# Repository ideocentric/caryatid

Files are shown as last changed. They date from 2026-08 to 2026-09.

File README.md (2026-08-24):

# caryatid

**A carrier board that gives a Daisy Seed a rechargeable battery, honest power
indication, and a fixed set of I/O on connectors, in a shape that drops into an
enclosure.**

Plenty of Seed carriers break out pins well. Fewer solve *running on a battery
you can charge without opening the box, and knowing what state that battery is
in when the instrument is switched off*. This board treats that as the core
requirement rather than an accessory.

**One PCB layout serves every build.** Every variable element (pots, keypad,
sensors, switches, comms) enters through a connector, and each instrument
populates the subset it needs. Order once, stuff per instrument. It carries
absonus, loa, baby borg, and whatever comes next.

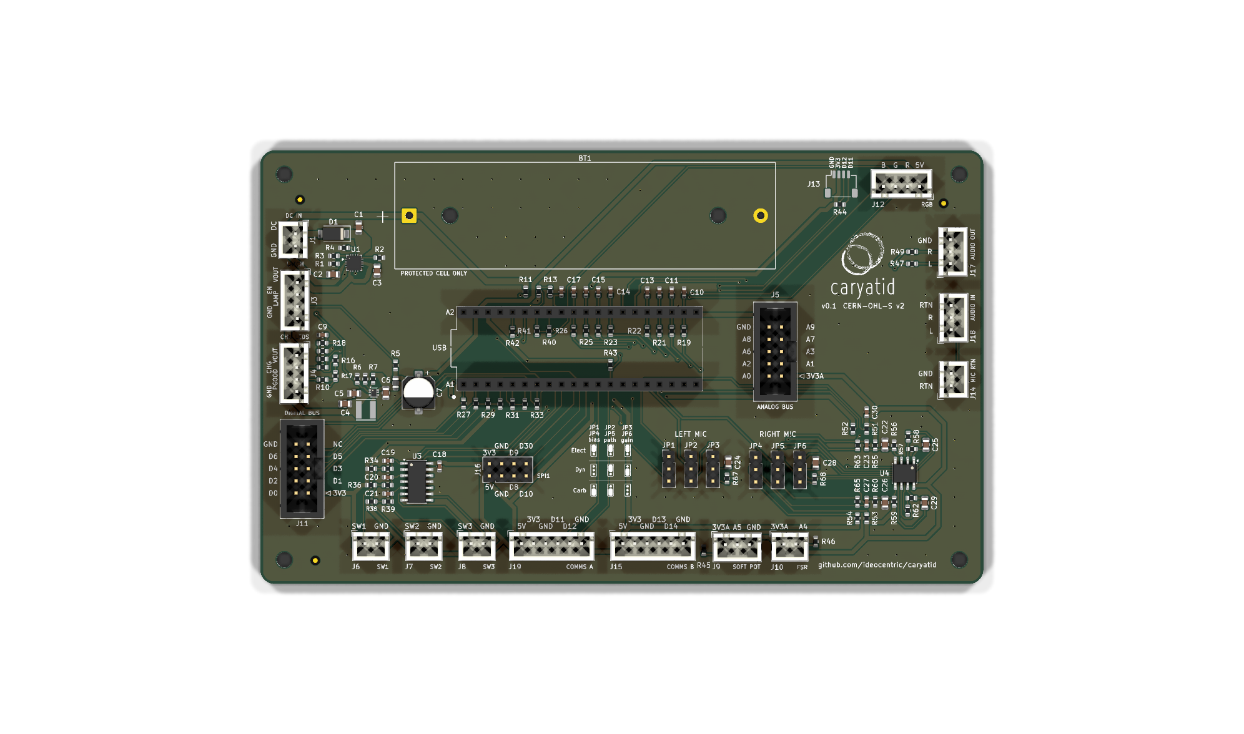
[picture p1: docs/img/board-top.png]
caryatid, top


### Is it right for what you are building?

**[docs/platform.md](docs/platform.md)** is the capability specification: what
it supports, what it deliberately does not, and where the boundary sits. It
states the limits as plainly as the features, because knowing them before you
commit is worth more than discovering them after.

### Status

**Five boards ordered 2026-08-23; none has been powered yet.**

Every electrical check is at zero: no unconnected nets, no shorts, no clearance
or hole violations, no copper under the width rule, no floating ground, and no
DRC violations of any kind. The firmware stub compiles against libDaisy and has
never been run on hardware. [docs/status.md](docs/status.md) is the current
state; treat anything marked unverified there as exactly that.

> **Working on caryatid itself rather than building with it?** Read
> [the checkout warning](#working-on-caryatid-itself) at the foot of this file
> before you commit anything. It is the one way to lose a session's work here.

## Start here

| | |
| --- | --- |
| **Where the board is, and what is next** | [docs/status.md](docs/status.md) |
| **The frozen pin map** | [docs/pinmap.md](docs/pinmap.md) — generated from [docs/pins.yaml](docs/pins.yaml) |
| Connectors and what plugs into them | [docs/connectors.md](docs/connectors.md) |
| Audio in and out, and the handset problem | [docs/audio.md](docs/audio.md) |
| **Setting the mic capsule jumpers** | [docs/mic-configurations.md](docs/mic-configurations.md) |
| The three indicators, and why three | [docs/indicators.md](docs/indicators.md) |
| **Component values, with derivations** | [docs/values.md](docs/values.md) |
| Part numbers, footprints, what is in stock | [docs/sourcing.md](docs/sourcing.md) |
| **Power sheet, every connection** | [docs/power-sheet.md](docs/power-sheet.md) |
| **Seed sheet, every connection** | [docs/seed-sheet.md](docs/seed-sheet.md) |
| **Panel I/O sheet, every connection** | [docs/panel-io-sheet.md](docs/panel-io-sheet.md) |
| **How to build an instrument on this board** | [docs/integration.md](docs/integration.md) |
| Board-support firmware (MIT) | [firmware/](firmware/) |
| What to do before and during capture | [docs/capture-checklist.md](docs/capture-checklist.md) |
| Datasheets, links and document numbers | [docs/datasheets.md](docs/datasheets.md) |
| **What it supports, and what it does not** | [docs/platform.md](docs/platform.md) |
| The board and schematic as PDFs | [docs/reference/](docs/reference/) |
| Why things are the way they are | [docs/decisions/](docs/decisions/) |
| **Rules the tools must follow, and what each cost** | [docs/conventions.md](docs/conventions.md) |

**`docs/pins.yaml` is the source of truth.** The markdown table is generated:

```sh
python3 tools/gen_pinmap.py           # rewrite docs/pinmap.md
python3 tools/gen_pinmap.py --check   # fail if stale
```

Never edit `pinmap.md` by hand. A pin map kept in two places will disagree the
first time a connector moves.

## Terms

**DNP — "do not populate."** The footprint is on the board, the symbol is in the
schematic, the connections exist in the netlist, but **no component is soldered
there**. A deliberately empty position. Also written DNI (do not install), NF
(not fitted), or NP.

**caryatid has none, and that is the point of the term appearing here.**
[ADR 0010](docs/decisions/0010-nothing-is-dnp.md) took the count to zero and
`check_board.py` check 12 keeps it there.

DNP used to be the mechanism this board rested on: lay out every option any of
the instruments might need, populate only the subset each build wants. It stopped
paying its way when JLCPCB began fitting the through-hole parts too — **DNP
became an instruction someone acts on and bills for**, so every DNP line is
either a part you paid for and did not want or one you needed and did not get,
and which it is only becomes clear when the boards arrive.

What replaced it is **selection after assembly**: six jumpers choose the mic
front-end per channel, and the codec's own PGA does the attenuating a resistor
pad used to. See [audio.md](docs/audio.md) and
[sourcing.md](docs/sourcing.md).

## What "frozen" means

An instrument may leave a pin unpopulated, and may choose between the alternates
listed for a pin. It may **not** repurpose one. The entire value of the platform
is that one layout serves every build; a pin reassigned for one instrument is a
board that no longer serves the others.

The map is **fully allocated**. `D30` is the only spare. Adding anything means
taking it from something else, and the decision records say what that would
cost.

## The fixed core

Populated on every build:

- Barrel jack → SS34 → **bq24074** charger with power path, ISET 890 Ω (1 A)
- **On-board 18650 holder (BT1)**, the only path to `VBAT` — a soldered holder
  cannot be wired backwards. Protected cell or protection PCB **required**
- **TPS61023** boost → **5.0 V** → ferrite + 100 µF → Seed VIN
- Illuminated latching power switch (3–9 V lamp, so `R_LED` is a 0 Ω link)
- `/CHG` + `/PGOOD` panel LEDs — the indication that works with the Seed off
- RGB status LED, battery gauge on A10, charge-status code on A11
- Daisy Seed on 2×(1×20) female headers, machine-fitted
- 74HC14 Schmitt debounce, SMT — see [ADR 0007](docs/decisions/0007-rc-and-schmitt-instead-of-the-ls18-p.md)
- Audio out; audio in on every board, **both channels**, capsule selected by
  jumper — JP1–JP3 left, JP4–JP6 right

## Two things worth knowing before you read the map

**Comms ports carry signals, not protocols.** D11/D12 are simultaneously I2C1
and UART4, so the same connector is an I2C sensor, a MIDI input, or an ESP32
bridge depending on what you plug in. Two ports is the ceiling — there is no
third UART on free pins. See [ADR 0003](docs/decisions/0003-comms-ports-are-protocol-agnostic.md).

**D8 is the only free SPI1 clock on the board.** Not a preference — `PA5` is the
only alternative and it is an analogue panel input. An earlier draft spent D8 on
an LED, which would have left SPI1 as two pins with nothing to clock them. See
[ADR 0004](docs/decisions/0004-keep-spi1-drop-the-soft-latch.md).

## Licence

**Settled 2026-08-18.** The hardware and the tools are strongly reciprocal; the
board-support layer deliberately is not:

| What | Licence |
| --- | --- |
| **Hardware** — schematics, PCB, footprints, artwork | **CERN-OHL-S v2** |
| **Tools** — everything in `tools/` | **GPL-3.0-or-later** |
| **Board support** — everything in `firmware/` | **MIT** |

Terms and what counts as *Complete Source* are in [LICENSING.md](LICENSING.md); how
it was reached, and the audit of every design input, are in
[ADR 0006](docs/decisions/0006-licensing-is-open.md).

CERN-OHL-S defines Complete Source as the **editable design files**, so shipping
Gerbers alone does not discharge the obligation. `CERN-OHL-S v2` and
`github.com/ideocentric/caryatid` are both printed on the front silkscreen.

The question this turned on — whether the schematic derived from Adafruit's
reference designs (CC BY-SA, and irreversible) or was drawn independently from
the TI datasheets — was answered **2026-08-08, before capture began**: drawn from
the datasheets. That is what kept the reciprocal option available.

**`firmware/` is MIT on purpose.** A copyleft board-support layer is viral into
anything that links it, which would settle every instrument's firmware licence
from underneath — a decision belonging to each instrument, not to the carrier
board. libDaisy and DaisySP are MIT already.

## Consuming this board

Each instrument takes it as a submodule:

```sh
git submodule add https://github.com/ideocentric/caryatid.git hardware/platform
```

loa consumes it this way at `hardware/platform`. Then add the board support to
your build:

```make
C_INCLUDES  += -Ihardware/platform/firmware/include
CPP_SOURCES += hardware/platform/firmware/src/caryatid.cpp
```

**Read [docs/integration.md](docs/integration.md) first** — it covers what the
board provides, what the instrument must provide, the electrical and mechanical
requirements, and the four things about this board that are not guessable from
a pin number.

## The name

*A caryatid is a column carved as a figure, bearing the weight of what stands on
it. Named for the role rather than for any instrument it carries: calling it
after one of them would have implied it belonged to that one.*

## Working on caryatid itself

### ⚠ Which checkout is this?

**caryatid is developed as a standalone clone. It is also consumed as a git
submodule by the instrument repositories, and those copies are read-only.**

If the path to this file runs through another project's submodule directory —
for loa that is `hardware/platform/` — **you are in a consumer copy. Do not edit
it and do not commit to it.** Find the standalone clone and work there.

The sequence, in order, every time:

1. Change, review and commit in the **standalone clone**.
2. Push.
3. *Then* update the consuming repository's submodule pointer — a
   `Bump caryatid: …` commit on that side.

**Why this matters more than it looks.** A submodule checkout sits on a detached
HEAD, so commits made there belong to no branch and the standalone clone knows
nothing about them. The two diverge silently, and the symptoms all point
somewhere other than the cause: KiCad in one directory keeps showing a schematic
that another directory has already changed.

That is not hypothetical. A whole session's work — ADR 0010, the schematic
edits, two tools, thirteen documents — was written into loa's submodule on
2026-08-21. It pushed to the same remote so nothing was lost, but an hour went
into diagnosing "update from schematic shows nothing new", which was only ever
the wrong directory.

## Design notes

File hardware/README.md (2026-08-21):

# Hardware

Empty. The KiCad project lands in [`pcb/`](pcb/) once the licence question in
[ADR 0006](../docs/decisions/0006-licensing-is-open.md) is answered — that
answer decides whether schematic capture may start from an Adafruit source file,
and it cannot be revisited afterwards.

## What will be committed

The editable design:

- `*.kicad_pro`, `*.kicad_sch`, `*.kicad_pcb`
- project-local symbol and footprint libraries
- STEP exports alongside any native mechanical CAD

## What will not

Anything regenerable: gerbers, drill files, pick-and-place, fabrication
archives. A gerber directory in the tree drifts from the board file within about
two revisions and then quietly misleads whoever trusts it. Released fabrication
output belongs on a tagged release, so a given release maps to exactly one set
of files that were actually ordered.

## Design intent

[`docs/pinmap.md`](../docs/pinmap.md) is the source of truth for pin
assignment and is generated from `docs/pins.yaml`. The schematic follows it, not
the other way round.

Layout rules are inherited from the platform spec and are frozen with the board:

1. **Zones** — charger and barrel jack on one edge, boost in the corner beyond
   it, Seed centre, audio jacks on the opposite edge. Analogue IDC near the
   Seed's analogue row, digital IDC near its digital row.
2. **One unbroken ground plane.** No split AGND/DGND planes. Control noise by
   placement: keep the boost switching loop small so its return currents stay
   local.
3. Wiper RC filters at J5; 100 Ω series at J11.
4. No switcher traces under or parallel to audio nets or the analogue bus.
5. Enclosure bonds to ground at **one point**, at or near the audio jacks.
6. Ferrite and bulk between the boost and everything downstream.
7. Route the RGB lines away from the analogue bus — status changes are edges too.

## Mechanical and fabrication

None of this was specified before and all of it is needed before layout.

**Board outline: 150 × 90 mm.** absonus is 47.8 × 98.6; this is bigger because
caryatid carries roughly four times the part count and an on-board cell.

The BUD's internal is **178 × 110 mm, measured** (2026-08-18) — against a
catalogue internal of 107.9 × 177.8, which was near enough exact. The
**95.2 × 165.1 mm** "usable rectangle", derived by taking 0.5″ off each axis for
the sloped sides, under-read the real box by 12.9 and 14.8 mm and **is
retired**. 150 × 90 sits inside the measured floor with 28 mm of length and
20 mm of width to spare.

That slack is **not** centred. The board mounts 5 mm from the left wall, hard
against the 5 mm screw columns, reserving all 28 mm at the right — the latching
power button is long and needs it, and the device is held in the left hand, so
the board's mass belongs over the supporting hand rather than cantilevered out
to the right. Facts and provenance:
[`discovery/findings/bud-cu477-interior.yaml`](../discovery/findings/bud-cu477-interior.yaml).

**The 100 mm rule is retired.** It claimed JLCPCB's cheapest tier is 100 × 100 and
that crossing it costs money for nothing. The tier is real, but the cost of
crossing it was never checked and turns out to be small — so the rule was
protecting against a number nobody had measured. See
[ADR 0008](../docs/decisions/0008-board-outline-and-layer-count.md).

**Two layers.** Density says four would be easier, but width is cheaper than
layers and the enclosure has the room. At 90 × 100 the component area is about
**53% fill** before the cell, which leaves a ground pour that is genuinely
continuous rather than nominally so, and slack for a 2-layer router.

**Put the SMD and the battery holder on opposite faces.** This is what makes two
layers work at this size. All SMD on one side, the holder and every through-hole
connector on the other, so the copper *under the cell* is still usable instead of
15 cm² of dead board. It also keeps SMT to a single side, which is the cheaper
assembly.

**On-board 18650 holder.** Soldered rather than a pack tacked into the enclosure,
which removes the last hand-crimped power loom — and with it the reverse-polarity
risk that had no protection behind it. A holder cannot be wired backwards.

**There is no remote-pack connector.** J2 carried that option until layout, and
was removed: no instrument on the platform asked for it, and it was the only way
a reversed cell could reach the charger, which has no reverse protection. A cell
now reaches the board only through a soldered holder, which cannot be wired
backwards.

**The holder must take a protected cell.** Those are ~69 mm against the 65 mm
most holders are cut for. Check the part before ordering, or the cell will not
seat.

**Mounting holes: four M3, inset from the corners, pattern fixed once the outline
is.** absonus's 40.64 × 91.44 mm (1.6″ × 3.6″) pattern is **not** being retained —
the current absonus uses standard batteries with a panel cutout, so there is no
interchangeability to preserve and no reason to inherit its geometry.

**Test points.** Bring-up needs `VBAT`, `VOUT`, `+5V`, `+3V3`, `+3V3A` and
several `GND`, as real pads rather than "somewhere to hook a probe". A board
whose connectors are all populated and whose looms are not yet made has nowhere
convenient to measure otherwise.

**Fiducials.** Three, on the top layer, for machine placement — the QFN-16 and
the SOT-563 are both 0.5 mm pitch, which is where placement accuracy starts to
matter. Confirm JLC's current requirement rather than assuming three is right.

**Silkscreen carries the wiring.** See [connectors.md](../docs/connectors.md):
every connector's pin functions and pin 1, the Seed pin names, `USB` at the pin 1
end. This board is assembled once and cabled many
times, so the board itself should be readable without the documents.

## Assembly split

**JLCPCB fits everything, including the through-hole parts.** absonus was built
this way — its BOM carries the JST-XH connectors, the 2×5 IDC header, a DIP and a
radial electrolytic alongside the SMD — so the precedent and the part numbers are
both proven.

- **SMD** — charger, boost, 74HC14, MCP6002, all passives.
- **Through-hole** — every JST, both IDC headers, the Seed sockets, the barrel
  jack, the expansion header.
- **Hand** — nothing, by intent.

Two consequences that follow from this and are easy to miss.

**DNP stopped being advisory, and then stopped existing.** When the connectors
were hand-fitted, "DNP" meant *don't bother*. Once JLC fits the through-hole
parts it is an instruction they act on and bill for, so a wrong DNP line is
either a connector you paid for and did not want or one you needed and did not
get — and which one it is only becomes clear when the boards land.

[ADR 0010](../docs/decisions/0010-nothing-is-dnp.md) took the count to **zero**.
Every symbol is assembled; the options that used to be DNP are now selected by
jumper after assembly, or were `open` positions that no supplier could ship and
have been deleted. BT1 is the only part the assembler does not fit, and it is
**not** DNP — it is self-fit from Digi-Key, which `lcsc.yaml` records and
`fab_package.py` acts on.

**Through-hole assembly needs the Standard service**, not Economic, and is
priced per joint so it scales with connector count in a way SMD placement does
not. absonus was ordered that way deliberately — the cost is accepted in exchange
for an empty hand-solder list.

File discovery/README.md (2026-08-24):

# Findings ledger

> **Before writing anything here, check which checkout you are in.** caryatid is
> developed in its standalone clone; a copy reached through another project's
> submodule directory (`hardware/platform/` in loa) is read-only. See the top of
> the [root README](../README.md).

Measured facts about physical things that the repo cannot check for itself.

One file per finding in `findings/`, keyed by a stable identifier. Each record
carries what was originally *claimed*, what was *measured*, an **append-only**
evidence list with dates, and a `status`. When a fact changes, a new evidence
entry goes on the end and `status` / `last_verified` are updated — history is
never rewritten.

## Why this exists here

caryatid's documents are full of numbers, and most of them are checkable: DRC
reads the board, `check_board.py` reads the board, `verify_parts.py` reads JLC.
A handful are not. The enclosure is a die-cast box on a bench; the only way to
know its interior is to measure it, and the only place that measurement lives is
whatever we write down.

Those numbers had been derived instead — catalogue nominal minus half an inch
per axis, a sparse point cloud out of a STEP file — and then restated across
four documents until they read like measurements. When the box was finally
measured, the derived working rectangle turned out to under-read it by about
14 mm on each axis. Nothing broke, because the error was conservative. It could
as easily have gone the other way.

## The rule

**Facts go in the ledger first. Documents are derived from it, never the
reverse.** If a number in `docs/` needs to change, change the record and
regenerate the prose. A figure in a document that has no record behind it is
unverified, and should say so.

## Records

| record | covers |
| --- | --- |
| [`bud-cu477-interior.yaml`](findings/bud-cu477-interior.yaml) | BUD CU-477 floor, height, plate profile, board mounting datum and the power switch intrusion |
| [`bt1-cell-fit.yaml`](findings/bt1-cell-fit.yaml) | Whether the Orbtronic 3400 mAh protected cell fits the BH-18650-PC holder. `conflict`: it seats, over-deflecting the contacts past their rating |
| [`carbon-capsule-dc-resistance.yaml`](findings/carbon-capsule-dc-resistance.yaml) | What to measure on a carbon capsule, and what each reading means for R52/R54. `unverified`: nothing measured yet |
| [`jlc-order-2026-08-23.yaml`](findings/jlc-order-2026-08-23.yaml) | Every setting on the JLCPCB order form for the first build, checked against the board, plus what was actually paid. `confirmed`: placed 2026-08-23 |
| [`mic-gain-budget.yaml`](findings/mic-gain-budget.yaml) | Where the x3 / x100 / x1000 gain targets come from. `unverified`: they reconcile against typical figures, but no capsule has been measured |
| [`jlc-bom-sourcing.yaml`](findings/jlc-bom-sourcing.yaml) | The LCSC codes (43 as of 2026-08-23): cost, library split, assembly mode, pre-orders, and the build-quantity decision |

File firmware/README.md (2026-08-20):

# firmware — board support for caryatid

Stub board-support code for instruments built on this board. **MIT licensed**,
unlike the rest of the repository, so instrument firmware can link it without
inheriting copyleft — see [../LICENSING.md](../LICENSING.md).

```
firmware/
  include/caryatid_pins.h   GENERATED from docs/pins.yaml — do not edit
  include/caryatid.h        the Caryatid class
  src/caryatid.cpp          implementation
  examples/panel_readout.cpp  bring-up sketch: reads everything, prints it
```

## Status: stub, never run on hardware

**No board has been fabricated yet.** This compiles against libDaisy and is
structured for an instrument to build on, but nothing here has been executed.

The distinction that matters:

- **Every pin, polarity and scale factor is checked against the schematics**
  in `docs/`, and cited at the point of use in the source. Those are as good as
  the documents they come from.
- **Every timing is unverified.** The debounce sample count, the software PWM
  depth, the 1 kHz control rate — all reasoned from the hardware, none measured.

Expect to adjust the second category on first bring-up. Treat a disagreement in
the first category as a bug worth chasing to the schematic.

## What it does that a bare Seed does not

Four things on this board have a polarity, a scale factor or an ordering that
is not guessable from a pin number, and every instrument would otherwise
rediscover them the hard way:

| | |
| --- | --- |
| **RGB status** | Common anode to **5 V**, GPIOs sinking — writing **low** lights it. Green and blue will not light from a 3V3 GPIO at all; their forward voltage is above the output-high level. |
| **Switches** | Pass through a 74HC14 **inverter**, so the GPIO reads **high when pressed**. And SW1 is on `D14` while SW2 is on `D13` — they cross. |
| **Battery gauge** | Behind a 100k/100k divider, so cell volts are **2×** the pin. |
| **J5 analogue bus** | Wipers are `A0`–`A3` then `A6`–`A9`, **not** `A0..A7`. `A4` and `A5` are the dedicated sensor inputs and are not on the bus. |

`Caryatid` handles all four. `caryatid_pins.h` carries the caryatid name, STM32
pin and connector in a comment on every line, because a Seed pin index on its
own tells you nothing at a call site.

## Use

```cpp
#include "daisy_seed.h"
#include "caryatid.h"

DaisySeed          seed;
caryatid::Caryatid hw;

int main() {
    seed.Init();

    caryatid::Config cfg;
    cfg.fsr     = true;
    cfg.comms_a = caryatid::CommsA::I2C;       // J13, Qwiic
    cfg.comms_b = caryatid::CommsB::Switches;  // J6/J7 as SW1/SW2
    hw.Init(seed, cfg);

    while (1) {
        hw.Update();                  // control rate, ~1 kHz
        System::Delay(1);

        float cutoff = hw.Panel(0);   // J5 connector order
        if (hw.RisingEdge(caryatid::Switch::SW3)) { /* hook lifted */ }
        if (hw.BatteryVolts() < 3.3f) hw.Rgb(1, 0, 0);
    }
}
```

**`Config` must match what is actually soldered.** The board lays out both
options for each comms port and a build fits one; selecting the wrong mode
configures a peripheral onto pins that are not connected, and it fails silently.
An unpopulated analogue input is a floating ADC pin — it reads noise, not zero.

## Building

There is no build system here on purpose. This is a **source drop**, consumed
by an instrument repo that already has libDaisy, a linker script and a
bootloader target. Adding a second build system would mean maintaining one that
nothing exercises.

Consume it as a submodule and add to your Makefile:

```make
C_INCLUDES += -Ihardware/platform/firmware/include
CPP_SOURCES += hardware/platform/firmware/src/caryatid.cpp
```

Requires **libDaisy** on the include path; `daisy_seed.h` must resolve. Editor
diagnostics in this repo will show it unresolved, because libDaisy is vendored
in the instrument repos rather than here.

## Regenerating the pin header

`caryatid_pins.h` is generated. Never edit it.

```sh
.venv/bin/python tools/gen_firmware.py           # rewrite
.venv/bin/python tools/gen_firmware.py --check   # fail if stale
```

`docs/pins.yaml` is the source of truth for the pin map and everything else is
a consumer of it. A pin map kept in two places disagrees the first time a
connector moves — and a firmware header is a far worse place to discover that
than a markdown table, because the board is already built and the symptom is a
sensor quietly reading the wrong wire.

## Licensing

**This directory is MIT.** The rest of the repository is not — the hardware is
CERN-OHL-S-2.0 and `tools/` is GPL-3.0-or-later. See
[../LICENSING.md](../LICENSING.md) for all three.

### Your instrument can still be copyleft

MIT is permissive, so it imposes no condition that a copyleft licence cannot
satisfy. **You may absorb this code into a GPL instrument**: the combined binary
is distributed under the GPL, and the MIT notice is preserved for these files.
The FSF classes MIT as GPL-compatible for exactly this.

This is not theoretical — loa already does it. Its firmware is
GPL-3.0-or-later and links MIT libDaisy and DaisySP today, and its licensing
ADR records the same conclusion. (That repository is private as of this
writing, so there is no link to give.)

| instrument | may be licensed | because |
| --- | --- | --- |
| loa | **GPL-3.0-or-later** (and is) | MIT absorbs into GPL cleanly |
| absonus | GPL, MIT, BSD — anything | MIT imposes no reciprocity |
| baby borg | same | same |

### Why it is not GPL

**The reverse does not work, and that is the whole reason.** A copyleft
board-support layer is viral into everything that links it, so GPL here would
force every instrument built on caryatid to be GPL — settling absonus's and baby
borg's licence from a header file in the carrier board underneath them. That
decision belongs to each instrument.

Permissive at the bottom, copyleft optional at the top. It is the only
arrangement that keeps all three choices open.

### What you owe

1. **Ship the MIT notice** with these files when you distribute instrument
   firmware. Consuming caryatid as a submodule satisfies this already —
   `../LICENSES/MIT.txt` travels with it, and every source file carries an
   `SPDX-License-Identifier`.
2. **It cuts both ways.** Anyone may take this directory alone and use it in a
   closed product. That is the price of not constraining the instruments.

The reciprocity that matters is on the **board**, not here: CERN-OHL-S defines
*Complete Source* as the editable design files, so nobody ships derivative
hardware without publishing the KiCad project. A permissive stub layer does not
weaken that.

## Reference

| | |
| --- | --- |
| Pin map | [../docs/pinmap.md](../docs/pinmap.md), generated from `pins.yaml` |
| What plugs into what | [../docs/connectors.md](../docs/connectors.md) |
| Integration guide | [../docs/integration.md](../docs/integration.md) |
| Charge-status encoding | [../docs/indicators.md](../docs/indicators.md) |
| Component values and derivations | [../docs/values.md](../docs/values.md) |

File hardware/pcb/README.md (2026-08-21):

# PCB

KiCad 9 project. **All four sheets are captured.** 125 components, 101 nets,
**ERC clean at 0 violations.**

| Sheet | State | Check |
| --- | --- | --- |
| `power.kicad_sch` | 27 components, 19 nets | netlist diffed node-by-node against [power-sheet.md](../../docs/power-sheet.md); `ITERM` the one deliberate no-connect |
| `seed.kicad_sch` | 12 components | all **31** physical pins in `pins.yaml` land on a net named after the pin |
| `panel-io.kicad_sch` | 46 components | all **29** pins declaring a connector reach it, traversing series R and the debouncer |
| `audio.kicad_sch` | 37 placements, **0 DNP** | 17 nets diffed against [audio.md](../../docs/audio.md), including `C_g` in series with `R_g`; six jumpers re-diffed for [ADR 0010](../../docs/decisions/0010-nothing-is-dnp.md) |

**The dangling-global count reached zero.** It ran 33 → 4 → 0 as seed, panel-io
and audio landed, and each drop was predicted before the sheet was drawn. Five
no-connects remain and all five are deliberate: `ITERM` on the charger, `J11`
pin 9 (the spare), and the three unused 74HC14 outputs.

Treat any *new* ERC message as real. The design now has nothing expected to be
wrong, so there is no noise for a fault to hide in.

Placement is functional rather than tidy — components on a 1.27 mm grid with
labelled stubs, meant to be dragged into shape in the GUI. The bootstrap scripts
in [`tools/oneshot/`](../../tools/oneshot/) are spent; do not re-run them.

```
pcb/
  caryatid.kicad_pro       project: net classes, design rules, sheet index
  caryatid.kicad_sch       root — four hierarchical sheets, nothing else
  power.kicad_sch          charger, boost, latch, hardware charge LEDs
  seed.kicad_sch           Seed headers, battery gauge, charge-status code
  audio.kicad_sch          jacks, coupling, mic bias / preamp / pad options
  panel-io.kicad_sch       analogue bus, digital bus, switches, comms ports
  caryatid.kicad_sym       symbols: BQ24074RGT, TPS61023DRL, Seed sockets A/B
  caryatid.pretty/         footprints: BQ24074 QFN, Seed sockets A/B
  sym-lib-table            so the project libs resolve without global config
  fp-lib-table
```

Open `caryatid.kicad_pro`. `caryatid.kicad_pcb` carries **all 125 footprints,
placed and net-bound**, on a 150 × 90 mm outline with four M3 holes. **Nothing is
routed** — DRC's 263 unconnected items are the full ratsnest, which is correct.

Placement is a machine first pass, not layout. It puts each block where the
zoning says and nothing overhangs the outline, but ~33 courtyards still overlap
and the silkscreen is a mess. Treat it as something to drag from.

## Which face

**Everything is on the front.** The back carries nothing but the ground pour.

The SMD was briefly on the back, which is the textbook arrangement and was right
when the board was 90 × 100 and the copper under the cell was worth reclaiming.
It is wrong here: **the enclosure is shallow, so the standoff must be short**, and
C7 at 5.4 mm cannot hang underneath a 2 mm gap. Moving everything to the front
fixes three things at once — the standoff drops to 2 mm, SMT stays single-sided
and therefore Economic, and B.Cu is freed as a routing layer instead of carrying
104 parts *and* every signal.

The flip is stored the way KiCad stores it, checked against a KiCad-written
board rather than assumed: back-side footprints hold **Y-negated** coordinates,
F/B layer names swapped, and `(justify mirror)` on every text. Arcs survive
because KiCad 7+ stores start/mid/end and all three mirror together.

**Two things to confirm before ordering.**

`J13` is the SMD Qwiic socket, so it classified as SMD and went to the back.
Electrically fine; whether you want a Qwiic cable leaving from the underside is
a mechanical question, not one the classifier can answer.

**Through-hole bodies are on the front, so their pins protrude into the SMD
side.** JLC cannot wave-solder them from the back without hitting SMD. For small
runs their through-hole work is hand soldering, which is probably fine — but you
asked for the JSTs to be machine-fitted as on absonus, and absonus had a
component-free underside. Worth putting to JLC before the order.

## The connector ring

Placed by function, and stacked from measured courtyard extents rather than by
hand — hand arithmetic on offsets produced touching parts three times running.

| Edge | Connectors |
| --- | --- |
| Left | `J1` DC in, `J3` latch switch, `J4` charge LEDs |
| Left, inboard | `J11` digital bus IDC, beside A1 (the digital row) |
| Right | `J12` RGB, `J9` soft pot, `J10` FSR, `J17` audio out |
| Right, inboard | `J5` analogue bus IDC beside A2; `J16` expansion; `J18` audio in and `J14` mic return together |
| Bottom | `J6` `J7` `J8` switches, then `J19` and `J15` module ports |

Power enters on the left where the charger and boost sit underneath; the
analogue bus, both sensors and the audio pair are on the right, furthest from
L1. `J18` and `J14` are adjacent because they are one loom — capsule signal and
its bias return to the hook switch's second pole.

**Everything is at rotation 0.** A vertical JST exits upward, so turning the pin
row to follow the edge buys nothing — and the rotated-courtyard transform is the
one piece of geometry here that could not be checked against a known-good file,
so it is not used. If you rotate parts by hand in the GUI, KiCad does that
arithmetic correctly.

**The four M3 holes are part of the collision check.** They were not, at first,
and that version passed a board where `J6` and `J18` each sat on top of a
mounting hole. They come from the skeleton rather than from the netlist, which
is exactly why a check built around the component list missed them.

## Routing: the pour and the boost loop only

**Everything else is unrouted, deliberately.** kicad-cli has no router, KiCad
ships none, and Freerouting is not installed — and routing follows placement,
which is still a machine first pass. Two pieces were worth doing now because
their geometry is settled and the stakes are high.

**A GND zone on B.Cu**, which is now the empty face — a genuinely solid plane,
and the whole layer still available for routing around it.

**The zone is not filled.** `kicad-cli pcb drc` has no fill option, so DRC
reports the two GND vias as `via_dangling` — they touch a zone that has no copper
in it yet. **Fill zones in the board editor (`B`) and both clear.** That is a
tooling limit, not a fault.

**The boost hot loop.** `+5V_RAW` runs U2 pin 6 to C6 at 0.8 mm. The return is
deliberately **not a track**: C6's ground pad and U2's ground pad each drop a via
into the plane, so the return current runs directly beneath the outgoing current.
That is the smallest loop available and a track would be strictly worse.

Two things learned the hard way and worth keeping:

- **A track wider than the pad pitch shorts to the neighbouring pad.** 0.8 mm
  centred on U2 pin 6 overlapped pin 5. Every exit from a 0.5 mm-pitch pad now
  necks to 0.25 mm and widens once clear of the pad field.
- **Via positions are searched against every back-side pad**, not chosen by eye.
  The first attempt put a GND via straight through C7's `+5V` pad.

**`SW` is routed, and C6 moved to make it possible.** Putting the output cap
beside U2 was the obvious choice and it quietly cost the switching node: pin 5
can only exit right, and C6 was standing in that gap. C6 now sits **below** U2,
which frees the right side for L1 and — because pin 6 is on the near edge either
way — barely lengthens the hot loop.

| | beside | **below** |
| --- | --- | --- |
| Hot loop, pin 6 → C6 | 1.84 mm | 2.01 mm |
| SW node, pin 5 → L1 | 4.17 mm, **unroutable** | **2.31 mm at 1.2 mm wide** |

Trading 0.17 mm of hot loop for a routable 1.5 A switching node is not a close
call. The lesson is that *routability* is a placement constraint, and optimising
loop length without it produced an arrangement that measured well and could not
be built.

Three power pins leaving a 0.5 mm-pitch package share a 1.5 mm band, so every
exit necks to 0.2 mm and widens only once clear of the pad field. With that, the
routing adds **no** DRC violations of its own — the four clearance items are the
pre-existing SOT-563 pad-pitch ones.

## Routing the rest: Specctra DSN

`kicad-cli` has no router and no `dsn` export, so `tools/export_dsn.py` writes one:

```sh
python3 tools/export_dsn.py                 # -> hardware/pcb/caryatid.dsn
freerouting -de hardware/pcb/caryatid.dsn -do hardware/pcb/caryatid.ses
# KiCad: File > Import > Specctra Session
```

KiCad's own GUI export (File > Export > Specctra DSN) is more authoritative; this
exists so the export can be produced headlessly. The `.dsn` and `.ses` are
gitignored — regenerate rather than commit.

Two things it does that the GUI export does not:

- **GND is excluded from the routed nets.** F.Cu is a ground plane, which
  Freerouting cannot see, so it would otherwise scribble 72 ground traces across
  the board. GND wants stitching vias instead. `--with-gnd` overrides.
- **Existing copper is emitted `(type protect)`.** The boost hot loop and the SW
  node were placed and measured by hand; this stops the router discarding them.

**Not verified against Freerouting** — there is none on this machine. The file is
checked structurally (balanced, every padstack and net pin resolves, placements
inside the boundary) but has never been loaded by the tool it targets. Treat the
first import as the real test.

The conventions worth knowing if it ever needs debugging: coordinates are
millimetres × 10000, **DSN is Y-up so `dsn_y = -kicad_y`**, and images are the
canonical library footprint — unrotated and unmirrored — with side and rotation
carried in `(place ...)`. That last one matters because the board stores
back-side footprints already Y-negated, so using the placed copy would mirror
them twice.

## Silkscreen and clearance exceptions

**Back-side reference designators are hidden.** 104 SMD parts at this density
made them illegible and they collided 87 times; JLC places from the CPL file,
not from silkscreen. Front designators stay — that face is sparse and the
connectors are what a human cables up. Mounting holes carry no silk either.

**U1 and U2 have a footprint-level clearance override of 0.15 mm.** A 0.5 mm
pitch package fixes its own pad gaps — 0.25 mm on the QFN, 0.15 mm on the
SOT-563 — and the `HighCurrent` netclass asks 0.3 mm because `VBAT`, `VOUT` and
`VIN_DC` land on those pins. No land pattern at that pitch can meet it. The
exception is scoped to the two packages; every actual trace still answers to its
netclass.

Four violations survive that, and they are worth understanding rather than
silencing: `min_clearance` is a **board-wide floor of 0.2 mm that a local
override cannot go under**, and the SOT-563's own pads are 0.15 mm apart. To
clear them the board floor would have to drop to 0.15 — still comfortably above
JLC's 0.127 mm capability, since the netclasses would continue to govern
routing. That is a board-setup decision, not a footprint fix.

## How dense is it, really

| | mm² |
| --- | --- |
| All 125 courtyards | 4510 |
| of which BT1 | 1774 |
| everything except BT1 | **2736** |
| board | 13500 |
| face left after BT1 | 11726 |

**23% coverage on BT1's face** at 150 × 90 — comfortably inside the band for two
layers. It was 38% at the old 90 × 100. An earlier read of this said the board was "essentially
full"; that was wrong, and it was wrong for an instructive reason — the figure
came from a packer that added 1.6 mm around every part, which inflates an 0603
courtyard nearly six-fold. Measure coverage from courtyards, not from packing
margins.

What *is* tight is the connector ring. The edge connectors are 920 mm² of the
2736 and they all want board edge, which no rectangular zoning expresses. That
is the part worth doing by hand first.

Verified with `kicad-cli` rather than assumed: ERC runs clean and traverses all
four child sheets, and a netlist export resolves the full hierarchy.

```sh
KCLI=/Applications/KiCad/KiCad.app/Contents/MacOS/kicad-cli
"$KCLI" sch erc --output erc.rpt caryatid.kicad_sch
```

## Net classes

Set in the project file, with pattern assignment so nets land in the right class
as they are named rather than by hand afterwards.

| Class | Track | Clearance | Via | Applies to |
| --- | --- | --- | --- | --- |
| Default | 0.25 mm | 0.2 mm | 0.6 / 0.3 | everything else |
| Power | 0.8 mm | 0.25 mm | 0.8 / 0.4 | `+3V3`, `+3V3A`, `+5V` |
| HighCurrent | 1.2 mm | 0.3 mm | 1.0 / 0.5 | `VBAT`, `VOUT`, `VIN_DC`, `SW` |
| Analog | 0.3 mm | 0.25 mm | 0.6 / 0.3 | `A?`, `A??`, `AUDIO_*` |

`HighCurrent` is the one that matters. The cell delivers over an amp at low state
of charge and takes 1.29 A back while charging, and `SW` carries the boost's
switching current — 1.51 A peak at worst case. Those are not signal nets.

**Name the nets to match the patterns.** A net called `BAT+` will land in
Default and be routed at 0.25 mm, which is how a board gets warm.

**Local labels are sheet-qualified, and that defeats a bare pattern.** A power
symbol makes a global net called `VBAT`; a *local* label on the power sheet makes
a net called `/power/SW`. The pattern `SW` does not match `/power/SW`, so the
boost switching node — 1.51 A peak — would have silently fallen into Default.
The pattern is therefore `/power/SW`, spelled out. Any future HighCurrent or
Analog net carried on a local label needs the same treatment; global labels and
power symbols do not.

## Design rules

Set conservatively against JLCPCB's capabilities rather than at them: 0.2 mm
minimum track and clearance, 0.5 mm minimum via with a 0.3 mm hole. JLC will
accept finer, but a first spin is not the place to spend that margin.

**Two layers, 1.6 mm, 150 × 90 mm.** See
[ADR 0008](../../docs/decisions/0008-board-outline-and-layer-count.md). The old
"neither edge past 100 mm" rule is retired — it was a proxy for a price nobody
had checked, and checking it showed the increase is small. The 90 mm axis is
unchanged because it is the one proven against the BUD.

## Before capture

Work down [`../../docs/capture-checklist.md`](../../docs/capture-checklist.md).
The parts of it that gate everything else:

- **[ADR 0006](../../docs/decisions/0006-licensing-is-open.md) says draw from the
  TI datasheets.** No Adafruit schematic is opened during this work — deriving
  cannot be undone afterwards.
- **The pin map is frozen.** [`docs/pinmap.md`](../../docs/pinmap.md) is
  generated from `docs/pins.yaml`, and the schematic is a consumer of it, not a
  second opinion. Label Seed nets with pin names (`A7`, `D11`), not with what
  they happen to do on one instrument.
- **Three measurements still outstanding** — the handset capsule, the switch lamp
  current, and the mechanical parts that set panel standoff height. The first
  gates the audio sheet; the third gates any footprint placement.

Values are in [`docs/values.md`](../../docs/values.md), part numbers and
footprints in [`docs/sourcing.md`](../../docs/sourcing.md). Several absonus
footprints are reusable as-is, which turns a chunk of this into transcription.

## Footprints — checked against the stock libraries

Every footprint named in `sourcing.md` resolves in KiCad 9's stock libraries,
including the four JST XH ones that were assumed by naming convention rather
than verified. Two need a project-local variant, and both are already built.

**`caryatid:BQ24074RGT_QFN-16-1EP_3x3mm_P0.5mm`** — because **none** of the five
stock QFN-16 3×3 footprints put any paste on the exposed pad; every one is
`F.Cu`/`F.Mask` only. Derived from `EP1.7x1.7mm_ThermalVias` with a 2×2 aperture
array at 72% coverage. EP is 1.68 ±0.07 per SLUS810N drawing 4222419/E, so 1.7 is
inside tolerance.

**Thermal vias are 0.3 mm drill on 0.55 mm pads at ±0.5 mm.** TI's drawing calls
for Ø0.2 mm, which is below JLC's 0.3 mm minimum hole; and at TI's ±0.6 position
a 0.55 mm pad leaves only 0.176 mm to the signal pads. Moving them inboard to
±0.5 gives 0.289 mm and satisfies both.

**The exposed pad is 1.68 mm, TI's nominal.** It was briefly 1.70 — inherited
from the stock footprint that had a ThermalVias sibling — which lands *exactly*
on the 0.2 mm clearance boundary and fails on rounding.

Two caveats worth carrying into layout and into the order:

- **The four thermal vias sit under the paste apertures and must be tented.** On
  a 1.68 mm pad the vias and the apertures both want the corners; making them
  disjoint drops coverage to 45%. This is a via setting, not a footprint fix.
- The only package drawing in the datasheet is **RGT0016C**, while Table 7-1
  lists the '74 as **RGT0016B**. TI did not publish the B drawing. If the two
  differ, the EP dimension is what changes.

**`caryatid:DaisySeed_Socket_A_1x20` / `_B_1x20`** — two 1×20 socket rows so the
BOM asks for two sockets from the schematic. They carry the module outline,
pin-1 dot, square pads at the USB end of both rows and the `USB` legend, split on
the centreline so wrong spacing shows as a broken outline. Per-pin labels were
drawn and dropped — see [`docs/seed-sheet.md`](../../docs/seed-sheet.md).

## Silkscreen: JLCPCB's numbers

| | Absolute minimum | Recommended |
| --- | --- | --- |
| Character height | **0.8 mm** | ≥ 1.0 mm |
| Line width | **0.15 mm** | ≥ 0.2 mm |
| Pad-to-silk clearance | — | ≥ 0.25 mm |

Two project rules were looser than that and have been tightened:
`min_text_thickness` 0.08 → **0.15**, and `min_silk_clearance` 0 → **0.25**,
which was disabled entirely. `min_text_height` was already correct at 0.8.

Expect the silk-overlap count to *rise* after that change. It is not a
regression — the rule was previously not checking.

**BT1 is settled and needs no project-local work**: MPD `BH-18650-PC`,
`C5339083`, on stock `Battery:BatteryHolder_MPD_BH-18650-PC`, whose pads match
the drawing exactly (72.90 mm terminals, 55.61 mm mounting holes). It is rated
for protected cells, which was the open question. The Keystone 1042 was rejected
— 87.9 mm of courtyard against the MPD's 79.2 mm.

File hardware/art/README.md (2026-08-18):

# Artwork

## `enso-oro.svg`

The house mark. **Original work by Matt Comeione, drawn in Adobe Illustrator**,
used across the instrument projects — absonus, loa, baby borg — and on this
carrier board. First party, so it places no constraint on how this design is
licensed.

That provenance is recorded because the file itself cannot answer it: the
Illustrator export carries no metadata, no author, no `<title>`, no licence and
no download record, and the question "does anything here block a copyleft
licence?" came down entirely to who drew this. Anyone auditing later should not
have to ask again.

**It is committed rather than left in `local/`** for two reasons. It is the
source the silkscreen is generated *from* — the board holds 153 derived
polygons, which are an output, not a source — and CERN-OHL-S, the licence
[ADR 0006](../../docs/decisions/0006-licensing-is-open.md) is heading toward,
defines Complete Source as the editable design files. A repo whose logo exists
only as flattened polygons would not meet that.

Regenerate the silkscreen with:

```
.venv/bin/python tools/svg_to_silk.py --size 18 --at 174,55.5 --apply
```

Size is not arbitrary — see the tool's header. It is measured off the
fabricated absonus v0.3 board, not chosen.

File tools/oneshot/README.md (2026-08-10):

# One-shot scripts

Scripts that were run **once**, kept for provenance, and must not be run again.

This is the opposite of [`tools/gen_pinmap.py`](../gen_pinmap.py), which is a
real generator: `docs/pinmap.md` is derived from `docs/pins.yaml` every time, and
`--check` fails the build if it drifts. Re-running that is the point.

Nothing in this directory works that way.

| Script | Produced | Status |
| --- | --- | --- |
| `gen_power_sch.py` | `hardware/pcb/power.kicad_sch` | **spent** — the schematic is now edited in KiCad |
| `gen_seed_sch.py` | `hardware/pcb/seed.kicad_sch` | **spent** — same |
| `gen_panelio_sch.py` | `hardware/pcb/panel-io.kicad_sch` | **spent** — same |
| `gen_audio_sch.py` | `hardware/pcb/audio.kicad_sch` | **spent** — same |
| `gen_board_skeleton.py` | `hardware/pcb/caryatid.kicad_pcb` | **spent** — outline, M3 holes, stackup |
| `place_board.py` | same file | **spent** — placed 125 footprints and bound their nets |
| `symlib.py` | — | read-only helper, safe to import |

## Why keep them at all

Each generator records exactly how its sheet was first captured: which symbol came from which library, where every component sat, and
which net each pin joined. That is why the capture could be checked by exporting
the netlist and diffing it node-by-node against
[`docs/power-sheet.md`](../../docs/power-sheet.md) rather than by reading the
schematic and hoping.

It also documents two things that were only discovered by generating the file:
`power_out` on both of the bq24074's `OUT` pins is an ERC error, and local labels
are sheet-qualified (`/power/SW`, not `SW`) which defeats a bare netclass
pattern.

## Why not run them

**The schematic stopped being derived the moment it existed.** Placement,
wiring, and anything added in KiCad live only in `power.kicad_sch`. Re-running
the generator rewrites that file from the component table in the script and
throws all of it away.

The script refuses to run without `CARYATID_ALLOW_REGEN=1`. That guard is there
to stop an absent-minded `python3 gen_power_sch.py`, not to make regeneration a
supported workflow — it is still destructive with the variable set.

**If the circuit changes:** change it in KiCad, and update
`docs/power-sheet.md`. Do not come back here.

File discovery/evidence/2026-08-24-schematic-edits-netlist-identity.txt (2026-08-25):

Netlist identity across the 2026-08-24 schematic drawing edits
==============================================================

  baseline  718d5dd  (before the label moves)
  current   a5bc7cc  (Republish the schematic PDF with seed's fields reseated)

  Commits under test:
    a5bc7cc Republish the schematic PDF with seed's fields reseated
    ea6cd62 Reseat seed.kicad_sch passive fields to the house offset
    f249562 Move five labels off the resistors they clipped, verified by netlist

  Command, run against each tree:
    kicad-cli sch export netlist --format kicadsexpr caryatid.kicad_sch

RESULT
--------------------------------------------------------------
  nets, baseline           113
  nets, current            113
  net names appeared       none
  net names vanished       none
  nets with altered nodes  none
  total nodes, baseline    376
  total nodes, current     376

  VERDICT: connectivity is unchanged.

  The two netlist FILES differ by 144 bytes and the netlist CONTENT does
  not. kicad-cli embeds each symbol's field positions in the netlist as
  properties, so moving a Reference changes the file while leaving every
  net, node and pin identical. That is the whole point of comparing
  parsed nets rather than diffing the file.

OTHER GATES, current tree
--------------------------------------------------------------
  ERC                      0 messages, 0 errors, 0 warnings
  schematic parity         0 DRC violations, 0 unconnected pads, 0 Footprint errors
  check_schematic.py       0 hard findings, 8 advisory (labels clearing a
                           resistor by 0.59 mm; measured clear, flagged because
                           they READ as touching at plot scale)

  .kicad_pcb last changed  28c54f1 2026-08-22 Source the last 3 parts, normalise R45's pad angle, refresh the stale docs
  ^ predates every commit under test. The BOARDS ON ORDER ARE UNAFFECTED;
    these edits are schematic drawing only.

CORRECTION, appended 2026-08-24 22:40 (evidence is append-only)
--------------------------------------------------------------
  The "check_schematic.py  0 hard findings, 8 advisory" line above is WRONG
  in both halves, and the way it was wrong is worth recording.

  The count was produced by a regex matching only `[near ] advisory`. There
  were 28 advisories, not 8: 8 near-misses plus 20 text overlaps that the
  regex never saw. Counting one class and reporting it as the total.

  Worse, the 20 were not advisory at all. Rendered at 600 dpi:

      power.kicad_sch     VIN_DC and PWR_FLAG share an anchor EXACTLY at
                          (69.85, 272.59) and print as illegible mush.
                          Same for GND, VBAT and +5V against PWR_FLAG.
      panel-io.kicad_sch  +3V3 prints straight through D12 on J13's 2.54 mm
                          pin pitch; each power flag's Value text is drawn
                          3.0 mm below its own symbol, landing it on the
                          NEXT PIN ROW DOWN. 15 instances of this shape.
      seed.kicad_sch      the PGOOD_LEG label bridge names both sides of the
                          R16/R17 divider midpoint; the two labels collide.

  They were dismissed because the tool hedged every text overlap as
  "advisory: character widths are estimated". CHAR_W is worth 0.1-0.2 mm on
  a short string. These run 0.81 to 1.27 mm.

  A confidence caveat is not a severity. The tool now grades by
  interpenetration depth: >= 0.60 mm is [collision] and counts as a finding.
  It reports 20.

  NO ELECTRICAL DEFECT IS IMPLIED. All 20 are text placement. The PGOOD_LEG
  bridge was traced to be sure: ~{PGOOD} -> R17 -> PGOOD_LEG -> R16 ->
  A11_DIV, a summing-ladder leg feeding one ADC pin, matching the *_LEG
  convention used for LEG_101_L and LEG_256_R. Netlist unchanged, 113 nets.

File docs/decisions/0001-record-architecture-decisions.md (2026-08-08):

# 0001 — Record architecture decisions

- **Status**: Accepted
- **Date**: 2026-08-08

## Context

This board is meant to outlive the instrument that prompted it, and to be picked
up by someone — including a later version of its author — who was not present
for the reasoning. A frozen pin map without recorded reasons is a list of
arbitrary constraints, and arbitrary constraints get quietly broken.

## Decision

Significant decisions get a numbered record here. Records are **append-only**:
once accepted, a record is never rewritten, only superseded by a later one.

A decision belongs here if reversing it would cost a board spin, or if the
reasoning is not recoverable from the schematic.

## Consequences

The pin map states *what*; these records state *why*. When a future build wants
a pin that is already taken, the record says what it is taken for and what
paying for it would cost.

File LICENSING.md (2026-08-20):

# Licensing

Settled 2026-08-18. See [ADR 0006](docs/decisions/0006-licensing-is-open.md) for
how it was reached and for the audit of every input.

| What | Licence | Text |
| --- | --- | --- |
| **The hardware** — schematics, PCB, footprints, artwork | **CERN-OHL-S v2** | [LICENSES/CERN-OHL-S-2.0.txt](LICENSES/CERN-OHL-S-2.0.txt) |
| **The tools** — everything in `tools/` | **GPL-3.0-or-later** | [LICENSES/GPL-3.0-or-later.txt](LICENSES/GPL-3.0-or-later.txt) |
| **The board support** — everything in `firmware/` | **MIT** | [LICENSES/MIT.txt](LICENSES/MIT.txt) |

The first two are strongly reciprocal, which was the stated direction of travel:
CERN-OHL-S is written for hardware and defines *Complete Source* as the editable
design files, so shipping Gerbers alone does not discharge the obligation.

## Why `firmware/` is permissive and the rest is not

`firmware/` is a board-support layer that instrument firmware **links**. Under
GPL that is viral: every instrument built on caryatid would be forced to
copyleft, which is a decision belonging to each instrument and not to the
carrier board underneath it. loa's firmware happens to be GPL already; absonus
and baby borg should not have that settled for them by a header file.

MIT also matches what it sits on — libDaisy and DaisySP are both MIT.

This is not a weakening of the hardware terms. The board stays CERN-OHL-S, and
a permissive stub layer does not let anyone ship a derivative board without its
design files.

**Generated output may take a different licence from its generator.**
`tools/gen_firmware.py` is GPL and emits `firmware/include/caryatid_pins.h`
under MIT. That is deliberate and ordinary: the header is not a derivative work
of the script that printed it.

## Why the files are laid out like this

**`LICENSE`** in the root is the verbatim, unmodified CERN-OHL-S v2 text and
nothing else. That is not housekeeping: GitHub detects a licence by matching a
root file's *content* against a reference text at high similarity, so any
preamble, table or explanation wrapped around it defeats the match. This
document used to *be* `LICENSE.md` and carried the table above — which is why
GitHub reported the repository as `NOASSERTION`, no licence at all, for the
first day it was public.

**This file** carries everything a human needs and a matcher must not see.

**`LICENSES/`** holds the full text of both licences, so the GPL text ships with
the repository instead of being referenced into the void.

**Per-file `SPDX-License-Identifier` headers** are authoritative for anything
that is not hardware. All 22 tools in `tools/` declare `GPL-3.0-or-later`. A
root `LICENSE` naming one licence does **not** relicense them: where a file
states its own licence, that statement governs.

The root file is the *hardware* licence because the hardware is the point of
this repository — the tools exist to produce it. GitHub will show a single
licence and it should be that one.

## What "Complete Source" means here

The editable design files, not fabrication output:

- `hardware/pcb/*.kicad_sch`, `*.kicad_pcb`, `*.kicad_pro`
- `hardware/pcb/caryatid.pretty/` — the three custom footprints
- **`hardware/art/enso-oro.svg`** — the board's silkscreen mark is generated
  *from* this; the 153 polygons in the board file are an output, not a source
- `docs/pins.yaml` and the generators that consume it

Gerbers, drill files and the `.ses` router output are **not** source.

## Provenance

Every input was audited before this was settled, and nothing blocks reciprocal
licensing. The one item that needed an answer was the ensō, which is
first-party — see [hardware/art/README.md](hardware/art/README.md). Stock KiCad
footprints carry the library exception permitting use in designs; the Newstroke
font behind every silkscreen label is permissive; the custom footprints are ours
from TI land pattern 4222419/E; values and topology are drawn from datasheets
rather than derived from anyone's schematic.

## On the board

Both `CERN-OHL-S v2` and `github.com/ideocentric/caryatid` are printed on the
front silkscreen beside the mark.

The URL was added once the repository was made public (2026-08-18). Until then
the notice deliberately carried no URL, on the grounds that a pointer to
something which does not resolve is worse than none — and adding one is a board
change, so it had to happen before a fabrication run rather than after. It did:
no boards have been fabricated, and the URL is in the current design.

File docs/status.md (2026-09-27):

# Status

Where the board is, and what happens next. Read this first.

## ▶ RESUME HERE: 2026-09-23

**Five boards are in hand, all five have passed Phase B, and nothing has been
powered yet.** Phase B completed 2026-09-27 with **no board faults on any of the
five**. Every part that plugs into them has been measured, and so have the
instruments doing the measuring.

🔴 **The next step is Phase C: first power.** Nothing in this repo has yet seen
a volt.

### Phase B: all five passed, and it caught the runbook rather than the boards

**Zero defects in the fabricated articles.** What B1 to B6 actually found was one
design fault and about a dozen documentation and method faults:

| | |
| --- | --- |
| **design** | J13 faces into the board. Recorded, not fixed, does not gate this build |
| **nets that did not exist** | `+3V3D` was named in three steps and is not a net |
| **probe points that were wrong** | B2.1 named `VIN_DC` at J1, which does not carry it; B2.4 sent you to J12, which has no ground pin; B4.1 did not warn that J11 pin 9 is `NC` and sits beside pin 10 |
| **method that was wrong** | "a capacitor climbs" (it does not, and **magnitude** is the discriminator, not shape); the clip-lead warning covered only one direction of contact error; B5 was package-referenced when it must be board-referenced |
| **the measurement itself** | **every apparent difference between boards on the megohm rows turned out to be the probe**, including a Dupont barrel bridging the adjacent rails that B3.1 exists to check |

**Carried into Phase C:** U2's placement rotation is deliberately unresolved and
**C2 settles it**, since a rotated boost does not start and C1's 100 mA limit
makes that a diagnosis rather than a casualty. Board 5's B2.3 reading of 190 kΩ
against 0.58 MΩ is the only board-level anomaly that survived a retest and is the
first thing to look at if board 5 misbehaves. **Board 1 is the practice board**,
with snapped rails and a hand-fitted BT1, so its results are informative rather
than authoritative.

### Phase A component checks: all six passed

No board was powered for any of these. They are the checks where being wrong
costs a part.

| | | |
| --- | --- | --- |
| A7.1 | switch lamp limits its own current | ✅ 3-6 V marking, internally limited |
| A7.2 | charge LED common anode | ✅ |
| A7.3 | charge LED green lights on a flat cell | ✅ 0.77 mA at 3.00 V |
| A7.4 | RGB common anode | ✅ and diffused |
| A7.5 | test electret characterised | ✅ red positive, 339 µA |
| A7.6 | switch lamp current | ✅ 28.5 mA at 5.00 V |

Panel parts and the handset are settled too: the **J3 latch switch** is
compatible and its cable can be built; loa's **handset** is mapped at the RJ9,
yellow/black transmitter with **yellow positive**, drawing 192 µA.

### 🔴 The instruments have known errors. Read these before measuring anything

| Instrument | Error | Consequence |
| --- | --- | --- |
| Jesverty supply, CC | **+3.53 mA offset**, unity gain | cannot deliver below ~3.5 mA; set a wanted current 3.5 mA low |
| Fluke 101, resistance | **~1.1% low**, across two ranges | currents from shunt drops read ~1.1% low |
| Jesverty, voltage display | 20-50 mV low | the Fluke is the instrument, the display is convenience |

**Prefer CV with a measured series resistor over CC** for any current under about
20 mA. The resistor sets the current and its drop reports what you actually got,
so the supply's current circuitry never enters the measurement. See
[`bench-instruments`](../discovery/findings/bench-instruments.yaml).

**A DSO Nano is now available** (2026-09-23). ~200 kHz bandwidth, single channel,
which is about ten times the top of the audio band and therefore adequate for all
audio work. It is **not** adequate for the boost's ~2 MHz switching ripple.

### Design state, unchanged since fabrication

**The board is routed, filled, silkscreened and fab-ready.** The 2026-08-21
strip-and-re-place is complete: re-placed into the upper board, re-routed,
ground stitched, silkscreen cleared, and `fab_package.py` reports **ready**.

**State now**, every figure re-derived from the board rather than carried
forward:

| | |
| --- | --- |
| schematic parity | **0** |
| unconnected | **0** |
| `check_board.py` | **12/12** |
| DRC, plain | **2** — `lib_footprint_mismatch` on A1 and A2 only, see below |
| tracks / vias / zones | **957** (4186 mm) / **167** / 10, all filled |
| tracks under the 0.20 mm rule | **0** |
| ground | F.Cu 26 islands, main 5003.5 mm²; B.Cu a single 11448.3 mm² plane |
| floating ground copper | **0** — every island carries a via or a through-hole GND pad |
| footprints | **135** |
| DNP | **0**, and check 12 fails if any reappears |

**The two remaining DRC lines are A1 and A2, and they are metadata.** Verified
2026-08-22 by diffing all 20 pads of each against
`caryatid.pretty/DaisySeed_Socket_A_1x20.kicad_mod`: **none differ**. What
differs is what KiCad adds when a footprint is placed — `path`, `sheetfile`,
`sheetname`, two extra property fields and their hide flags — none of it copper,
and none of it removable without breaking the schematic link.
`drc_exclusions.py` accepts them with reasons and reports **0 new, 5 accepted**.
They still appear in plain DRC because the project file carries only three
exclusion keys; adding the other two is a one-time right-click → *Exclude this
violation* in pcbnew's DRC panel. The tool will not synthesise those keys — it
tried once and got the coordinate wrong for exactly these two.

**R45 was a third such line and was FIXED rather than excluded**, 2026-08-22.
Its pads were stored at 270° against a footprint at 90° — 180° relative, where
`Resistor_SMD` has 0° — and it was the only one of 64 0603 resistors on the
board like that. The half turn was harmless, since a 0.800 × 0.950 mm rectangle
is unchanged by it and both pad centres are identical before and after, which is
precisely why excusing it was wrong: a lone outlier that costs nothing to
normalise should be normalised. It picked up the flip when `3fe330e` rotated it
beside J9/J10.

### Ordered, and the boards are here

**Ordered 2026-08-23. The boards arrived 2026-09-01**, with the battery holders
and the jumpers. caryatid is no longer a design, it is five physical boards.
Order detail, cost reconciliation and the ENIG decision are in
[`jlc-order-2026-08-23`](../discovery/findings/jlc-order-2026-08-23.yaml).

*This section read "What is left before ordering: 1. exclude A1 and A2 in DRC,
2. Order" from 2026-08-22 until 2026-09-01, nine days after the order was
placed. It was stale in the one file that is meant to be read first when
picking this project up cold. The A1/A2 DRC exclusion was never done and is now
moot for this batch: they are metadata, not copper, and the boards are made.*

**BT1 fits.** The 65-68 mm vs 69.48 mm conflict that hung over the battery
since 2026-08-23 is closed: the holders are in hand and the cell seats. MPD's
stated range is conservative rather than dimensional, as the STEP analysis
predicted. See
[`bt1-cell-fit`](../discovery/findings/bt1-cell-fit.yaml), and seat all five
pairs before assembly rather than trusting the one that was tried.

### What is left now

1. **Phase C, first power.** Phases A and B are complete on all five boards and
   nothing in this repo has been powered. **This is the next step.** 🔴 Read the
   instrument-error table above before taking a single reading: the supply's CC
   is offset **+3.53 mA** and the meter reads **~1.1% low** on resistance below
   the 6 kΩ range.
2. **Screws for the battery holders**, the only part still unsourced. M3, and
   the length wants the holder measured rather than guessed. **Blocks C3 only**,
   so it does not gate Phase B. See `bt1-cell-fit`.
3. **Optional, newly possible:** close
   [`mic-gain-budget`](../discovery/findings/mic-gain-budget.yaml), which has
   been `unverified` since capture because it needed a scope. Speak into the
   handset at working distance and measure U4's output. That measures the end of
   the chain directly, so the assumed 94 dB SPL that makes the record unverified
   stops mattering rather than needing to be resolved. Target is 1.0 Vrms.
   **Measure at U4's output, not the capsule**: 10 mV at the capsule is about
   one division, while ×101 puts it at a comfortable 0.5-1.8 V.

Nothing else is outstanding on the design. The boost hot loop, R45's placement and the necked
tracks were all checked on 2026-08-22 and none needed work — see below.

## The board *was* routed, at `snapshot/routed-2026-08-21`

Kept here because it is worth knowing the electrical result was reachable on
this outline. At that tag every check was at zero:

| | |
| --- | --- |
| real unconnected connections | **0** |
| zone-to-zone unconnected | **0** |
| shorts, clearance, hole clearance | **0** |
| tracks under the 0.20 mm rule | **0** |
| floating ground copper | **0** |
| `tools/check_board.py` | **pass** |

150 × 90 mm, two layers, 135 footprints, all on the front. Ground pour both
sides, power nets around U1 and U2 poured from hand-drawn outlines rather than
routed — see [ADR 0008](decisions/0008-board-outline-and-layer-count.md).

**None of that copper is on the board now.** The outline, the layer count, the
pour strategy and the footprint set carry forward. The route does not.

## Next, in order

1. ~~**Round the board corners.**~~ **Done** — 3 mm radius, four `gr_line` sides
   and four 90° `gr_arc` corners, pours refilled to follow them. Reasoning and
   what did *not* constrain the radius are in
   [ADR 0008](decisions/0008-board-outline-and-layer-count.md); change it with
   `python3 tools/round_corners.py --radius N --apply`.
2. ~~**Component silkscreen.**~~ **Done** — D1's reference moved from below the
   body to above it, `-2.5` to `+2.5`, the exact mirror; U1's went `0` to
   `0.2875` on X. Both clear the 0.25 mm rule outright.

   The other 106 hidden references were residue of "hide the back references",
   from when every SMD part was on the back face — a rule that no longer
   describes the board. `tools/ref_silk.py` swept them: **71 are now shown**
   (65 at 1.0 mm, 2 at 0.9, 4 at 0.8), taking the board from 25 visible
   designators to 96.

   **25 stay hidden because nothing fits** — C11–C14, C16, C17 and eighteen
   resistors in the audio network, where 0603 parts sit on a 1.5 mm pitch and a
   two-character label is wider than the gap. They are left hidden rather than
   forced: a designator overlapping a pad prints ink on a solderable surface,
   which is worse than no designator. Identify those parts from `cpl.csv` in
   the fab package, or from the F.Fab layer in KiCad — every reference is still
   on F.Fab whether or not it prints.

   H1–H4 and FID1–3 are skipped by design — mounting holes identify no part,
   and fiducials are machine-read. U2, L1 and FB1 stay hidden deliberately,
   because their labels collide with their own outlines and get clipped by
   solder mask.
3. ~~**Human-readable silkscreen at the connectors.**~~ **Done** — all **77
   connector pins** are labelled, by `tools/pin_labels.py`. 61 at the full
   1 × 1 mm absonus size, 5 at 0.9, 4 at 0.85, 7 at 0.8; zero DRC issues.
   Re-run the tool after any placement change — the labels are board-level
   `gr_text` and do **not** follow a connector that moves.

   **All 77 are locked.** A hand-moved label keeps the uuid the tool gave it,
   so without a lock the next `--apply` silently reverts it. `--apply` is now a
   byte-for-byte no-op; `--relock --apply` is the deliberate override.

   Pin pitch decided the design. At 2.50 mm with 0.25 mm clearance, one row of
   1 mm text fits **two characters** — not enough for `3V3`. Staggering
   alternate pins into two rows doubles the effective pitch and buys five.

   **Seven connector references moved** to make room: J6, J7, J8, J9, J10, J19
   and J15 sat directly above their connectors, in the only band the labels
   could use. They are now rotated 90° in the gap beside each connector.
4. ~~**Logo and font from absonus**~~ **Done, including the mark.** The ensō is
   on F.SilkS at **18 mm, centred (174, 55.5)**, converted from
   `local/enso-oro.svg` by `tools/svg_to_silk.py` — 153 filled polygons,
   12 255 points. The wordmark `caryatid` + `v0.1` is separately at the bottom
   right by `tools/branding.py`.

   **The artwork was never in the v0.1 archive.** absonus v0.1 has zero images,
   zero silk polygons and no logo footprint across all three of its boards —
   which is why the earlier answer was "there is nothing to import". The mark
   arrived in **v0.3**, and the source is the SVG.

   **Size is measured, not chosen**: 18.50 × 18.71 mm on the fabricated
   absonus v0.3, read off `local/absonus-v0.3-pcb.pdf` at 600 dpi against its
   stated 3.6000 in width. caryatid's largest clear front-side square is 18 mm
   — within 3%.

   That measurement overturned an analysis of mine. Opening the artwork at
   JLC's 0.15 mm silk floor removes 27% of the ink at 18 mm and fragments the
   rings, which said **unusable**. A board fabricated at 18.5 mm says
   otherwise. The model was worst case; the board is evidence.

   `.venv` is required for this tool (`svgelements`), and is gitignored.

5. **Manufacturing readiness** — **was ready; reopened by ADR 0010.**

   > **Everything in this section describes the board as of `ad6a54d`**, before
   > the right-channel jumpers. It is kept rather than deleted because the
   > *gates* are unchanged and the cost work still stands — only the counts move.
   > Re-derive them by re-running the tools after the PCB is updated from the
   > schematic; do not hand-edit the numbers.

   `python3 tools/fab_package.py --apply` writes `local/fab/` and exits nonzero
   while anything is missing. It exited zero at `ad6a54d`.

   | gate | |
   | --- | --- |
   | DRC, plain | **2** — `lib_footprint_mismatch` A1/A2, metadata only |
   | DRC + `--schematic-parity` | **0 parity**, **0 unconnected** |
   | `check_board.py` | **12/12** over 135 footprints |
   | `drc_exclusions.py` | **0 new**, 5 accepted with reasons |
   | `verify_parts.py` | **0 of 43 flagged** against JLC's live data, 2 pre-order |
   | LCSC coverage | **127 of 127** placed (BT1 self-fit, see below) |

   **Package** — `local/fab/caryatid-fab.zip`, 14 files, 373 kB: 9 Gerber
   layers, drill, drill map, job file, `cpl.csv`. `bom.csv` sits beside it.
   Deliberately *not* courtyard, fab, adhesive or Eco layers, which an
   unrestricted export emits — and *not* `self-fit.csv`, which is the owner's
   shopping list and would only confuse the assembler.

   **Always run DRC with `--schematic-parity`.** Plain `kicad-cli pcb drc` does
   not check it and once hid 7 issues.

   **Board** 150 × 90 mm, 2 layers, 135 footprints, 957 tracks (4186 mm),
   167 vias. **BOM** 42 lines, **127 placed by JLC**, plus BT1 self-fit.

   **NOTHING IS DNP.** An earlier revision of this section read "47 lines, 91
   placed, 32 DNP excluded by design". [ADR 0010](decisions/0010-nothing-is-dnp.md)
   overturned that: DNP was an instruction to a person, and JLC fits the
   through-hole parts too. `--exclude-dnp` stays on both exports as a guard
   rather than a filter.

   **BT1 is `self_fit`, which is not DNP.** A DNP part is one the board is
   complete without; a self-fit part is one it is **not** complete without.
   BT1 goes to `self-fit.csv` because Digi-Key beat JLC's pre-order on both
   price and lead time, not because it is optional.

   **Cost** — re-derived 2026-08-18 from live price ladders by
   `tools/cost_estimate.py`, which selects the correct price band for the actual
   order quantity and respects MOQ:

   | | 5 boards | 10 boards |
   | --- | --- | --- |
   | parts (exact) | **$62.42** | **$119.90** |
   | per board | $12.48 | $11.99 |
   | estimated total | **~$169** | **~$249** |
   | per board | **$33.77** | **$24.88** |

   **$68 is fixed regardless of quantity** — an $8 setup fee plus 20 Extended
   parts at ~$3 each. That is 40% of a 5-board order, which is why the second
   five cost $15.99/board against $33.77 for the first five.

   **Superseded 2026-08-23 by three real orders.** Every estimate in this
   section is history; these are actuals:

   | | five boards | per board |
   | --- | --- | --- |
   | JLC, delivered | **$306.95** | $61.39 |
   | Orbtronic cells | $67.45 | $13.49 |
   | Digi-Key, delivered | $49.56 | $9.91 |
   | **total** | **$423.96** | **$84.79** |

   **The estimate was fine and the budget was not.** `cost_estimate.py`
   predicted $161.68 of merchandise against $176.24, out by 9%. It models
   merchandise only: shipping, customs duties, payment fee and sales tax added
   $130.71 to the JLC order, a 74% uplift, and both imports carried a tariff.
   See [`JLC-order-2026-08-23`](../discovery/findings/jlc-order-2026-08-23.yaml)
   and `~/.claude/contexts/ideocentric/_org.md`.

   > **A superseded figure lived here: "$5.24/board in components."** Do not
   > reinstate it. Beware `leastNumberPrice` in the JLC API — it reads $0.101 for
   > the Seed socket and $0.7533 for BT1, against real ladder prices of $0.338
   > and $4.86. It is not the price you pay.

   The fee is per unique part, **not per BOM line**. The **22** that stay
   Extended cannot move without a real compromise: connectors are absent from
   the Basic library, R3/R4/R7/R8 are E96 values that set charge current and
   boost output voltage, and C1 is 25 V X7R, which is a demanding part in 0805.
   (22 Extended / 20 Basic as of 2026-08-23; it read 20 before ADR 0010 fitted
   the right channel.)

   **Assembly splits in two.** `assemblyModeBatch` separates the SMT line from
   hand soldering: **100 SMT joints and 111 through-hole joints per board**, the
   through-hole being both Seed sockets, BT1 and all 17 JST/IDC connectors —
   8 codes, 19 parts. Full turnkey is the chosen route, so JLC solders both.

   **Two parts are pre-order**, both confirmed acceptable:

   | | | |
   | --- | --- | --- |
   | BT1 | `C5339083` | stock **0** |
   | A1, A2 | `C2897383` | stock 1403 — **pre-order regardless of stock** |

   > **Pre-order status is a recorded fact, not a derived one.** The JLC API
   > cannot tell you: `componentSource`, `warehouseCode` and
   > `assemblyComponentFlag` are uniform across all 36 parts here, and
   > `canPresaleNumber` does not separate them either. A stock-0 test catches
   > BT1 and misses the sockets entirely. `verify_parts.py` therefore reads the
   > flag back out of `lcsc.yaml`, where it is written down from JLC's own parts
   > library.
   >
   > **Confirmed again 2026-08-18, the hard way.** BT1 reports stock 0 *and*
   > `canPresaleNumber` 0 on the public endpoint, and is nonetheless orderable
   > through the logged-in parts library at **$4.8616** — below the $5.0468 the
   > public ladder quotes. The public API cannot see the pre-order route at all.
   > That is twice an automated test has overruled the human record and lost.

## Waiting on: the quote

**Decided — 5 boards, full turnkey.** 10 was costed and rejected for now: it
would mean changing the battery-holder pre-order quantity, and the holder is the
only long-lead item. Everything else can be re-quoted at any quantity right up
to order time, so nothing else has to be decided early.

**Unblocked 2026-08-20 by dropping BT1 from the assembly.** JLC quoted a
**21-day** turnaround on the BT1 pre-order. Rather than wait, it is now
**self-fit**: bought from Digi-Key and hand-soldered.

| | code | qty for 5 | unit | |
| --- | --- | --- | --- | --- |
| A1, A2 sockets | `C2897383` | 10 | $0.338 | pre-order, 1353 in stock |
| BT1 holder | Digi-Key 3029216 | 5 | **$3.47** | **not via JLC** |

**Nothing is lost off the SMT line.** BT1 is `manualWeld` — the assembler would
have hand-soldered it anyway. It is two through-hole joints (`VBAT`, `GND`,
72.9 mm apart) plus two M3 bolt holes at 55.61 mm, which the footprint already
carries. Digi-Key is *cheaper* than the pre-order as well as immediate: $3.47
against $4.8616.

**Substituting a different holder was considered and rejected.** BT1's footprint
is dimensionally specific, so swapping the part is a board change — self-fitting
the known-good part is strictly safer than fitting an available unknown.

> **BT1 is NOT DNP.** It is populated on every board; it is simply bought and
> soldered by the owner. `self_fit` in `lcsc.yaml` records this and
> `fab_package.py` strips it from `bom.csv` and `cpl.csv`, writing
> `self-fit.csv` as the shopping list. Marking it DNP instead would tell the
> assembler no part is fitted, which is false and would propagate.

Stock for the other 34 JLC codes was checked at qty 5 and clears.

**When the quote lands, reconcile rather than eyeball it:**

```sh
.venv/bin/python tools/cost_estimate.py 5 --quote <total>
```

It prints what the real number implies for each line it had to guess, since
parts is the one line that cannot be the source of the error. Correct `RATES`
and `PCB_FAB` in the tool from the answer and every future quantity improves.

**Two lines are worth checking specifically**, because they are where the
estimate is most likely wrong:

1. ~~**PCB fab.**~~ **Measured 2026-08-23.** `PCB_FAB[5]` is $42.56 with ENIG,
   derived by reconciling the tool against a real $176.24 merchandise total.
   Every other quantity in that table is still a placeholder.
2. ~~**Whether the Extended fee is per unique part or per BOM line.**~~
   **It was never open.** Per unique part, stated in
   `~/.claude/contexts/ideocentric/_org.md` and implemented in
   `cost_estimate.py` all along, while this list and the worklog carried it as
   unresolved. Closed 2026-08-23.
3. **What a landed cost actually is.** The tool models merchandise. Shipping,
   duties, fees and tax were 74% on top at JLC and 19% at Digi-Key, and nothing
   models them. This is the live one.

## Known open, beyond that list

🔴 **A design fault, found 2026-09-23 on a fabricated board: J13 faces into the
board.** The right-angle Qwiic connector sits 7.0 mm from the y=30 edge with its
cable opening pointing *away* from it, into 83 mm of PCB. **It needs rotating
180° in a future revision**, and rotating it alone is not enough: the pad order
reverses, so the routing must be reworked or the Qwiic pinout ends up mirrored,
which is worse than the present fault. The pinout itself is correct.

**It does not gate this build.** loa does not use J13, the five boards are
unaffected in service, and E10.1 remains runnable with an awkward cable. See
[`j13-qwiic-orientation`](../discovery/findings/j13-qwiic-orientation.yaml).

*What found it was a pair of eyes on a board during Phase B's visual inspection.
DRC, netlist parity, the fab house and twelve passing board checks all had
nothing to say about it, because none of them has a concept of which way a cable
should leave.*

From [capture-checklist.md](capture-checklist.md) and [sourcing.md](sourcing.md):

- ~~Tent the QFN thermal vias.~~ **Done, and it needed a redesign rather than a
  tent.** All four barrels were OPEN on the top face — the vias declare
  `(layers "*.Cu")` and open no mask themselves, but the EP pad declares
  `F.Mask` across the whole 1.68 mm square and the vias sit inside it. Open on
  top, sealed at the bottom, paste printed over the hole: a blind cavity that
  wicks paste in and traps expanding gas. Now **two** vias, mask-tented on both
  faces, with the EP mask opening moved clear of them. `tools/fix_ep_thermal.py`.
- **Extended-part loading fee** on `C5339083`, the cell holder.
- ✅ **The J4 bicolour LED WORKS**, 2026-09-22, Amazon `B01CFZMO3I`. **Common
  anode, diffused, and the green still lights at a 3.00 V supply** drawing
  0.77 mA, which is the flat-cell condition that decided whether the part was
  usable. ⚠️ **Its green die's chemistry is NOT established.** A claim that it
  was AlGaInP was withdrawn on 2026-09-23 when the bag label turned out to read
  3.0-3.2 V: a low-current forward voltage cannot distinguish the two, because
  series resistance dominates at the rated current and is invisible at 2 mA.
  **That does not change the verdict**, which rests on a directly measured
  operating point rather than on the material. A reading at 20 mA would settle
  it. See [`j4-charge-led`](../discovery/findings/j4-charge-led.yaml) and [sourcing.md](sourcing.md).
- **Parts still to source** — see the table in sourcing.md.
- **Datasheets** are gathered in `local/datasheets/`, gitignored. Index and
  links in [datasheets.md](datasheets.md).

## Working with the board

> ### Opening this board in KiCad damages `caryatid.kicad_pro`
>
> **It has happened twice.** Saving from the GUI silently:
>
> - **deletes netclass patterns** — `/power/DC_IN` (HighCurrent) and `+5V_RAW`
>   (Power) both went. That is how a rail ends up on a 0.25 mm track.
> - **empties `track_widths`** to `[]`
> - **wipes every DRC exclusion comment** to `""`, losing the recorded reason
> - **re-adds stale exclusions** — two `silk_overlap` entries came back
>   referencing violations that were *fixed* in `fd90beb`, not accepted
>
> **After any KiCad session, before committing:**
>
> ```sh
> git diff hardware/pcb/caryatid.kicad_pro     # expect NOTHING unless you changed a setting
> python3 tools/check_board.py                 # check 9 catches the netclass loss
> python3 tools/drc_exclusions.py              # catches stale or uncommented exclusions
> ```
>
> If the diff shows only the damage above, `git checkout hardware/pcb/caryatid.kicad_pro`.
> Nothing is lost — the project file holds settings, not design data.

```
python3 tools/check_board.py        # ten checks KiCad's DRC does not do
python3 tools/cycle.py              # placement -> fully routed, ~10 min
python3 tools/cleanup.py            # duplicate tracks, co-located vias, priorities
python3 tools/pour_from_drawing.py  # convert hand-drawn F.Cu polygons into pours
python3 tools/reset_placement.py    # back up and strip to placement only
python3 tools/round_corners.py      # corner radius on the Edge.Cuts rectangle
python3 tools/pin_labels.py         # silkscreen every connector pin's function
python3 tools/drc_exclusions.py     # gate: is any DRC violation NOT accepted?
python3 tools/fab_package.py        # gerbers, drill, BOM, CPL; refuses if unsourced
.venv/bin/python tools/search_list.py --apply   # JLC worklist for what is left
```

**`drc_exclusions.py` is the gate to run before a fab upload.** It matches every
DRC violation against an explicit table of accepted ones, each with a written
reason, and exits nonzero on anything unrecognised. It cannot bless a new
violation — that is the point. Seven known-good warnings are worse than none,
because the eighth arrives looking exactly like the noise.

> **KiCad's project save can silently drop design data.** Saving after the DRC
> exclusions were made removed two netclass patterns — `HighCurrent →
> /power/DC_IN` and `Power → +5V_RAW`, the exact gaps fixed earlier in this
> project — and emptied `track_widths`. `check_board.py` check 9 caught it;
> nothing in KiCad's own DRC would have. **Run `check_board.py` after any KiCad
> session that saves the project**, not just after tool runs.

**Excluding is done in KiCad, not by the tool.** Right-click a violation in the
DRC panel → **Exclude this violation**, save, then run the tool: it attaches the
documented reason to what KiCad wrote and prunes entries that no longer match a
violation. It never invents a key.

That division exists because the other way was tried and half-failed. KiCad
stores `["<type>|<x_nm>|<y_nm>|<uuid_a>|<uuid_b>", "<comment>"]`, and a version
of this tool synthesised the key from the DRC report. **Three of seven took.**
Type and uuids were right every time; the *coordinate* was not — it is the
footprint anchor for C4/C6/L1, but for A1/A2 it is neither the anchor nor the
bounding-box centre (both carry an identical x of 118.6825 mm matching no
obvious feature), and for `silk_overlap` it is neither item's reported
position. Not reconstructible, so not synthesised. Matching uses
(type, uuid_a, uuid_b), which is stable; the coordinate is carried verbatim.

**Lock anything you place or adjust by hand — copper and silkscreen both.** `cycle.py` strips everything unlocked and
re-routes; `export_dsn.py` hands locked copper to Freerouting as `(type protect)`
so it routes around it. Without the lock, hand work is deleted and not
regenerated — `fanout.py` only escapes radially, and routes like SW's channel
exit out of U2 do not come back.

**Reload in KiCad after any tool run** (File → Revert). The tools write to disk
and KiCad will not notice.

## Restore points

Tags, all pushed:

- `snapshot/pours-u2-routing`
- `snapshot/before-via-removal`
- **`snapshot/routed-2026-08-21`** — the last board with copper on it: 949
  tracks, 203 vias, 10 filled zones, parity 0. Stripped by `907fa83` so the
  route could be redone from a rebalanced placement. Its tag message carries
  the restore command.

Plus timestamped copies in `local/backups/`, which is gitignored.

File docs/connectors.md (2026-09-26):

# Connectors

Every variable element enters through a connector. The PCB layout is identical
for every instrument; each build populates a subset. Order once, stuff per
instrument.

Pin assignments are in [pinmap.md](pinmap.md), generated from
[pins.yaml](pins.yaml). This file covers the connectors themselves.

| Ref | Type | Carries |
| --- | --- | --- |
| J1 | JST-XH 2 | 5–9 V in, **from a panel-mounted barrel jack**. Never 12 V. |
| BT1 | MPD BH-18650-PC, on-board | **The cell.** Rated for *protected* cells (~69 mm) — stated on the drawing. `C5339083`. |
| J3 | JST 4 | Latch switch: OUT→sw, EN return, 5 V→lamp, GND |
| J4 | JST 4 | `/CHG` and `/PGOOD` panel LEDs, 1k each from OUT |
| J5 | IDC 2×5 | **Analogue bus** — A0–A3, A6–A9 + 3V3A + AGND. Rails on the outer pins; **1kΩ/100nF** per wiper, board side — see [values.md](values.md). |
| J6 | JST 2 | SW1 → D14 via 74HC14 — *or* J15 takes the pins |
| J7 | JST 2 | SW2 → D13 via 74HC14 — *or* J15 takes the pins |
| J8 | JST 2 | SW3 → D7 via 74HC14 |
| J9 | JST 3 | Soft pot: 3V3A, A5, AGND |
| J10 | JST 2/3 | FSR: 3V3A, A4 |
| J11 | IDC 2×5 | **Digital bus**: D0-D6 + **`+3V3`** + **`GND`** + spare. 100Ω series each. *(This read "3V3D + DGND" until 2026-09-25. **Neither net exists.** There are two 3.3 V nets, `+3V3` and `+3V3A`, and one ground. The D suffix was shorthand for the digital side and was read as a net name by `bringup.md`, which carried a test step for it into every generated sheet.)* |
| J12 | JST 4 | RGB status. **Common anode**: pin 1 `+5V`, then D26/D27/D29 cathodes sinking through **510Ω red, 300Ω green, 300Ω blue**. Not GND, not 3V3 — see [panel-io-sheet.md](panel-io-sheet.md). |
| J13 | JST-SH 4 | **Comms port A** as I2C, Qwiic / STEMMA-QT pinout. 🔴 **Faces into the board**, a known fault for a future revision. Pinout is correct; only the facing is wrong. See [`j13-qwiic-orientation`](../discovery/findings/j13-qwiic-orientation.yaml) |
| J14 | JST-XH 2 | Mic bias return → the hook switch's second pole |
| J19 | JST-XH 6 | **Comms port A** as a module port — 5V, 3V3, GND, D11, D12, GND |
| J15 | JST-XH 6 | **Comms port B** — 5V, 3V3, GND, D13, D14, GND |
| J16 | header 2×4 | **Expansion / SPI1** — 5V, 3V3, GND, GND, D8 SCLK, D9 MISO, D10 MOSI, D30 CS |
| J17 | JST-XH 3 | Audio out — L, R, GND, to panel jacks |
| J18 | JST-XH 3 | Audio in — L, R, **`MIC_RTN`**. Both channels fitted and jumper-selected on every board |

> **Three entries in that table were wrong until the silkscreen work checked
> them against the schematic.** They are recorded here because the error was in
> this file, not on the board, and the next person to read it should know it has
> been reconciled rather than merely written:
>
> - **J19 and J15 pin 6 were listed as `AUX`. Both are `GND`.** There is no
>   `AUX` net anywhere in the schematic or the board — the name existed only
>   here. Each port carries **two grounds**, which is what a six-way cable to a
>   module wants anyway.
> - **J19 and J15 were listed as JST-PH. Both are JST-XH**, `B6B-XH-A` at
>   2.50 mm, per the schematic's own Footprint property. Ordering PH housings
>   against this table would have produced parts that do not mate.
> - **J18 pin 3 was listed as `GND`. It is `MIC_RTN`** — the mic bias return,
>   which pairs with J14 pin 1 and is precisely *not* a ground; that is the whole
>   point of J14.
>
> Nothing on the board changed. The schematic and the PCB agreed with each other
> throughout; only this file disagreed with both.

## Every pin reaches a connector

There are no stranded pins. `A10` and `A11` are on-board by definition — they
measure the board's own battery and charger — and every other pin lands on
something you can plug into.

That includes the spare. **`D30` is brought out on J16**, so "spare" means
usable rather than merely unallocated. J16 is a 2×4 rather than the 2×3 the
signals strictly need: the extra two positions carry **5 V and a second ground**,
which cost no Seed pins and are what a display or an SD card will want. A spare
pin on a header you can reach is worth something; a spare pin on a pad is worth
nothing.

## Silkscreen every connector's pinout

This board is assembled once and **cabled differently for each instrument**, by
hand, months apart. The loom is where the mistakes will be, not the PCB.

So **print the function of every pin beside every connector** — `+3V3A`, `A5`,
`GND` at J9; `VOUT`, `CHG`, `PGOOD`, `GND` at J4 — and mark pin 1 on all of them.
It costs nothing at fabrication and it is the difference between crimping a loom
from the board and crimping it from a document that may not be open.

Same argument as printing the pin names beside the Seed sockets. The board should
be readable without its documentation.

## Nothing mounts on the board edge

Every panel part is panel-mounted and reaches the board by wire: the DC jack
(DC-099, threaded), the 3.5 mm audio jacks, the LED bezel and the latching
switch. So **the board carries no jack footprints at all** — J1, J17 and J18 are
JSTs, and the jacks live wherever the enclosure wants them.

This is the right way round for a platform. Board-mounted jacks make the PCB
edge *be* the panel, which suits a sandwich enclosure and rules out a telephone
shell. Wire lets one board sit inside three different objects.

The cost is real and worth stating: **audio now travels on flying leads**, past
a 1 MHz boost converter, inside a shell. Keep J17 and J18 physically near the
audio section and far from the switcher, run the pairs twisted with their
grounds, and treat routing them as a layout constraint rather than something to
tidy up at assembly.

It also moves the single-point ground bond. Layout rule 5 said "at or near the
audio jacks" on the assumption they were on the board; with panel jacks, the
bond belongs at the panel end of the audio loom.

## Comms ports

The most useful thing in this design and the least obvious. **D11/D12 are
simultaneously I2C1 and UART4**, so a port is two signal lines whose protocol is
decided by what you plug in and a line of firmware config — not by the board.

| | Port A (D11/D12) | Port B (D13/D14) |
| --- | --- | --- |
| Protocols | I2C1, UART4 | USART1 |
| Typical use | I2C sensor, or MIDI | MIDI, or an ESP32 OSC bridge |
| Competes with | — | SW1 and SW2 |

**Two footprints on port A, populate one.** The 4-pin JST-SH follows
Qwiic/STEMMA-QT so an off-the-shelf sensor is a cable rather than a breakout you
design. The 6-pin JST-PH carries both rails plus an AUX line, which is what a
MIDI input opto or a radio module wants. Footprints are free; connectors are the
cost.

**Port B competes with SW1/SW2.** That is why loa's hook switch belongs on
**SW3 (D7)** — USART1 needs both D13 and D14, and a hook switch sitting on one
of them would quietly cost you the port.

**MIDI's opto-isolator lives on the daughterboard**, not here. The port carries
logic-level signals and power; isolation is the breakout's job. That keeps the
platform free of a circuit most builds do not populate.

## What the outside world sees is not a board decision

The board terminates audio at jacks and MIDI at a comms port. Whether the
instrument's panel presents three sockets or a single RJ45 carrying everything
is a panel-and-loom question, and it can be settled after the PCB.

For the record, if one cord is wanted for a single-direction MIDI input plus
stereo audio, six conductors do it and the split pair earns its keep as a guard:

| RJ45 pin | Pair | Signal |
| --- | --- | --- |
| 1, 2 | 2 | Audio L — signal + its own return |
| **3** | **3** | **GND guard** |
| 4, 5 | 1 | Audio R — signal + its own return |
| **6** | **3** | **GND guard** |
| 7, 8 | 4 | MIDI IN — to the opto LED |

Pair 3 is split across the connector in T568B, which makes it the worst pair for
signal and the best one for a guard: pin 6 sits physically between the audio and
the MIDI pair, exactly where the termination untwist makes coupling worst.

Two hazards if you go this way. **PoE** — an RJ45 on a panel invites a network
cable, and a PoE port will put 48 V into your line outputs. Use a locking shell
or a legend. And **RJ12 is the authentic phone connector but standard line cord
is flat untwisted ribbon**, so all the twisted-pair reasoning above evaporates;
it needs round shielded 6-conductor cable, which rather undercuts the point.

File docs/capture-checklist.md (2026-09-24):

# Schematic capture checklist

Ordered so the frozen pin map gets **enforced** rather than re-derived. Work
down it; do not skip ahead to the fun part.

## Before opening KiCad

- [x] ~~Confirm the licence answer is still "draw from the datasheets."~~
      **Held, and the licence is settled** — CERN-OHL-S v2 for the hardware,
      GPL-3.0-or-later for the tools, 2026-08-18.
      [ADR 0006](decisions/0006-licensing-is-open.md),
      [LICENSING.md](../LICENSING.md). Nothing derives from an Adafruit schematic;
      every input was audited before the licence was chosen. The rule that
      produced this outcome still applies to any future capture work: once a
      schematic derives from someone else's source file it cannot be un-derived.
- [ ] **Measure the handset capsule** — DC resistance across it decides whether
      the input network gets a preamp or a pad. [audio.md](audio.md). **It also
      sets the largest unresolved term in the 5 V budget**: R52/R54 bias at
      220 Ω each, so 23–41 mA for the pair depending where the capsule sits —
      up to 16% of the typical rail load. See the line-item table in
      [values.md](values.md).
- [x] ~~Verify D26 / D27 / D29 are 5 V tolerant.~~ **Done** — all three are
      `FT` per Table 7 of `DS12556`. Common anode to 5 V with the GPIOs sinking
      is the scheme; see [values.md](values.md) for the absolute-maximum
      condition and why the pin never actually sees 5 V here.
- [x] ~~Check the bq24074's JLC PCBA type.~~ **Done** — Economic **and**
      Standard, same as the boost. The Economic assembly split holds. Library
      type is unpublished for both; assume Extended and a ~$3 setup fee each,
      which JLC prices when the BOM goes up.
- [x] ~~Measure the RGB forward voltages and confirm common anode.~~ ✅ **Done
      properly 2026-09-23**: common anode and diffused both confirmed by hand,
      Vf 1.932 / 2.454 / 2.607 V at 5 V through 990 Ω. **The vendor was right**,
      which is the least interesting outcome and exactly why it had to be
      checked rather than assumed. See [`j12-rgb-led`](../discovery/findings/j12-rgb-led.yaml).
      🔴 **This item had previously been ticked "Done" since before 2026-09-22
      without having been done.** The figures recorded against it, common anode and Vf 2.0-2.2 V red
      with 3.0-3.2 V green/blue, are **the vendor's specification**, quoted as
      such in [sourcing.md](sourcing.md) under "Specification from the vendor".
      Reading a listing is not measuring a part, and the checkbox said
      *Measure*. Untick and do it: it is **A7.4** in
      [bringup.md](bringup.md), the diode test plus forward voltages.
      ⚠️ A handheld's diode test supplies only ~2.4 V, so a 3.0-3.2 V green or
      blue die reads **OL even when it is good and correctly oriented**. Use the
      bench supply through a series resistor, not the diode test alone. (The J4
      bicolour was measurable on diode test only because its green turned out to
      be 2.322 V. See [`j4-charge-led`](../discovery/findings/j4-charge-led.yaml).)
      Starting resistors stay 510 Ω red, 300 Ω green and blue, then **tune green
      down by eye**, since equal current is not equal brightness.
- [ ] **Measure the switch bezel diameter.** Ø12 is the *mounting hole*, and the
      bezel flange is larger, typically 14–15 mm on a 12 mm switch. It is the
      only mechanical number still missing: the DC jack, audio jacks and LED
      bezel are specified in [sourcing.md](sourcing.md), and the lamp's
      electrical side is fully closed. ✅ The part is a **3–6 V** variant, not
      the 3–9 V one these documents were written against, and its current was
      measured 2026-09-20 at **28.5 mA at 5.00 V** with internal limiting by a
      plain ~87.5 Ω series resistor.
- [ ] **No jack footprints on the board.** Every panel part is panel-mounted and
      arrives on a JST — J1 for DC in, J17 and J18 for audio. See
      [connectors.md](connectors.md).

- [ ] **Reuse the absonus footprints** listed in [sourcing.md](sourcing.md).
      They are drawn and fabricated already. Check pin-1 orientation and JST
      polarity against *this* schematic; proven to fabricate is not proven
      correct here.
      🔴 **And check WHICH WAY IT FACES, which is a separate question from the
      pinout.** This item once asked only about pin-1 and polarity, both
      electrical, and **J13 got through it**: a right-angle Qwiic connector
      whose pinout is perfectly correct and which points into the board. A
      checklist that would have passed the thing it was meant to catch is a
      quieter problem than one that is never run. Vertical connectors carry no
      facing direction to get wrong, which is why the question was not asked;
      **any right-angle part does.** Broadened 2026-09-23, see [`j13-qwiic-orientation`](../discovery/findings/j13-qwiic-orientation.yaml).
- [ ] 🔴 **Sweep the 3D render for footprints with no visible body**, before
      fab. `local/fab/board-top.png` is a 3D render and **does** show which way
      a right-angle connector faces, for every part whose model resolves.
      **J13's did not.** It is the only connector in that render showing bare
      pads, which is why its facing fault was invisible before shipping and
      obvious the moment a board was in hand. **The gap is silent**: nothing
      errors and nothing warns, the part simply is not there. Cheap to spot,
      because a missing body looks like bare pads in a sea of solid parts.

## Sheet structure

Hierarchical, so the power section stays a reusable block for a future board:

- [x] `power.kicad_sch` — charger, boost, latch, hardware charge LEDs
- [x] `seed.kicad_sch` — Seed sockets, battery gauge, charge-status code
- [x] `audio.kicad_sch` — jacks, coupling, mic bias and preamp/pad options
- [x] `panel-io.kicad_sch` — analogue bus, digital bus, switches, comms ports

## Enforcing the pin map

**This is the part that matters.** `docs/pins.yaml` is the source of truth, and
the schematic is a *consumer* of it, not a second opinion.

- [x] Label every Seed net with the **pin name from `pins.yaml`** — `A7`, `D11`
      — not with what the net does on one instrument. `D11` is not `SCL`; it is
      `D11`, and I2C is one thing it can be.
- [x] **Cross-check the finished schematic against `pinmap.md` pin by pin.** By
      script if you can face writing one, by eye if not, but do it as a
      distinct pass rather than while drawing.
- [x] **`D8` is the only free SPI1 clock.** If anything ends up on it that is
      not the expansion header, stop.
- [x] **Hook switch on `D7`, never `D13`/`D14`.** Those two are comms port B and
      USART1 needs both.

## Power sheet

**Captured.** `power.kicad_sch` holds all 27 components and 19 nets, ERC is
clean, and the exported netlist was diffed node-by-node against
[power-sheet.md](power-sheet.md) — every net matches. The boxes ticked below are
the ones that diff proves. The unticked ones are layout or silkscreen work, or
belong to another sheet.

- [x] **`EN2` to `VOUT`, never to `VIN_DC`.** EN1/EN2/CE are 7 V absolute max
      and VIH is valid only to 6 V; the barrel input goes to 9 V. This is the
      one that destroys a part.
- [x] **`ILIM` must be populated** — leaving it open disables all charging.
- [x] **`ITERM` no-connect flag**, deliberately floating for 10% termination.
- [x] **Charge LED anodes on `VOUT`, not `+5V`** — they must work with the
      boost off, which is the whole point of them.
- [x] C1 rated **25 V**: it sits on the raw barrel input.

- [ ] Barrel jack → SS34 → bq24074 `IN`. **5–9 V, never 12 V** — silkscreen it.
- [x] `RISET` **887 Ω, 1%** — the 1% is a datasheet requirement, not a
      preference; the part short-tests this resistor.
- [x] `RILIM` **1.2 kΩ** → 1.29 A input limit. Valid range is 1.1 k–8 k; below
      1.1 k does not mean more current, it means undefined.
- [x] `TS` → 10 kΩ NTC in the pack, **or a fixed 10 kΩ to VSS if the pack has
      none.** Not optional, not floatable.
- [x] `/CHG`, `/PGOOD` → J4 LEDs, 1 k each **from the OUT rail** so they work
      with the Seed off. This is what satisfies P-2.
- [x] `/CHG`, `/PGOOD` → also into the A11 encoder: **four 10 k 0.1% (C374544,
      in stock)** — pull-up **to 3V3**, 10 k on `/CHG`, 2×10 k series on
      `/PGOOD`, then 1 k / 10 nF to the pin. Pull-up on 3V3 and not OUT, so it
      draws nothing while off.
- [x] Boost `FB` divider **348 k / 47.5 k for 5.0 V**. Not 5.2 V — see
      [values.md](values.md), it leaves 109 mV to the OVP minimum.
- [ ] Inductor **C354578** — 1 µH, 4.2 A Isat against a 1.51 A worst-case peak
      at 30% derating. Working in [sourcing.md](sourcing.md).
- [x] `EN` 100 k pulldown; latch switch asserts EN from the OUT rail.
- [x] Ferrite + 100 µF between boost output and everything downstream.
- [x] Switch lamp from the 5 V rail through a **0 Ω 0603** link.

## Seed sheet

**Captured.** `seed.kicad_sch` holds both sockets and the two measurement
networks. ERC has no errors; the 33 warnings are all `global_label_dangling`,
one per Seed pin that leaves for panel-io or audio — sheets not yet captured.
That count is a checksum: 15 `D0`–`D14`, 10 `A0`–`A9`, 4 RGB/expansion, 4 audio.
It should fall to zero as those sheets land, and any *other* dangling label is a
mistake.

The cross-check against the frozen map was run as its own pass, by script:
**all 31 physical pins in `pins.yaml` land on a net named after the pin.**

- [x] **Name every Seed net after its pin** — `D0`, `A7`. That is what turns
      the cross-check against `pinmap.md` into a diff.
- [x] **`AGND` (pin 20) ties to `GND`.** One plane; no split.
- [x] `3v3A` (21) and `3v3D` (38) stay separate — supplies, not returns.
- [x] Battery gauge on A10: 100 k / 100 k, then 1 k / 10 nF at the pin.
- [x] A11 encoder: four 10 k 0.1%, 20 k leg made from two in series.
- [x] **No no-connects on this sheet.** All forty pins are used; if ERC finds
      one, something is missing.
- [x] **Two socket designators, `A1` and `A2`**, one per 1×20 strip. absonus
      used a single designator and the BOM asked for one socket where the board
      needs two. Using both symbols is what makes the schematic carry the
      quantity — placing one twice would put the same designator on both.
- [x] ~~Draw the Seed orientation back in as silkscreen~~ — outline, pin-1 dot,
      square pads at the USB end of both rows, and the `USB` legend are **inside
      the two footprints**, so they travel with the sockets. Per-pin labels were
      drawn and then dropped: see [seed-sheet.md](seed-sheet.md).
- [ ] **Place `A1` and `A2` exactly 15.24 mm apart** at layout. The outline and
      USB tab are split across the two footprints and only close up at that
      spacing — a broken outline on the board render means the spacing is wrong.

## Panel I/O sheet

**Captured.** `panel-io.kicad_sch` holds 59 placements across 46 components. No
custom symbols — the 74HC14 and every connector are stock KiCad.

ERC has no errors, and the dangling-global count has fallen **33 → 4**: the only
labels still unresolved are `AUDIO_IN_L/R` and `AUDIO_OUT_L/R`, waiting on the
audio sheet. That was the predicted number, and it landing exactly is the check.

The pin-map enforcement pass was run by script against `pins.yaml`, traversing
series resistors and the debouncer rather than demanding a direct connection:
**all 29 pins that declare a connector reach it**, and A10/A11 correctly reach
none because they are on-board measurements.

- [x] **A4 gets 10 kΩ, A5 gets 3 kΩ.** The spec had these transposed; the
      fabricated absonus board is the authority. FSR 10 k, soft pot 3 k.
- [x] **Hook switch on SW3 / J8 / `D7`.** Never SW1 or SW2 — those are comms
      port B and USART1 needs both pins.
- [ ] 74HC14 per channel: 10 kΩ pull-up, 10 kΩ series, C to ground. **C is a
      population choice** — 220 nF panel, **1 µF for a hook lever**. 100 nF is
      below typical bounce.
- [ ] **Tie unused 74HC14 inputs (9, 11, 13) to `GND`.** Floating CMOS inputs
      oscillate.
- [ ] 100 nF decoupling on the 74HC14.
- [ ] **The output is inverted — leave it that way.** An unplugged cable then
      reads as switch-open, which for loa is on-hook and silent. See
      [ADR 0007](decisions/0007-rc-and-schmitt-instead-of-the-ls18-p.md).
- [ ] J5 wipers **1 kΩ / 100 nF**, not 220 Ω / 10 nF.
- [ ] J11 **100 Ω series** on each of D0–D6.
- [ ] RGB **510 Ω red, 300 Ω green and blue**, anode on `+5V`.
- [ ] I2C pull-ups 4.7 kΩ **fitted** — a UART line idles high, so they are
      harmless on the serial use of the same pins. ADR 0010.
- [ ] **Nothing carries `dnp`.** `check_board.py` check 12 enforces it.
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

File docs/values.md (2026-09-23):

# Component values

Derived from the TI datasheets — bq24074 `SLUS810N`, TPS61023 `SLVSF14B` — not
from application notes or reference designs. Constants are quoted from the
electrical characteristics tables so the arithmetic can be checked.

Document numbers, revisions and links for every part are in
[datasheets.md](datasheets.md); the PDFs live in `local/datasheets/`, which is
gitignored because they are the manufacturers' copyright.

Three of these changed a number in the platform spec. They are marked **changed**.

## Charger — bq24074

`ICHG = KISET / RISET`, with **KISET = 890 AΩ typical (797 min, 975 max)**.

| Charge current | RISET | E96 1% |
| --- | --- | --- |
| 0.5 A | 1780 Ω | 1780 |
| **1.0 A** | **890 Ω** | **887** |
| 1.5 A | 593 Ω | 590 |

The spec's 890 Ω for 1 A is correct. **But the tolerance is not in the
resistor** — KISET alone spans 797–975, so 887 Ω delivers **0.90 A to 1.10 A**
across the part distribution. Budget for ±10% and do not size a supply or a
charge-time claim on the nominal.

The datasheet is explicit that **RISET must be 1%**, and not for accuracy: the
part runs a short test on RISET at the maximum charge setting, and a loose
resistor can trip it.

**Charge time**, 3400 mAh cell at 1 A, allowing for the constant-voltage tail:
about **4.0 hours**. Requirement P-9 asks for "fast enough between soundcheck
and downbeat", which this is not. 1.5 A would give ~2.7 h. The trade is heat and
cell life; 1 A on this cell is 0.29C and gentle, 1.5 A is 0.44C and still within
spec. **Left at 1 A**: the barrel jack means charging can start early, and cell
longevity is worth more than an hour.
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

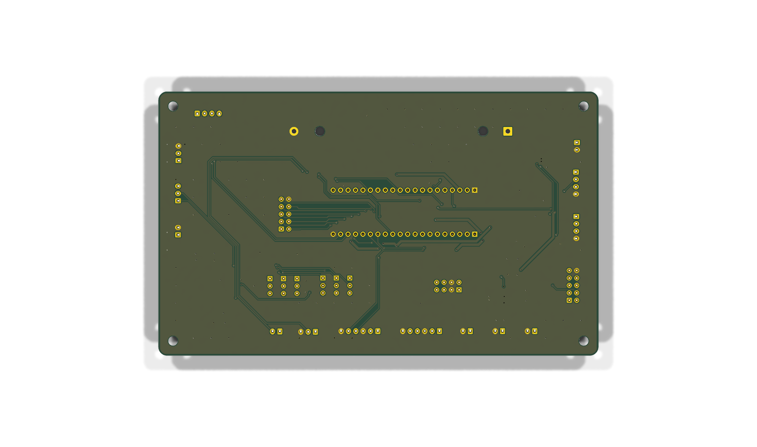
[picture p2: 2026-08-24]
docs/img/board-bottom.png

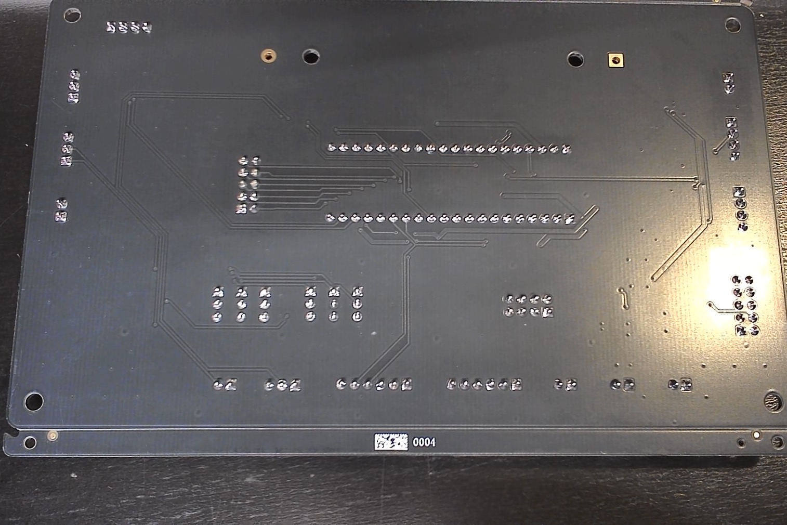
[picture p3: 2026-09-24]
discovery/evidence/2026-09-23-board-4-bottom.jpg

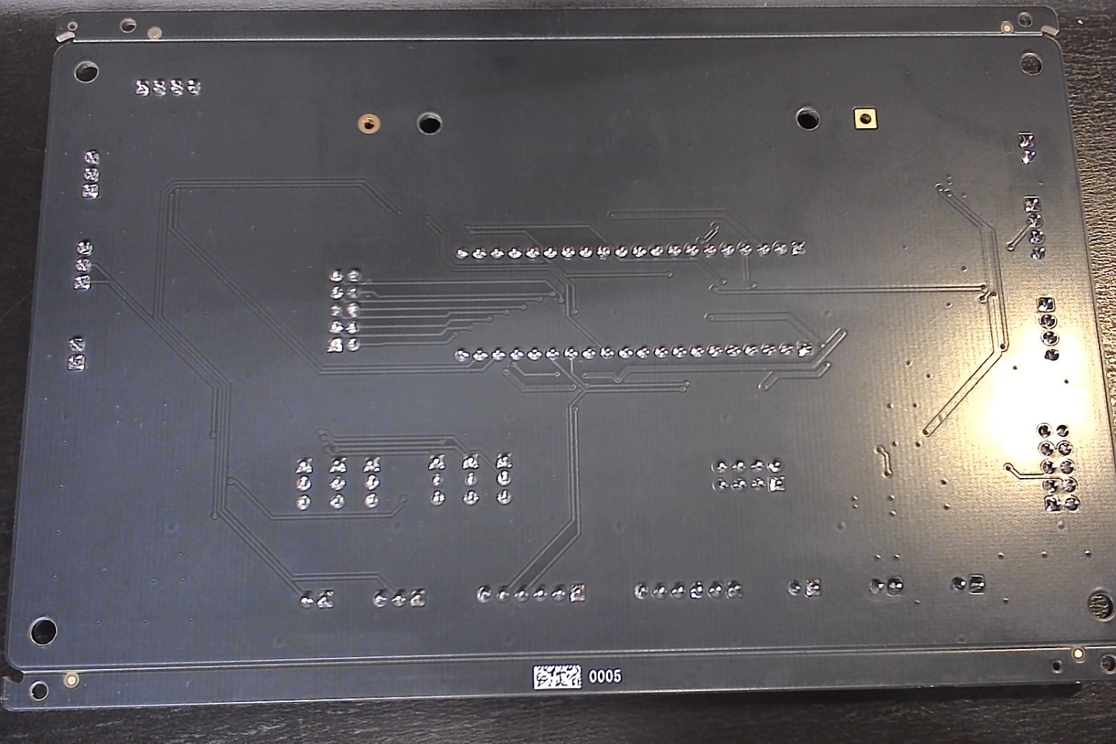
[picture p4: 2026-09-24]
discovery/evidence/2026-09-23-board-5-bottom.jpg

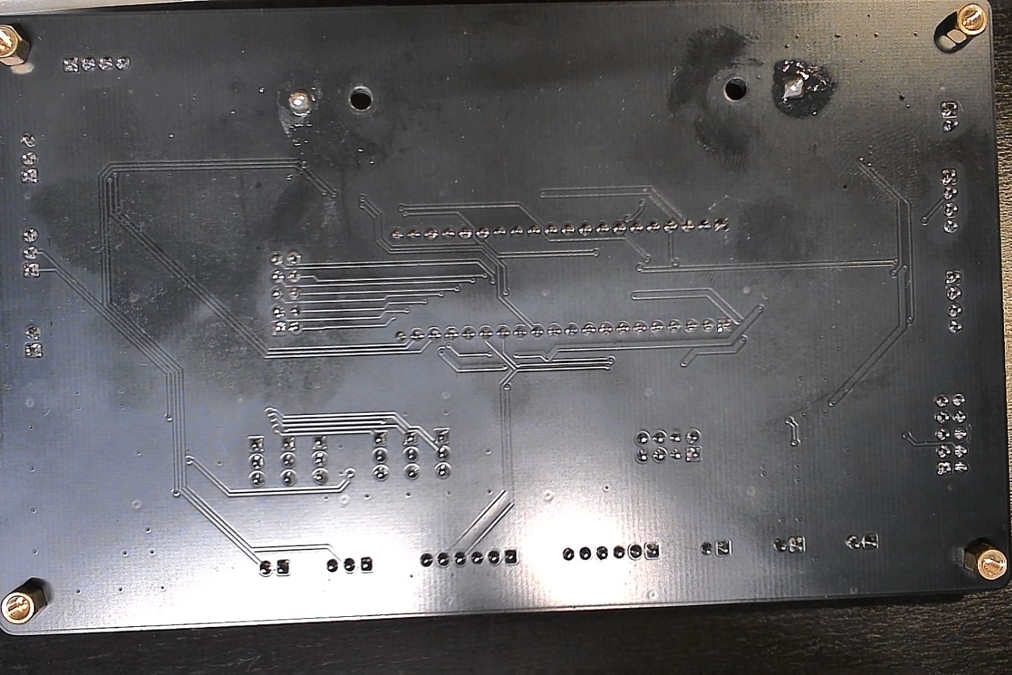
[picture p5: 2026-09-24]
discovery/evidence/2026-09-23-board-1-bottom.jpg

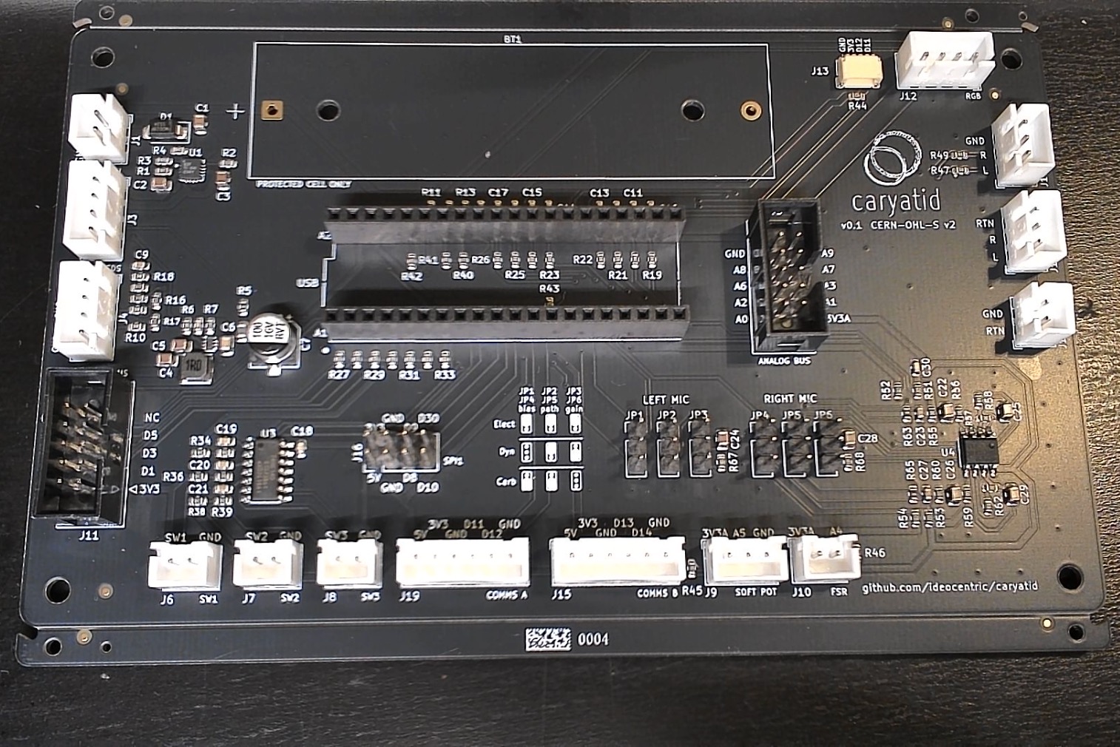
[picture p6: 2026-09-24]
discovery/evidence/2026-09-23-board-4-top.jpg

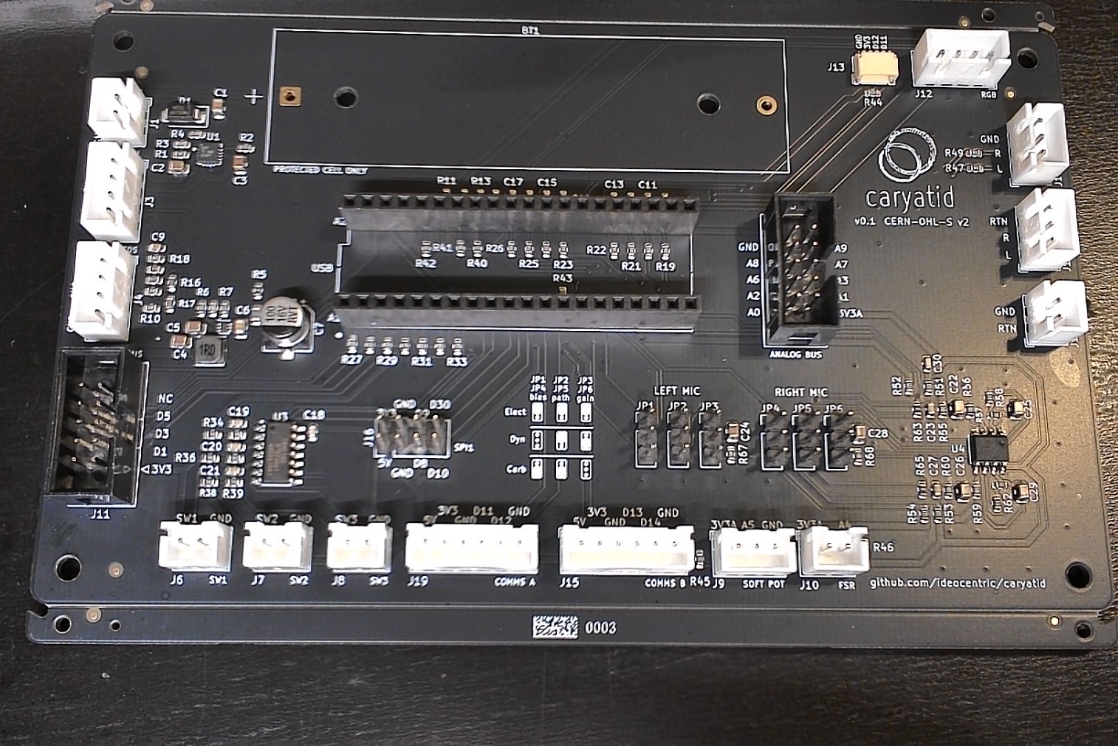
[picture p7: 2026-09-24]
discovery/evidence/2026-09-23-board-3-top.jpg

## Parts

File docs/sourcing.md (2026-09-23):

# Sourcing

What is already in the JLCPCB library and on the absonus board, and what caryatid
still needs. Component *values* are in [values.md](values.md); this is about part
numbers, footprints and what is physically in stock.

Drawn from the JLC parts inventory and the absonus working BOM. **The footprint
names are the most useful thing here** — they are already drawn, already
fabricated once, and reusing them turns capture into transcription.

## Already in the library

| LCSC | Part | Footprint | Stock | For |
| --- | --- | --- | --- | --- |
| **C4749194** | DS254P-2X5-L0 | `IDC-Header_2x05_P2.54mm_Vertical` | **176** | J5, J11 |
| **C374544** | AR03BTDX1002A010, 10 kΩ **±0.1%** | 0603 | **176** | A11 divider — see below |
| **C41361038** | DS1023-1x20S21, 1×20 socket | `插件,P=2.54mm` | **36** | Seed sockets — Global Sourcing |
| C2897383 | 1×20 female socket | — | on absonus | **Seed sockets, the part actually used** |
| C158012 | JST **B2B-XH-A(LF)(SN)**, 2-pin | `JST_XH_B2B-XH-A_1x02_P2.50mm_Vertical` | on absonus | J6, J7, J8, J10 |
| C144394 | JST **B3B-XH-A(LF)(SN)**, 3-pin | `JST_XH_B3B-XH-A_1x03_P2.50mm_Vertical` | on absonus | J9 |
| C160404 | JST-SH 4-pin horizontal | `JST_SH_SM04B-SRSS-TB_1x04-1MP_P1.00mm_Horizontal` | on absonus | **J13, Qwiic** |
| ~~C5289485~~ | ~~LS18-P~~ | — | on absonus | **superseded** by the 74HC14, [ADR 0007](decisions/0007-rc-and-schmitt-instead-of-the-ls18-p.md) |
| — | *Daisy Seed footprint* | `Electrosmith_Daisy_Seed` | — | outline only; the module is not a BOM line |
| C3337 | 220 µF electrolytic | `CP_Elec_5x5.4` | on absonus | bulk |
| C15401 | 10 kΩ 1% | 0603 | on absonus | general |
| C4211 | 3 kΩ | 0603 | on absonus | was the absonus soft-pot pulldown |
| C188666 | **6N138SDM** optoisolator | SOP-8-2.54mm | 0 | **MIDI breakout, not this board** |

Two notes on that list. The 2×5 IDC at 176 covers J5 and J11 for about eighty
boards, and the Seed sockets at 36 cover eighteen. And the **6N138 is already
identified** — it is the MIDI input opto, and it belongs on the daughterboard,
not here, exactly as [ADR 0003](decisions/0003-comms-ports-are-protocol-agnostic.md)
says.

*(The two inventory exports supplied are byte-identical — a duplicate download,
not two different lists.)*

## Standardise the JSTs on XH

absonus uses **JST-XH, 2.5 mm** throughout, and Qwiic SH only where the Qwiic
standard requires it. caryatid's spec said JST-PH for the battery and left the
rest generic. **Follow absonus: XH everywhere except J13.**

One crimp tool, one housing family, one set of pre-crimped leads, and two of the
sizes are already stocked. It also happens to be the better electrical choice for
the battery: **XH is rated 3 A against PH's 2 A**, and this board pulls over 1 A
from the cell at low state of charge and can push 1.29 A into it while charging.
PH would have been working close to its rating for no reason.

| Connector | Size | Have it? |
| --- | --- | --- |
| J6/J7/J8 switches, J10 FSR | XH 2 | ✅ C158012 |
| J9 soft pot | XH 3 | ✅ C144394 |
| J3 latch, J4 charge LEDs, J12 RGB | XH 4 | ✅ **C144395** |
| J19, J15 module ports | XH 6 | ✅ **C144397** |
| J13 Qwiic | SH 4 horizontal | ✅ C160404 |

**Sourced.** Both are the same JST XH family as the two already in use, so the
housings, crimps and crimp tool carry straight over:

| LCSC | Part | Pins | Rating | Price | Footprint |
| --- | --- | --- | --- | --- | --- |
| **C144395** | JST `B4B-XH-A(LF)(SN)` | 4 | 250 V / 3 A | ~$0.032 | `JST_XH_B4B-XH-A_1x04_P2.50mm_Vertical` |
| **C144397** | JST `B6B-XH-A(LF)(SN)` | 6 | 250 V / 3 A | ~$0.048 | `JST_XH_B6B-XH-A_1x06_P2.50mm_Vertical` |

Note the LCSC numbering runs with the family — C144394 is the 3-pin already in
use, C144395 the 4, C144397 the 6 — which is a small confirmation they are the
same listing series rather than lookalikes from another maker. Footprint names
follow KiCad's `Connector_JST` convention exactly as the 2- and 3-pin ones do;
confirm they are present in the library rather than assuming.

## The A11 divider can be one resistor value

**changed.** [values.md](values.md) specified 10 k / 11 k / 18 k, chosen before
this inventory existed. With 176 precision 10 k in stock, a version built
entirely from that one value is better on every axis that matters:

| | Three values | **One value** |
| --- | --- | --- |
| Network | 10 k / 11 k / 18 k | 10 k pull-up, 10 k on `/CHG`, **2×10 k series** on `/PGOOD` |
| Levels | 3.300 / 2.121 / 1.729 / 1.339 V | 3.300 / 2.200 / 1.650 / 1.320 V |
| Minimum gap | 390 mV | 330 mV |
| Worst case | 377 mV at 1% | **329 mV at 0.1%** |
| Unique parts | 3 | **1** |
| Resistor count | 3 | 4 |

### Why the smaller separation is the better choice

330 mV looks like a downgrade from 390 mV, and read on its own it is. But
separation is not a score to maximise — it is a threshold to clear, and past
that point more of it buys nothing.

**What the number has to achieve** is that the four voltage bands never overlap
once resistor tolerance, reference drift and ADC noise are accounted for, so the
firmware can never mistake one charge state for another. That is a pass/fail
question, not a scale.

**Both designs pass it by an enormous margin.** 330 mV is **409 ADC counts** of
gap between the closest two states. Noise on a filtered pin like this is a
handful of counts. The separation could shrink by a factor of ten and the
reading would still be unambiguous — which is exactly what the earlier
Monte-Carlo showed when the three-value network still held at 5% parts.

So the extra 60 mV is headroom that will never be touched. It is a bridge rated
for fifty tonnes instead of forty when the heaviest thing crossing weighs two.

**What it costs is real, though.** Three distinct values mean three BOM lines,
three reels to buy, and three feeder positions on the assembly line — where one
value means one of each. On a small run the per-unique-part handling is a
meaningful fraction of the assembly cost, and it recurs on every build.

**And the single value is the more accurate part.** The stocked 10 k is **0.1%**,
ten times tighter than the 1% the analysis assumed. So in practice the one-value
network degrades from 330 mV nominal to 329 mV worst case — essentially not at
all — while the three-value network at ordinary 1% parts drops from 390 mV to
377 mV.

The one-value network is therefore *less* accurate on paper and *more* accurate
in the drawer, and it is cheaper to build. That is the whole argument.

Use the stocked 0.1% part for all four.

## The RGB LED

**CHANZON 5 mm, common anode, 4-pin** — Amazon `B01C19ENFK`, 100 pcs.

**Common anode is the one that works.** Anode to the 5 V rail, the three cathodes
to D26/D27/D29 with the GPIOs sinking, three resistors and nothing else. The
common-*cathode* version of the same product (`B01C19ENDM`) would have needed a
high-side switch per channel — a PNP, a base resistor and a pull-up each, twelve
parts instead of three — because a 3V3 GPIO cannot drive a high side off 5 V.
Worth knowing the two listings differ by four characters.

**Get the diffused version.** The same part is available diffused from
AliExpress at the same specification, and that is the one to buy — the
water-clear listings are a trap for this application.

The status scheme in [indicators.md](indicators.md) is built on *mixed* colours:
amber is red plus green, magenta is red plus blue. An RGB LED is three separate
dice under one lens. Diffused blends them into a single colour; **water-clear
shows three coloured dots**, so amber reads as a red dot beside a green dot,
which nobody recognises as a state across a stage. Diffusion is doing real work
here, not cosmetics.

**Confirmed common anode.** Specification from the vendor:

| | Value |
| --- | --- |
| Forward voltage @ 20 mA | **R 2.0–2.2 V, G 3.0–3.2 V, B 3.0–3.2 V** |
| Viewing angle | 30° clear lens, **20° matte** |
| Package | 5 mm, 4 pin |

Those numbers confirm why 3V3 drive was never going to work: green and blue want
3.0–3.2 V against a GPIO that manages about 3.15 V.

### Series resistors

Common anode on the 5.0 V rail, cathodes through resistors to the GPIOs, which
sink. Allowing ~0.35 V of output-low drop:

| Channel | Vf **at 20 mA** | Vf **at its own operating point** | R | Current |
| --- | --- | --- | --- | --- |
| Red | 2.0–2.2 V | ~1.99 V | **510 Ω** | **5.2 mA** |
| Green | 3.0–3.2 V | ~2.62 V | **300 Ω** | **6.8 mA** |
| Blue | 3.0–3.2 V | ~2.71 V | **300 Ω** | **6.4 mA** |

🔴 **The two Vf columns are the whole point, and the table used to have only the
first.** A forward voltage quoted at 20 mA is not the forward voltage at 5 or
7 mA, and these channels run at the latter. The middle column is measured,
2026-09-23, at the current each channel actually converges to. Because Vf and I
determine each other, getting this right means **iterating**, not substituting.

*(This table read 4.80-5.20 and 4.83-5.50 mA until 2026-09-23, computed from the
20 mA figures. It was low on green and blue by about 25%. `values.md` carried a
different set, 5.9/6.7/6.3, which was right on green and blue and high on red,
and right only because omitting the GPIO's 0.35 V sink drop cancelled the same
Vf error. Neither document was right about all three.)* See [`j12-rgb-led`](../discovery/findings/j12-rgb-led.yaml).

Note the red resistor is nearly double the other two for the *same* current —
that is the whole reason a common value fails.

**These are a starting point, not the answer.** Equal current does not give equal
perceived brightness: a green die is typically three to five times more luminous
per milliamp than red or blue, so at 5 mA each the mix will come out
green-dominant and amber will read as yellow-green. **Expect green's resistor to
rise substantially** — perhaps to 900 Ω–1 kΩ — before the mixes look right.

Tune by eye against the state table in [indicators.md](indicators.md), check
that amber and magenta are nameable rather than merely different, and **record
the values here** once they are settled.

At 5 mA per channel the worst case is 15 mA with all three lit, which is inside
both the per-pin and total sink limits and already inside the power budget.

**The 20° viewing angle is narrow** for a panel indicator. It wants to point at
the player rather than out of the front of the instrument, or to sit behind a
diffuser or light pipe that spreads it. Worth settling with the panel rather
than discovering on stage.

**Measure the forward voltages before choosing the series resistors.** ~390 Ω is
a placeholder based on typical figures; the real values come from this part at
the current you actually want. Red will differ from green and blue by around a
volt, so the three resistors will differ too — a common value is what broke the
original 3V3 scheme.

## The charge LED — J4

J4 takes a **red/green common-anode bicolour** with no board change: three
terminals onto pins 1–3, pin 4 unused. The state table and the reasoning are in
[indicators.md](indicators.md).

**Candidate:** Amazon `B01CFZMO3I`, listed as diffused —
<https://www.amazon.com/Diffused-Lighting-Electronics-Components-Emitting/dp/B01CFZMO3I>

> ✅ **MEASURED 2026-09-22, and it passes.** Green **2.322 V** at 2.7 mA, red
> **1.862 V**, **common anode**, **diffused**, and the green still lights at a
> 3.00 V supply drawing 0.77 mA. All four requirements below are met. The
> listing was never readable, so nothing here was ever quoted from the vendor;
> the only vendor figure that exists is the **bag label, 1.8 V red and
> 3.0–3.2 V green**, read 2026-09-23. See [`j4-charge-led`](../discovery/findings/j4-charge-led.yaml).

**The green die is the whole question**, because J4 hangs on `VOUT` — the cell,
about **4.2 V falling to 3.0 V**, not a regulated rail.

| Green chemistry | Vf | Verdict |
| --- | --- | --- |
| AlGaInP, yellowish-green | ~2.1 V | works across the whole range |
| InGaN, true green | 3.0–3.2 V | **dims, then dies as the cell drains** |

That is the identical failure that stopped the RGB being driven from 3V3, one
rail further down. **If this bicolour behaved like a high-Vf green it would be
the wrong part for J4**, however good it looked on the bench at full charge.

✅ **It does not, and that was settled by measuring the thing that matters.** At
a **3.00 V supply** through 990 Ω the green draws **0.77 mA** and lights, rather
than going dark. That is J4's circuit at the cell's end of life, measured
directly.

⚠️ **The die's chemistry is a separate question and it is NOT settled.** The bag
label reads 3.0–3.2 V green. A claim that the measured 2.322 V proved AlGaInP was
withdrawn on 2026-09-23: **a low-current forward voltage cannot tell the two
apart**, because an InGaN die's 10–30 Ω of series resistance dominates at 20 mA
and is invisible at 2 mA. It does not matter here. The table above is a guide to
what to *expect*, not a test you can run at 2 mA.

Before committing:

1. **Measure Vf on the green die**, or find it stated. Under ~2.4 V is safe;
   3.0 V and above is disqualifying.
2. **Confirm common anode**, not common cathode. The two RGB listings differ by
   four characters for exactly this, and the wrong one needs a high-side switch.
3. **Confirm diffused.** Amber here is red and green mixed in one lens; a
   water-clear part shows two coloured dots, which nobody reads as a state —
   the same argument that governs the RGB.
4. **Test it at 3.0 V, not 4.2 V.** A green that looks fine on a full cell is
   precisely the failure mode: it goes dark when the battery is low, which is
   when you most want to see the charger working.

Then trim R9 and R10 by eye. Red does swamp green: **measured, red draws 24%
more current than green through equal resistors**, on top of being the brighter
die per milliamp. R9 wants raising, around 1.2k to equalise current, further by
eye after that.

🔴 **The trim is not a single fixed adjustment.** The balance **moves with state
of charge**: green's higher Vf eats proportionally more of a shrinking headroom,
so the red-to-green current ratio goes from 1.25 on a full cell to 1.55 on a
flat one. **Trim at mid-cell, not on a freshly charged pack**, and note that
resistors can centre the balance but cannot stop it moving. See [`j4-charge-led`](../discovery/findings/j4-charge-led.yaml).

## Still to source

**Actives**

| Part | LCSC | Note |
| --- | --- | --- |
| BQ24074RGTR | **C54313** | QFN-16-EP 3×3, Economic assembly ✅ |
| TPS61023DRLR | **C919459** | SOT-563, Economic assembly ✅ |
| 1 µH inductor | **C354578** | CENKER CKCS4018-1uH/N — 4×4 mm shielded, 25 mΩ, 2 A RMS, **4.2 A Isat** |
| SS34 Schottky | **C8678** | MDD, SMA (DO-214AC), 40 V / 3 A, 550 mV @ 3 A. **JLC Basic** — no setup fee. |
| 74HC14 | **C5605** | Nexperia 74HC14D, SOIC-14. Hex Schmitt inverter — switch debounce. Stock KiCad symbol and footprint. |
| MCP6002 | **C116706** | Microchip MCP6002-I/SN, SOIC-8. Dual rail-to-rail, 1 MHz, 1.8 V min. **Audio-in gain stage, both halves fitted** (ADR 0009, ADR 0010). ~$0.16 |

The inductor is the only one with real selection content, so here is the working.
Worst case is a 350 mA load at a 3.0 V cell: 0.65 A of DC current and 1.2 A p-p
of ripple at 1 µH. Derating inductance 30% as the datasheet instructs pushes
ripple to 1.71 A p-p and the **peak to 1.51 A**. 4.2 A of saturation is nearly
three times that, and 2 A RMS against 0.65 A DC is equally comfortable.

**Passives — jellybean, and all in JLC's Basic library**

| Value | Qty | Where | Note |
| --- | --- | --- | --- |
| 10 kΩ 0.1% 0603 | 4 | A11 encoder | **C374544, already in stock** |
| 887 Ω **1%** 0603 | 1 | `RISET` | 1% is a datasheet requirement, not a preference |
| 1.2 kΩ 0603 | 1 | `RILIM` | |
| 348 kΩ **1%** 0603 | 1 | boost FB upper | it sets the output voltage |
| 47.5 kΩ **1%** 0603 | 1 | boost FB lower | |
| 100 kΩ 0603 | 1 | boost `EN` pulldown | |
| 10 kΩ 0603 | ~3 | TS fallback, general | C15401, already used on absonus |
| 1 kΩ 0603 | ~4 | A10/A11 filters, charge LEDs | |
| 100 Ω 0603 | 7 | J11 series | |
| 510 Ω 0603 | 1 | RGB red | see above |
| 300 Ω 0603 | 2 | RGB green, blue | **expect green to rise on tuning** |
| 100 nF 0603 | 8 | **J5 wiper filters** | not 10 nF — see [values.md](values.md) |
| 10 nF 0603 | 2 | A10, A11 filters | |
| 100 nF 0603 | ~6 | decoupling | |
| 10 µF 0805 | ~3 | boost input, charger | X5R/X7R, ≥10 V |
| 100 µF | 1 | boost output bulk | ≥10 V; C3337 is the absonus electrolytic |
| Ferrite bead | 1 | boost output → Seed VIN | rated **≥1 A** |

Two of those are deliberate picks rather than defaults. **The ferrite bead
carries the whole instrument's current** — a signal-grade bead saturates and its
impedance collapses exactly when it is needed. And the **100 µF output bulk sits
at the boost output**, so its ESR shows up in the ripple; a ceramic in parallel
with the electrolytic is the usual answer if measured ripple comes out high.

## The cell

**Protected 18650, 3400 mAh.** Every figure below is derived from the cell
actually bought rather than from the old 3000 mAh design basis; see
[values.md](values.md), re-derived 2026-08-23. ~18 × 65 mm bare, **~18 × 69 mm
protected** — the protection PCB adds length at the negative end, which is the
dimension that catches people fitting a holder.

| | |
| --- | --- |
| Charge current | 1 A = **0.29C**, gentle for any 18650 |
| Charge time | **~4.0 h** |
| Runtime | 12.3 h quiet, **7.3 h typical**, 5.2 h loud |
| Connector | none — the cell seats in BT1, which cannot be wired backwards |

**Protection is a requirement, not a preference** (P-7: over-charge,
over-discharge, over-current). A protected cell carries a small PCM under the
wrap at the negative end — a MOSFET pair that disconnects the cell on
over-discharge (~2.5–2.8 V), over-charge (~4.25–4.3 V) and over-current. A bare
cell needs a separate protection board.

**On this board the PCM is the only over-discharge protection there is.** The
bq24074 protects the cell while *charging* — it terminates properly and limits
current — but nothing here protects it while *discharging*. There is no
low-voltage cutoff; the boost keeps pulling until it browns out. Taking a
lithium-ion cell below ~2.5 V dissolves copper from the anode collector, which
can plate back as an internal short on the next charge. So P-7 is satisfied by
the cell, not by the board, and a bare cell in this holder is a genuine hazard
rather than a specification quibble.

That is also why the A10 gauge exists: when the PCM trips the instrument stops
dead with no warning, so "battery critical" must fire well above ~2.8 V.

**The PCM is not a thermistor.** The cell has **no** thermistor either way, so
the charger's `TS` pin gets a fixed 10 kΩ — it cannot float. Two different
protections, easily conflated.

### Which cell to buy

**Protected, button-top, ~69 mm.** Protected cells are essentially always
button-top; a flat-top bare cell may not seat or make contact.

**The cell is
[Orbtronic 3400 mAh protected](https://www.orbtronic.com/protected-3400mah-18650-li-ion-battery-panasonic-ncr18650B-orbtronic)**
— Panasonic NCR18650B inside, button top, **68.9 mm catalogue and 69.48 mm
measured with the shrinkwrap**.

> 🔴 **This sentence used to read "inside what the BH-18650-PC is cut for", and
> that was wrong.** MPD rates the holder for cells "65-68MM in length only", so
> neither figure is inside it. The claim was never checked against the holder's
> own rating, and it is what the cell purchase was made on. Corrected
> 2026-08-23; the full working is
> [`discovery/findings/bt1-cell-fit.yaml`](../discovery/findings/bt1-cell-fit.yaml).
>
> **The cell does fit.** MPD's STEP model settles it: the contacts sit 61.504 mm
> apart at rest with 5.888 mm of travel each, and the housing wall stops a cell
> at 70.900 mm. A 69.48 mm cell clears the wall by 0.710 mm a side and deflects
> each contact 3.988 mm, against 3.248 mm at the 68 mm rating. So the rating is
> about **contact stress, not interference**: it seats, while over-deflecting the
> contacts by about 23%. The residual risk is a contact taking a permanent set
> and then gripping a shorter cell poorly. For a cell fitted once, mild.

| | Spec | |
| --- | --- | --- |
| Capacity | 3400 mAh, 12.2 Wh | design basis is 3000, so runtimes above are a **floor** |
| Length | **68.9 mm ±0.03** catalogue, **69.48 mm measured** | the catalogue figure excludes the shrinkwrap; both exceed the holder's 65-68 mm rating, see above |
| Diameter | 18.6 mm ±0.03 | wider than a bare cell's ~18.4; the holder is cut for protected |
| Weight | 46 g | |
| Nominal | 3.6–3.7 V, charge to 4.2 V | matches what the bq24074 delivers |
| Max continuous | **2C = 6.8 A** | board's worst case is ~1.5 A — 4.5× margin |
| Pulse, 2–4 s | 10 A | |
| Core cell | Panasonic NCR18650B, UL MH12210 | |
| Protection ICs | Seiko-Ablic, Japan, welded external PCB | |

**Every protection threshold clears the board by a wide margin**, which is the
result you want — the PCM is a backstop that should never fire in normal use:

| PCM trips at | Board does | Margin |
| --- | --- | --- |
| Over-charge **4.33 V** | bq24074 terminates at **4.2 V** | 130 mV |
| Over-discharge **2.5 V** | runtime figures stop at **3.0 V** | 500 mV |
| Over-current **10–12 A** | ~1.5 A peak at low charge | ~7× |

Also over-temperature and dual (internal + external) short-circuit protection.

**The over-temp protection is inside the cell's PCM and is not a thermistor
output.** `TS` still gets a fixed 10 kΩ — the charger has no way to see it. Easy
to misread as changing that.

**Charge rate** is 1 A = 0.29C on 3400 mAh, gentler than the 0.33C the values
were originally derived at and now restated to. The vendor warns never to charge above 4.25 V; the bq24074 is a
4.2 V CC/CV part, so it is exactly the charger they ask for.

**Buy two.** Cells are priced and sold individually. The socketed holder was
chosen over a soldered pack precisely so a spare lives in the bag instead of the
instrument dying — and buying a pair includes a plastic carry case, which is not
a nicety. **A loose 18650 in a gig bag is a short-circuit hazard**: the positive
button and the can are both exposed, and a key or a jack plug across them will
dump 6.8 A into a dead short. Carry the spare in the case.

Equivalents if Orbtronic is out of stock — all protected, button-top, ~69 mm:

- [Liion Wholesale, same NCR18650B cell](https://liionwholesale.com/products/protected-panasonic-sanyo-ncr18650b-3400mah-5a-li-ion-18650-button-top-battery-wholesale-discount) — 5 A rated
- [Nitecore NL1834](https://18650battery.com/products/nitecore-nl1834-18650-3400mah-battery-protected-button-top) — 6 A

**Ignore anything claiming more than ~3600 mAh.** A genuine 18650 tops out around
3500; higher numbers are fake wraps around smaller cells.

**The holder is on the board**, soldered, rather than a pack tacked into the
enclosure. That removes the last hand-crimped power loom and with it the
reverse-polarity risk that had no protection behind it — a soldered holder cannot
be wired backwards. The cell stays replaceable, which for a gigging instrument
means a spare in the bag instead of a dead instrument.

**There is no remote-pack option.** J2 was removed at layout: nothing on the
platform wanted it, and it was the last route by which a reversed cell could
reach an unprotected charger input.

### The holder — settled

**BT1 = MPD `BH-18650-PC`, `C5339083`**, footprint
`Battery:BatteryHolder_MPD_BH-18650-PC` (stock KiCad, pads verified against the
drawing: 72.90 mm terminals, 55.61 mm mounting holes).

**It is rated for protected cells**, stated on the drawing rather than inferred:
*"This battery holder is designed for use with protected 18650 batteries
(PCB)."* That was the open question — protected cells run ~69 mm where most
holders are cut for 65 mm unprotected, because the protection board adds length
at the negative end.

| | |
| --- | --- |
| Body | 77.7 × 20.9 mm, **21.31 mm tall** |
| Material | self-extinguishing thermoplastic polyester, UL94V-0, −40…+180 °C |
| Assembly | **Economic and Standard** — same tier as the charger and boost |
| Mounting | Ø3.2 mm holes; the drawing says 2-56 screws, eyelets or adhesive |

**Bolt it down as well as soldering it.** The two solder tabs are not a
mechanical mount for a 46 g cell in something that gets carried to gigs.

**Second source, pin-identical:** MPD `BK-18650-PC2` — same 72.90/55.61 layout,
also rated for protected cells, and it carries vibration and 150 G shock test
results the BH does not ("no dislodgement of the cell"). Polypropylene rather
than polyester, so a narrower temperature range. Either drops into the same
footprint.

**Rejected:** Keystone 1042. Its courtyard is 87.9 mm against the MPD's 79.2 mm
— on a 90 mm edge that leaves about a millimetre a side — and its protected-cell
fit is unverified.

**Firmware should warn before the PCM acts.** A protected cell cuts off around
2.5–2.8 V, at which point the instrument simply stops. The A10 gauge exists so
"battery critical" fires well above that — the amber and red states in
[indicators.md](indicators.md) are what turns a dead stop into a warning.

**Alternative if an enclosure is ever thin:** a flat LiPo pouch — a 605080 is
6 × 50 × 80 mm for about 3000 mAh against the 18650's 18 mm diameter. Not
replaceable, and it needs mechanical protection from puncture, so it is the
choice only when thickness actually binds. It does not here: a telephone is
chunky, and absonus already lives with 18 mm.
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

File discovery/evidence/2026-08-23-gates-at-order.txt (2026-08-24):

$ kicad-cli pcb drc --schematic-parity
Found 0 violations
Found 0 unconnected items
Found 0 schematic parity issues
** Drc report for caryatid.kicad_pcb **
** Created on 2026-08-23T18:35:30-0700 **

** Found 0 DRC violations **

** Found 0 unconnected pads **

** Found 0 Footprint errors **

** End of Report **
Saved DRC Report to /dev/stdout

$ python3 tools/check_board.py
board 150.0 x 90.0 mm   135 front / 0 back   standoff 2.0 mm

  all twelve checks pass

$ python3 tools/fab_package.py
  BOM 42 lines / 127 parts to place (DNP excluded)
  CPL 127 placements
  LCSC: 127 of 127 parts covered, 0 without a part number

  1 part(s) pulled from the assembly order -- YOU buy and solder these:
    BT1    18650 protected         Digi-Key 3029216
  -> self-fit.csv. They are NOT DNP: the board is not complete until they are fitted.

  2 accessory line(s) on NO bill of materials -- YOU buy these too:
    cell-18650     1/board   Orbtronic, direct
    jumper-shunt   6/board   Digi-Key S9001-ND
  -> accessories.csv. A BOM cannot see these: they are not soldered to the board, so nothing places them and nothing misses them either.

  ready

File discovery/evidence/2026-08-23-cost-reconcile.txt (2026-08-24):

  42 codes, fetching live prices ...
Traceback (most recent call last):
  File "/Users/matt/Documents/GitHub/personal/caryatid/tools/cost_estimate.py", line 198, in <module>
    sys.exit(main())
             ^^^^^^
  File "/Users/matt/Documents/GitHub/personal/caryatid/tools/cost_estimate.py", line 132, in main
    info[c] = fetch(c); time.sleep(0.22)
              ^^^^^^^^
  File "/Users/matt/Documents/GitHub/personal/caryatid/tools/cost_estimate.py", line 88, in fetch
    return json.loads(r.stdout).get("data") or {}
           ^^^^^^^^^^^^^^^^^^^^
  File "/Users/matt/miniconda3/lib/python3.12/json/__init__.py", line 346, in loads
    return _default_decoder.decode(s)
           ^^^^^^^^^^^^^^^^^^^^^^^^^^
  File "/Users/matt/miniconda3/lib/python3.12/json/decoder.py", line 337, in decode
    obj, end = self.raw_decode(s, idx=_w(s, 0).end())
               ^^^^^^^^^^^^^^^^^^^^^^^^^^^^^^^^^^^^^^
  File "/Users/matt/miniconda3/lib/python3.12/json/decoder.py", line 355, in raw_decode
    raise JSONDecodeError("Expecting value", s, err.value) from None
json.decoder.JSONDecodeError: Expecting value: line 1 column 1 (char 0)

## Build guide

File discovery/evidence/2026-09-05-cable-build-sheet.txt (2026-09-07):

###########################################################################
# SUPERSEDED 2026-09-06. This was a hand-written sheet, and hand-written
# sheets drifted from the runbook every time it changed. Sheets are now
# GENERATED: docs/bringup.md is the single reference and
# tools/gen_bringup_sheet.py emits a dated blank from it.
#
# Kept, not deleted: it was never filled in, so nothing is lost, and the
# reasoning it carries was folded into the runbook rather than discarded.
###########################################################################

caryatid cable build sheet
==========================

  Written 2026-09-05. Pin assignments transcribed from docs/power-sheet.md,
  docs/panel-io-sheet.md and docs/connectors.md.

  🔴 THE BOARD SILKSCREENS ALL 77 CONNECTOR PINS. This sheet is for planning
  and ordering. AT THE BENCH, READ THE BOARD, not this sheet.

===========================================================================
THREE CHECKS BEFORE ANY CRIMPING. All three cost a part if wrong.
===========================================================================

CHECK 1: THE SWITCH LAMP MUST LIMIT ITS OWN CURRENT
---------------------------------------------------
  ### PASSED 2026-09-06. Switch is 12 mm, LATCHING, 4 pins: two labelled +/-
  ### for the ring LED, two unlabelled contacts reading 0.9 ohm latched in and
  ### open when out, which is the normally-open sense J3 needs. Lamp marked
  ### 3-6V and run at 5 V without damage. See discovery/findings/
  ### panel-latch-switch.yaml. The original reasoning is kept below.

  J3.3 feeds the lamp from +5V through R5, and R5 IS A 0 OHM LINK. There is no
  current limiting on the board, by design: indicators.md specifies a 3-9 V
  rated lamp whose limiting is internal.

  🔴 IF YOUR SWITCH HAS A BARE LED IN IT, connecting it to J3.3/J3.4 puts 5 V
     across a diode with no resistor. The LED dies.

  HOW TO CHECK, before wiring:
    - the switch's own spec: a lamp rated as a VOLTAGE RANGE (3-9 V, 6-12 V,
      12 V) is internally limited. One rated as a bare LED, or given a forward
      voltage and current, is not.
    - meter on diode test across the lamp terminals: an internally limited lamp
      usually reads open or a high resistance, not a plain diode drop.
    - if in doubt, series a resistor into J3.3 externally for the first test and
      measure the current. indicators.md wants that reading anyway: it is the
      only entry still marked UNKNOWN in the 5 V budget in values.md.

  IF IT IS A BARE LED, that is not a disaster. R5's 0603 footprint exists
  exactly so a different value can be dropped in. But find out BEFORE the
  first power-up, not after.

CHECK 2: THE CHARGE LED MUST BE COMMON ANODE, AND THE GREEN DIE MATTERS
------------------------------------------------------------------------
  J4.1 is VOUT and is the COMMON ANODE for both LEDs. Cathodes sink through
  R9/R10 into the charger's open-drain outputs.

  🔴 COMMON CATHODE WILL NOT WORK. Nothing on the board can be changed to make
     it work.

  🔴 AND THE GREEN DIE DECIDES WHETHER IT KEEPS WORKING. J4 runs from VOUT,
     which is the CELL, roughly 4.2 V falling to ~3.0 V in use. Not a
     regulated rail.

       AlGaInP yellowish-green, Vf ~2.1 V   fine across the whole range
       InGaN TRUE green,        Vf 3.0-3.2  DIMS AND GOES DARK as the cell
                                            drains, and NO RESISTOR VALUE
                                            FIXES IT

     This is the same physics that stops the RGB being driven from 3V3. A
     "nicer" bright green LED is the wrong part here, and it will look fine on
     a full cell and fail late in a set.

  BEST PART: a red/green COMMON-ANODE BICOLOUR, three terminals, landing on
  J4 pins 1-3 with pin 4 unused. It gives amber while charging and green when
  done, out of one lens, read without a legend.

     /CHG    /PGOOD   colour   meaning
     ------  -------  -------  --------------------------------
     high-Z  high-Z   off      on battery, no charger
     low     low      amber    charging
     high-Z  low      green    external power, charge complete
     low     high-Z   red      anomalous, should not occur

CHECK 3: THE RGB MUST BE COMMON ANODE
-------------------------------------
  J12.1 is +5V and is the common anode. D26/D27/D29 SINK through 510R red,
  300R green, 300R blue. Writing the GPIO LOW lights the channel.

  🔴 COMMON CATHODE WILL NOT WORK.
  🔴 AND IT CANNOT BE RUN FROM 3V3. Green and blue have forward voltages around
     3.0-3.1 V against an output-high of about 3.15 V. They will not light and
     no resistor value fixes it. That is why the anode is on 5 V.

  HOW TO CHECK: diode test from the common pin to each of the other three. A
  common ANODE conducts with the RED probe on the common pin. A common CATHODE
  conducts with the BLACK probe on it.

===========================================================================
WIRE COLOUR CONVENTION. Set it once, before the first cable.
===========================================================================

  PROPOSED 2026-09-05, not yet agreed. Matt has pre-crimped pigtails AND a
  crimp tool, so colours are a CHOICE here rather than something inherited.

  WHY IT IS WORTH FIVE MINUTES: the loa keypad harness taught that colours on a
  BOUGHT cable mean nothing and are ephemeral, so the durable map had to be by
  header position. On a cable you make yourself the opposite is available:
  colour can carry meaning, and then the cable documents itself at the panel
  where no document will be.

    J1    1 +VE            RED      2 GND            BLACK
    J3    1 VOUT           RED      2 EN_SW          YELLOW
          3 lamp anode     ORANGE   4 lamp cathode   BLACK
    J4    1 VOUT anode     WHITE    2 /CHG cathode   RED
          3 /PGOOD cathode GREEN    4 GND            BLACK
    J12   1 +5V anode      WHITE    2 red cathode    RED
          3 green cathode  GREEN    4 blue cathode   BLUE
    J17   1 L              WHITE    2 R              RED     3 GND   BLACK
    J18   1 L              WHITE    2 R              RED     3 MIC_RTN  GREEN

  TWO DELIBERATE DEPARTURES FROM "RED IS POSITIVE":

  1. ON THE LED CABLES THE COMMON ANODE IS WHITE, NOT RED, so that the CATHODE
     COLOURS CAN MATCH THE DIES. At a panel, a red wire going to the red die is
     worth more than a red wire meaning "supply", because the supply pin is the
     one you can always identify anyway: it is the odd one out.

  2. 🔴 J18 PIN 3 IS GREEN AND MUST NEVER BE BLACK. MIC_RTN IS NOT A GROUND.
     connectors.md already had to correct this exact error in its own table,
     where J18 pin 3 was listed as GND. A black wire there re-creates the
     mistake in copper, and invites the next person to tie it to the nearest
     ground point by reflex. It is the whole reason J14 exists.

  NOT YET PROMOTED TO A DOC. If this convention is wanted platform-wide it
  belongs in docs/ or an ADR rather than in a dated bench file. Say so and it
  moves.

===========================================================================
CRIMPING AND VERIFYING
===========================================================================

  RE-PIN RATHER THAN RE-MAKE. JST-XH contacts have a small retention lance. A
  fine pick or a jeweller's screwdriver against it releases the contact from
  the housing, so a pigtail that arrived in the wrong order is re-ordered in a
  minute instead of cut off and redone.

  🔴 BEEP OUT EVERY CABLE BEFORE IT IS PLUGGED IN. Continuity from each far-end
  conductor to the housing position it is supposed to occupy. Every cable,
  every time, including bought pigtails.

  This is not caution for its own sake. A mis-pinned J1 lead puts the supply
  somewhere it does not belong, on a board that has never been powered, at the
  exact moment you are trying to establish whether the board is sound. The
  whole value of Stage 1 is destroyed by an unverified power cable.

  LABEL EACH CABLE at the connector end with its J number. Five 4-way JST-XH
  cables are indistinguishable in a drawer, and J3, J4 and J12 are all 4-way
  with completely different jobs.

===========================================================================
THE CABLES, IN THE ORDER THE RUNBOOK NEEDS THEM
===========================================================================

  Housings are JST-XH at 2.50 mm unless noted.

#1  J1 POWER IN            2-way        NEEDED AT STAGE 2
    ------------------------------------------------------
    J1.1  positive, D1 anode, the barrel jack's CENTRE pin
    J1.2  GND, the sleeve
    Other end: the 5.5 x 2.1 panel jack. Sacrifice one of the eight.
    Measure the supply's polarity UNLOADED before this lead is ever plugged in.

#2  J3 BOOST ENABLE LINK   2 wires      NEEDED AT STAGE 3
    ------------------------------------------------------
    🔴 MAKE A BARE LINK FIRST, NOT THE FULL SWITCH CABLE.
    Just J3.1 to J3.2, nothing else connected.

    WHY: Stage 2 needs the 5 V rail DEAD to pass, and Stage 3 needs it live.
    A bare link makes that a deliberate act. And it keeps the lamp, which is
    Check 1's open question, out of the boost test entirely. Do not introduce
    two unknowns at once.

#3  J3 LATCH SWITCH        4-way        CHECK 1 PASSED, build it
    ------------------------------------------------------
    J3.1  VOUT          RED      -> either UNLABELLED pin
    J3.2  EN_SW         YELLOW   -> the other UNLABELLED pin
    J3.3  +5V via R5    ORANGE   -> the pin labelled +
    J3.4  GND           BLACK    -> the pin labelled -

    The two switch pins are interchangeable: a plain SPST has no polarity. The
    lamp pins are not.

    THE SWITCH CARRIES MICROAMPS, NOT AMPS. It asserts the boost's enable
    against R6's 100 kohm pulldown, about 42 uA at a 4.2 V cell. The boost does
    the power switching on the board. So its 3 A rating is overkill and the
    0.9 ohm contact resistance cannot matter. Do not run fat wire to it.

#4  J4 CHARGE LED          4-way        NEEDED AT STAGE 4
    ------------------------------------------------------
    J4.1  VOUT   common anode, both dies
    J4.2  R9  1k -> /CHG     red cathode
    J4.3  R10 1k -> /PGOOD   green cathode
    J4.4  GND    unused with a bicolour
    No resistor in the cable. R9 and R10 are on the board.

#5  J12 RGB STATUS         4-way        Stage 8g
    ------------------------------------------------------
    J12.1  +5V           common anode
    J12.2  red cathode   through 510R to D26
    J12.3  green cathode through 300R to D27
    J12.4  blue cathode  through 300R to D29
    No resistors in the cable.

#6  J14 MIC RETURN LINK    2-way        Stage 8h, BEFORE any mic test
    ------------------------------------------------------
    A SHORTING LINK. MIC_RTN is not grounded on the board and J14 ships open.
    Without this the capsule has no return path and reads nothing, which looks
    exactly like a dead U4.
    For loa this is permanent: the electret draws 3 mA for the pair, which is
    not worth gating with the hook switch's second pole.

#7  J18 AUDIO IN / MIC     3-way        Stage 8h
    ------------------------------------------------------
    J18.1  LEFT input
    J18.2  RIGHT input
    J18.3  MIC_RTN         NOT ground
    Electret: RED to pin 1 or 2, BLACK to pin 3.
    Jumpers for electret left: JP1, JP2, JP3 all on 1-2. Right: JP4, JP5, JP6.

#8  J17 AUDIO OUT          3-way        Stage 8h
    ------------------------------------------------------
    L, R, GND, out to panel jacks.

#9  J8 HOOK SWITCH         2-way        loa build
    ------------------------------------------------------
    To the hook switch's COMMON and NC, so on-hook is OPEN and a broken lead
    reads as on-hook and silent. See loa-hook-switch: the switch has six
    terminals and the contacts are not yet identified.

#10 J11 KEYPAD             IDC 2x5      loa build
    ------------------------------------------------------
    To a JST ZH 7-way at the keypad end. Rows straight through to D0-D3.
    🔴 CROSS HEADER POSITIONS 5 AND 7, LEAVE 6, or reverse the column index in
    firmware. Reversing three things is swapping the outer two. Doing neither
    shows up as key 1 reading as key 3. See loa-keypad-matrix.

    STILL FOR FULL PLATFORM COVERAGE: J5 (IDC 2x5, analogue bus), J6, J7
    (2-way switches), J9 (3-way soft pot), J10 (2-way FSR), J13 (JST-SH 4,
    buy a Qwiic lead rather than crimping 1.0 mm by hand), J15 and J19 (6-way),
    J16 (2x4 header).

===========================================================================
NOTES
===========================================================================

  Nothing here is verified against parts in hand. The three checks above are
  the verification, and none has been done.

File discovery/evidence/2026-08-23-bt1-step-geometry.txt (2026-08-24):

BT1 fit, derived from MPD's STEP model
source: /Users/matt/Documents/GitHub/personal/loa/local/reference/BH-18650-PC.STEP
SolidWorks 2016, AP214, dated 2019-11-12; three named solids

solid                   X min    X max   X span  Z span
Positive Contact       30.752   36.640    5.888   6.050
Negative Contact      -36.640  -30.752    5.888   6.050
Housing               -38.850   38.850   77.700  20.900

contact face at rest   30.752 mm from centre -> 61.504 mm apart
contact root           36.640 mm -> 5.888 mm of travel each
housing inner wall     35.450 mm -> 70.900 mm hard stop on cell length

MPD rates the holder for cells 65-68 mm. Matt measured a cell at 69.48 mm.

  cell mm   deflection each   contact left
    65.00             1.748          4.140
    68.00             3.248          2.640
    69.48             3.988          1.900
    70.90             4.698          1.190

CONCLUSION: the cell seats, clearing the housing wall by 0.710 mm a side,
while deflecting each contact 0.740 mm past the 68 mm rating. The rating is
about contact stress, not interference.

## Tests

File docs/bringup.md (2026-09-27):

# Bring-up runbook

**How to prove a fabricated caryatid board works, from the antistatic bag to a
Daisy Seed running `panel_readout`.**

First batch: five boards, JLCPCB order of 2026-08-23, ENIG, Economic assembly
top side, arrived 2026-09-01. Nothing in this repository has ever been powered.
**Every number below is predicted from the schematic and the design documents,
and none of it has been seen on hardware.** That is what running this is for.

> **A platform artifact, not a loa document.** Four more boards and every future
> batch use it. Keep instrument-specific steps out.

## How to use this

**This file is the reference and is never filled in.** Readings go on a dated
sheet generated from it:

```sh
python3 tools/gen_bringup_sheet.py            # writes today's blank sheet
python3 tools/gen_bringup_sheet.py --phase B  # just one phase
```

The sheet lands in `discovery/evidence/` with a dated filename. **Revise this
file, regenerate the sheet.** That is the whole reason the sheet is generated
rather than hand-written: the two used to drift apart every time the runbook
changed, and they did.

Each phase declares a **scope** line, which the generator reads to decide
whether a step gets one column or five.

---

# Phase A: Preparation

> **Scope:** bench

Nothing here touches a board.

## A1. The five rules

1. **Never power a rail you have not proved is not shorted.** Phase B exists
   entirely for this, and it is the phase with no glamour and the highest value.
2. **Every pass criterion is a number.** "Looks right" is not a result. A step
   that does not say what to expect is not finished being written; say so rather
   than inventing a threshold at the bench.
3. **Record as you go, per board.** A runbook with no record is a runbook you
   run twice.
4. **Stop at the first red gate.** Do not press on to see whether the next thing
   also fails. The failure modes here are cumulative: a shorted rail that
   survives one phase destroys a part in the next.
5. **One board all the way before the other four.** You are proving the runbook
   as much as the hardware, and debugging five boards at once is debugging none.

## A2. Instruments, and what they cannot reach

Recorded in [`bench-instruments`](../discovery/findings/bench-instruments.yaml),
which is what every reading in this project should be traceable to.

| instrument | |
| --- | --- |
| **Fluke 101** | DC volts, resistance, diode, continuity. 🔴 **No current ranges at all.** Excellent at millivolts: 0.1 mV on the 600 mV range |
| **Jesverty 0-30 V 0-5 A** | Selectable CC/OCP, encoder with coarse and fine. Arrived 2026-09-06 |
| **10 Ω and 0.1 Ω shunts** | 1 W or better. How current gets measured |

**What no amount of care reaches, with this kit:**

| out of reach | consequence |
| --- | --- |
| Boost switching node and ripple | U2 could run badly and still read 5.0 V DC |
| Inrush and start-up transient | A marginal soft-start shows only as an occasional failure to come up |
| RC debounce timing on the 74HC14 | ADR 0007's 24 ms stays unverified; firmware may need tuning |
| Audio noise floor and THD | You will know audio *works*, not how well |
| I2C and SPI signal integrity | Works or does not; no margin measurement |

**Record these as untested, never as passed.** A record that omits them reads as
though they were checked.

## A3. Measuring current with no ammeter

Current is either read off the supply or derived from a **shunt voltage**: a
known resistor in series, millivolts across it, Ohm's law.

**The supply reads amps well and milliamps badly**, and the work divides on that:

| current | how | why |
| --- | --- | --- |
| **around 1 A**, charge and input | **the supply's display** | well inside its accuracy on a 5 A range, and nothing goes in series |
| **tens of mA**, lamp and quiescent | **10 Ω shunt, Fluke on DC mV** | a 5 A supply's error at 15 mA is comparable to the quantity itself. The Fluke reads 150 mV at 0.1 mV resolution, which is not close |

| shunt | at the expected current | conversion |
| --- | --- | --- |
| **10 Ω** | 15 mA gives 150 mV | `mA = mV ÷ 10` |
| **0.1 Ω** | 1.0 A gives 100 mV | `mA = mV × 10` |

Current flows **through** the shunt. The meter sits **across** it and carries
almost none. That reads oddly the first time, because the instinct with an
ammeter is to break the circuit and insert it; here you insert a resistor and
watch it from the side.

```mermaid
flowchart LR
    PSU["Bench supply<br/>5.00 V, CC<br/>limit 100 mA"]
    A(("A"))
    RS["R shunt<br/>10 ohm, 1 W"]
    B(("B"))
    LOAD["Load under test<br/>e.g. switch lamp<br/>J3.3 + to J3.4 -"]
    DMM["Fluke 101<br/>DC millivolts<br/>reads V across A-B"]
    CALC["mA = mV / 10<br/>with the 10 ohm"]

    PSU -->|"+"| A
    A --> RS
    RS --> B
    B --> LOAD
    LOAD -->|"back to -"| PSU

    A -.->|"probe"| DMM
    B -.->|"probe"| DMM
    DMM -.-> CALC

    classDef meter fill:#fff4e5,stroke:#e8710a,stroke-width:2px
    classDef sense fill:#e8f0fe,stroke:#1a73e8,stroke-width:2px
    class DMM,CALC meter
    class RS sense
```

🔴 **Do not put the Fluke where the shunt is.** With no current ranges it is an
open circuit on volts, not a reading. The resistor does the work; the meter
only watches it.

🔴 **Add the shunt drop back into the setpoint.** The load does not see the
voltage you dialled in, it sees that minus the drop across the shunt, and at
tens of milliamps through 10 Ω that is hundreds of millivolts. The switch lamp
measurement found this the hard way on 2026-09-20: a 5.00 V setpoint put 4.74 V
on the lamp and read **11% low**. Either set the supply to `V_wanted + drop` and
re-read (one iteration converges), or record the voltage the load actually saw.
**Never quote the setpoint as the load voltage.**

**Why 0.1 Ω for the big one and not something easier to read.** It sits in the
input path and its drop comes out of the charger's headroom, which is only 150
to 250 mV. At 1.05 A a 0.1 Ω drops 105 mV and leaves J1 near 4.90 V, above the
4.75 V floor. A 1 Ω would drop a volt, stop the charger, and give you a careful
measurement of a charger that is not charging.

## A4. The supply, and why 5 V

**Set 5.00 V and leave it there for the whole runbook.**

The stated 5 to 9 V input range is what the part tolerates, not a set of equally
good choices. **The bq24074 is a linear charger**: it burns the difference
between input and cell in its own package.

| supply | at the IC | cell 3.0 V | cell 3.7 V | cell 4.2 V |
| --- | --- | --- | --- | --- |
| **5.0 V** | 4.60 V | 1.60 W | **0.90 W** | 0.40 W |
| 9.0 V | 8.60 V | 5.60 W | **4.90 W** | 4.40 W |

A QFN-16-EP on 2-layer FR4 has roughly 1.2 W of budget. 5 V sits inside it and
charges at the full 1 A; 9 V is four times over, and the part protects itself by
folding the charge current back. Nothing is damaged, but you get a hot charger
and most of a day to fill a cell. Derivation and the caveat on the estimated θJA
are in
[`charger-input-voltage-thermal`](../discovery/findings/charger-input-voltage-thermal.yaml).

With no cell fitted there is no charge current and therefore no heat, so Phases
B and C are indifferent to it. Leaving the supply at 5.00 V throughout is simply
one less thing to remember at C3.

**The service supply is a different thing and stays.** A 5 V 3 A wall adapter and
a 5.5 × 2.1 mm panel jack are what the *instrument* runs from through J1. The
bench supply replaces them only for bring-up.

## A5. Rigs to build

**One thing is worth building, and it serves two connectors.**

| # | Build | Pass |
| --- | --- | --- |
| A5.1 | **Bus breakout.** IDC 2×5 ribbon, 2×5 socket one end, 10-pin 0.1 inch header the other, pressed into a breadboard | seats in the breadboard, all 10 conductors beep through |
| A5.2 | **Analogue injector.** 10 kΩ pot on the breadboard, ends to `3V3A` and `AGND` from the breakout, wiper on a flying lead | pot sweeps 0 V to 3V3 measured at the wiper |
| A5.3 | **Ground stick.** A jumper from breadboard GND, for pulling digital lines down one at a time | beeps to GND |
| A5.4 | **Loopback wires.** One short jumper each for UART and SPI | beep through |

**J5 and J11 are both IDC 2×5, so one breakout serves both.** The pinouts differ
completely; the adapter does not care and you read the pins differently. This is
the single highest-value rig and it is reusable for absonus and baby borg.

**A pot rather than fixed dividers**, because sweeping it catches a stuck or
noisy ADC that three static points would pass.

**Two connectors test themselves and need no hardware.** A loopback costs one
wire and exercises the whole path:

- **UART** on J19 (`D11`/`D12`) and J15 (`D13`/`D14`): TX to RX, firmware sends
  and expects to receive.
- **SPI** on J16: MOSI (`D10`) to MISO (`D9`), firmware writes and reads back.

**Bought, not built:** a common-anode RGB LED for J12, headphones or a powered
speaker for J17, the electret for J18, and optionally a Qwiic device for J13,
which is the only honest test of it as real I2C.

## A6. Cables to build

Pin assignments from [power-sheet.md](power-sheet.md),
[panel-io-sheet.md](panel-io-sheet.md) and [connectors.md](connectors.md).
🔴 **The board silkscreens all 77 connector pins. At the bench, read the board.**

### Wire colour convention

Colours on a *bought* harness mean nothing, which is why the loa keypad map had
to be by header position. On a cable you make, the opposite is available: colour
carries meaning and the cable documents itself at the panel.

| | 1 | 2 | 3 | 4 |
| --- | --- | --- | --- | --- |
| **J1** | +ve **red** | GND **black** | | |
| **J3** | VOUT **red** | EN_SW **yellow** | lamp anode **orange** | lamp cathode **black** |
| **J4** | anode **white** | /CHG **red** | /PGOOD **green** | GND **black** |
| **J12** | +5V **white** | red **red** | green **green** | blue **blue** |
| **J17** | L **white** | R **red** | GND **black** | |
| **J18** | L **white** | R **red** | MIC_RTN **green** | |

Two deliberate departures from red-is-positive:

**The LED cables put the common anode on white**, so the cathode colours can
match the dies. At a panel, a red wire going to the red die is worth more than a
red wire meaning "supply", because the supply pin is the one you can always
identify anyway: it is the odd one out.

🔴 **J18 pin 3 is green and must never be black.** `MIC_RTN` is not a ground.
`connectors.md` already had to correct this exact error in its own table. A
black wire there re-creates the mistake in copper and invites the next person to
tie it to the nearest ground by reflex. It is the whole reason J14 exists.

### The cables

| # | Cable | Wiring | Needed by |
| --- | --- | --- | --- |
| A6.1 | **J1 power in**, 2-way | 1 positive to supply +, 2 GND | **C1** |
| A6.2 | **J3 bare link**, 2 wires | J3.1 to J3.2 only, nothing else | **C2** |
| A6.3 | **J3 latch switch**, 4-way | 1,2 to the unlabelled pins; 3 to `+`, 4 to `-` | panel |
| A6.4 | **J4 charge LED**, 4-way | 1 anode, 2 /CHG cathode, 3 /PGOOD cathode | **C4** |
| A6.5 | **J12 RGB**, 4-way | 1 anode +5V, 2 red, 3 green, 4 blue cathodes | E7 |
| A6.6 | **J14 shorting link**, 2-way | pins bridged | **E8, before any mic test** |
| A6.7 | **J18 mic**, 3-way | **bench electret**: red to pin 1 or 2, black to pin 3. 🔴 **loa's handset is NOT wired by these colours**, see below | E8 |
| A6.8 | **J17 audio out**, 3-way | L, R, GND to jacks or headphones | E8 |
| A6.9 | **J8 hook switch**, 2-way | to the hook switch COM and NC | loa build |
| A6.10 | **J11 keypad**, IDC 2×5 | to JST ZH 7-way. 🔴 **cross positions 5 and 7** | loa build |

**Make A6.2 before A6.3.** Phase C1 passes on the 5 V rail being *dead* and C2
needs it live, so a bare link makes that a deliberate act and keeps the lamp out
of the boost test. Two unknowns at once is how a bench evening disappears.

**No resistors go in any cable.** R5, R9, R10 and the RGB's 510/300/300 are all
on the board.

### Crimping and verifying

**Re-pin rather than re-make.** JST-XH contacts have a small retention lance; a
fine pick releases the contact, so a pigtail in the wrong order is fixed in a
minute rather than cut off.

🔴 **The handset and the bench electret use different colours, and the handset's
red lead is the EARPIECE.** Wiring loa's handset by A6.7's "red to pin 1 or 2"
puts the receiver into the mic input and leaves the microphone unconnected.

| | mic + (J18 pin 1 or 2) | mic return (J18 pin 3) | not the mic |
| --- | --- | --- | --- |
| **bench electret** | red | black | n/a |
| **loa's handset, at the RJ9** | **yellow** | **black** | red and green are the receiver |

Measured 2026-09-22: the outer pair is the transmitter and **yellow is
positive**, established by biasing it, not by convention. Backwards gives a
silent microphone. See
[`loa-handset-capsule`](../discovery/findings/loa-handset-capsule.yaml).

🔴 **Beep out every cable before it is plugged in.** Every cable, every time,
bought pigtails included. A mis-pinned J1 lead puts the supply somewhere it does
not belong, on a board that has never been powered, at the exact moment you are
establishing whether the board is sound. An unverified power cable destroys the
whole value of Phase B.

**Label each cable with its J number.** J3, J4 and J12 are all 4-way JST-XH with
completely different jobs and are indistinguishable in a drawer.

## A7. Component checks, before they reach a panel

Each of these costs a part if it is wrong, and none is recoverable after.

| # | Check | Pass |
| --- | --- | --- |
| A7.1 | **Switch lamp limits its own current.** J3.3 feeds +5V through R5, and R5 is a **0 Ω link** | a lamp rated as a *voltage range* is internally limited. ✅ **PASSED**: 12 mm latching, marked 3-6 V, 4 pins, contacts 0.9 Ω latched and open out, ran at 5 V undamaged. See [`panel-latch-switch`](../discovery/findings/panel-latch-switch.yaml) |
| A7.2 | **Charge LED is common anode** | ✅ **PASSED 2026-09-22.** Diode test, red probe on the common pin, conducts to both others. ⚠️ *A note here once argued that lighting the green die on diode test proved a low-Vf part. It does not: diode-test current is well under a milliamp, where even a high-Vf die sits low. Withdrawn 2026-09-23.* See [`j4-charge-led`](../discovery/findings/j4-charge-led.yaml) |
| A7.3 | **Charge LED green still lights on a flat cell** | ✅ **PASSED 2026-09-22**, measured at the operating point: **0.77 mA at a 3.00 V supply** through 990 Ω, Vf 2.234 V. 🔴 The risk was real: J4 runs from `VOUT`, the cell falling to 3.0 V, and a high-Vf green goes dark exactly when the charge indicator matters. ⚠️ **The check was originally written as "is the die AlGaInP, not InGaN", and that phrasing is a trap**: the chemistry is only a proxy, it cannot be read off a low-current Vf, and the claim that it had been was withdrawn 2026-09-23. **Test the operating point, not the material.** See [`j4-charge-led`](../discovery/findings/j4-charge-led.yaml) |
| A7.4 | **RGB is common anode** | ✅ **PASSED 2026-09-23.** Diode test, red probe on the common pin, conducts to the other three. **Diffused** confirmed by eye. Vf at 5 V: red 1.932, green 2.454, blue 2.607. ⚠️ Those are **2.4-3.1 mA readings and do not contradict the 3.0-3.2 V label**, which is quoted at 20 mA where series resistance dominates. See [`j12-rgb-led`](../discovery/findings/j12-rgb-led.yaml) |
| A7.5 | **Test electret characterised** | ✅ **PASSED 2026-09-23.** Resistance both ways 1.397 k / 1.154 k, asymmetric, so an electret with integral FET. Biased in R51's own circuit, 3.30 V through a measured 2174 Ω: **drain 2.558 V at 339 µA, and RED IS POSITIVE** by measurement rather than convention. 🔴 **Two capsules exist**, and a second uxcell one is unattributed and unbiased. ⚠️ This does **not** establish that it produces signal, which needs E8. See [`bench-test-electret`](../discovery/findings/bench-test-electret.yaml) |
| A7.6 | **Switch lamp current** | ✅ **PASSED 2026-09-20: 28.5 mA at 5.00 V**, 5.6 mA at 3.00 V, on a 10.2 Ω shunt. Closed one of three unattributed lines in the 5 V budget in [values.md](values.md). 🔴 **Set the supply to 5.29 V, not 5.00 V**: the shunt drops 290 mV at this current, so a 5.00 V setpoint measures the lamp at 4.74 V and reads 11% low. See [`panel-latch-switch`](../discovery/findings/panel-latch-switch.yaml) |

✅ **All six A7 checks passed, 2026-09-20 to 2026-09-23.** Every part that could
have cost itself if wrong has been measured on the bench, and no board was
powered to do any of it.

**A7.5 was done first, for the reason it says.** Its job is to tell you whether
the board works, and an unmeasured reference cannot. If E8 reads nothing there
are three suspects: board, capsule, wiring. Measuring it removes one.
**Prove the test article, then use it to prove the board**, exactly as D1 proves
the Seed before it goes near the socket.

🔴 **But "proved" here means proved as far as a bench can, and that is four
things, not five.** A7.5 established that the capsule is genuinely an electret,
which lead is positive *by measurement rather than convention*, its operating
point in R51's own circuit, and a baseline so a later oddity can be told from a
changed capsule. **It did not establish that it produces usable signal**, which
needs this board or a scope. Do not arrive at E8 believing that question is
already answered.

**There are two bench capsules**, and only the small pigtailed one is
characterised. The uxcell has a baseline but its pads are unattributed and it
has never been biased. Having two is useful at E8 precisely because swapping
them separates a board fault from a capsule fault, which one capsule cannot do.

## A8. Consumables

- [ ] Bench supply, **5.00 V, limit 100 mA, CC not OCP**
- [ ] Fluke 101, **clip leads**, and **Dupont connectors on connector pins** to
      clip onto. Hand-held probes on a pad is how the hook switch produced 27 kΩ
      from a piece of metal.
      🔴 **The direction of a contact error FLIPS with the range, so neither
      direction is reassuring:**
      **low resistance** → poor contact adds series R → **reads HIGH**
      (the hook switch, 27 kΩ from a short circuit).
      **high resistance** → your body and surface leakage sit in **parallel** →
      **reads LOW**. Measured 2026-09-25: B2.3 on board 1 read **195 kΩ**
      hand-held and **0.59 MΩ** on clips, a 3× error, and it looked like a real
      difference between boards until it was retested.
- [ ] 10 Ω and 0.1 Ω shunts, 1 W or better
- [ ] 6 shunts per board for JP1-JP6 (Sullins SPC02SYAN, in hand)
- [ ] **BT1 holders and M3 screws.** Holders in hand; **screws still unsourced**,
      see [`bt1-cell-fit`](../discovery/findings/bt1-cell-fit.yaml). Blocks **C3
      only**
- [ ] A protected 18650, in hand. Fit confirmed 2026-09-01
- [ ] A Daisy Seed, in hand
- [ ] 🔴 **Mating cables**: JST-XH 2, 3, 4 and 6 way, JST-SH 4 way, IDC 2×5.
      Phases A to D run without them; **Phase E is where you stall**

## A9. Board identity

**The boards arrive numbered, and that is enough for this runbook.** The 1-5
mark and a QR code are silkscreened on the breakaway rails: two 5 mm rails on
the long edges, so the delivered part is 150 × 100 mm around the usual
150 × 90 mm board.

**The rails have no reason to come off during bring-up.** They are coplanar with
the board and obstruct no connector, so every phase here runs with them
attached. Depanelling belongs to enclosure fitting, which is after the test
campaign. **The mark therefore survives exactly as long as it is needed**, and
`mark_on_pcb: "Remove Mark"` plus
`depanel_and_edge_rail_before_delivery: false` turn out to have produced a
sensible arrangement rather than a trap.

| # | Do | Pass |
| --- | --- | --- |
| A9.1 | **Optional while the rails are on, and NOT optional once they are off**: copy the number onto the board proper in marker, bottom silkscreen, clear of any pad | the number survives depanelling |

🔴 **Board 1 has already lost its mark.** Its rails were snapped off on
2026-09-23 during soldering practice, so it carries no `0001` and no barcode. It
remains identifiable only because it is the odd one out: the single board with
**no rails and a fitted BT1**. That works while it stays unique and stops working
the moment a second board is depanelled. **Mark them before that happens**, and
mark all five at enclosure fitting, which is when every rail comes off at once.
See [`board-identity-and-condition`](../discovery/findings/board-identity-and-condition.yaml).

**The mark is four digits**, `0002` and not `2`, alongside a 2D barcode on the
lower rail.

**A9.1 buys one thing, and it is the drawer rather than the bench.** Five boards
and one or two instruments means three or four sit unused for months. A record
saying *board 3 had a marginal boost reading* is worth nothing if you cannot
tell which board is 3 when you pick one up next year. If you do not care about
that, skip it: nothing in this runbook depends on it.

### Depanelling, when you get there

🔴 **Cut, do not snap.** Flush cutters or a depanel tool, working along the tabs.
Snapping by hand flexes the board, and this one carries 64 0603 resistors and a
QFN-16 whose joints do not enjoy being flexed. That damage surfaces later as an
intermittent on a board you have already declared good, which is the most
expensive kind of fault to chase.

This is worth care independently of any marking question.

---

# Phase B: Dead board

> **Scope:** all five boards

No power. The phase that protects every later one, and the one that reveals a
batch fault while it still costs an evening rather than a Daisy Seed.

## B1. Inventory and visual

| # | Do | Pass |
| --- | --- | --- |
| B1.1 | Count the boards | 5 |
| B1.2 | Photograph both faces, in focus, whole board, **rail and its 1-5 mark legible** | filed in `discovery/evidence/`. This photo is what ties board N to its rail once the rail is gone |
| B1.3 | Part census by sweep band, below | 127 present |
| B1.4 | **BT1 absent** | absent, it is `self_fit` |
| B1.5 | **JP1-JP6 bare**, no shunts fitted | bare |
| B1.6 | Solder bridges, tombstones, skewed parts | none |
| B1.7 | **U1 QFN-16, U2 SOT-563, U3, U4 orientation** vs `local/fab/board-top.png` | pin 1 as drawn. 🔴 **U2 cannot be checked this way**: the SOT-563 has **no pin-1 dot at all**, confirmed under a microscope 2026-09-23, and its marking `1GI` is the only indicator. Record U2 **UNRESOLVED**, not passed, and let **C2** settle it: a rotated boost will not start, and C1's 100 mA limit makes that a diagnosis rather than a casualty. U1, U3 and U4 have conventional dots or notches. See [`u2-placement-orientation`](../discovery/findings/u2-placement-orientation.yaml) |
| B1.8 | **C7 polarity**, the 100 µF electrolytic | band to the marked pin |
| B1.9 | **IDC pin-1 and JST polarity on J5 and J11** | as drawn. *(These are **stock** IDC headers, 176 in inventory. This step used to claim `sourcing.md` flagged them as absonus footprints. **It does not.** Corrected 2026-09-23.)* |
| B1.10 | 🔴 **The connectors that ARE absonus reuses: J6, J7, J8, J9, J10, J13.** Pin order, polarity, **and which way each faces** | as drawn. `sourcing.md` lists exactly these under *on absonus*: proven to *fabricate* is not proven correct **here**. 🔴 **J13 was found facing into the board on 2026-09-23**, by eye, after two separate checks had been aimed at the wrong targets. See [`j13-qwiic-orientation`](../discovery/findings/j13-qwiic-orientation.yaml) |

**Photograph before handling.** A photo of an undamaged board is available once.
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

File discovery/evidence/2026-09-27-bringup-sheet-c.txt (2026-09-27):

caryatid bring-up tally sheet
====================================================================================================

  GENERATED 2026-09-27 from docs/bringup.md by tools/gen_bringup_sheet.py.
  BLANK. Nothing below is a result yet.

  DO NOT EDIT THE RUNBOOK TO RECORD A READING, and do not hand-edit this
  sheet's structure. Fix the runbook, regenerate, and the two stay in step.

  Board: ............   Operator: ............   Started: ............

  Instruments (per discovery/findings/bench-instruments.yaml):
    meter  Fluke 101, NO current ranges. Current is a shunt voltage.
    supply Jesverty 0-30 V 0-5 A, CC/OCP selectable.
    shunts 10 ohm for mA, 0.1 ohm for ~1 A.

====================================================================================================
PHASE C: POWER
scope: one board, and **choose it deliberately**
====================================================================================================

  C1. First power
  ---------------

    C1.1    The CV / CC indicator, not the current number
            expect: CV lit. !! Do not trust the supply's mA display here: bench-instruments
                    records that it reads amps well and milliamps badly, and at 15 mA on a 5 A
                    range the error is comparable to the quantity. CV versus CC is a binary and
                    is all this step needs. If a number is wanted, put the 10 Ω shunt in the
                    supply lead.
            reading: ......................

    C1.2    VOUT at J3 or J4
            expect: present, stable, below the input, around 4.4 to 4.5 V
            reading: ......................

    C1.3    /PGOOD, J4 pin 3 to J4 pin 4
            expect: near 0 V = asserted. !! /PGOOD reaches J4 pin 3 through R10, and with no LED
                    fitted nothing pulls that node up. So not-asserted floats rather than
                    sitting at VOUT, and a floating node reads anything. Only the low reading is
                    meaningful.
            reading: ......................

    C1.4    +5V at J16 pin 1, GND at J16 pin 3
            expect: !! dead, and that is correct (said J12 pin 1 until 2026-09-27; J12 has no
                    ground pin, pins 2-4 being the RGB cathodes)
            reading: ......................

    C1.5    Board temperature by hand
            expect: nothing warm. A warm QFN with no load is a fault
            reading: ......................

  C2. The boost
  -------------

    C2.1    Fit the J3 bare link (A6.2), pins 1 to 2
            reading: ......................

    C2.2    +5V at J16 pin 1, GND at J16 pin 3
            expect: 4.954 V nominal, accept 4.744 to 5.168 V (said J12 pin 1 until 2026-09-27,
                    same reason as C1.4)
            reading: ......................

    C2.3    +5V at J15, J16, J19
            expect: same, within meter resolution
            reading: ......................

    C2.4    Across FB1
            expect: tens of mV at most
            reading: ......................

    C2.5    Supply current
            expect: risen, modest with no load
            reading: ......................

    C2.6    U2 and L1 by hand
            expect: warm acceptable, hot is not
            reading: ......................

  C3. BT1 and the cell
  --------------------

    C3.1    Solder BT1, then repeat B2.2 for VBAT
            expect: no short. You just added two joints to a rail a cell will drive
            reading: ......................

    C3.2    Cell open-circuit voltage before fitting
            expect: 3.0 to 4.2 V, note it
            reading: ......................

    C3.3    Seat the cell, watching orientation
            expect: seats without forcing. Fit confirmed 2026-09-01
            reading: ......................

    C3.4    VBAT at the holder
            expect: matches C3.2
            reading: ......................

    C3.5    Supply out, check VOUT
            expect: alive, running from the cell
            reading: ......................

    C3.6    J3 link on, check +5V
            expect: inside the band, now boosted from the cell
            reading: ......................

  C4. Charging
  ------------

    C4.1    !! Raise the supply limit to 1.5 A, still 5.00 V
            expect: the charger needs far more than 100 mA
            reading: ......................

    C4.2    Supply in, cell fitted, partially discharged
            expect: /CHG asserts at J4
            reading: ......................

    C4.3    Charge current, off the supply display
            expect: 0.90 to 1.10 A. Cross-check with the 0.1 Ω if marginal
            reading: ......................

    C4.4    VBAT over some minutes
            expect: rising
            reading: ......................

    C4.5    Total input current
            expect: under the 1.29 A input limit
            reading: ......................

    C4.6    U1 case after ten minutes steady
            expect: warm, not hot. Closes charger-input-voltage-thermal
            reading: ......................

  NOTES / what this phase got wrong:
  ..............................................................................
  ..............................................................................

====================================================================================================
WHAT WAS NOT TESTED. Fill this in, do not leave it blank.
====================================================================================================

  Ripple, switching, inrush, debounce timing and audio quality are out of
  reach with this kit. Anything else you skipped goes here, so the record
  does not read as though it passed.

  ..............................................................................
  ..............................................................................

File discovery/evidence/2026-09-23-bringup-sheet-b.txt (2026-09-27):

caryatid bring-up tally sheet
====================================================================================================

  GENERATED 2026-09-23 from docs/bringup.md by tools/gen_bringup_sheet.py.
  BLANK. Nothing below is a result yet.

  DO NOT EDIT THE RUNBOOK TO RECORD A READING, and do not hand-edit this
  sheet's structure. Fix the runbook, regenerate, and the two stay in step.

  Board: ............   Operator: ............   Started: ............

  Instruments (per discovery/findings/bench-instruments.yaml):
    meter  Fluke 101, NO current ranges. Current is a shunt voltage.
    supply Jesverty 0-30 V 0-5 A, CC/OCP selectable.
    shunts 10 ohm for mA, 0.1 ohm for ~1 A.

====================================================================================================
PHASE B: DEAD BOARD
scope: all five boards
====================================================================================================

  B1. Inventory and visual
  ------------------------

    B1.1    Count the boards
            expect: 5
            b1 PASS      b2 PASS      b3 PASS      b4 PASS      b5 PASS    

    B1.2    Photograph both faces, in focus, whole board, rail and its 1-5 mark legible
            expect: filed in discovery/evidence/. This photo is what ties board N to its rail
                    once the rail is gone
            b1 PASS      b2 PASS      b3 PASS      b4 PASS      b5 PASS    
            b1: rails SNAPPED OFF, no 0001 mark. Identified instead as the only board

    B1.3    Part census by sweep band, below
            expect: 127 present
            b1 PASS      b2 PASS      b3 PASS      b4 PASS      b5 PASS    
            127 present, all five. Census by Matt.

    B1.4    BT1 absent
            expect: absent, it is self_fit
            b1 DEVIA.    b2 PASS      b3 PASS      b4 PASS      b5 PASS    
            b1: BT1 FITTED, hand-soldered as a soldering test. Deliberate, not a fault.

    B1.5    JP1-JP6 bare, no shunts fitted
            expect: bare
            b1 PASS      b2 PASS      b3 PASS      b4 PASS      b5 PASS    

    B1.6    Solder bridges, tombstones, skewed parts
            expect: none
            b1 PASS      b2 PASS      b3 PASS      b4 PASS      b5 PASS    
            No bridges, tombstones or skewed parts on any board.

    B1.7    U1 QFN-16, U2 SOT-563, U3, U4 orientation vs local/fab/board-top.png
            expect: pin 1 as drawn
            b1 PART      b2 PART      b3 PART      b4 PART      b5 PART    
            U1, U3, U4 PASS on all five. U2 UNRESOLVED: no pin-1 dot exists on SOT-563.

    B1.8    C7 polarity, the 100 µF electrolytic
            expect: band to the marked pin
            b1 PASS      b2 PASS      b3 PASS      b4 PASS      b5 PASS    
            Band to the marked pin on all five.

    B1.9    IDC pin-1 and JST polarity on J5 and J11
            expect: as drawn. sourcing.md flags these: the footprints came from absonus, which
                    proves they fabricate, not that they are right
            b1 PASS      b2 PASS      b3 PASS      b4 PASS      b5 PASS    
            J5 and J11 correct on all five.
            !! THIS STEP'S JUSTIFICATION IS WRONG. sourcing.md does NOT flag J5
               and J11 as absonus reuses: they are STOCK IDC headers, 176 in
               inventory. The actual reuses are J6 J7 J8 J9 J10 and J13, none
               of which this step names. J13 is the one that turned out wrong.
               Runbook corrected 2026-09-23; sheet NOT regenerated because it
               already carries results. See j13-qwiic-orientation.

    B1.10   The connectors that ARE absonus reuses: J6 J7 J8 J9 J10 J13
            expect: pin order, polarity, AND which way each faces
            b1 PASS      b2 PASS      b3 PASS      b4 PASS      b5 PASS    
            All JST correct on all five, J13 INCLUDED: it was placed exactly as
            the design specifies, at the CPL rotation. The assembly house is
            exonerated; J13's fault is upstream in the layout and is a DESIGN
            flaw, not a placement one. See j13-qwiic-orientation.
            !! This step was added to the runbook AFTER this sheet was
               generated, so it is appended by hand rather than in position.

  B2. Rail to ground
  ------------------

    B2.1    VIN_DC
            expect: J1
            b1 2.2M      b2 2.4M      b3 4.4M      b4 2.1M      b5 2.1M    
            PASS all five. Red J1.1, black J1.2.
            Curve identical on all five: starts ~40M, falls to just under 1M
            over minutes, climbs back to 2.x M. NOT a fault: a fault does not
            reproduce five times identically. Spread is noise at this scale.

    B2.2    VBAT
            expect: BT1 pads
            b1 PASS      b2 PASS      b3 PASS      b4 PASS      b5 PASS    
            Red BT1.1, black BT1.2. Same behaviour on all five: starts ~30M,
            dips to ~11k, climbs back, whole excursion ~8 seconds. Far shorter
            RC than B2.1's minutes. 11k is the lowest excursion so far and is
            the BOTTOM OF A TRANSIENT, not a settled value: 1100x the gate.
            NOTE b1 was probed at its FITTED holder's terminals, b2-b5 at bare
            pads, and they behave identically => the hand-soldered BT1
            introduces nothing detectable on this rail.

    B2.3    VOUT
            expect: J3, J4
            b1 0.59M     b2 0.58M     b3 0.58M     b4 0.58M     b5 190k    
            PASS all five. Red J3.1, black J3.4. Gate is 10 ohm; the lowest of
            these passes by 19,000x.

            TWO CORRECTIONS, IN ORDER, BECAUSE BOTH ARE INSTRUCTIVE.

            1. As first taken it looked like a 3-2 split, b1/b5 at ~195k against
               b2/b3/b4 at 0.58M, and was noted as probably curve position.
               b1 RETESTED ON CLIPS, with Dupont connectors on the pins: 0.59M.
               THE 195k WAS HAND-HELD PROBE CONTACT. At megohms the body sits in
               PARALLEL and pulls the reading DOWN, the opposite direction from
               the hook switch's 27k, so NEITHER DIRECTION OF ERROR IS
               REASSURING. Use clips. See A8.

            2. b5 was predicted to be the same artifact. IT IS NOT.
               b5 RETESTED ON CLIPS: STILL 190k. So the split is 4-1 and real:
               b5 is genuinely ~3x lower than the other four.

            WHAT b5 MIGHT BE: a ~280k parallel path would do it, which is
            leakage scale. A cap on VOUT, or part variation in the bq24074 OUT
            or U2 VIN pin. OR it may STILL be curve position, since reproducible
            on b5 is not the same as compared like-for-like against the others.

            🔴 NOT RESOLVED, AND DELIBERATELY NOT CHASED. Five orders of
            magnitude from any threshold and nothing downstream depends on it.
            IT IS THE FIRST THING TO LOOK AT IF BOARD 5 MISBEHAVES IN PHASE C.
            Free discriminator: watch whether b5 runs low on B2.4-B2.7 too.
                low on several rails  -> a board-level property
                low only on VOUT      -> specific to that net
                not low elsewhere     -> it was curve position after all

    B2.4    +5V
            expect: J16 pin 1, GND at J16 pin 3 or 4  (NOT J12: it has no ground pin)
            b1 392k      b2 392.9k    b3 392k      b4 394k      b5 393k    
            PASS all five. Red J16.1, black J16.3. All read at a CONSISTENT
            2-MINUTE MARK. Curve: ~40M down to ~200k, back up to ~392k.

            🔴 ALL FIVE WITHIN 0.5%. That is the result, and it bears on B2.3.
               B2.3 VOUT, sampled FAST and inconsistently: 3x spread.
               B2.4 +5V,  sampled CONSISTENTLY at 2 min: 0.5% spread.
               THE SPREAD TRACKS THE SAMPLING METHOD, NOT THE BOARDS.
            => b5 is NOT low here, so its B2.3 outlier is either specific to
               VOUT or was curve position. Curve position is now much the more
               likely, since consistently sampled boards agree to half a percent.
            => CLOSES THE 'is b5 a board-level property' DISCRIMINATOR: it is not.

    B2.5    +3V3
            expect: J16 pin 2
            b1 OL        b2 OL        b3 OL        b4 OL        b5 OL      
            PASS all five. Red J16.2, black J16.3. OL on every board.
            🔴 ON THIS RAIL OL IS THE EXPECTED ANSWER AND A FINITE READING WOULD
            BE THE ANOMALY. +3V3 is generated by the Seed, which is not fitted,
            so A2.38 is open and NOTHING connects this rail to ground. The only
            paths are C18's leakage and U3's unpowered VCC; the six resistors on
            the net (R14 R34 R36 R38 R43 R44) all terminate at signal pins that
            go nowhere with the board dead.
            RIG CONFIRMED BEFORE ACCEPTING THE OL: J16.3 to J16.4, both GND,
            read 0.3 ohm. So the probes were sound and the open is real.
            'Open' and 'not connected' look identical on a meter.
            (That 0.3 ohm is also an early preview of B4's ground continuity.)

    B2.6    +3V3A
            expect: J9 pin 1, J10 pin 1
            b1 99.5-99.9k  b2 99.5-99.9k  b3 99.5-99.9k  b4 99.5-99.9k  b5 99.5-99.9k
            PASS all five, and PREDICTED FROM THE NETLIST BEFORE MEASURING.
            Red J9.1, black J9.3. All five in 99.5-99.9k, a 0.4% spread.

            🔴 THIS ROW VERIFIES COMPONENTS, NOT JUST THE ABSENCE OF A SHORT.
            +3V3A carries two op-amp bias dividers to ground:
                +3V3A -[R55 100k]- VBIAS_L -[R56 100k]- GND
                +3V3A -[R59 100k]- VBIAS_R -[R60 100k]- GND
            200k each, in parallel = 100k. So the reading confirms all FOUR
            resistors present and correct on all five boards, and both dividers
            intact. Diagnostic value if it had differed:
                ~100k  both dividers intact
                ~200k  one divider open
                lower  something else conducting
                OL     both open

            ⚠️ METER NOTE, QUALIFIED. ~99k was predicted by applying the 1.1%
            low bias seen on the 600 ohm and 6k ranges. Measured is only
            0.1-0.5% below nominal. Either the network runs slightly high or the
            meter is more accurate on this range. CANNOT BE SEPARATED from one
            reading of a four-resistor network whose own combined tolerance is
            ~0.7%. Recorded as a data point, NOT as a correction.
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

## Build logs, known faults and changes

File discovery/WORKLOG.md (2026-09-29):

# Worklog

Newest last. Session state lives here and in the ledger, not in conversation.

## 2026-08-19 09:45 — Silkscreen references, enclosure measured, sourcing recorded, licensing settled across both repos

**Completed:**
- **Component references shown.** 71 of 96 hidden designators placed by
  `tools/ref_silk.py` (65 at 1.0 mm, 2 at 0.9, 4 at 0.8), taking the board from
  25 visible to 96. 25 left hidden deliberately — 0603 parts on 1.5 mm pitch in
  the audio network, where forcing a label prints ink on a solderable surface.
  All still carry `${REFERENCE}` on F.Fab. DRC unchanged: 5 excluded
  `lib_footprint_mismatch`, 0 silk_overlap. `check_board.py` 10/10.
- **`BUD-CU-477-interior` opened and confirmed.** Enclosure measured in hand,
  superseding two derived figures. Floor 178 × 110, height 34.0, plate 2.16
  ±0.1, perimeter lip 6.0/4.0. Board mounts 5 mm from the left wall — not
  centred — for power-button clearance *and* left-hand balance. The 12 mm
  latching switch descends 23 mm and sits in the reserved 28 mm strip
  (confirmed, was inference). Corrected the drill instruction, which said
  "±40/±70 from the floor centre" and would have put the board 9 mm into the
  button's space.
- **`JLC-BOM-sourcing` opened.** 36 codes, 16 Basic / 20 Extended, 100 SMT and
  111 through-hole joints per board. Parts $62.42 at qty 5 / $119.90 at qty 10,
  exact from live ladders. Retired the unsourced "$5.24/board" figure, which is
  roughly what the API's misleading `leastNumberPrice` field yields.
- **`tools/cost_estimate.py`** added — live ladders, measured joint counts,
  guesses isolated in one block, `--quote` reconciles against a real number.
- **Licensing made machine-readable.** caryatid read as `NOASSERTION` while
  public because `LICENSE.md` wrapped the licence text in a table. Root
  `LICENSE` is now the verbatim CERN-OHL-S v2; the explainer moved to
  `LICENSING.md`. GitHub now reports `CERN-OHL-S-2.0`.
- **Four stale caryatid docs** and **three stale loa docs** corrected — all
  still said the licence was unsettled or the repo private.
- **loa ADR 0007 written and accepted**: loa's `hardware/` returns to
  CERN-OHL-S-2.0, matching caryatid. Five `.scad` SPDX headers, licence text
  reinstated, READMEs restated. Also corrected two statements that had become
  hazardous — `hardware/README.md` claimed the power supply derives from
  Adafruit's PowerBoost (it does not, since caryatid), and
  `03-hardware-design.md` said deriving from their schematic "is fine", which
  under CERN-OHL-S is false.

**In flight:** nothing. Both working trees clean, both pushed.

**Open questions:**
- Whether the Extended loading fee is charged per unique part ($60) or per BOM
  line (~half that). Got backwards here once already; moves the total ~$30.
- The PCB fab estimate. 150 × 90 mm is area-priced past JLC's 100 × 100 tier and
  `cost_estimate.py` does not model the formula — `PCB_FAB` is a placeholder.
- Bench measurements still open, and deliberately not blocking: handset capsule
  DC resistance, J4 green die at 3.0 V, switch lamp current. `docs/audio.md`
  defers the capsule question past fabrication by design (U4 is DNP with a
  bypass), so these change resistor values, not the board.

**Next step:** when the pre-ordered battery holders appear in the JLC parts
library, raise the quote for **5 boards, full turnkey**, then run
`.venv/bin/python tools/cost_estimate.py 5 --quote <total>` in the caryatid repo
and correct `RATES` / `PCB_FAB` from what it reports. Pre-orders are
`C5339083` ×5 @ $4.8616 and `C2897383` ×10 @ $0.338.

## 2026-08-20/21 — ADR 0009, the left mic channel behind jumpers

**Not logged at the time.** Twenty-three commits, `5bc99d2..ad6a54d`, spanning
the JLC BOM/CPL format work, BT1's move to self-fit, and all of ADR 0009. The
commit messages carry the detail; this entry exists so the gap in the worklog is
visible rather than silent. The durable outcomes are in
[ADR 0009](../docs/decisions/0009-mic-input-is-jumper-selected.md),
[audio.md](../docs/audio.md) and
[mic-configurations.md](../docs/mic-configurations.md).

## 2026-08-21 — ADR 0010: the right mic channel is jumpered, and nothing is DNP

**Completed:**

- **[ADR 0010](../docs/decisions/0010-nothing-is-dnp.md) written and accepted.**
  Zero `dnp` on any sheet. BT1 is not an exception — it is `self_fit`, which is
  an assembly routing decision, not a population one.
- **The right mic channel is a full mirror of the left.** JP4 bias / JP5 path /
  JP6 gain, plus **R68 392R**, the one part that is not a translation: the left
  has two gain legs (R58 1k, R67 392R) and the right had only R62, so without
  R68 there was nothing for JP6 to select.

  **This was not simply "clear the DNP".** The right channel is laid out as an
  exact mirror of the *pre-jumper* left, +149.86 mm in Y, so it inherited both
  mutually exclusive pairs — 2k2-to-3V3A against 220R-to-5V on `MIC_R`, op-amp
  output against raw bypass on `AUDIO_IN_R`. Populating it without jumpers would
  have shipped the exact defect ADR 0009 exists to prevent.
- **R48, R50, R64, R66 deleted.** Their value is `open`; no supplier ships one,
  so they could not be populated to satisfy the rule. What they provided is
  covered: R47/R49 1k *is* the earpiece attenuator, and the WM8731 line PGA
  reaches −34.5 dB, which is more pad than a resistor was going to give and is
  adjustable at run time. **R66 was on the wrong node** — it tapped `AUDIO_IN_R`,
  downstream of where JP5 lands, so it would have padded the op-amp output too.
  A latent defect removed alongside a DNP.
- **R43–R46 assembled.** Both exclusions failed on the numbers: a UART line
  idles high so a 4k7 pull-up holds it where it belongs, and A4/A5 reach only
  J9/J10 (J5 carries A0–A3, A6–A9), checked against the netlist.
- **`check_board.py` check 12** — no `dnp` on any sheet. The one schematic check
  in that tool, because nothing else has an opinion: ERC ignores `dnp`, DRC
  never sees it, and the only symptom of one reappearing is a BOM line that
  quietly stops being fitted. Verified by injecting one.
- **`tools/stale_tracks.py`** — finds tracks left sitting on a pad whose net
  moved. **Calibrated against the known-answer case**, the board immediately
  before `0491e70` where DRC found exactly four: 0.001 mm margin finds 2,
  0.10–0.15 finds 4, 0.20 finds 6 including legitimate routing. 0.15 is
  `min_clearance` from the project file, not a tuned number.
- **Thirteen documents corrected**, including two statements that had gone
  false: `audio.md`'s "the right stays DNP", and `sourcing.md`'s R52/R54
  dissipation note, which said "they are not populated now" when both now are.

**Verified:** ERC 0 violations at `--severity-all` after each of the three
schematic edits; netlist diff shows 99 of 107 nets byte-identical with 6 new and
8 changed, all intended (`discovery/evidence/2026-08-21-audio-netlist-diff.txt`);
0 `dnp` across all five sheets; `check_board.py` 12/12.

**In flight:** **the schematic is ahead of the board, deliberately.** DRC reports
**28 schematic parity issues** and that is exactly this. `kicad-cli` has no
update-from-schematic, so the next steps need the GUI and are listed in the
RESUME HERE block at the top of [status.md](../docs/status.md).

**Open questions:**

- **R52/R54 dissipation, now live rather than hypothetical.** 92 mW on a 100 mW
  0603 if a carbon capsule sits at 0.5 V, and both are populated. The carbon
  jumper position and the `MIC_RTN` hook-switch gate keep it from being urgent.
  Measure a capsule, then decide whether those two want an 0805.
- **`MIC_RTN` is shared by both channels** — one gated return, two capsules. A
  stereo carbon pair puts both bias currents through one switch contact. Correct
  arrangement (the gate belongs to the handset), worth knowing before sizing it.
- The manufacturing counts in `status.md` are stale by design until the board is
  updated. Re-run `fab_package.py`; do not hand-edit them.
- Everything still open from 2026-08-19: the Extended fee basis, the PCB fab
  area price, and the three bench measurements.

**Next step:** open KiCad, **Update PCB from Schematic**, place JP4–JP6 and R68,
delete the four removed footprints, then **run `tools/stale_tracks.py` before
routing anything** — five pads change net and KiCad leaves the old tracks
behind. Re-route, refill, DRC with `--schematic-parity`, `check_board.py`,
`jumper_legend.py --apply`, `fab_package.py`.

## 2026-08-22 18:30 — Silkscreen finished, necks widened, last 3 parts sourced; fab package READY

**Completed:**

- **Silkscreen closed out.** J12 pin labels shortened to R/G/B on their pads;
  J13 vertical at 1.3 mm pitch (the 3-row stagger ran off the board); reference
  left / role right on one bottom row for J6-J10, J12, J15, J19; J14/J17/J18 on
  a vertical J19-style baseline at x 197.8 with their pin labels right-justified
  per jack; role labels centred on the BODY outline, not a bounding box that
  swallowed the pin-1 marker. `15915bf`, `28c54f1`.
- **All 5 necked tracks widened to 0.20 mm** — they were never load-bearing.
  `widen_necks.py` was verifying against a pour it had not recomputed, so one
  false positive reverted four sound repairs. It now runs ZONE_FILLER between
  the widen and the check. `221b236`.
- **One GND via at (67.52, 55.8)** stitching the 5.56 mm2 F.Cu pocket at U1's
  south-west corner to the plane, placed clear of the EP. `6efdcfb`.
- **JLC-BOM-sourcing: 127 of 127 parts covered.** R45 -> C4211 (already stated
  in sourcing.md), R43/R44 -> C23162 (a NEW selection, mine, catalogue-verified).
  `fab_package.py` reports **ready**; `local/fab/caryatid-fab.zip` written,
  373 kB, 14 files. Evidence: `2026-08-22-lcsc-r43-r44-r45.json`,
  `2026-08-22-fab-readiness.txt`.
- **R45's pad angle normalised** 270 -> 90 (180 relative -> 0). It was the only
  one of 64 0603 resistors like that. I put it in drc_exclusions' allow-list
  first; that was wrong and Matt's question caught it. Plain DRC 3 -> 2.
- **BUD-CU-477-interior:** the "R45 sits 1.22 mm from the board edge" concern is
  RETIRED as never-true. Measured 5.500 mm, with J15 and J9 both reaching
  further toward that edge. It was never in any record, which is why it survived
  four sessions.
- **Checked, no work needed:** boost hot loop against SLVSF14B Fig 10-1 —
  U2.6->C6.1 1.785 mm, C6.2->U2.4 1.834 mm, perimeter 6.519 mm, returning
  through a shared 23.1 mm2 F.Cu island rather than a track; SW node 3.717 mm
  and 0.612 mm2 of copper; C5 2.465 mm off the VOUT input pin.
- **status.md and sourcing.md re-derived from the board.** status.md still said
  "the board is unrouted, on purpose" and reported 0 tracks.

**Verified:** DRC 0 unconnected, 0 parity, 0 clearance, 0 track_width, 0 silk;
2 lib_footprint_mismatch (A1/A2 only). `check_board.py` 12/12 over 135
footprints. `drc_exclusions.py` 0 new, 5 accepted. `verify_parts.py` 0 of 43
flagged, 2 pre-order. 957 tracks (4186 mm), 167 vias, 10 zones filled; F.Cu 26
islands main 5003.5 mm2, B.Cu one 11448.3 mm2 plane; 0 DNP.

**In flight:** nothing. Working tree clean, both repos pushed.

**Open questions:**

- **A1/A2 need a one-time right-click exclude in pcbnew's DRC panel.** Their
  mismatch is metadata only — all 20 pads of each were diffed against
  `caryatid.pretty/DaisySeed_Socket_A_1x20.kicad_mod` and NONE differ; what
  differs is `path`, `sheetfile`, `sheetname` and two property fields KiCad adds
  on placement. `drc_exclusions.py` will not synthesise the keys: it tried once
  and got the coordinate wrong for exactly these two.
- **C23162 (4k7, R43/R44) is a tooling choice, not Matt's.** Commodity 0603 1%
  Basic, same Uniroyal series as C4211, catalogue-verified — but it is the one
  code in the BOM nobody stated. Worth a glance before ordering.
- **R52/R54 dissipation** — 92 mW on a 100 mW 0603 if a carbon capsule sits at
  0.5 V, both populated. Measure a capsule, then decide on 0805. (Carried.)
- **`MIC_RTN` is shared by both channels** — one gated return, two capsules.
  (Carried.)
- Everything still open from 2026-08-19: the Extended fee basis, the PCB fab
  area price, and the three bench measurements.

**Next step:** open `hardware/pcb/caryatid.kicad_pcb` in pcbnew, run DRC from
the panel, right-click each of the two `lib_footprint_mismatch` violations on A1
and A2 and choose **Exclude this violation**, save, then run
`python3 tools/drc_exclusions.py --apply` to attach the documented reasons.
Plain DRC then reads zero and `local/fab/caryatid-fab.zip` is orderable as it
stands.

## 2026-08-23 — A1/A2 excluded; plain DRC reads zero; tool conventions written down

**Completed:**

- **Matt excluded the A1 and A2 `lib_footprint_mismatch` violations** in
  pcbnew's DRC panel. The keys landed at x 115.853, y 66.248 and 76.265 — the
  coordinates `drc_exclusions.py` could not reconstruct and rightly refused to
  synthesise. `drc_exclusions.py --apply` attached their documented reasons:
  5 exclusions kept, 2 given a reason, **plain DRC now reports 0 violations**.
- **`docs/conventions.md` written.** Eight rules that apply across tools, each
  with the failure that produced it and the measurement that proves it. They
  had been buried in individual docstrings where the next tool to repeat the
  mistake could not see them. Linked from the README's "Start here" table.
  Rule 1 is the one that prompted this: **recompute the zone fill before
  verifying a copper change**, which cost four sound repairs when
  `widen_necks.py` judged widened tracks against a pour that had not moved.

**Verified:** plain DRC **0 violations**, 0 unconnected, 0 parity;
`drc_exclusions.py` 0 new, 5 accepted; `check_board.py` 12/12;
`fab_package.py` **ready**, 127 of 127.

**In flight:** nothing.

**Open questions:** unchanged — C23162 (4k7, R43/R44) is a tooling choice rather
than Matt's and is worth a glance before ordering; R52/R54 dissipation; shared
`MIC_RTN`; and the three items carried from 2026-08-19.

**Next step:** order. `local/fab/caryatid-fab.zip` (373 kB, 14 files) plus
`bom.csv` and `cpl.csv` beside it are current and every gate is green. BT1 is
bought separately — `self-fit.csv`, Digi-Key 3029216.

## 2026-08-23 — /bootstrap Phases 1–2; the Extended fee was never still open

**Completed:**

- **`/bootstrap` Phase 1 (inventory) and Phase 2 (scaffold).** `engagement.yaml`
  written here and in loa, both git-excluded via `.git/info/exclude` per the
  rekor and gcc precedents — this repo is published, so working configuration
  stays out of it. `CLAUDE.local.md` created here for the first time: caryatid
  is the canonical clone where all work happens and it had no local context at
  all, only loa's.
- **Voice recorded.** caryatid is `voice: professional`; loa, absonus and
  baby-borg are `creative`, carrying the Nervous Gender Reloaded personality.
  Confirmed by Matt 2026-08-23. `ideocentric/_org.md` currently lists all four
  together under one "Hardware projects" heading without distinguishing them —
  a refinement is proposed there but NOT yet applied.
- **Phase 3 deliberately narrowed, and the narrowing is not new.** A mass
  salvage of ~700 numeric claims across 15 documents into `unverified` records
  was refused. `discovery/README.md` already scopes this ledger to facts the
  repo cannot check for itself, and `ideocentric/_org.md` carries the same
  exception for hardware projects. DRC, `check_board.py`, `verify_parts.py` and
  `fab_package.py` verify the board's numbers continuously; records would be a
  staler second copy.

**Corrected:**

- **The Extended loading fee has NOT been an open question since before this
  worklog said it was.** Carried here as unresolved three times — "whether the
  fee is charged per unique part ($60) or per BOM line" — while
  `~/.claude/contexts/ideocentric/_org.md` states it is **per unique part, not
  per BOM line**, and `tools/cost_estimate.py` has implemented exactly that
  (`"extended_fee": 3.00, # per UNIQUE Extended part`). Settled in two places,
  carried as open in a third. **It is closed.**
- `discovery/README.md` said the sourcing record covers "The 36 LCSC codes". It
  is 43. Now dated rather than restated.

**In flight:** Phase 2 is otherwise done. Two `~/.claude` edits are PROPOSED and
not applied — refining `ideocentric/_org.md`'s voice section to distinguish
caryatid from the instruments, and filling the 8-line `ngr/_org.md` stub, which
needs NGR's actual tone and vocabulary from Matt rather than my invention.

**Open questions** — five, down from the six carried yesterday:

- PCB fab area price: 150 × 90 mm is past JLC's 100 × 100 tier and
  `cost_estimate.py`'s `PCB_FAB` is a placeholder. Needs a quote.
- Handset capsule DC resistance (bench).
- J4 green die at 3.0 V (bench).
- Switch lamp current (bench).
- Part behaviour no catalogue field states, per `verify_parts.py`: C6 needs
  ≥4 µF **effective** at 5 V bias; C7 must be aluminium electrolytic for its
  ESR; FB1 DCR ≤50 mΩ at ≥1 A.

None of these has a ledger record. They are the genuine Phase 3 scope.

**Next step:** order the boards. Every gate is green — plain DRC 0 violations,
`check_board.py` 12/12, `fab_package.py` ready at 127 of 127, and
`local/fab/caryatid-fab.zip` is current. BT1 is bought separately
(`self-fit.csv`, Digi-Key 3029216).

## 2026-08-23 18:35 — All three orders placed; boards are in fabrication

**Completed:**

- **BOARDS ORDERED.** JLC, five, full turnkey, Economic assembly, top side, ENIG.
  Merchandise $176.24, grand total **$306.95** after $46.97 shipping, $63.21
  customs duties, $1.43 payment fee and $19.10 sales tax. Recorded as
  `JLC-order-2026-08-23`, status `confirmed`, with every form setting captured
  and eight of eight checkable ones verified against the board.
- **Digi-Key ordered**: ten BH-18650-PC-ND at $2.88 and one hundred S9001-ND at
  $0.0247, total **$49.56**. Ten holders rather than five, so five spares.
- **Surface finish changed to ENIG** for about $20, closing
  `hasl-under-fine-pitch`. U1 is a QFN-16 on 0.5 mm pitch with an exposed pad,
  and a no-lead package cannot flex to take up an uneven surface. **The paste
  was deliberately left lead-free**, which is correct for ENIG and would NOT
  have been correct for the leaded HASL revert that was considered and rejected.
- **BT1 fit resolved from MPD's STEP model.** Contacts sit 61.504 mm apart at
  rest with 5.888 mm of travel each, housing wall stops a cell at 70.900 mm.
  Matt's 69.48 mm cell clears the wall by 0.710 mm a side while over-deflecting
  each contact 23% past rating. Seats, under protest.
- **`accessories:` added to lcsc.yaml** as a third sourcing category. Six shunts
  per board were on no bill of materials and no shopping list while
  fab_package.py reported "ready".
- `/bootstrap` Phases 1 and 2, `engagement.yaml` in both repos, caryatid's first
  `CLAUDE.local.md`, `docs/conventions.md`, NGR voice filled, em dash ban made a
  house rule.

**Verified:** plain DRC 0 violations, 0 unconnected, 0 parity; `check_board.py`
12/12; `fab_package.py` ready at 127 of 127. Evidence saved this session:
`2026-08-23-bt1-step-geometry.txt`, `-cost-reconcile.txt`, `-gates-at-order.txt`.

**In flight:** nothing. Three orders placed, all trees clean and pushed.

**Open questions:**

- **`BT1-cell-fit` is `conflict` and stays that way until something is
  assembled.** Geometry says the cell seats; only a holder in hand says it seats
  with sane force and that the contact springs back. **First thing to do when
  the parcels land.**
- **Jumper placement preview** comes through rotated and offset across builds.
  Filed `for-next-time` with three places to look. Not cosmetic: on a 3-pin
  header a 180 degree rotation changes which pair a shunt bridges.
- Confirm Parts Placement, Confirm Production File and Photo Confirmation were
  all off on a first article of 127 placements.
- Tooling holes "Added by JLCPCB" on a fully routed and poured board.
- **Costs were understated by 2.5x for most of this project's life** and the
  cause is now recorded: `cost_estimate.py` models merchandise only. Shipping,
  duties, fees and tax added 74% at JLC and 19% at Digi-Key. Two imports out of
  two carried a tariff and nothing models them.
- Carried: R52/R54 dissipation on a 100 mW 0603, and `MIC_RTN` shared by both
  channels. Both want a capsule measured.
- `docs/values.md` still reasons from a 3000 mAh cell; the ordered cell is
  3400 mAh, so runtime is conservative and charge time is about 13% optimistic.

**Next step:** wait for delivery. On arrival, before building anything, **seat
one Orbtronic cell in one BH-18650-PC** and judge the insertion force and
whether the contact returns. That closes `BT1-cell-fit`. If it does not seat
acceptably, the fallback is a different cell rather than a different holder,
because BT1's footprint is dimensionally specific and swapping it is a board
change.

## 2026-08-23 19:10 — Battery figures regenerated from the cell actually bought

**Completed:**

- **`docs/values.md` regenerated at 3400 mAh.** It had reasoned from a 3000 mAh
  design basis throughout while the ordered cell is the Orbtronic 3400.
  Runtime 12.3 / 7.3 / 5.2 h from 2833 mAh usable, charge 4.0 h at 1 A and 2.7 h
  at 1.5 A, rate 0.29C and 0.44C.
- **The derivation was recovered from the document's own numbers, not assumed.**
  Usable is 83.3% of nameplate and runtime is usable over cell current, which
  reproduces the printed 10.8 / 6.5 / 4.6 h; charge is CC to ~80% then the CV
  tail, which reproduces the printed 3.5 h. Both models validated at 3000 before
  being re-run at 3400. Working in
  `2026-08-23-battery-figures-rederived.txt`.
- **Two further figures were resting on the old capacity**: the A10 gauge
  leakage comparison, 92 mAh over six months, quoted against 3000 mAh in BOTH
  values.md and seed-sheet.md. Both rebased. The 3000 mAh in sourcing.md's
  LiPo-pouch comparison is a different cell and was left alone.
- **`ideocentric/_org.md` gained a costing section** (in ~/.claude, committed
  separately as 42209e1): merchandise is not landed cost, every import so far
  carried a tariff, and read the price ladder at the quantity actually bought.

**Corrected:** I had called the whole 3400 mAh set "conservative" because the
cell is bigger than the design basis. Runtime improved and CHARGE TIME
LENGTHENED. A bigger cell is only conservative in one direction.

**In flight:** nothing. All three orders placed, boards in fabrication.

**Open questions:** unchanged from the previous entry. `BT1-cell-fit` stays
`conflict` until a holder and a cell meet. The jumper placement preview, the
three confirmation steps left off, and JLC's tooling holes are all still open.
R52/R54 dissipation and the shared `MIC_RTN` both still want a capsule measured.

**Next step:** unchanged and physical. On delivery, **seat one Orbtronic cell in
one BH-18650-PC** before building anything, and judge the insertion force and
whether the contact springs back. That closes `BT1-cell-fit`. The fallback is a
different cell rather than a different holder, because BT1's footprint is
dimensionally specific and swapping it is a board change.

## 2026-08-23 19:40 — R52/R54 specified rather than carried

**Completed:**

- **`carbon-capsule-DC-resistance` opened**, `unverified` with an empty evidence
  list because nothing has been measured. It replaces the line carried since
  2026-08-19, "measure a capsule, then decide whether those two want an 0805",
  which never said what reading would mean what. **A carried question with no
  threshold attached cannot be closed by anyone**, which is the same shape as
  the R45 edge-clearance concern that survived four sessions.
- **One number decides it**, the capsule's DC resistance, since it sits in
  series with the 220 ohm resistor across 5 V. `P = (5/(220+Rc))^2 * 220`.
  Below **14.5 ohm** R52/R54 exceed the 100 mW 0603 rating outright and must go
  0805; below **112 ohm** they are inside rating but past a 50% derate, a
  judgement call; above that, nothing to do.
- **The procedure carries its two traps**, both of which would produce a
  confident wrong answer: take several readings while tapping and USE THE
  LOWEST, since granules resettle and lowest is worst case for R52; and measure
  every capsule intended for use, not one representative.
- **The same measurement closes the carried `MIC_RTN` question**: both channels
  on carbon put 31 to 41 mA through the one gated hook switch depending on Rc.
- Noted in the record: the 0.5 V in the existing sourcing.md note is an
  assumption, not a measurement. It implies about 24 ohm, landing in the middle
  band where the answer is a judgement rather than at either end where it would
  be obvious.
- `discovery/README.md`'s entry for the order record was stale, still saying
  "not yet placed".

**In flight:** nothing. Boards in fabrication, all three orders placed.

**Open questions:** five records, two of them open by design.
`BT1-cell-fit` is `conflict` until a holder and a cell meet.
`carbon-capsule-DC-resistance` is `unverified` until a capsule is measured.
Both now say exactly what would close them. Also carried on the order record:
the jumper placement preview, the three confirmation steps left off, and JLC's
tooling holes.

**Next step:** unchanged, and physical, and now there are two of them, both
needing parts in hand. On delivery, **seat one Orbtronic cell in one
BH-18650-PC** and judge insertion force and whether the contact springs back.
Separately, whenever a carbon capsule is to hand, **measure its DC resistance**
against the thresholds above. Neither needs the boards, so the capsule
measurement can happen any time.

## 2026-08-23 20:10 — Cross-repo review: three gaps closed, one of them nine days old

**Completed:**

- **`status.md`'s cost section was stale four ways.** It claimed "$141.36 for 5
  ($28.27/board)... real total ~$159" against actuals of $306.95 to JLC and
  $423.96 all in; said 19 and 20 Extended where the board now has **22**; listed
  `PCB_FAB` as an open placeholder after it was measured at $42.56; and still
  carried the Extended-fee question after it was closed. Both open questions
  struck through with what closed them, and a third added that genuinely is
  live: **nothing models landed cost**.
- **loa's `docs/design/12-phone-build.md` contradicted caryatid AND itself.**
  Last revised 2026-08-11, nine days before ADR 0009. One paragraph said the
  capsule measurement "no longer gates the board, since **the gain stage is DNP
  either way**"; the next said it "gates the board". The first is false: ADR
  0009 populates the front-end at assembly, ADR 0010 cleared every DNP, U4 is
  fitted with both halves live. Corrected, with a dated banner at the top of the
  page because anything else there reasoning from a DNP front-end is stale for
  the same reason.
- **`mic-gain-budget` opened**, `unverified`. audio.md and ADR 0009 both state
  gain targets of ~x3 / ~x100 / ~x1000 and **neither repository contained a
  single capsule output level to derive them from**. ADR 0009 says the capsule
  requirement "was never written down" and calls it a documentation failure
  before a design failure; the same was true one level down, of the levels its
  own targets rest on. This is what Matt could not find at ordering time.

**Verified:** target is the WM8731's own `VINLINE`, **1.0 Vrms at 0 dB**,
extracted with pdftotext from the datasheet rather than a summary and saved as
`2026-08-23-wm8731-line-input-level.txt` because the fetched PDF was in a temp
path. Against class-typical sensitivities, **all three documented targets land
inside their range**: electret needs 56-200x and gets 101x; dynamic needs
250-1000x and gets 1020x with the codec's +12 dB; carbon needs 2-10x and is
passed at 1x with the PGA trimming either way. **The targets were right all
along; what was missing was any way to check them.**

**In flight:** nothing. Six ledger records, both trees clean and pushed.

**Open questions:** three records open, all by design and all stating what would
close them. `BT1-cell-fit` (`conflict`) wants a holder and a cell in the same
hand. `carbon-capsule-DC-resistance` and `mic-gain-budget` (both `unverified`)
want a capsule, and **both close in the same bench session**. Also carried on
the order record: the jumper placement preview, the three confirmation steps
left off, and JLC's tooling holes.

**Next step:** unchanged, and all three open items are physical. On delivery,
**seat one Orbtronic cell in one BH-18650-PC** before building anything.
Whenever a capsule is to hand, **measure its DC resistance** against the 14.5
and 112 ohm thresholds, and **read the op-amp output on a scope** with each gain
leg selected. Neither capsule measurement needs the boards.

## 2026-08-24 — Documentation reframed around who reads it; KiCad stripped two exclusion reasons

**Completed:**

- **`docs/platform.md` written**, the capability specification this repository
  never had. Fifteen documents answered "what is on this board and why we chose
  it"; none answered "should I use it". Leads with the gap the board fills,
  states the support envelope, and carries a limits section written plainly with
  each limit's escape route. Every hard number verified against the board,
  `pins.yaml` or a ledger record before committing: 10 of 10 checks.
- **README reframed.** The first section a stranger met was a warning about
  which git checkout they were in. Reordered around the reader's questions, with
  a one-line pointer keeping the checkout hazard visible to anyone about to
  commit. Status now reads "five ordered, none powered" rather than "fully
  routed", which answers a question someone outside this repo is actually asking.
- **`integration.md` narrowed** to "now that you have decided", losing the
  evaluation material `platform.md` now owns and a stale line about part counts
  being absent until the board was updated.
- **Corrected in `platform.md`:** I wrote the DC input as "5 V nominal". It is
  **5 to 9 V**, never 12, with OVP tripping at 10.2 to 10.8 V. `integration.md`
  had it right and my new document understated the board. Read back from
  `power-sheet.md` rather than reconciled between the two.
- **Standoff guidance reversed.** I had argued for a taller standoff on lip
  clearance; the enclosure record already establishes the board never overlaps
  the lip in plan. Matt's constraint runs the other way: panel pots intrude from
  the lid, so every millimetre of standoff is spent twice. Now says keep it
  short, with the sourcing trap that 4 mm is harder to find than 5 mm, and that
  cable terminations rather than the board usually decide the height.

**Corrected this session, and it is a recurrence worth naming:**

- **KiCad stripped the reasons from two DRC exclusions** when the board was
  opened at 23:49. A1 and A2 kept their exclusions and lost both justifications.
  **The gate does not catch this**: it matches on violation type and item, not on
  the comment, so it reported "0 new, 5 accepted, clean" with two of five excused
  by nobody. Restored with `--apply` in a second; the tool's docstring now says
  to re-run it after any KiCad session.

**Verified:** the board file is untouched at 2026-08-23 10:41, so the design that
was ordered is intact. Only the project file's annotations moved.

**In flight:** nothing. Six ledger records, both trees clean apart from one
untracked file, see below.

**Open questions:** three records open, all stating what closes them, and **two
of the three no longer wait on the boards.** Matt has the telephone in hand, so
the handset capsule can be measured now: DC resistance against the 14.5 and 112
ohm thresholds, and output level against the gain budget. The keypad wants
beeping out before anyone assumes it is discrete rather than a matrix.

**Undecided, and left for Matt:** `hardware/pcb/caryatid-v0.1.pdf`, exported
from KiCad at 23:59 and untracked. **No PDF is tracked anywhere in this
repository** and nothing in `.gitignore` covers it, so it is neither established
convention nor deliberately excluded. It wants a decision rather than a default.

**Next step:** measure the handset capsule. It needs nothing that has not
arrived, it closes two of the three open records, and the thresholds are already
written down.

## 2026-08-24 (later) — PDFs and renders published; a schematic checker, and JP6 fixed

**Completed:**

- **Reference artefacts automated.** `--apply` now writes a composite board PDF
  stacked as the PCB viewer shows it (back copper, front copper, silkscreen on
  top), a six-page schematic PDF, and top and bottom photographic renders at
  `--quality high`. `--archive` copies the PDFs to `discovery/evidence/` under
  dated, SHA-stamped names when an order is placed.
- **Two places, two purposes.** `docs/reference/` and `docs/img/` carry stable
  names and are always current, for reading. `discovery/evidence/` carries
  stamped copies of what was ordered, for provenance. Each artefact is stamped
  by ITS OWN last change: the board and schematic move independently.
- **`check_schematic.py` added**, which reports and never edits. Found JP6 sitting
  in audio.kicad_sch's title block, printing across "File: audio.kicad_sch",
  plus five labels genuinely crossing the resistor they name.
- **JP6 lifted 22.86 mm**, all seven attached elements moved together.

**Corrected, and the checker is the reason:**

- **I claimed twice that labels ran through the resistors**, from a 100 dpi plot
  and then a 300 dpi one. For the short ones they do not: R51's body ends at
  y 132.08 and BIAS_E_L begins at 132.67, clearing by **0.59 mm**. At plot scale
  a sub-millimetre gap reads as contact. The tool now separates OVERLAP, a
  defect, from NEAR, cosmetic, because an eye cannot measure. The longer labels
  do genuinely overlap, so the instinct was half right and only geometry could
  say which half.
- **I nearly shipped a check that fires on healthy work**, reporting "220 of 272
  texts more than 10 mm from their symbol". A reference 10 mm above a resistor
  is correct placement. Dropped rather than reported.
- **A schematic embeds its symbol library beside its placed instances** and the
  two look identical. Matching both reported 49 symbols outside the page
  borders. A placed instance carries `lib_id`; a definition does not. The real
  answer was one.
- **I committed Matt's hand-exported PDF by accident** with `git add -A`, one
  message after saying it was his and I had not touched it. Untracked in
  e6ca99b, history left alone at his instruction, file deleted.

**Verified:** the JP6 move is netlist-identical across 113 nets, ERC 0,
schematic parity 0, board file untouched. Connectivity in a schematic is
positional, so moving the symbol without its three wires and three labels would
have disconnected it silently while still looking right.

**In flight:** nothing. Six ledger records, both trees clean and pushed.

**Open questions:** three records open, two closable with the phone in hand.
Five cosmetic label crossings remain on the schematic; they want a person in
Eeschema, which is the work the checker exists to scope rather than to do.

**Next step:** unchanged. Measure the handset capsule: DC resistance against the
14.5 and 112 ohm thresholds, and output level against the gain budget. Beep out
the keypad at the same time.

## 2026-08-24 20:13 — Schematic legibility closed out: five label crossings and seed's field offset

**Completed:** the two drawing defects `check_schematic.py` was built to scope,
both netlist-verified rather than eyeballed.

- `f249562` — the five labels clipping their resistors (`LEG_101_L/R`,
  `LEG_256_L/R` on audio, `PGOOD_LEG` on seed) moved 2.54 mm out, each with its
  wire's FAR endpoint. The near endpoint is what touches the pin and did not
  move; moving it is precisely how this edit silently changes a netlist.
  Rotating the labels instead was considered and rejected: it clears the body
  but points the text away from the wire it names, trading 0.13 mm of overlap
  for a drawing that reads wrong.
- `ea6cd62` — R11–R18, C8 and C9 on `seed.kicad_sch` reseated from (+6, −30) to
  the (+6, −12) / (+6, −9) the other sheets already use. Sheet median field
  distance 30.59 → 13.42 mm.
- `a5bc7cc` — schematic PDF republished. Only that one artifact was committed:
  the board PDF came back the same byte count differing solely in
  `/CreationDate`, and the two renders differ by raytracer noise, the
  `.kicad_pcb` being untouched. No reason to put 600 kB of that in history.

**A1 and A2 were deliberately left at −30, and that is the finding.** Matt named
seven parts; ten shared the bad offset; two more looked identical to the defect
and were not. The Daisy Seed sockets have a 27.94 mm half-extent, so −30 puts
their fields 2 mm above the body, which is correct. A blanket "move everything
to −12" would have buried both labels inside the socket outline. Symbol extents
come from the embedded `lib_symbols`, per conventions rule 9 — a placed instance
does not record its own size.

**Verified:** netlist identical across `718d5dd..HEAD`, 113 nets and 376 nodes
with the same pins on every one; ERC 0/0/0; parity 0 violations, 0 unconnected
pads, 0 footprint errors; `.kicad_pcb` last changed at `28c54f1` (2026-08-22),
predating every commit under test. Saved as
`2026-08-24-schematic-edits-netlist-identity.txt`. A field carries no
connectivity so none of this *could* have moved a net, but "could not" and "did
not" are different claims and the check costs a second.

**The netlist FILE differs by 144 bytes while the netlist CONTENT does not** —
kicad-cli embeds field positions as symbol properties, so a diff of the file
would have shown a false change. Compare parsed nets, never the raw export.

**My error, and Matt caught it by eye:** I had measured field-to-symbol distance
across all five sheets, got a median of 10.82 mm, called it healthy and dropped
the check. It *was* healthy — for four of them. Aggregating across sheets
drowned a defect that was uniform inside one, where the median was 30.59 mm and
every field exceeded 20 mm. A median over a mixed population hides a uniform
defect in one member of it. The check should have been per-sheet from the start.

**In flight:** nothing. Six ledger records unchanged this session, no fact
touched — this was drawing, not discovery. Both trees clean and pushed.

**Open questions:** three records still open (`bt1-cell-fit` in conflict,
`carbon-capsule-dc-resistance` and `mic-gain-budget` unverified), two of them
closable with the phone in hand and no boards needed. Eight advisory findings
remain in `check_schematic.py`: labels clearing a resistor by 0.59 mm, measured
clear, flagged because they read as touching at plot scale. Cosmetic, and a
judgement call rather than a defect.

**Next step:** unchanged, and now unblocked by nothing at all. Measure the
handset capsule: DC resistance against the 14.5 Ω and 112 Ω thresholds in
`carbon-capsule-dc-resistance`, and output level against the gain budget in
`mic-gain-budget`. Beep out the keypad in the same sitting. That closes two of
the three open records.

## 2026-08-25 12:04 — C21 off the page, and the measurement error underneath it

**Completed:** what Matt reported was one capacitor hanging off a sheet. What it
turned out to be was a text metric that had never been measured, invalidating
every clearance number this project had produced.

- `c831990` — **panel-io's debounce column refitted.** Three identical blocks
  (connector, pull-up, series R, 74HC14 gate, filter cap to ground) repeat every
  59.69 mm at rows 270.51 / 330.20 / 389.89, and A2 is one repeat short. C21's
  lower pin reached 1.48 mm past the frame and the GND flag beneath it sat
  **0.90 mm from the paper edge**. Nothing was wrong with block 3; the pitch was.
  Dropped to 53.34 mm (42 × 1.27), block 1 anchoring, so blocks 2 and 3 rise
  6.35 and 12.70. Bottom-most ink now clears by 3.60 mm. The sheet is on a 1.27
  grid, not 2.54 — the original pitch is 23.5 × 2.54 — and assuming otherwise
  would have thrown the column half a grid out.
- `f0db482` — **20 "advisories" were real collisions.** The checker hedged every
  text overlap as "widths are estimated", and I repeated that hedge back to Matt
  all session as if it meant noise. `VIN_DC` and `PWR_FLAG` share an anchor
  EXACTLY and print as mush. Now graded by interpenetration depth.
- `b86c20b` — PWR_FLAG values hidden, 20 power-symbol texts moved off the
  neighbouring pin rows, **and CHAR_W corrected from 0.72 to 1.17**.
- `365ba12` — 39 label crossings down to 1, in 68 moves across four sheets.
- `8cea8d7` — schematic PDF republished.

**THE CENTRAL FINDING, and it invalidates things I wrote down as fact.** `CHAR_W`
was 0.72 mm per character and carried a comment saying it was measured off a
plot. It was not. Measured at 600 dpi: `'+5V_RAW'` 8.297/7 = 1.185, `'VOUT'`
4.612/4 = 1.153, `'LEG_101_L'` 9.700/9 = 1.078. **A 1.6× underestimate on every
text box in the file.** Consequences:

- `BIAS_E_L` does not clear R51 by 0.59 mm. It runs **3.01 mm into it**.
- The five crossings "fixed" on 2026-08-24 by moving them 2.54 mm were sized
  from this same model, which called a 3 mm overshoot 0.13 mm. **The fix was
  scaled by the error it was correcting**, so it could not have worked.
- Thirty labels crossed, where the tool had reported zero.

A second model error surfaced during the repair: **a label's text direction comes
from `(justify ...)`, not its angle.** `rot 0` and `rot 180` draw identically and
justify decides. The checker derived direction from the angle, so every
horizontal label was modelled on the wrong side of its anchor. The first repair
pass rotated four labels on that model; the plot showed `GAINLEG_L` printed
through C24's `10u`. **That pass was reverted whole and redone from measured
geometry.** The same tool was also using centred boxes for labels in its
text-overlap check and anchored boxes in its crossing check — one label, two
boxes, depending which loop asked.

**The habit that cost this:** the rendered plot showed the crossings correctly at
100 dpi and again at 300, and I overruled it both times with the model, then
wrote the model's answer into `conventions.md` as established fact. A number
feels like evidence and a picture feels like an impression. The plot IS the
artefact being checked; the model is only a claim about it. Rule 3 in
`conventions.md` is now marked REFUTED with the date rather than quietly edited.

**My own errors this session, beyond the above:** I deleted an evidence file as
redundant and restored it (`4bd5375`) — evidence is append-only and pruning it
was mine to propose, not to do. I filtered power symbols by a `power:` lib prefix
and silently skipped three `caryatid:+3V3A` instances, which is exactly the trap
`conventions.md` warns about. And a slice-based self-patch with an empty needle
grew a tool to 17 MB, recoverable only because the file was untracked and cheap
to rewrite.

**Verified:** netlist identical at 113 nets and 376 nodes throughout, ERC 0/0/0,
parity clean, `.kicad_pcb` untouched since `28c54f1` (2026-08-22) — **the boards
on order are unaffected by every commit here.** One proposed move would have
merged `LEG_101_L` into `GAINLEG_L`; the netlist gate caught it and a wire
adjacency check now refuses it a step earlier. Four fixes confirmed on the plot
at 600 dpi rather than in the model.

**In flight:** nothing. Six ledger records unchanged — this was drawing and
tooling, not discovery.

**Open questions:** three records still open (`bt1-cell-fit` in conflict,
`carbon-capsule-dc-resistance` and `mic-gain-budget` unverified), two closable at
the bench. One crossing remains: `AUDIO_OUT_R` against A1 on seed, boxed in on
both sides, and the plot shows the label flags there also overlapping A1's pin
numbers and names — which live in the library definition where no check in this
repo can see them. **That is a known blind spot, not a clean sheet.**

**Next step:** unchanged and still unblocked. Measure the handset capsule: DC
resistance against the 14.5 Ω and 112 Ω thresholds in
`carbon-capsule-dc-resistance`, and output level against the gain budget in
`mic-gain-budget`. Beep out the keypad in the same sitting.

## 2026-08-25 12:29 — Rule 10 written, and the last crossing closed

Short increment on top of the 12:04 entry; three commits.

**Completed:**

- `745bb6e` — **conventions rule 10**, the candidate raised at the previous
  checkpoint: *an empirical constant carries its measurement, or it is a guess
  wearing a lab coat.* Any constant standing in for something physical or
  rendered records the raw observation (what was measured, the sample, the
  number before rounding), because a constant that merely *claims* provenance
  cannot be audited. `CHAR_W = 0.72 # measured off a plot` was not measured, and
  the comment is precisely what let it survive: the line reads as settled. Scope
  is bounded so it does not become a demand to measure grid pitches, which come
  from the file and are exact. It also carries the tie-break: **when a model and
  a rendering disagree, measure the rendering.** Rule 3's REFUTED note now points
  here instead of restating it.
- `be52a15` — **AUDIO_OUT_R cleared, the last of the 39.** Three coordinated
  edits: the `power:GND` at (68.58, 123.19) turned rot 180 → 0, its Value text
  moved 1.27 mm with it, and the label plus its wire moved x 71.12 → 67.31.
  The label is 11 characters like its sibling `AUDIO_OUT_L`, which is anchored
  at 67.31; matching it clears A1 by 1.10 mm and makes the drawing agree with
  itself rather than with a preference.
- `50622bd` — schematic PDF republished.

**A diagnosis I got wrong, and the correction is the useful part.** I called the
GND obstruction a modelling artefact: `lib_extents()` builds a box symmetric
about the origin, and `power:GND` has all its ink on one side of the pin, so it
invents 2.54 mm of empty space. That defect was real and is now fixed
(`lib_box()` / `placed_body()`, asymmetric and rotation-aware, verified against
the plot at angle 0 **and** angle 180). **But fixing it did not dissolve the
obstruction.** That flag is placed at rot 180, so with rotation handled correctly
its ink genuinely occupies 120.65..123.19 — the corridor the label needed. The
symmetric box had been right there for the wrong reason, and the plot agrees:
the triangle measures 120.44..122.13. Being right for the wrong reason is not the
same as being right, and it only showed up because the transform was checked
against a rendering at two angles instead of one.

**A third filter leak.** The crossing check was skipping every `#` reference, the
same filter already pulled out of the border test. A label landing on a ground
flag was invisible to the check whose job it was, which is why the D12/GND-arrow
overlap on panel-io had to be found by a different tool. Removed. With power
symbols now included **and** accurate boxes, the report is identical to the
conservative model: **0 findings either way, across all five sheets.**

**Recorded, not fixed:** a `global_label`'s drawn flag is wider than its text
box, measured 1.18 mm on `AUDIO_OUT_R`. Every box in the checker measures text,
so a label can graze something the check calls clear. Not encoded, because the
overhang is a constant of KiCad's rendering rather than of the file, and guessing
it would be exactly the mistake `CHAR_W` was. Rule 10 applied to itself.

**Verified:** netlist identical at 113 nets, ERC 0/0/0, parity clean,
`.kicad_pcb` untouched since `28c54f1`. On the plot the label's flag now ends at
81.36 against A1's edge at 81.28 and A1's pin number sits clear at 82.63; before
the fix the flags covered the pin numbers outright.

**In flight:** nothing. Six ledger records unchanged; no fact touched.

**Open questions:** three records open (`bt1-cell-fit` conflict,
`carbon-capsule-dc-resistance` and `mic-gain-budget` unverified), two closable at
the bench. Three advisory near-misses remain at 0.50 mm (`SW1_F`/`SW2_F`/`SW3_F`
against R35/R37/R39), which are cosmetic and measured, not defects.

**Next step:** unchanged. Measure the handset capsule: DC resistance against the
14.5 Ω and 112 Ω thresholds, output level against the gain budget, and beep out
the keypad in the same sitting. That closes two of the three open records and
needs no boards.

## 2026-08-25 23:20 — First bench session: the capsule is an electret

The first entry this session that is discovery rather than drawing. Three
commits, and the ledger gained two records.

**Completed:**

- `fb23f51` — **loa's handset transmitter measured and identified: ELECTRET.**
  1.75–1.77 kΩ one probe polarity, 1.05–1.06 kΩ reversed, steady, no jump when
  tapped, measured at the capsule terminals out of circuit. New record
  `loa-handset-capsule`, status `confirmed`.
- `d531d13` — **`mic-configurations.md` gains a fourth branch.** The tree said
  "open circuit → ELECTRET", true only of a bare element, which is a capacitor.
- `5fbc09e` — **`loa-keypad-matrix` created**, saying what to measure before
  anything is measured. Evidence deliberately empty.

**THE IDENTIFICATION RESTS ON POLARITY, NOT MAGNITUDE.** A resistor reads the
same both ways and so does a coil, so an asymmetric reading is a semiconductor
junction and the element is neither carbon nor dynamic whatever band the numbers
fall in. This mattered: the reading matched **none** of the tree's three
branches, so a reader following the documented procedure would have concluded
"not any of these" rather than "electret". The test that actually worked was the
one that does not depend on the number landing where you expected.

**What it closes and what it does not.** Jumpers go to the electret legs, JP1
and JP4 on `1-2`, biased through R51/R53. `carbon-capsule-DC-resistance` stops
being a question about this phone, since R52/R54 only carry capsule current with
a jumper on carbon and an electret never sits across them — but its status is
**unchanged at `unverified`**, because no carbon capsule has been measured and
the record still governs any fitted later. `mic-gain-budget` likewise stays
`unverified`: knowing the type fixes which range applies (56–200×), not whether
the board's ×101 lands inside it, which rests on an unmeasured output level.

**A figure I had to walk back inside a day of writing rule 10.** I computed the
electret bias current as 835 µA from the 1.75 kΩ reading. That is wrong the same
way `values.md`'s 1.5 mA is wrong: `values.md` used 3.3/2k2, treating the capsule
as a short, and I used an ohmmeter reading as an operating resistance. **A JFET
is not a fixed resistor**, and its DC point at 3.3 V is not what a meter probes
at ~0.3 V. The honest statement is a bound: under 1.5 mA per channel, so the
3V3A budget overstates this load by an unknown amount. Closing it needs V across
R51 with the board powered, which is not a bench item. Recorded in the record as
`bias_current_is_bounded_not_measured` so the bound cannot be read as a value.

**Two instrument traps, and they are the same trap.** The capsule terminals were
under hot-melt glue and the first attempts probed through it; glue is an
insulator, so a partial contact reads **high**, and high is the comfortable end
of every threshold in the carbon record. Had this been carbon, probing through
glue could have passed a part that was not safe. The keypad record carries the
matching one before it can bite: the continuity **beeper** is the wrong
instrument, because telephone keypads are conductive rubber on carbon pads that
close at hundreds of ohms to a few kilohm, and a beeper triggering below ~50 Ω
stays silent on a healthy key. **In both cases the instrument's default setting
hides the reading rather than reporting it, and in both cases the failure is
silent and reassuring.**

**In flight:** nothing. Both trees clean and pushed.

**Open questions:** five records open. `bt1-cell-fit` in conflict;
`carbon-capsule-DC-resistance` unverified and now dormant for this phone;
`mic-gain-budget` unverified pending an output level; `loa-keypad-matrix`
unverified pending the bench; a bias-current measurement that needs the boards.

**Next step:** two bench items, neither needing boards. **Capsule output level**
in mV rms at close-talk distance, which is the number `mic-gain-budget` rests
on. And **beep out the keypad** to the template in `loa-keypad-matrix`: twelve
key/pair/resistance rows, the conductor count, and whether any reading changes
with probe polarity. Log the WORST closed resistance, not a typical one.

## 2026-08-31 — loa keypad beeped out: matrix, connector and anchor all closed

**Completed:** `loa-keypad-matrix` goes `unverified` → **`confirmed`**, and
closes three separate questions in one bench session.

- **The matrix is a plain 4×3.** Seven conductors, twelve distinct pairs, four
  rows at three keys each and three columns at four. Closed resistance 10.6 to
  17.5 Ω, worst key `5`, against a 5 kΩ threshold. Clears by two and a half
  orders of magnitude: no pull-down, no stronger drive, no glue logic. loa's
  pin map stands as written.
- **The carbon-pad premise did not hold.** The record warns at length that a
  continuity beeper would stay silent on a healthy key. Every key here is a
  metallic closure near 15 Ω and the beeper would have worked. Warning kept
  verbatim and annotated: it describes a hazard, not this part.
- **The connector is JST ZH 1.5 mm**, refuting the 1.27 mm Molex Picoflex
  derivation of 2026-08-26. The proof is not that a bought ZH stub fitted, it
  is that the whole beep-out ran through it on all seven conductors, which a
  wrong-pitch part cannot do.
- **Pin 1 anchored** to the `PX` silkscreen, with the centring caveat closed by
  observation and a consistency check that passes.
- Evidence: `discovery/evidence/2026-08-31-keypad-matrix-beepout.txt`.
- loa `docs/design/12-phone-build.md` regenerated from the record.

**In flight:** nothing. The sheet is complete and no measurement is outstanding.

**Open questions:**

- **A decision, not a measurement: cross the columns in the harness or in
  firmware.** Rows run straight through to D0–D3. Columns are inverted, and
  reversing three things is swapping the outer two: cross header positions 5
  and 7, leave 6. Or wire straight and reverse the column index in the scan.
  Either is correct. Doing neither shows up as key `1` reading as key `3`.
- Three checks were **not performed** and are logged as not performed rather
  than assumed: the baseline sweep among the four non-black conductors, lead
  and clip resistance, and a polarity reversal for diodes. None changes the
  verdict at a 17.5 Ω worst case against a 5 kΩ threshold.
- The **original ribbon is unexplained** and does not gate anything. Seven
  conductors at 1.5 mm should measure ~10.5 mm overall, not the 9.0 mm
  recorded. Either 9.0 was a centre span or "mass terminated" was mis-observed.

**Why the wrong connector answer survived, worth keeping:** the 9.0 mm reading
fits 1.27 mm as an overall ribbon width (8.89) and 1.5 mm as a pin-centre span
(9.00) equally well, and the datum was never recorded. The 11.5 mm housing
width does discriminate, points at ZH, and was set aside as the inferior
method. The first answer was right and was argued away.

**Next step:** decide the column crossing, then wire a ZH-to-J11 harness and
record the choice under `for_loa_the_build` in `loa-keypad-matrix`.

## 2026-09-20: switch lamp current measured, and the shunt drop that nearly ate it

**Completed:**

- **Bringup A7.6 passed: the switch lamp draws 28.5 mA at 5.00 V**, 5.6 mA at
  3.00 V. 10.2 Ω shunt, Fluke 101 on DC mV, Jesverty supply in CC at a 100 mA
  limit, no board involved. This **closes one of the three unattributed lines
  in the 5 V budget**, leaving the mic bias pair and the three connector 5 V
  pins. Evidence in `2026-09-20-switch-lamp-current.txt`, record updated in
  `panel-latch-switch`.
- **The internal limiting is a plain ~87.5 Ω series resistor, Vf ~2.51 V**, not
  a constant-current driver. Three points fit that model within 1%, the
  residual being the LED's own Vf rising with current. ⇒ **A voltage-range
  marking means the part tolerates the range, not that the current is held
  across it.** Here it tracks the rail almost 8:1 from 3 V to 6 V, so the budget
  line is only meaningful quoted against a rail voltage. That qualifies what
  "internally limited" was taken to promise on 2026-09-05; it does not weaken
  the compatibility pass, which turned on the part tolerating 5 V, and it does.
- **It does not move the runtime table.** 28.5 mA makes the lamp the largest
  indicator load on the rail, ahead of the RGB with all three dies lit, and it
  is lit whenever the instrument is on. But the 150/250/350 mA scenario rows are
  top-down estimates, not a tally: with the lamp in it the tally reaches ~141 mA
  in electret mode and ~163–183 mA in carbon against a 250 mA typical row, so
  the lamp lands **inside** the existing headroom. Runtime figures unchanged.
- **`indicators.md` predicted this correctly and the prediction is now closed.**
  It said, conditionally, that a plain series resistor would give "roughly 75%
  of the current" at 5 V against the 6 V 4×AA reference. It is a plain series
  resistor and the real ratio is 71%. No action, no board change.
- **Five documents corrected off the ledger**, all of which described a 3–9 V
  lamp: `values.md`, `indicators.md`, `sourcing.md`, `power-sheet.md`,
  `capture-checklist.md`. The part in hand is 3–6 V. That discrepancy was
  recorded on 2026-09-06 as "no action"; it became worth fixing once the
  measurement was being written into the same paragraphs.

**🔴 The lesson, and it is a runbook change:** **the shunt drop is not
negligible, and the load never sees the setpoint.** The first reading was taken
at a 5.00 V setpoint, where 258 mV across the shunt left only **4.74 V** on the
lamp, reading **11% low**. It was caught by the numbers not fitting, then fixed
by setting the supply to 5.29 V so the drop left exactly 5.00 V. `bringup.md`
A3 now carries this as a standing warning beside the "do not put the Fluke where
the shunt is" one: add the drop back into the setpoint and re-read, or record
the voltage the load actually saw, but never quote the setpoint.

**In flight:** nothing. No board was powered; this was a component check.

**Open questions:**

- ✅ **Lead resistance: closed the same day, and it was worth the ten seconds.**
  Raised as an open question because clip leads usually run 0.1–0.3 Ω, which
  against the 10.2 Ω shunt would have put every current **2% low**. Probes
  shorted, the Fluke reads **0.0 Ω**, which is a bound rather than a zero: the
  101 resolves 0.1 Ω, so the leads are under ~0.05 Ω, at most 0.5%. **The shunt
  is 10.2 Ω and not a lead-inflated 10.0, so no figure changes and 28.5 mA
  stands.** The least certain term is now the shunt value itself, read at the
  bottom of a 600 Ω range where the meter's "+ N digits" term dominates. A few
  percent, which bounds nothing a budget line cares about.
- The 6.00 V figure of 39.9 mA is **extrapolated**, not measured. It is the top
  of the part's marking and only feeds the brightness comparison.
- **`docs/status.md` still has a RESUME block dated 2026-09-01** that predates
  every component check in Phase A. It is not wrong, but it is drifting, and
  this file has been burned by exactly that before.

**Next step:** the remaining A7 component checks, which are the two LED
questions: **A7.2/A7.4** common anode on J4 and J12 by diode test, and **A7.3**
whether the charge LED's green die is AlGaInP or InGaN, which matters because J4
runs from `VOUT` down to 3.0 V. Then **A7.5**, characterising the test electret
before it is trusted to prove anything else.

## 2026-09-22: handset colour map, transmitter polarity, and a placeholder 7.8x out

**Completed:**

- **loa's handset is fully mapped at the RJ9.** Outer pair **yellow and black**
  is the transmitter, **yellow positive**; inner pair **red and green** is the
  receiver. The 2026-08-25 record established that the *outer pair* was the mic
  but never wrote down which conductors that meant, and 4P4C cord colours denote
  position, not polarity, so there was no convention to fall back on.
- **Polarity settled functionally, not by convention.** Biasing through a
  measured 2174 Ω from 3.3 V: yellow on the resistor gives a **2.882 V** drain at
  **192 µA**; black gives **0.683 V at 1.2 mA**, which is a silicon junction
  forward drop and not an operating point at all. It independently agrees with
  the resistance asymmetry, where the red probe on yellow gave the higher
  reading. Two methods, same answer.
- **The inner pair is symmetric**, 0.821 kΩ both ways. Only one direction was
  taken in 2026-08-25, so nothing had ruled out a second semiconductor there.
- **Corroborates the month-old jack readings to 0.4% and 0.2%** (inner 0.824 →
  0.821, outer 1.054 → 1.056), which also settled that both sets are kilohms.
- 🔴 **The electret bias figure in `values.md` was 7.8× too high.** It carried
  1.5 mA per channel, which is `3.3 V / 2k2`: the current with **the capsule
  treated as a short**. The capsule presents ~15 kΩ at its operating point, so
  the 2k2 drops 0.42 V of 3.3 V. **Measured: 192 µA**, 384 µA for the pair
  rather than 3.0 mA.
- **A trap removed from the runbook.** A6.7 said "electret red to pin 1 or 2,
  black to pin 3", written for the bench capsule. **The handset's red lead is the
  earpiece**, so following it would have wired the receiver into the mic input
  and left the microphone unconnected. A6.7 now names both parts and carries a
  colour table.
- **`values.md` had a second stale bullet**, unrelated to today's reading: the
  mic bias pair was still described as blocked on *measure the handset capsule*,
  a month after the capsule was identified as an electret. The 41 mA carbon
  figure is not live for this build, since JP1/JP4 sit on `1-2` and R52/R54
  never carry capsule current. Corrected and labelled.
- **`mic-gain-budget` gains a quantified lever.** With the operating current
  known, R51 can be sized deliberately: about **13 dB is available at 10k**
  against the 2k2 fitted, before the drain gets tight. Recorded as a lever, not
  a recommendation, since that record is still `unverified`. Also noted that its
  `capsule_output_at_1pa` range carries **no load condition**, which is the
  condition the board's 2k2 would have to be compared against.
- **`bench-instruments` gains the first real check of the ohms function**: a 1%
  2k2 read 2174 Ω, bounding the meter to 0.2-2.2% low on the 6 kΩ range. One
  part at one point is not a calibration and cannot separate meter error from
  part error, and it is recorded as such.

**🔴 The pattern worth keeping:** the record said this measurement **needed the
board**. `what_would_close_it` read "Voltage across R51 with the board powered
... Needs the boards, so it is not a bench item." That is false, and 3.3 V
through a 2k2 into the real capsule *is* R51's circuit. The claim was never
examined; it was assumed because the quantity had been **named after a board
reference designator**. Naming a measurement after the part it will eventually
sit beside is what made it look like it required that part.

**In flight:** nothing. No board was powered.

**Open questions:**

- **A7.5 is still untouched.** This was loa's handset, not the bench reference
  electret, and they are different jobs: the bench capsule's purpose is to prove
  the board, so it still wants characterising before it is trusted.
- **821 Ω at the jack against 145.3 Ω at the element**, on the receiver path,
  now confirmed twice. Roughly 680 Ω sits inside the handset between the two.
  `loa-handset-capsule` says 145.3 Ω is "the figure to use if the receiver is
  ever driven as an output", and **loa will drive it from the RJ9**, where it
  looks like 821 Ω. Not chased: it touches nothing in the mic path.
- The 13 dB R51 ladder **assumes the JFET stays in saturation** as the drain
  comes down. Supported at 2.88 V, unverified below it.

**Next step:** A7.2, A7.3 and A7.4, the three LED checks, all diode-test work on
the bench. Then A7.5.

## 2026-09-22: J4 bicolour verified, and a ticked box that had not been done

**Completed:**

- **A7.2 and A7.3 both pass. The J4 bicolour is verified**, closing an
  `UNVERIFIED` carried in three documents since sourcing. Common anode confirmed
  by diode test; green **Vf 2.322 V** at 5 V and **2.234 V** at 3 V, red 1.862
  and 1.810. New ledger record `j4-charge-led`, since neither LED had one.
- **The green die is AlGaInP**, 0.7 V clear of the InGaN true green at 3.0-3.2 V
  that would have disqualified it. This was the whole question, because J4 hangs
  on `VOUT` and not a regulated rail. **It still lights at a 3.00 V supply**, at
  0.77 mA, which is the flat-cell acceptance test `sourcing.md` asked for.
- **A second, independent confirmation came free.** The diode test *lit the green
  die*. A handheld supplies only ~2.4 V on that range and cannot light a 3.0 V
  InGaN part, so A7.2 corroborated A7.3 before any voltage was read.
- 🔴 **This measurement is the only information that exists about the part.** The
  Amazon listing was never readable, so nothing was ever quoted from the vendor:
  not the forward voltages, not the package, not the pinout. `datasheets.md` now
  says the question was closed by measurement because that was the only way it
  could be closed.

**🔴 New finding, which nothing in the documents anticipated: the amber drifts
toward red as the cell drains.** Green's higher forward voltage eats
proportionally more of a shrinking headroom, so green fades 2.4× across the
cell's life while red fades 2.0×, and the red-to-green current ratio goes from
**1.25 on a full cell to 1.55 on a flat one**. Two consequences: the R9/R10 trim
is **not a fixed adjustment**, so trim at mid-cell rather than on a freshly
charged pack; and **resistors cannot fully fix it**, because it is driven by the
Vf difference against a falling rail, not by the resistor ratio. Harmless, and
arguably it reads correctly. Recorded so it is not rediscovered as a fault. It
was only visible because the part was measured at **both ends** of the rail,
which is exactly what `sourcing.md` asked for: "Test it at 3.0 V, not 4.2 V."

**🔴 A ticked checkbox that had not been done.** `capture-checklist.md` carried
*"[x] ~~Measure the RGB forward voltages and confirm common anode.~~ **Done**"*
with Vf figures against it. Those figures are **the vendor's specification**,
quoted as such in `sourcing.md` under "Specification from the vendor". Reading a
listing is not measuring a part, and the checkbox said *Measure*. **Unticked**,
with the reason written in, and A7.4 stands as genuinely outstanding. This is
the same failure the project keeps catching: a vendor claim hardening into a
measured fact through repetition, here through a tick.

**A trap in A7.4 itself, recorded before anyone hits it:** a handheld's diode
test supplies only ~2.4 V, so the RGB's **3.0-3.2 V green and blue dies will read
OL even when good and correctly oriented**. A7.2 and A7.4 both say "diode test",
and followed literally that produces "green is dead". Use the bench supply
through a series resistor. The J4 part was measurable on diode test only because
its green turned out to be 2.322 V.

**Corrections off the ledger:** `indicators.md` said "2.1 mA per die" from an
assumed 2.1 V green; measured it is **1.88 mA**, ~10% optimistic, and the 4.2 mA
amber total survived by accident since red's surplus covers green's shortfall.
`sourcing.md`, `status.md` and `datasheets.md` all carried the part as
unverified.

**In flight:** nothing. No board was powered.

**Open questions:**

- **Diffused is untested on the J4 part**, and it is a *visual* check, not an
  electrical one. Both dies lit together must give one amber lens, not a red dot
  beside a green dot.
- **Legibility at 3.0 V is also unjudged.** The meter proves 0.77 mA flows; it
  does not prove the LED can be *read* on a flat cell, which is the actual
  requirement.
- **A7.4, the RGB, is not started**, and its checkbox is now correctly unticked.
- **A7.5, the bench reference electret, is still untouched.**

**Next step:** A7.4 on the four-pin RGB, using the supply rather than the diode
test, then the two visual checks on the J4 part. Then A7.5.

## 2026-09-23: A7.4 done, and two corrections in the same direction

**Completed:**

- **A7.4 passes.** RGB is **common anode** (diode test, red probe on the common
  pin) and **diffused**. Vf at 5 V: red 1.932, green 2.454, blue 2.607, through a
  measured 990 Ω. New ledger record `j12-rgb-led`. **The J4 bicolour is diffused
  too**, closing the fourth and last of `sourcing.md`'s requirements for it, and
  the only one a meter could not settle.
- **The part-identity question dissolved.** `sourcing.md` records CHANZON
  `B01C19ENFK` and then says to buy the diffused AliExpress version "at the same
  specification", so which listing supplied the part was unknown. **The bag label
  reads R 2.0-2.2 V and G/B 3.0-3.2 V, which is the spec the repo already
  carried.** Whichever listing it came from, the recorded figures describe what
  is in hand.
- **A7.2/A7.3/A7.4 are all now complete**, plus both visual checks.

**🔴 Two claims withdrawn, both mine, both the same error.**

The bag labels read 3.0-3.2 V for *both* greens, which contradicted two things
written into the ledger and six documents on 2026-09-22:

1. *"The J4 green die is AlGaInP, 0.7 V clear of InGaN."*
2. *"The RGB's vendor spec is wrong by 0.4 V on green and blue."*

**Both rested on extrapolating a logarithmic diode fit from two low-current
points out to the 20 mA rating.** A log-only fit omits series resistance, which
for an InGaN die is 10-30 Ω: it contributes a linear IR term that dominates at
20 mA and is invisible at 2 mA. Restore it and the measurements agree with the
labels. **The labels are probably right.**

The stated validation was wrong too. The argument was that red landing inside
the vendor band proved the method sound. **It proves it for red alone**, red
being the low-series-resistance case that was never in doubt. A check that only
passes on the case not in question is not a check.

**A7.3 still passes, and the reason matters.** It never depended on the
chemistry. The real question was measured directly: **green lights at a 3.00 V
supply through 990 Ω, drawing 0.77 mA.** That is J4's circuit at the cell's end
of life, at the operating point, with no model. *A directly measured operating
point survived; an inferred material property did not.* The runbook's A7.3 has
been rewritten from "is the die AlGaInP" to "does the green still light on a
flat cell", because the original phrasing invited exactly this. The amber-drift
finding is unaffected, for the same reason.

**🔴 And the same error was already in `values.md`, pointing the other way.**
Its "the RGB cannot be driven from a 3V3 GPIO" table **uses forward voltages
quoted at 20 mA to reason about a circuit that would run at one or two
milliamps**. At the real operating point green gets ~2.2 mA and blue ~1.7 mA,
dim but not the "0.45 mA and 0.15 mA, invisible, no resistor value fixes it"
that is written there. **The decision stands** (an STM32 sinks harder than it
sources, the 5 V rail is stiffer, currents are defined); the argument does not.

**An LED's Vf is not a constant, and a datasheet figure carries its test current
with it.** That is the durable lesson, and it caught two documents and me.

**In flight:** nothing. No board powered.

**Open questions:**

- **The green dies' chemistry is unresolved and deliberately left so.** Settle
  it, if ever worth it, at **20 mA in CC**, the label's own condition, with no
  resistor and no extrapolation. It does not gate anything: J12 runs from 5 V
  with headroom either way, and J4 was settled functionally.
- **`values.md` and `sourcing.md` disagree on the RGB currents** and did before
  any of this: 5.9/6.7/6.3 against 4.80-5.20/4.83-5.50. They differ on whether
  to allow the GPIO's 0.35 V output-low drop. Both defensible, one should be
  picked. Not resolved.
- **Legibility of the J4 green at 3.0 V** is still a judgement by eye, not made.
- **A7.5, the bench reference electret, remains untouched.**

**Next step:** A7.5, which is the last A7 item and the one the runbook says to do
first, since it is the reference everything in Stage 8 leans on.

## 2026-09-23 (evening): the supply was lying, the label was right, and one mistake explains everything

**Completed:**

- 🔴 **The bench supply's CC is offset by +3.53 mA with unity gain.** Set 2 / 5 /
  10 mA delivers **5.98 / 8.53 / 13.53 mA**, and the 5-to-10 pair gives a slope
  of **exactly 1.000**. Two permanent consequences: **it cannot deliver below
  ~3.5 mA in CC whatever you set**, and **a wanted current must be set 3.5 mA
  low**. The floor is soft, not sharp: the 2 mA point ran +0.45 mA high and
  wandered 5.2-6.8 mA. This closes the `minimum settable current limit` item
  that `bench-instruments` has carried since the supply arrived.
- **That explains the anomaly that started it.** The green read 2.54-2.59 V at a
  *set* 2 mA against 2.454 V at 2.57 mA under CV: voltage up as current down,
  which a diode cannot do. **It was never at 2 mA, it was at about 6.** One LED,
  no unit variation, nothing wrong with either reading.
- **The green chemistry is settled at rated current: Vf 2.844 V at 18.15 mA**,
  extrapolating to ~2.87 V at 20 mA. An AlGaInP green would read 2.50-2.65 V
  here. **It is InGaN and the bag label is right** to within about 0.13 V.
- **The meter's ohms gain error is now a figure, not a bound: ~1.1% low across
  two ranges**, from three parts landing within **0.18% of each other**. It is
  the tightness that is the evidence. Implies the 10.2 Ω shunt is nearer 10.31
  and every current derived from it is ~1.1% low: the switch lamp becomes
  28.2 mA rather than 28.5. Inside the few percent already recorded, so nothing
  moves, but the caveat is closed.

**The scorecard on my own claim, at 20 mA:**

| | |
| --- | --- |
| 2026-09-22 claim | 2.66 V, **wrong, 0.21 V low** |
| measured | **~2.87 V** |
| bag label | 3.0-3.2 V, ~0.13 V high |

The withdrawal was correct. The claim was wrong in method *and* in number, and
the kernel it contained, that the label is slightly optimistic, is a **third**
the size claimed and changes nothing.

⚠️ **Even the corrected fit was optimistic.** Six points predicted 2.894 V at
this current against a measured 2.844, a **50 mV** miss where every earlier
point landed within 8 mV. The curve flattens at the top more than the model
expects. **Extrapolation remains the weak step even after the missing physics is
put back**, which is the second time in two days it has been the thing that
failed.

**🔴 One mistake explains all of it.** `values.md`'s 3V3 table, both documents'
RGB current tables, and my withdrawn claim are the *same error*: **a forward
voltage used at a current other than the one it was quoted at.** Vf is not a
constant, and a datasheet figure carries its test current with it.

That also **resolves the `values.md` / `sourcing.md` disagreement** flagged
yesterday. Recomputed from measured Vf at the current each channel actually
converges to:

| die | measured | `values.md` | `sourcing.md` |
| --- | --- | --- | --- |
| red | ~5.2 mA | 5.9 ✗ | 4.80-5.20 ✅ |
| green | ~6.8 mA | 6.7 ✅ | 4.83-5.50 ✗ |
| blue | ~6.4 mA | 6.3 ✅ | 4.83-5.50 ✗ |

**Neither document is right about all three.** `values.md` is right on green and
blue *by cancellation*, having omitted the 0.35 V sink drop as well, and high on
red. `sourcing.md` is right on red and low on the other two. Being right for the
wrong reason is not being right. Both tables corrected, and `sourcing.md` now
carries two Vf columns so the distinction cannot be lost again.

**J4 returns to `confirmed`.** The conflict was between my claim and the label;
my claim is dead on independent evidence. ⚠️ **That part's own green was not
re-measured**, so its chemistry stays *unmeasured* rather than inferred by
analogy from a different part. It gates nothing: A7.3 passed functionally.

**In flight:** nothing. No board powered.

**Open questions:**

- **The J4 green's chemistry is unmeasured** and deliberately not inferred.
- The supply's **set resolution and published accuracy** are still unread; only
  the listing title was ever retrieved.
- **Legibility of the J4 green at 3.0 V** remains a judgement by eye, not made.
- **A7.5, the bench reference electret, is still untouched** and is now the only
  outstanding A7 item.

**Next step:** A7.5. Note the new constraint when planning it: **use CV with a
measured series resistor, not CC**, for any current below about 20 mA.

## 2026-09-23 01:18: checkpoint. Four A7 component checks closed, two instrument errors quantified, three of my own claims withdrawn

**Completed:**

- **`panel-latch-switch`** A7.6. Switch lamp **28.5 mA at 5.00 V**, 5.6 mA at
  3.00 V. Internal limiting is a plain ~87.5 Ω resistor, Vf ~2.51 V, not a
  current source, so the current tracks the rail ~8:1 across the 3-6 V marking.
  Closed one of three unattributed lines in the 5 V budget. Lead resistance
  measured 0.0 Ω the same day, closing its own caveat.
- **`loa-handset-capsule`**. RJ9 colour map settled: outer **yellow/black** is
  the transmitter with **yellow positive**, inner **red/green** the receiver,
  symmetric. Polarity established functionally, not by convention. Electret
  operating current **192 µA**, replacing a derived 1.5 mA that was **7.8×**
  high. The record's claim that this needed the board was false and is annotated.
- **`j4-charge-led`** (new) A7.2, A7.3. Common anode, diffused, and the green
  lights on a flat cell at **0.77 mA from a 3.00 V supply**. Closed an
  `UNVERIFIED` carried in three documents since sourcing. New finding: **the
  amber drifts toward red as the cell drains**, ratio 1.25 → 1.55, so the
  R9/R10 trim is not a fixed adjustment and resistors cannot fully fix it.
- **`j12-rgb-led`** (new) A7.4. Common anode, diffused, Vf **2.844 V at
  18.15 mA** → InGaN, bag label right to ~0.13 V. Resolved the standing
  `values.md`/`sourcing.md` current disagreement: red ~5.2, green ~6.8, blue
  ~6.4 mA, and **neither document was right about all three**.
- **`bench-instruments`**. Supply CC is **offset +3.53 mA at unity gain**, so it
  cannot deliver below ~3.5 mA and a wanted current must be set 3.5 mA low.
  Meter ohms **gain error ~1.1% low across two ranges**, from three parts within
  0.18% of each other.
- **`mic-gain-budget`**. R51 quantified as a lever: ~**13 dB** available at 10k.
  Stays `unverified`; the SPL assumption and capsule output are still unmeasured.
- **Three claims of mine withdrawn**, all one error: *a forward voltage used at
  a current other than the one it was quoted at*. The same error was already in
  `values.md`'s 3V3 table and both RGB current tables.
- **Documents corrected off the ledger**: `values.md`, `indicators.md`,
  `sourcing.md`, `power-sheet.md`, `capture-checklist.md`, `datasheets.md`,
  `status.md`, `bringup.md`. A7.3 rewritten from "is the die AlGaInP" to "does
  the green still light on a flat cell", because the original phrasing invited
  the error. `capture-checklist.md`'s RGB item was unticked (it recorded a
  vendor spec as a measurement) and re-ticked once actually done.

**In flight:** nothing. No board was powered at any point this session; every
measurement was a component on the bench.

**Open questions:**

- **A7.5, the bench reference electret, is untouched** and is the only
  outstanding A7 item. New constraint from tonight: use **CV with a measured
  series resistor, not CC**, for any current below ~20 mA.
- **The J4 green's chemistry is unmeasured**, deliberately not inferred by
  analogy from the RGB. It gates nothing.
- **Legibility of the J4 green at 3.0 V** is a judgement by eye, not made.
- **Receiver reads 821 Ω at the RJ9 against 145.3 Ω at the element**, confirmed
  twice. ~680 Ω sits inside the handset. Matters only if the receiver is ever
  driven as an output, which loa would do from the RJ9.
- The supply's **set resolution and published accuracy** are still unread.
- `docs/status.md` still carries a **RESUME block dated 2026-09-01** predating
  every Phase A component check.
- Pre-existing and untouched this session: **`loa-hook-switch`** and
  **`charger-input-voltage-thermal`** are both `in-progress`.

**Next step:** Run **A7.5**. Characterise the bench test electret before it is
trusted: DC resistance across its two pigtails **both ways**, expecting a finite
kΩ that differs by direction (the integral JFET), per
`discovery/findings/bench-test-electret.yaml`. Then confirm polarity by biasing
it through a measured ~2k2 from 3.3 V in **CV** and reading the drain voltage,
the same rig that gave the handset capsule 192 µA. No board required.

## 2026-09-23: A7.5 closed, and all six A7 checks are done

**Completed:**

- **`bench-test-electret` goes `unverified` → `confirmed`**, closing A7.5 and
  with it **every A7 component check**. Nothing in Phase A's component list is
  outstanding, and no board was powered to get there.
- 🔴 **There are two bench capsules, not one.** The record described a single
  article. In hand: the **small pigtailed B0FRLZLH2G** it describes, and the
  **uxcell B01F5592EO**, which this record had said *"DO NOT BUY IT"*. It was
  bought anyway. **The verdict's reasoning is untouched**: both are bare
  two-terminal electrets, identical on the axis that decides correctness, and
  pigtails beat pads on a bench. One thing it did not anticipate, in mild
  qualification: **a second independent article separates a board fault from a
  capsule fault at E8**, which one capsule cannot do.
- **Test A, both capsules pass.** Small 1.397 k / 1.154 k, large 1.286 k /
  0.828 k. Finite kilohms, clearly asymmetric, so both are electrets with an
  integral FET. ⚠️ The large one's readings are **unattributed**: no colour, no
  longer lead, so the magnitudes are recorded without knowing which pad the red
  probe sat on.
- **Test B on the small capsule, in R51's own circuit.** 3.30 V through a
  measured 2174 Ω: **drain 2.558 V, 339 µA**, CV confirmed at 3.301.
  **Red is positive**, by measurement rather than convention.
- **One reading settled the polarity and the reverse was not needed.** A
  forward-biased junction at 339 µA would sit near 0.6 V, not 2.558. The
  handset needed its reverse taken because the failure mode there was a 0.683 V
  junction drop that had to be seen; here the working orientation was hit first
  and is unambiguous alone.
- **The resistance test predicted the polarity, two for two.** Meter red on the
  positive terminal gave the higher reading on both the handset (yellow,
  1.798 k) and this capsule (red, 1.397 k), each confirmed functionally
  afterwards. Recorded **with its sample size**: two is a prior that has paid
  off twice, not a law.
- **The large capsule's negative pad is identified but not measured.** Matt
  spotted metal legs running from one pad to the capsule body, which is the can
  bond and makes that pad negative. Logged as an observation, not a reading.

**🔴 What "proved" means here, stated in the runbook so nobody arrives at E8
believing otherwise.** A7.5 established four things: that it is genuinely an
electret, which lead is positive, its operating point, and a baseline. **It did
not establish that the capsule produces usable signal.** That needs the board or
a scope, the bench cannot answer it, and no claim is made.

**Also:** 339 µA does **not** go into `values.md`. That budget line stays at
192 µA because the **handset capsule is what ships**; the bench electret never
leaves the bench. Putting it in the budget would be the same class of error as a
datasheet figure quoted at the wrong condition.

**In flight:** nothing. No board powered.

**Open questions:**

- **The large capsule's can bond is unconfirmed.** Ten seconds with the meter:
  probe each pad to the can rim, the legged one should read near 0 Ω. It would
  also **attribute** its Test A readings, and it predicts meter-red on the
  non-legged pad gives the higher 1.286 k, making the polarity rule three for
  three.
- The large capsule has **never been biased** and needs leads soldered first.
- **J4 green's chemistry** unmeasured; **J4 green legibility at 3.0 V** unjudged.
- Receiver reads **821 Ω at the RJ9 against 145.3 Ω at the element**.
- `docs/status.md` **RESUME block still dated 2026-09-01**, now a full phase of
  component checks out of date.
- Pre-existing, untouched: `loa-hook-switch` and `charger-input-voltage-thermal`
  are both `in-progress`.

**Next step:** Phase A's component work is finished, so the next move is a
decision rather than a measurement: **update `docs/status.md`'s RESUME block**,
which is the first thing read when picking this project up cold and now predates
every A7 result. Then Phase B, the first board checks, which is where a board
gets powered for the first time.

## 2026-09-23: status.md brought current, and the project has a scope

**Completed:**

- **`docs/status.md`'s RESUME block rewritten** and redated from 2026-09-01. It
  was a full phase of component checks out of date, in the one file that is
  meant to be read first when picking this project up cold. This file has been
  burned by exactly that before, and the previous lapse is noted in it.
  The block now leads with the true headline, **five boards in hand and nothing
  powered**, then carries the six A7 results, the panel and handset state, and a
  table of **the instruments' known errors**, which is new and belongs there
  because it changes how any future reading should be taken.
- **A Seeed Studio DSO Nano is in hand**, the project's first oscilloscope,
  recorded in `bench-instruments`.

**What the scope changes:**

- ✅ **`mic-gain-budget` is no longer blocked on equipment.** Its own
  `what_would_close_it` has asked for a scope since capture. It is now blocked
  only on a powered board. **Record correctly stays `unverified`**: nothing has
  been measured yet, and an unblocked record is not a closed one.
- 🔴 **Measuring U4's output makes that record's central assumption irrelevant
  rather than resolving it.** The 94 dB SPL figure sits at the *start* of the
  chain and is the stated reason the record is unverified. Measuring the op-amp
  output measures the *end* of the chain, so the SPL never has to be known.
  Operating point, not property, which is the rule added to the global context
  file earlier today.
- **Measure at U4's output, not at the capsule.** 10 mV at the capsule is about
  one division at full sensitivity; ×101 puts it at 0.5-1.8 V, which is
  comfortable and is where the 1.0 Vrms target lives anyway.

**What it does not change, stated so it is not quietly assumed:**

- 🔴 **The boost's ~2 MHz switching ripple is still unobservable.** ~200 kHz is
  an order of magnitude short. `bench-instruments`'s existing note that there is
  no scope for that noise **was deliberately not deleted**. A scope that cannot
  resolve the waveform is not a scope for that job.
- **No absolute sensitivity in dBV/Pa**, which needs a calibrated acoustic
  source. That is a different missing instrument and it is still missing.
- **Single channel**, so no simultaneous L against R or input against output.

⚠️ **The DSO Nano's version and specs are NOT verified.** The manual has not been
checked and the ~200 kHz single-channel figures are the general class, not read
off this unit. Recorded as unverified in `bench-instruments`, and the audio
conclusion is robust to the exact number either way.

**In flight:** nothing. No board powered.

**Open questions:** unchanged from the previous entry, less the status.md item,
which is now done. The large bench capsule's can bond is still an observation
rather than a reading; the J4 green's chemistry and flat-cell legibility remain
open by choice; `loa-hook-switch` and `charger-input-voltage-thermal` are still
`in-progress` and untouched.

**Next step:** **Phase B.** Component work is finished and the screws block C3
only, so nothing stands between here and powering a board for the first time.
Read the instrument-error table in `status.md` before taking a single reading:
the supply's CC is offset +3.53 mA and the meter reads ~1.1% low on resistance.

## 2026-09-23: Phase B begins, and B1 immediately earns its place

**Completed:**

- **Phase B tally sheet generated** from the runbook, 26 steps, five board
  columns: `2026-09-23-bringup-sheet-b.txt`.
- **Census number reconciled while checking it.** 135 footprints is 127 placed
  parts plus BT1 self-fit, 3 fiducials and 4 mounting holes. So **127 is right**
  and BT1 is the only genuinely empty *part* location. JP1-JP6's headers are
  among the 127 and should be soldered; B1.5's "bare" means the removable
  shunts are not fitted, which is worth knowing before sweeping.
- **Sweep bands confirmed to be clean non-overlapping strips**, about 20 mm wide
  and full height, advancing ~23 mm from the J1 end to the J15 end, together
  accounting for all 127 with none left over.

**🔴 A design fault found: `j13-qwiic-orientation` opened, `confirmed`.**

J13, the right-angle Qwiic connector, **faces into the board.** It sits at
(170.50, 37.00) rotation 0, **7.0 mm from the y=30 edge, with its cable opening
pointing away from that edge** into 83 mm of PCB. Found by Matt with a
fabricated board in hand during B1's visual inspection, then confirmed from
`caryatid.kicad_pcb`: the footprint's signal pads are at local y −2.00 and its
mounting posts at +1.88, and on a right-angle SH the tails exit opposite the
opening.

- **The pinout is correct Qwiic and is not the fault.** GND / +3V3 / D12 SDA /
  D11 SCL, in that order.
- 🔴 **A fix is not just a rotation.** The pad order reverses, so the routing
  must be reworked or the Qwiic pinout ends up mirrored, **which is worse than
  the present fault**: a reversed Qwiic cable puts +3V3 onto GND. Silkscreen
  pin-1 moves, and edge clearance wants re-checking afterwards.
- **It does not gate this build.** loa does not use J13, the five boards are
  unaffected in service, and E10.1 stays runnable with an awkward cable.
- **Nothing was changed.** Discovery observes; remediation is a separate
  deliberate task. PCB, schematic and netlist untouched.

**🔴 The checklist gap is worth more than the fault.** `sourcing.md` records this
footprint as reused from absonus, and `capture-checklist.md` carries a still
unticked item about reused absonus footprints. But it asks only about **pin-1
orientation and JST polarity**, both electrical, and **this fault is physical
facing direction with a correct pinout**. So **the item as written would not
have caught it even if it had been ticked.** A checklist never run is one
problem; a checklist that would have passed the thing it was meant to catch is a
quieter one. Broadened to ask which way a reused footprint *faces*, and noting
that J13 is the only right-angle connector on the board, which is precisely why
nobody thought to ask.

**What found it was a pair of eyes at the cheapest possible moment.** DRC,
netlist parity, the fab house and twelve passing board checks all had nothing to
say, because none of them has a concept of which way a cable should leave. B1 is
not a formality.

**In flight:** **Phase B is started and unrun.** The sheet is generated and
blank; no board has been inventoried, probed or photographed. Stopped to record
the J13 finding before proceeding, per the ledger rule.

**Open questions:** unchanged, plus J13's fix deferred to a future revision.

**Next step:** Run **B1.2 first, before handling anything**: photograph both
faces of all five boards, rail and 1-5 mark legible, into
`discovery/evidence/` with dated filenames. A photo of an undamaged board is
available once. Then B1.3's six band sweeps per board. **Record faults and fix
nothing until all five are done**, because the same defect on several boards is
a batch fault and a quick fix erases the evidence.

## 2026-09-23: B1.2 done, and board 1 turns out not to be equivalent to the others

**Completed:**

- **Ten board photographs taken, renamed and filed** under
  `discovery/evidence/2026-09-23-board-{1..5}-{top,bottom}.jpg`. 1514 × 1010,
  about 8 MB for the set.
- **B1.2 passes on boards 2-5**: rails attached, four-digit mark and 2D barcode
  legible on the lower rail. **The mark is `0002`, not `2`**, which was not
  previously recorded anywhere.
- **B1.3 passes on all five**, Matt's census: all parts present.
- **B1.4 confirmed on board 2** from the photograph: BT1 absent, outline and
  pads visible. **B1.5** likewise, JP1-JP6 bare.

**🔴 New record `board-identity-and-condition`, and it changes how Phase B
results must be read.**

Board 1 is **the practice board** and is not equivalent to the other four:

- its **breakaway rails were snapped off**, so it carries no mark and no barcode
- **BT1 was hand-soldered onto it** as a soldering test
- Matt: *"I tested soldering so I did not follow the instructions on that one"*

🔴 **The rails were snapped, and A9's depanelling note says not to**: *"Cut, do
not snap... snapping by hand flexes the board, and this one carries 64 0603
resistors and a QFN-16 whose joints do not enjoy being flexed. That damage
surfaces later as an intermittent on a board you have already declared good."*

**No damage is claimed and none has been measured.** What is recorded is that
board 1 has been stressed in exactly the way the runbook warns about, so **flex
damage is a live suspect for any anomaly it shows**, and an anomaly seen only on
board 1 must not be read as a batch fault. **Boards 2-5 are the pristine
articles and a batch fault is judged on them.**

**This is a good outcome, not a mistake.** A practice board is exactly what
should absorb a first solder joint and a first depanel. The finding is that the
batch now holds four pristine articles and one disturbed one, and no document so
far distinguishes them: "five boards" has been a single undifferentiated phrase
throughout.

**Identity is intact.** Board 1 is uniquely identifiable as the only board with
**no rails and a fitted BT1**, two independent features visible at a glance. So
A9's warning about indistinguishable boards does not bite. But it works only
while board 1 stays the odd one out: **A9.1 stops being optional the moment a
second board is depanelled**, and applies to all five at enclosure fitting when
every rail comes off at once. A9 updated to say so.

⚠️ **A prediction of mine was wrong and is corrected in the record.** I argued
1514 × 1010 would be too coarse to read designator silkscreen, from 0.8-1.0 mm
text landing at 8-10 px. It is not: `R11`, `R41`, `C17`, `U3`, `R45`, `JP1`-`JP6`
and most of the board read directly off the photographs. **No re-shoot needed.**

**In flight:** **Phase B, B1 partly done.** B1.1 through B1.5 are established.
**B1.6 through B1.9 are NOT**, and they are the expensive ones.

**Open questions:**

- **B1.6 to B1.9 unanswered**: bridges/tombstones/skewed parts; U1/U2/U3/U4
  orientation; C7 polarity; IDC pin-1 and JST polarity on J5 and J11. A parts
  census answers none of them, since all four are orientation and polarity
  questions rather than presence ones. `sourcing.md` flags J5 and J11
  specifically as absonus-reused footprints, which is the same reuse that
  produced the J13 finding.
- Whether board 1's BT1 holder is **screwed down** as well as soldered; M3
  screws are still unsourced per `bt1-cell-fit`.

**Next step:** **B1.6 to B1.9 on all five boards**, with
`local/fab/board-top.png` open on screen to compare against. These are the rows
where being wrong costs a part, and none of them is answerable from the parts
census already done.

## 2026-09-23: B1.6 passes, B1.7 stalls on U2, and a figure of mine corrected

**Completed:**

- **B1.6 passes on all five boards.** No bridges, tombstones or skewed parts.
- **U2's design pinout verified against the datasheet**, `tps61023_SLVSF14B.pdf`,
  pin by pin: FB / EN / VIN / GND / SW / VOUT against the board's
  `FB` / `EN_SW` / `VOUT` / `GND` / `SW` / `+5V_RAW`. **Exact match, so the
  design is correct** and only the physical placement rotation is in question.
- **The device marking is `1GI`**, from the datasheet's PACKAGE OPTION ADDENDUM.
  That is the only visual pin-1 indicator a SOT-563 has; there is no dot or
  chamfer. Recorded because it was not written down anywhere.
- **CPL checked:** U2 rotation 0, matching the footprint. Design and fab
  instructions agree, so the only residual risk is the assembly house's own
  orientation convention for SOT-563, which no file can settle.

**⚠️ A figure of mine was wrong and had reached the ledger.** I wrote that the
TPS61023 switches "around 2 MHz" when assessing the DSO Nano, from recollection
rather than the datasheet. **It is 1 MHz** above 1.5 V VIN, 0.5 MHz below 1 V.
Corrected in `bench-instruments`. **The conclusion is unaffected**: ~200 kHz
cannot resolve 1 MHz either, five times short rather than ten.

Also noted there, because it matters to anyone devising a test: the part
features **"true disconnection between input and output during shutdown"**, so
there is **no always-present SW-to-VOUT body diode** to probe for. The obvious
electrical orientation test does not exist on this part.

**In flight:** **B1.7, stalled on U2 only.** Matt can see no orientation
indicator on board 1's U2 and photographed it
(`loa/local/baord1-u2.png`, not filed as evidence: it is a working shot, and the
question is unresolved). The marking is present in the photo but not resolvable
at that magnification. U1, U3 and U4 all have conventional pin-1 dots or
notches, so **U2 is the only hard one**: the smallest part on the board and the
only one with no geometric indicator.

**Open questions:**

- 🔴 **U2's placement rotation is unverified.** It is a **batch** question, not a
  board-1 one: all five came off one P&P run with one CPL, so a wrong rotation
  is wrong on all five identically. Next move is a same-magnification photo of
  U2 on board 2 to establish consistency, then one determination for the batch.
  **If it cannot be resolved visually, B1.7 should be recorded UNRESOLVED rather
  than passed.** It blocks nothing in Phase B, where nothing is powered, and
  surfaces at C2 where a rotated boost will not start and C1's current limit
  makes that a diagnosis rather than a casualty.
- **B1.8 and B1.9 still unanswered**: C7 polarity, and IDC pin-1 plus JST
  polarity on J5 and J11.

**Next step:** Photograph U2 on **board 2** at the same magnification as the
board-1 shot and compare, looking for the marking `1GI`. Then B1.8 and B1.9 on
all five with `local/fab/board-top.png` open on screen.
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

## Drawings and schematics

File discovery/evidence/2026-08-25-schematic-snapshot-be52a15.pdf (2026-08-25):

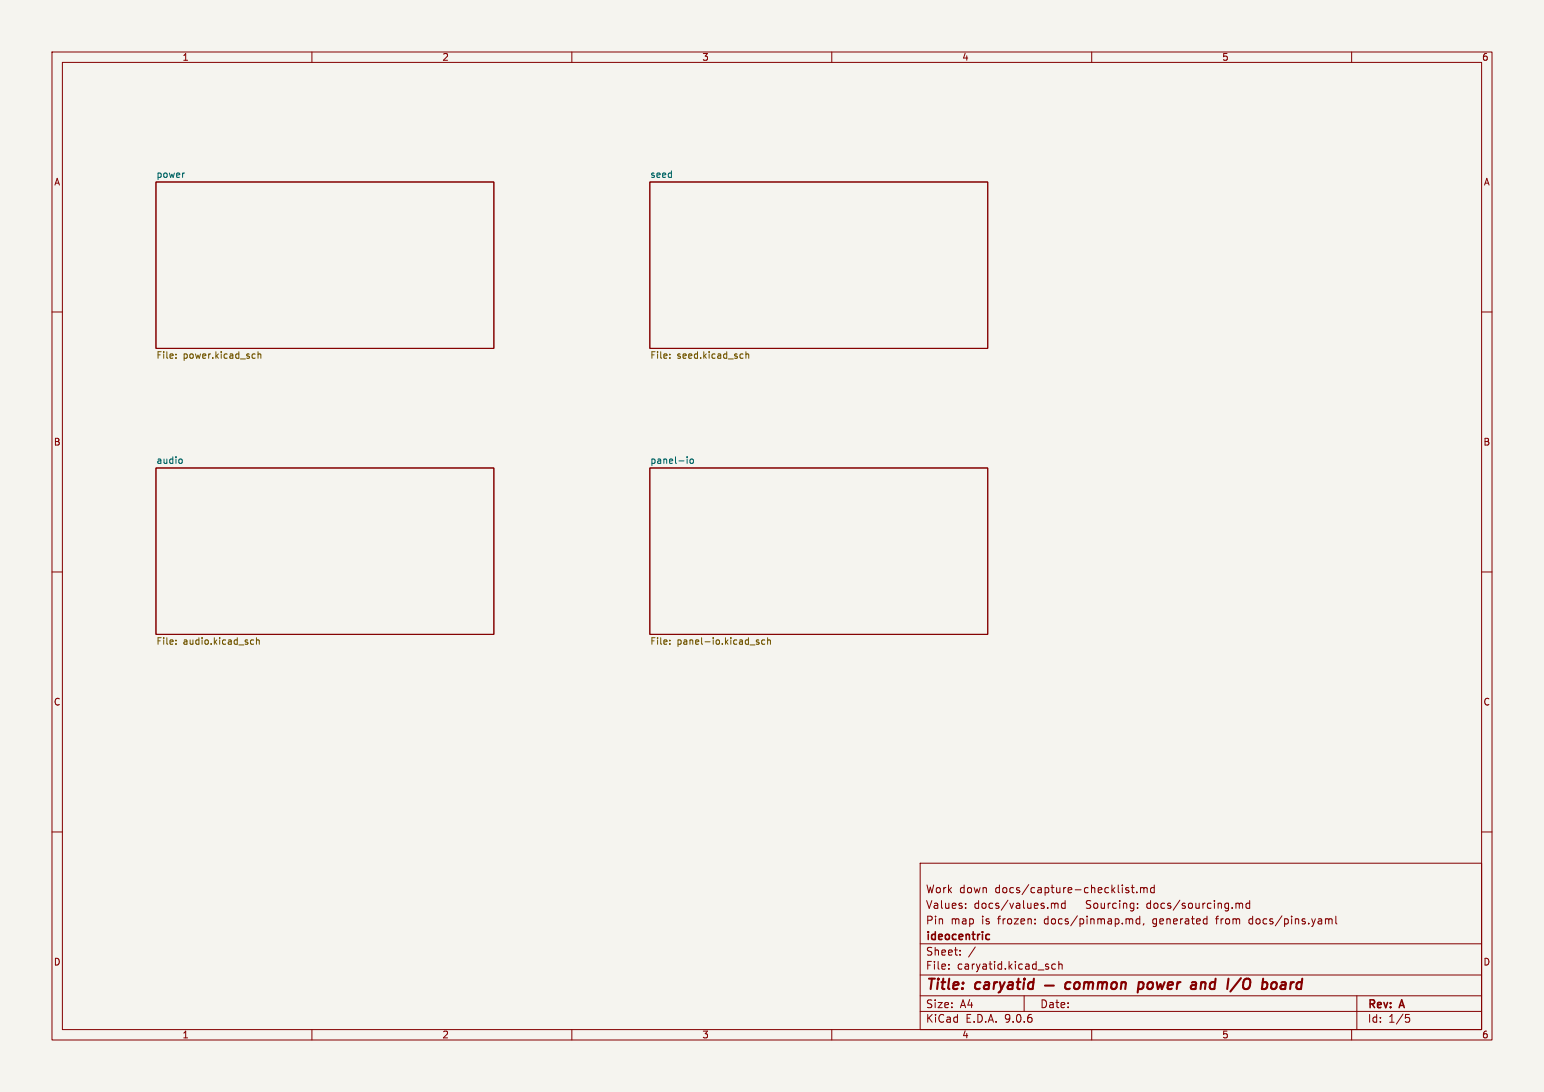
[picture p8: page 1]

panel-io File: panel-io.kicad_sch

File: caryatid.kicad_sch Sheet: /
Id: 1/5 Title: caryatid þÿ common power and I/O board

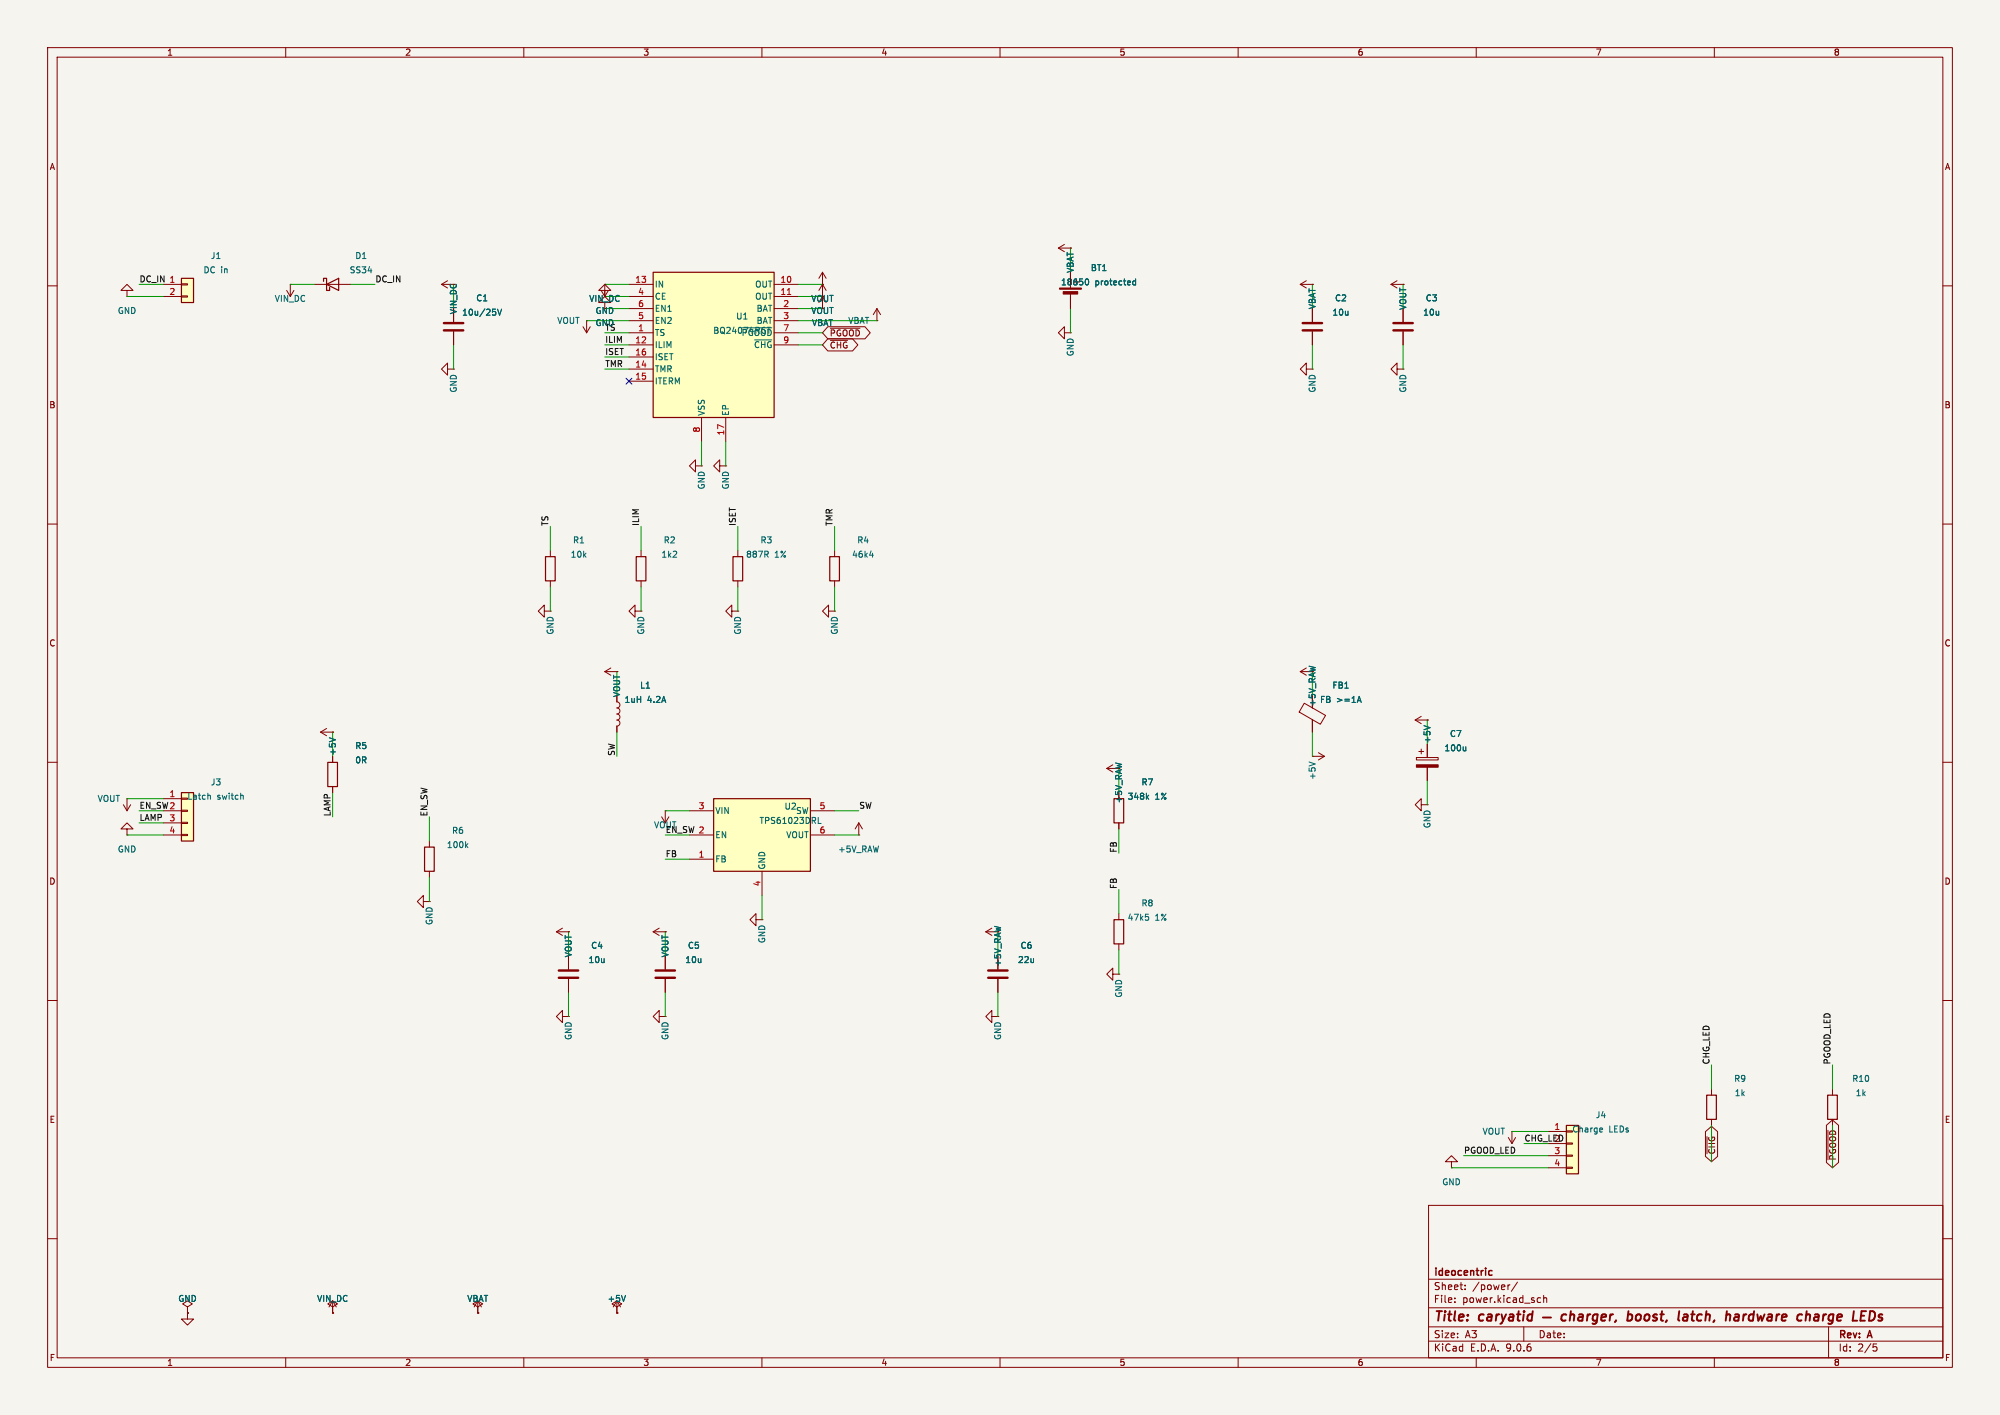
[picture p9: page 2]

18650 protected VBAT VOUT VBAT VOUT
10k GND

8 EP 17 OUT 10 OUT 11 BAT 2 BAT 3 ~{PGOOD}7 ~{CHG}9 U1 BQ24074RGT

Id: 2/5 Title: caryatid þÿ charger, boost, latch, hardware charge LEDs

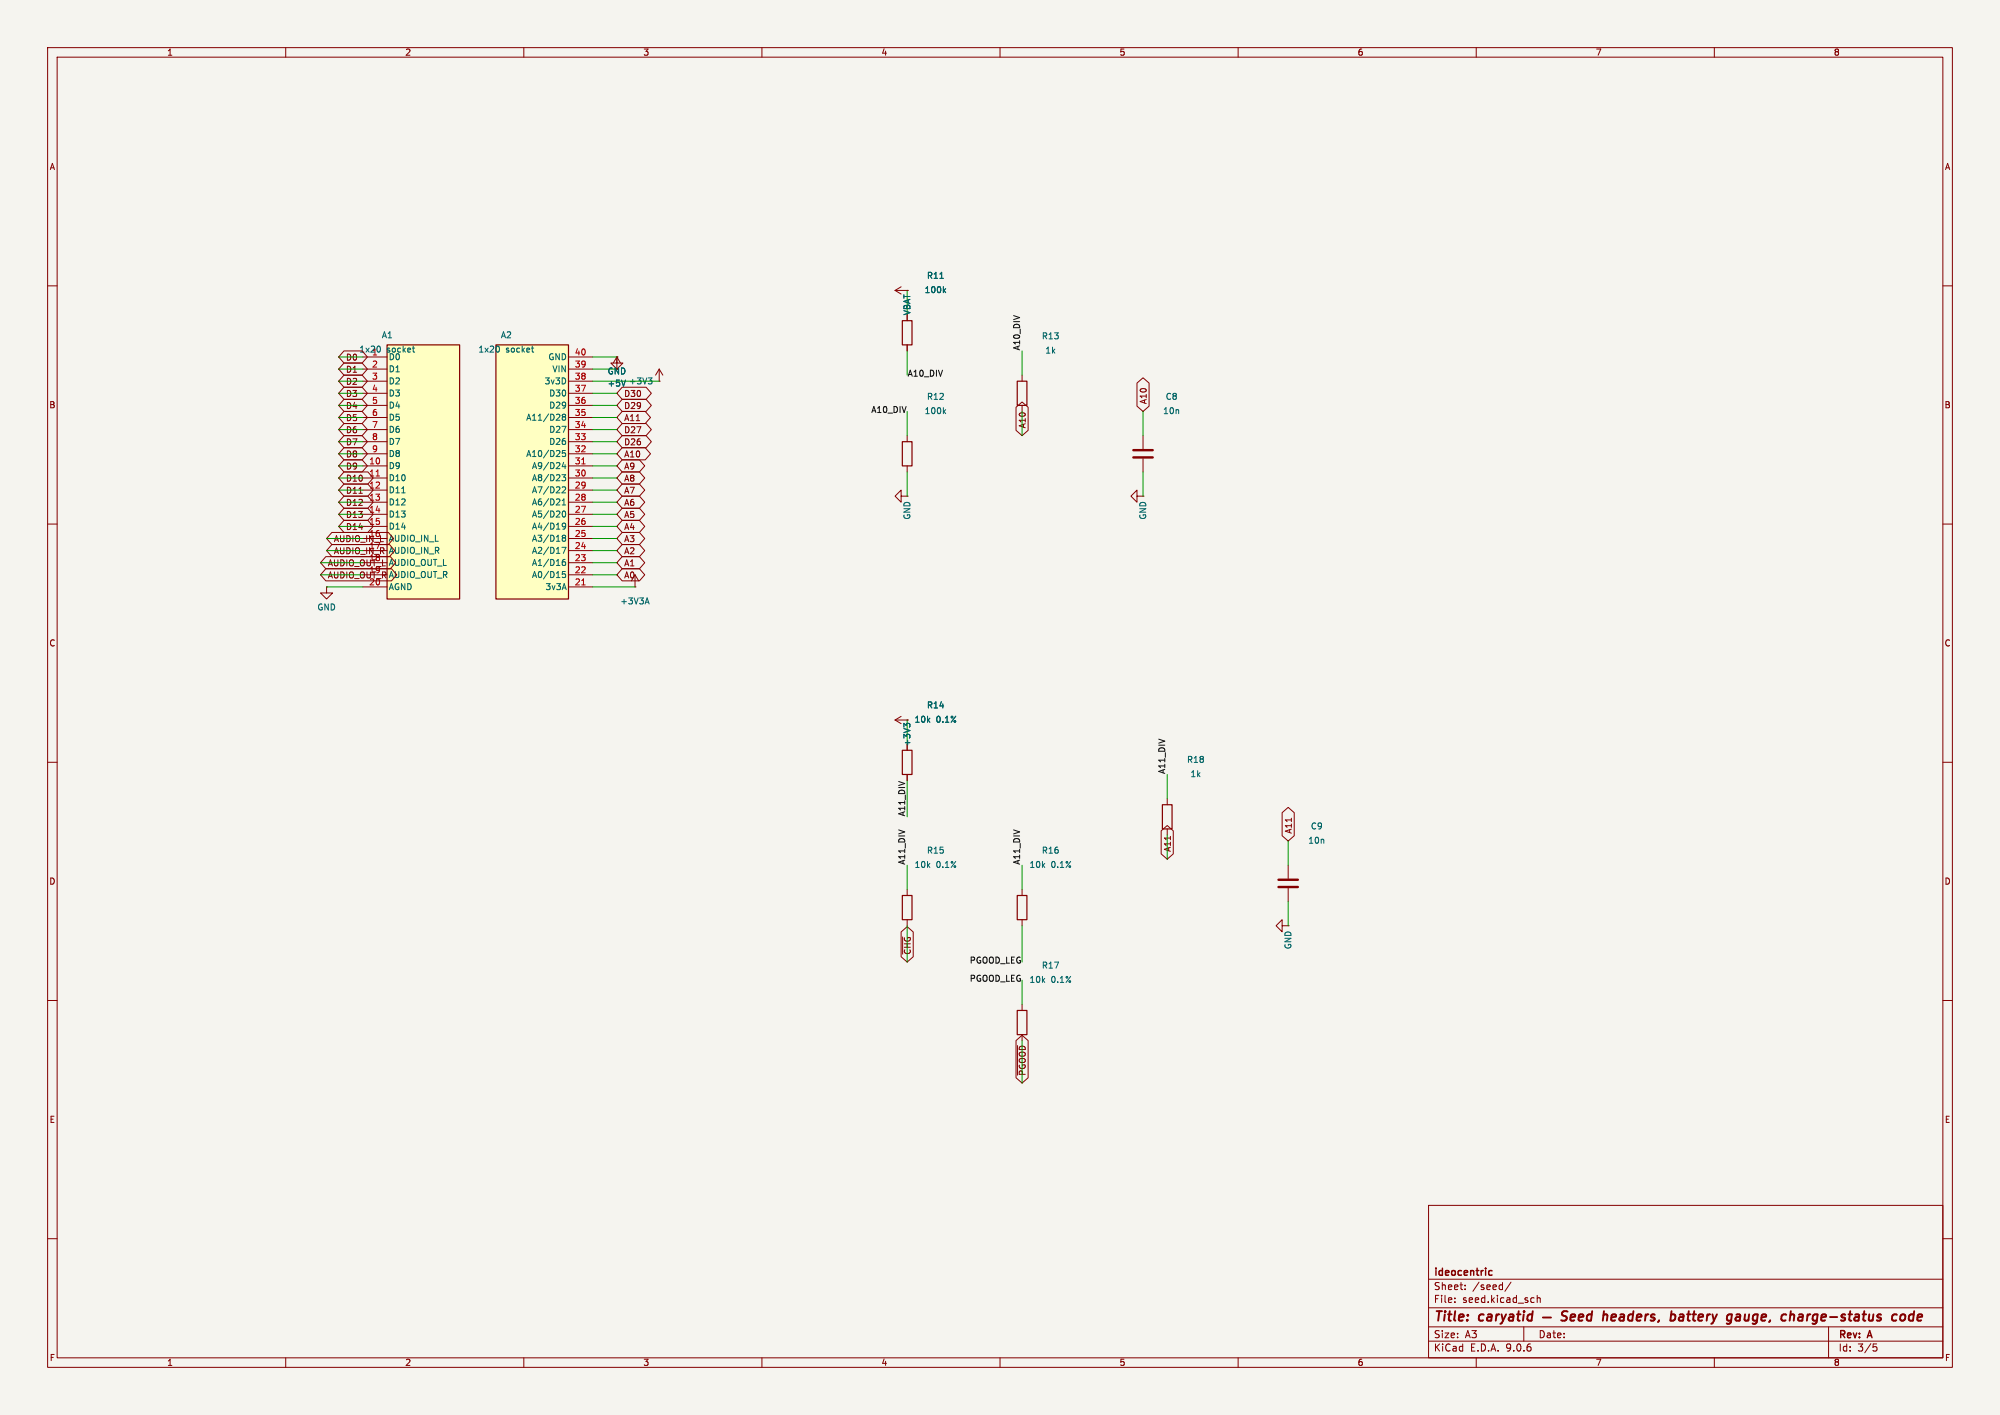
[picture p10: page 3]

ideocentric
File: seed.kicad_sch Sheet: /seed/

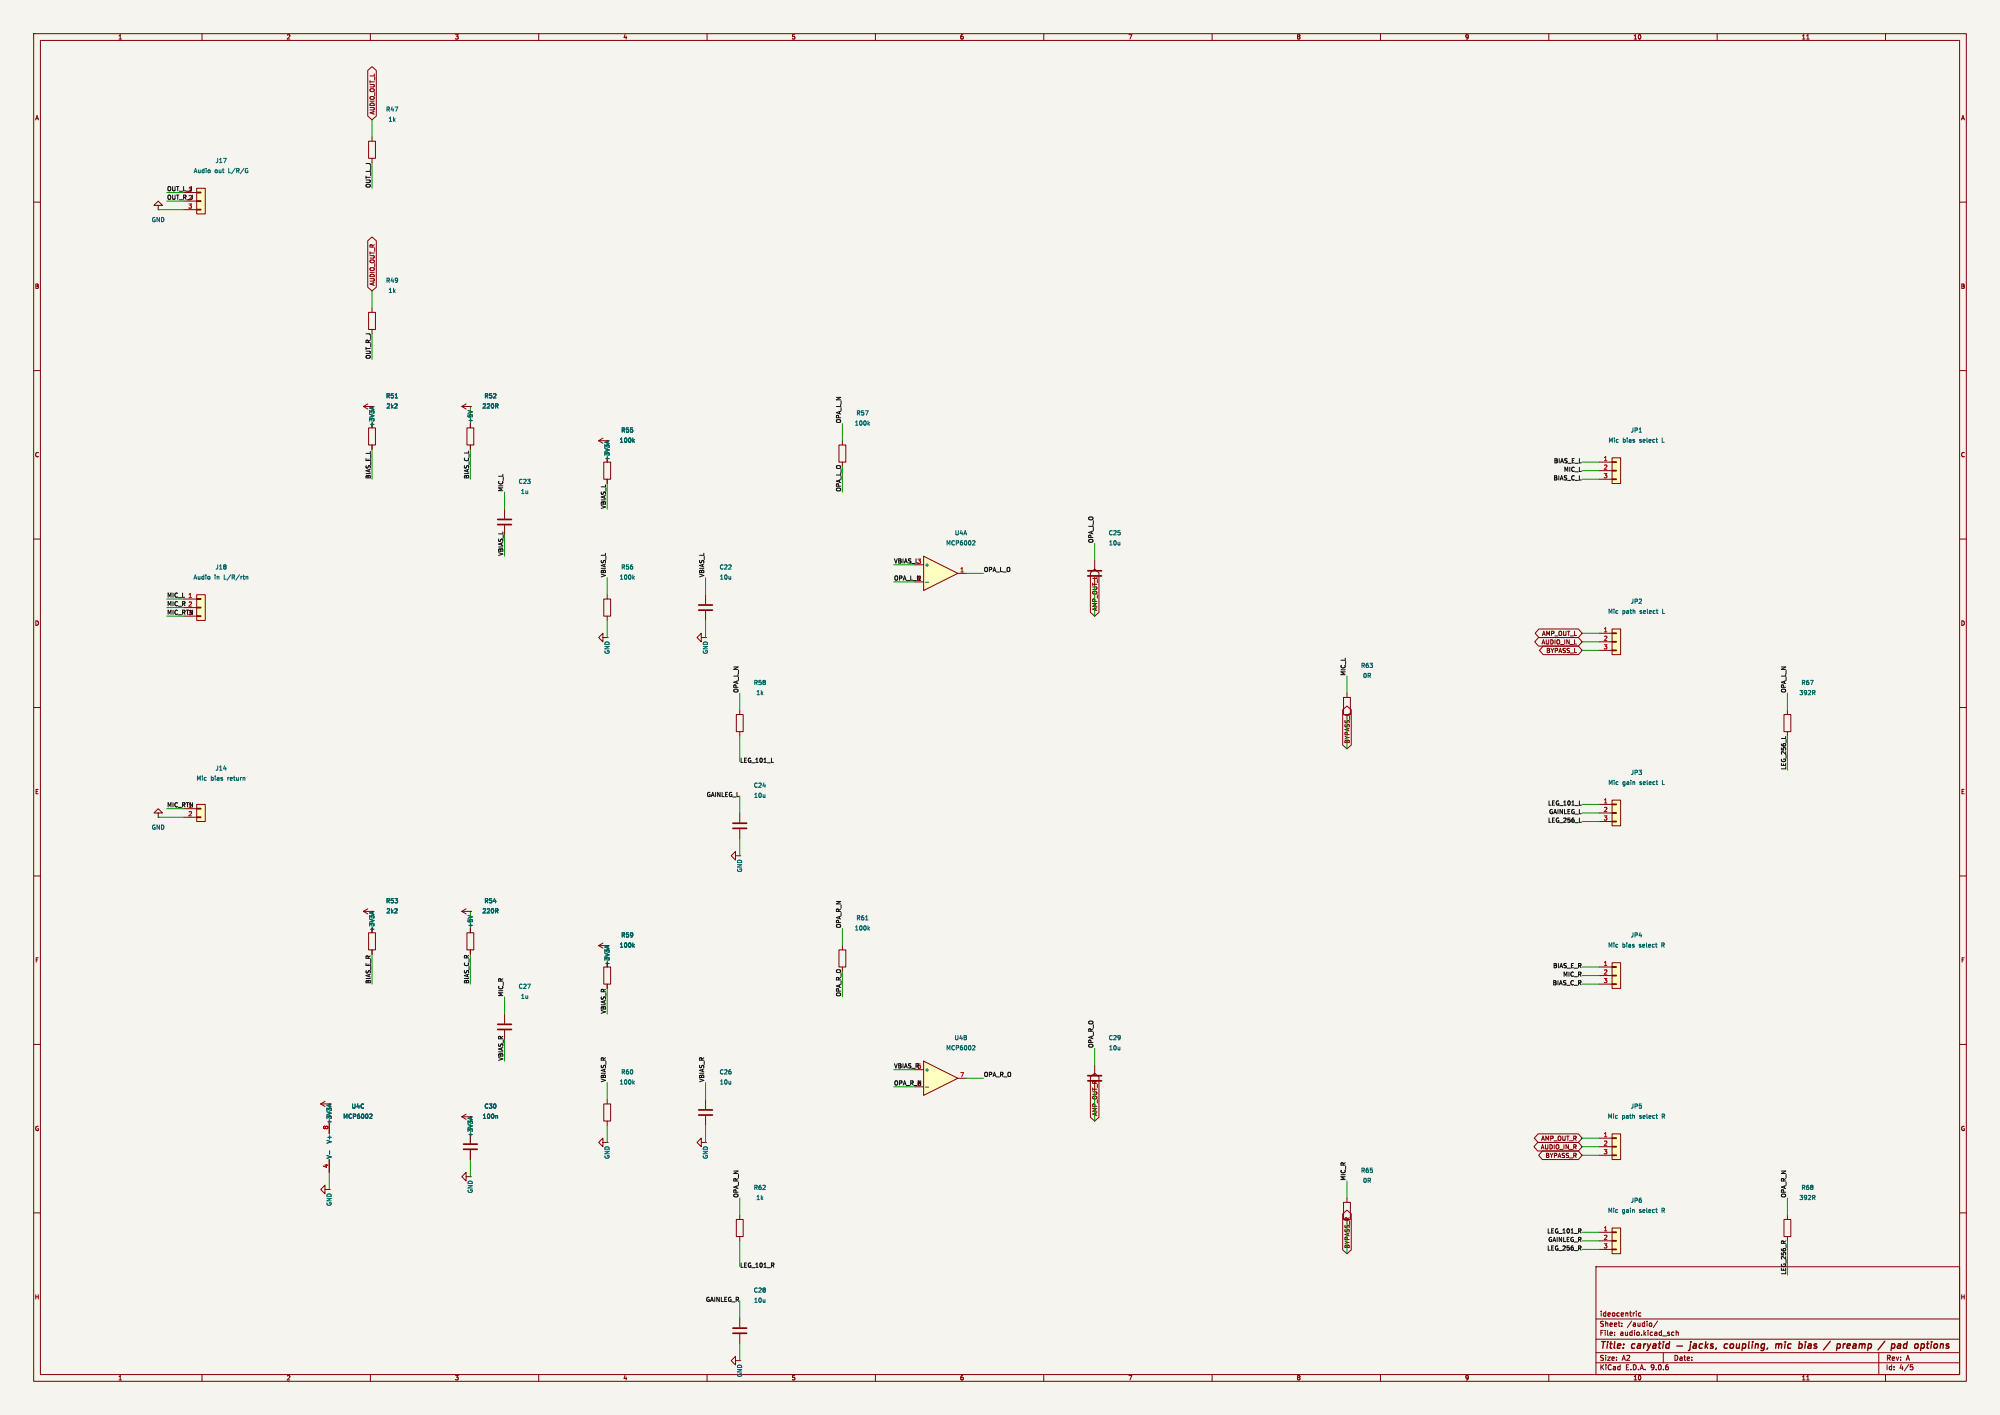
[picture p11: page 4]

File: audio.kicad_sch Sheet: /audio/

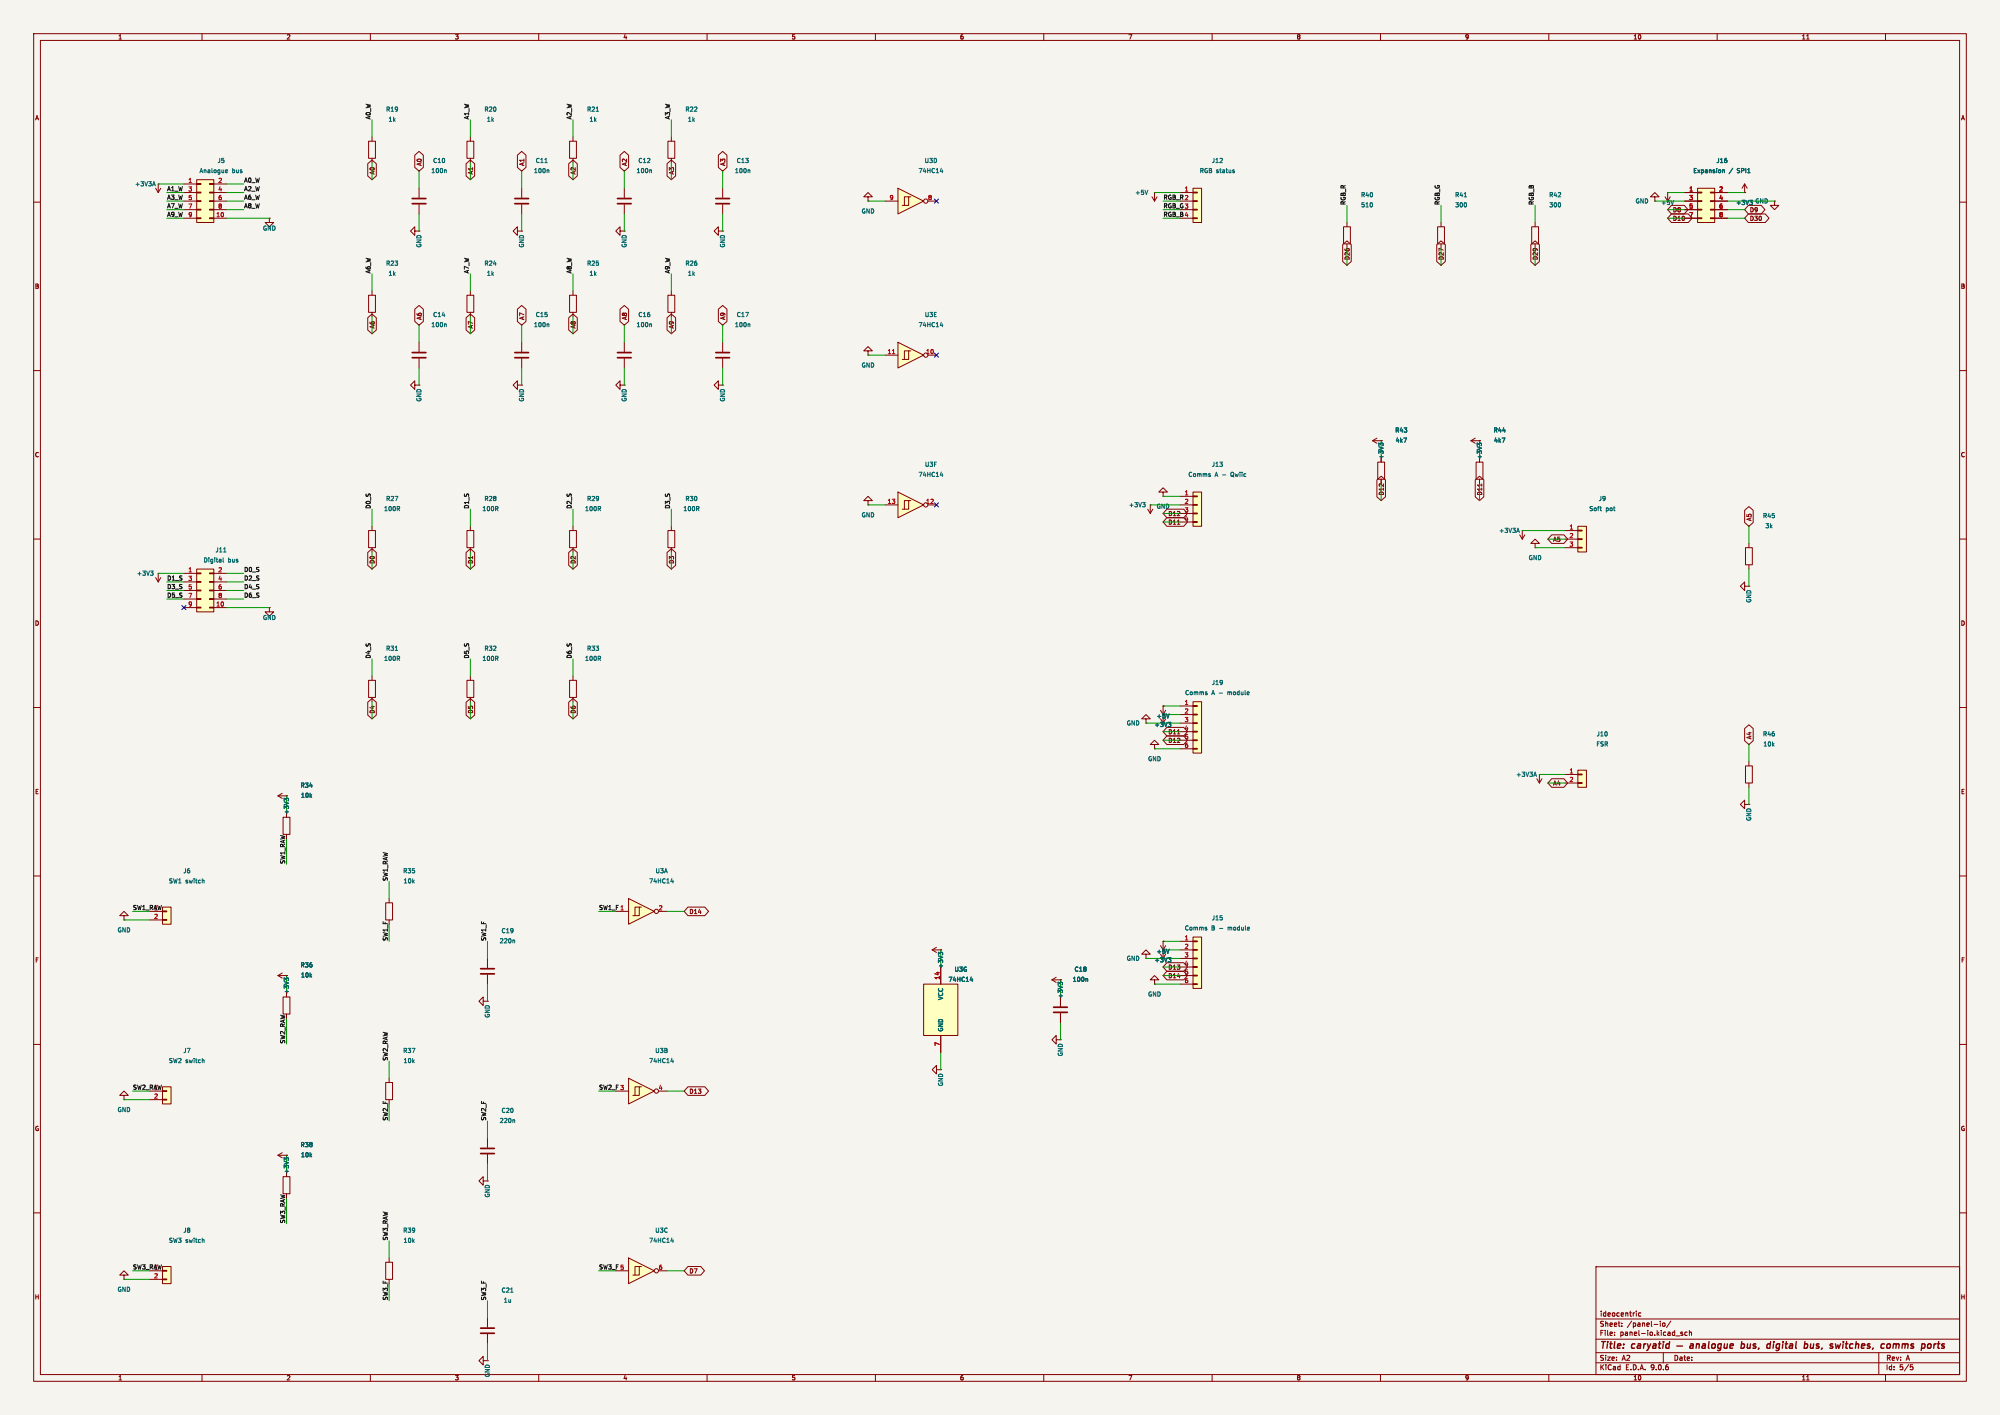
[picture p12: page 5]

ideocentric
File: panel-io.kicad_sch Sheet: /panel-io/

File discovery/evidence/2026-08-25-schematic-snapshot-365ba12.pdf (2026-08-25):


panel-io File: panel-io.kicad_sch

File: caryatid.kicad_sch Sheet: /
Id: 1/5 Title: caryatid þÿ common power and I/O board


18650 protected VBAT VOUT VBAT VOUT
10k GND

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

Id: 2/5 Title: caryatid þÿ charger, boost, latch, hardware charge LEDs

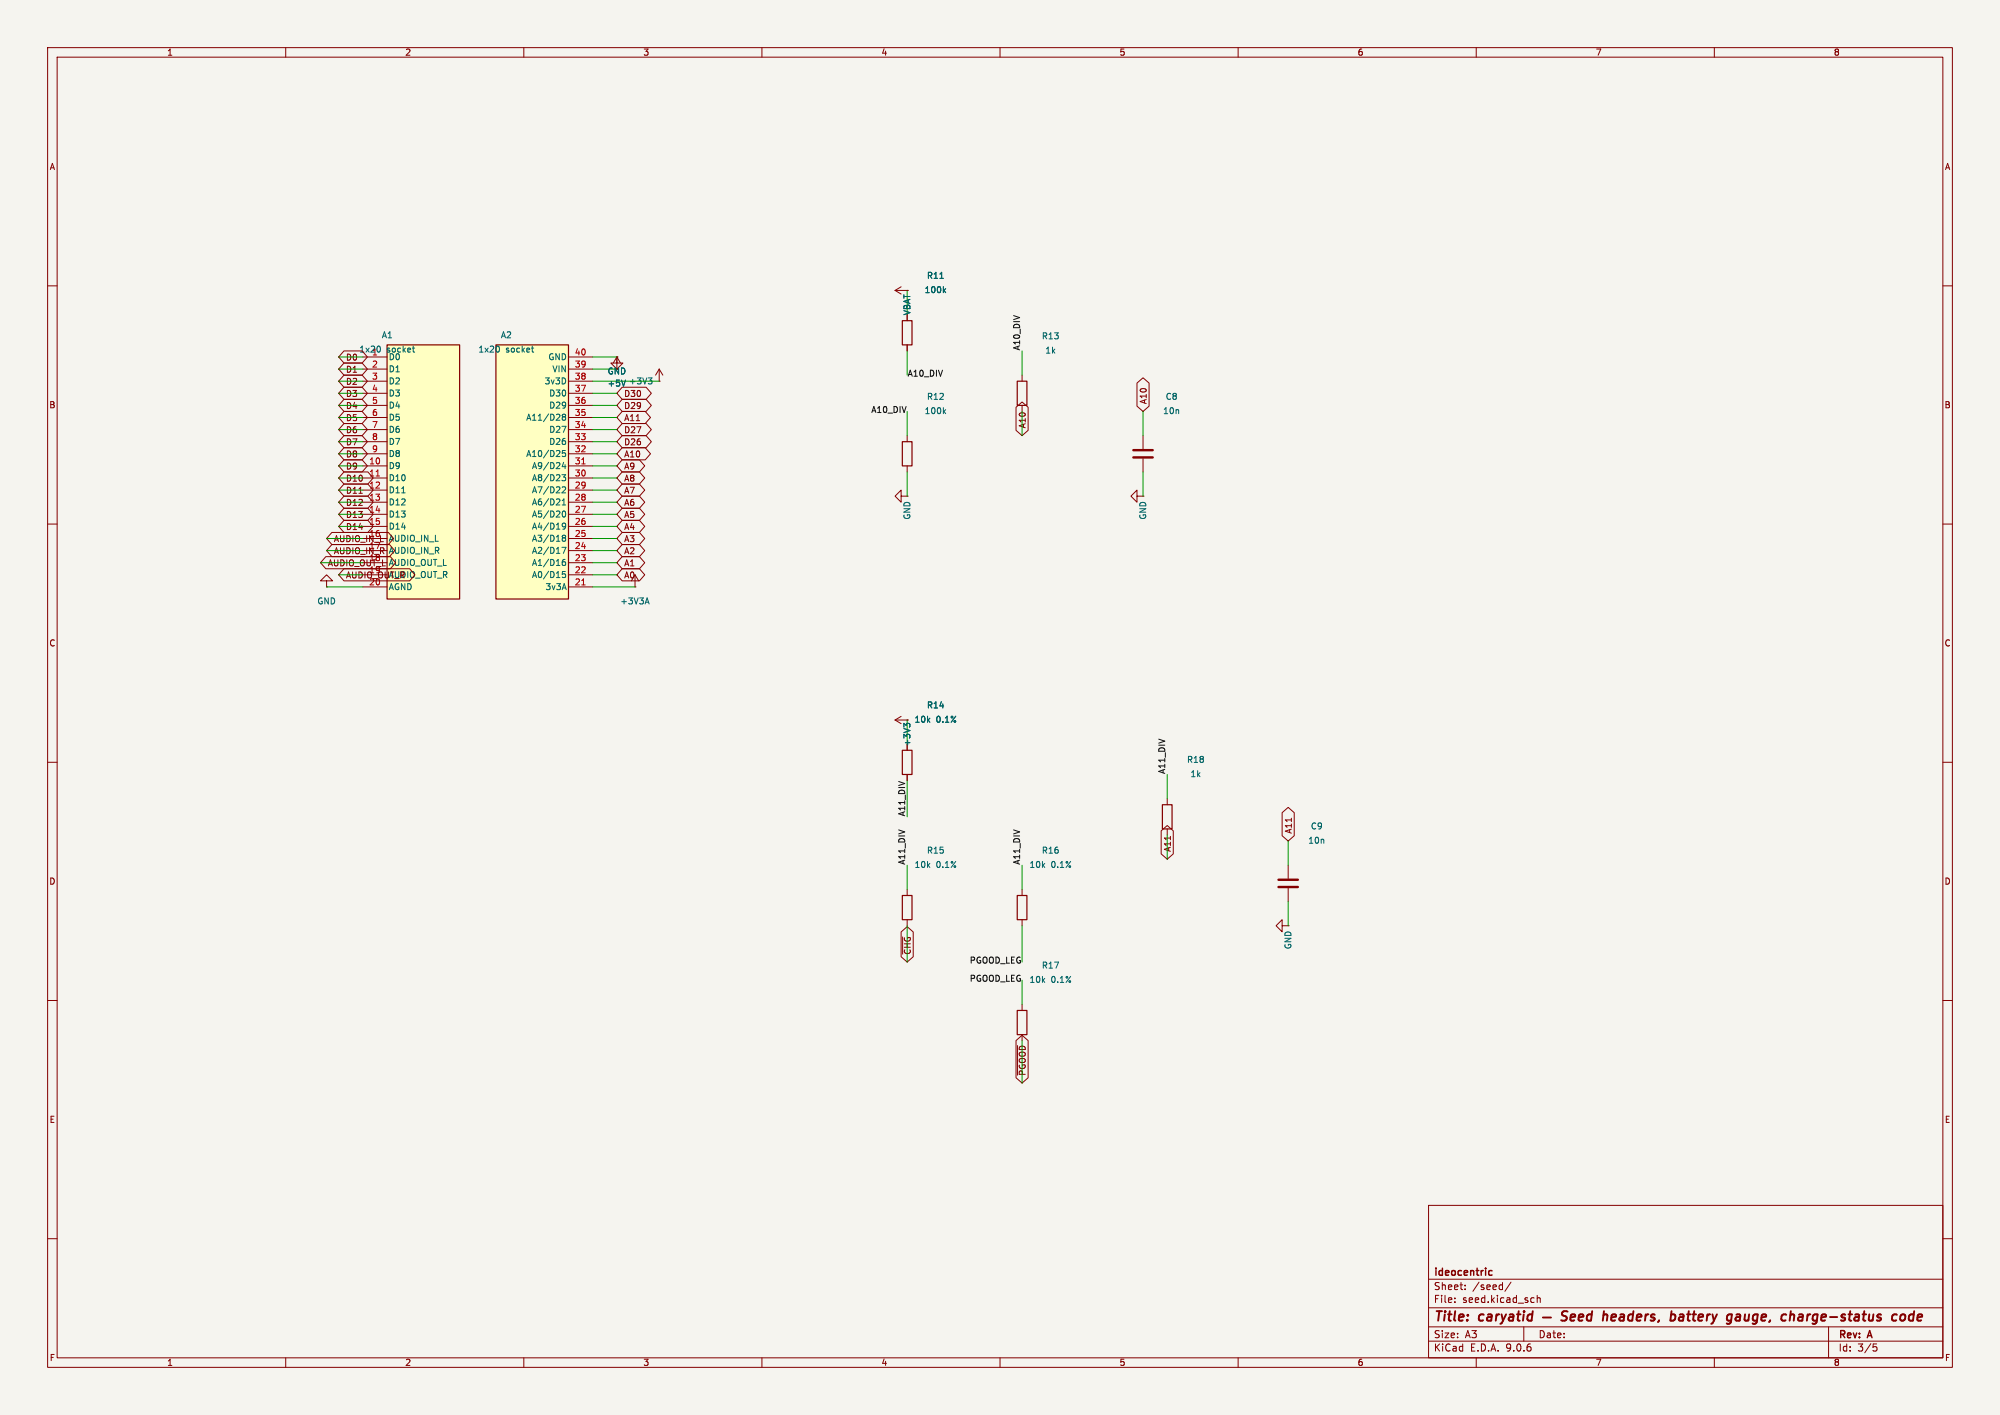
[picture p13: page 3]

ideocentric
File: seed.kicad_sch Sheet: /seed/


File: audio.kicad_sch Sheet: /audio/


ideocentric
File: panel-io.kicad_sch Sheet: /panel-io/

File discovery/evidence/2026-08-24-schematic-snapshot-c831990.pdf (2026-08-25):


panel-io File: panel-io.kicad_sch

File: caryatid.kicad_sch Sheet: /
Id: 1/5 Title: caryatid þÿ common power and I/O board

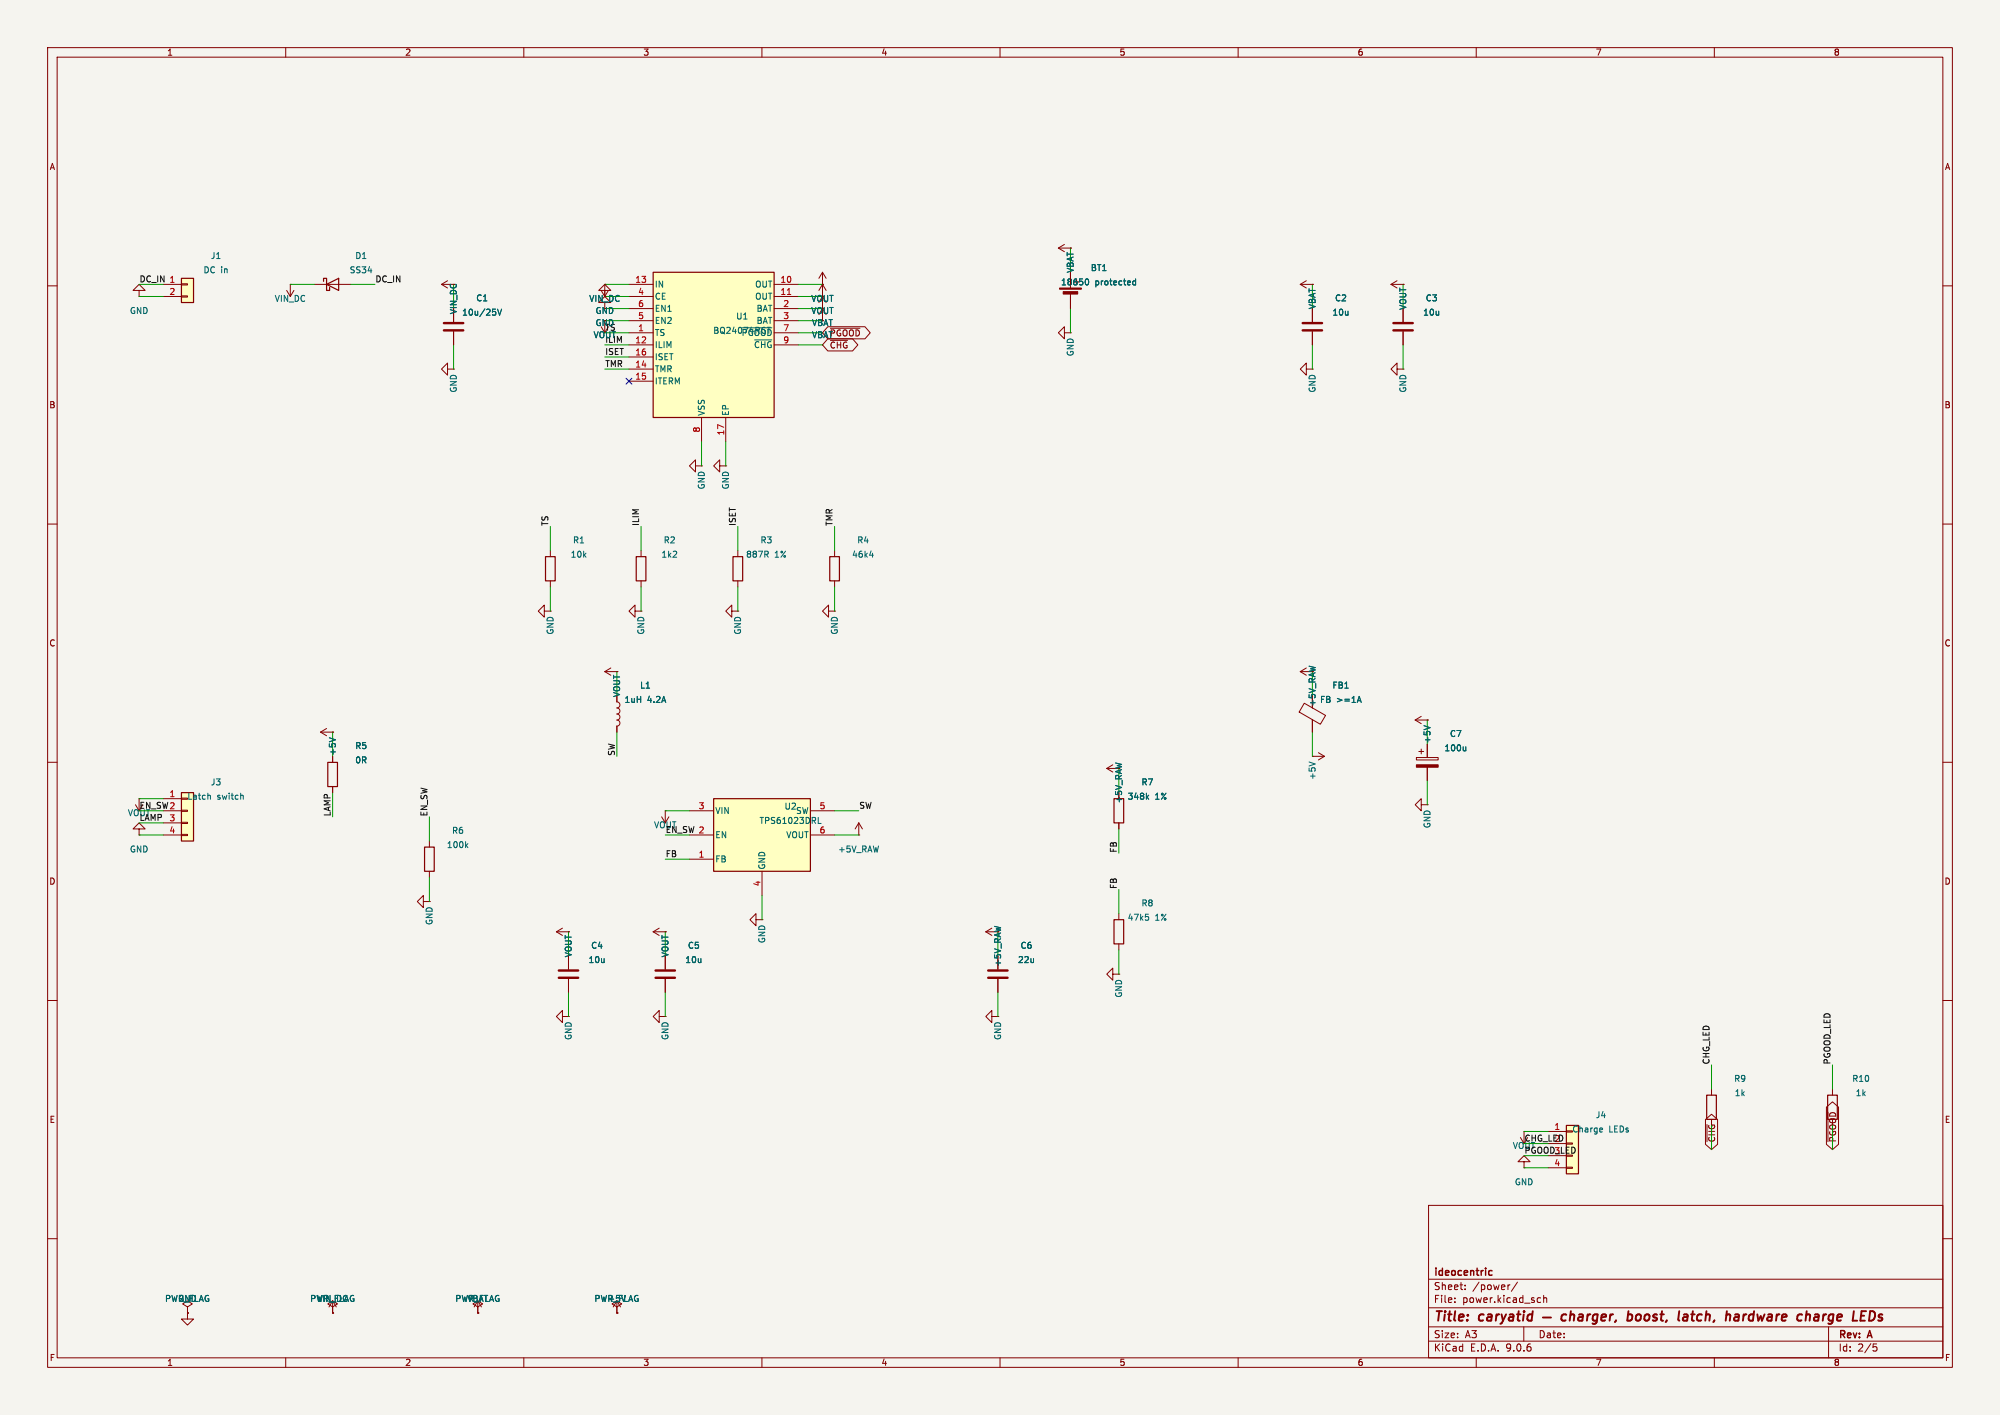
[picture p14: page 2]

VBAT VBAT VOUT GND
PWR_FLAG GND

18650 protected VBAT VBAT VBAT VOUT VOUT

8 EP 17 OUT 10 OUT 11 BAT 2 BAT 3 ~{PGOOD}7 ~{CHG}9 U1 BQ24074RGT GND

Id: 2/5 Title: caryatid þÿ charger, boost, latch, hardware charge LEDs

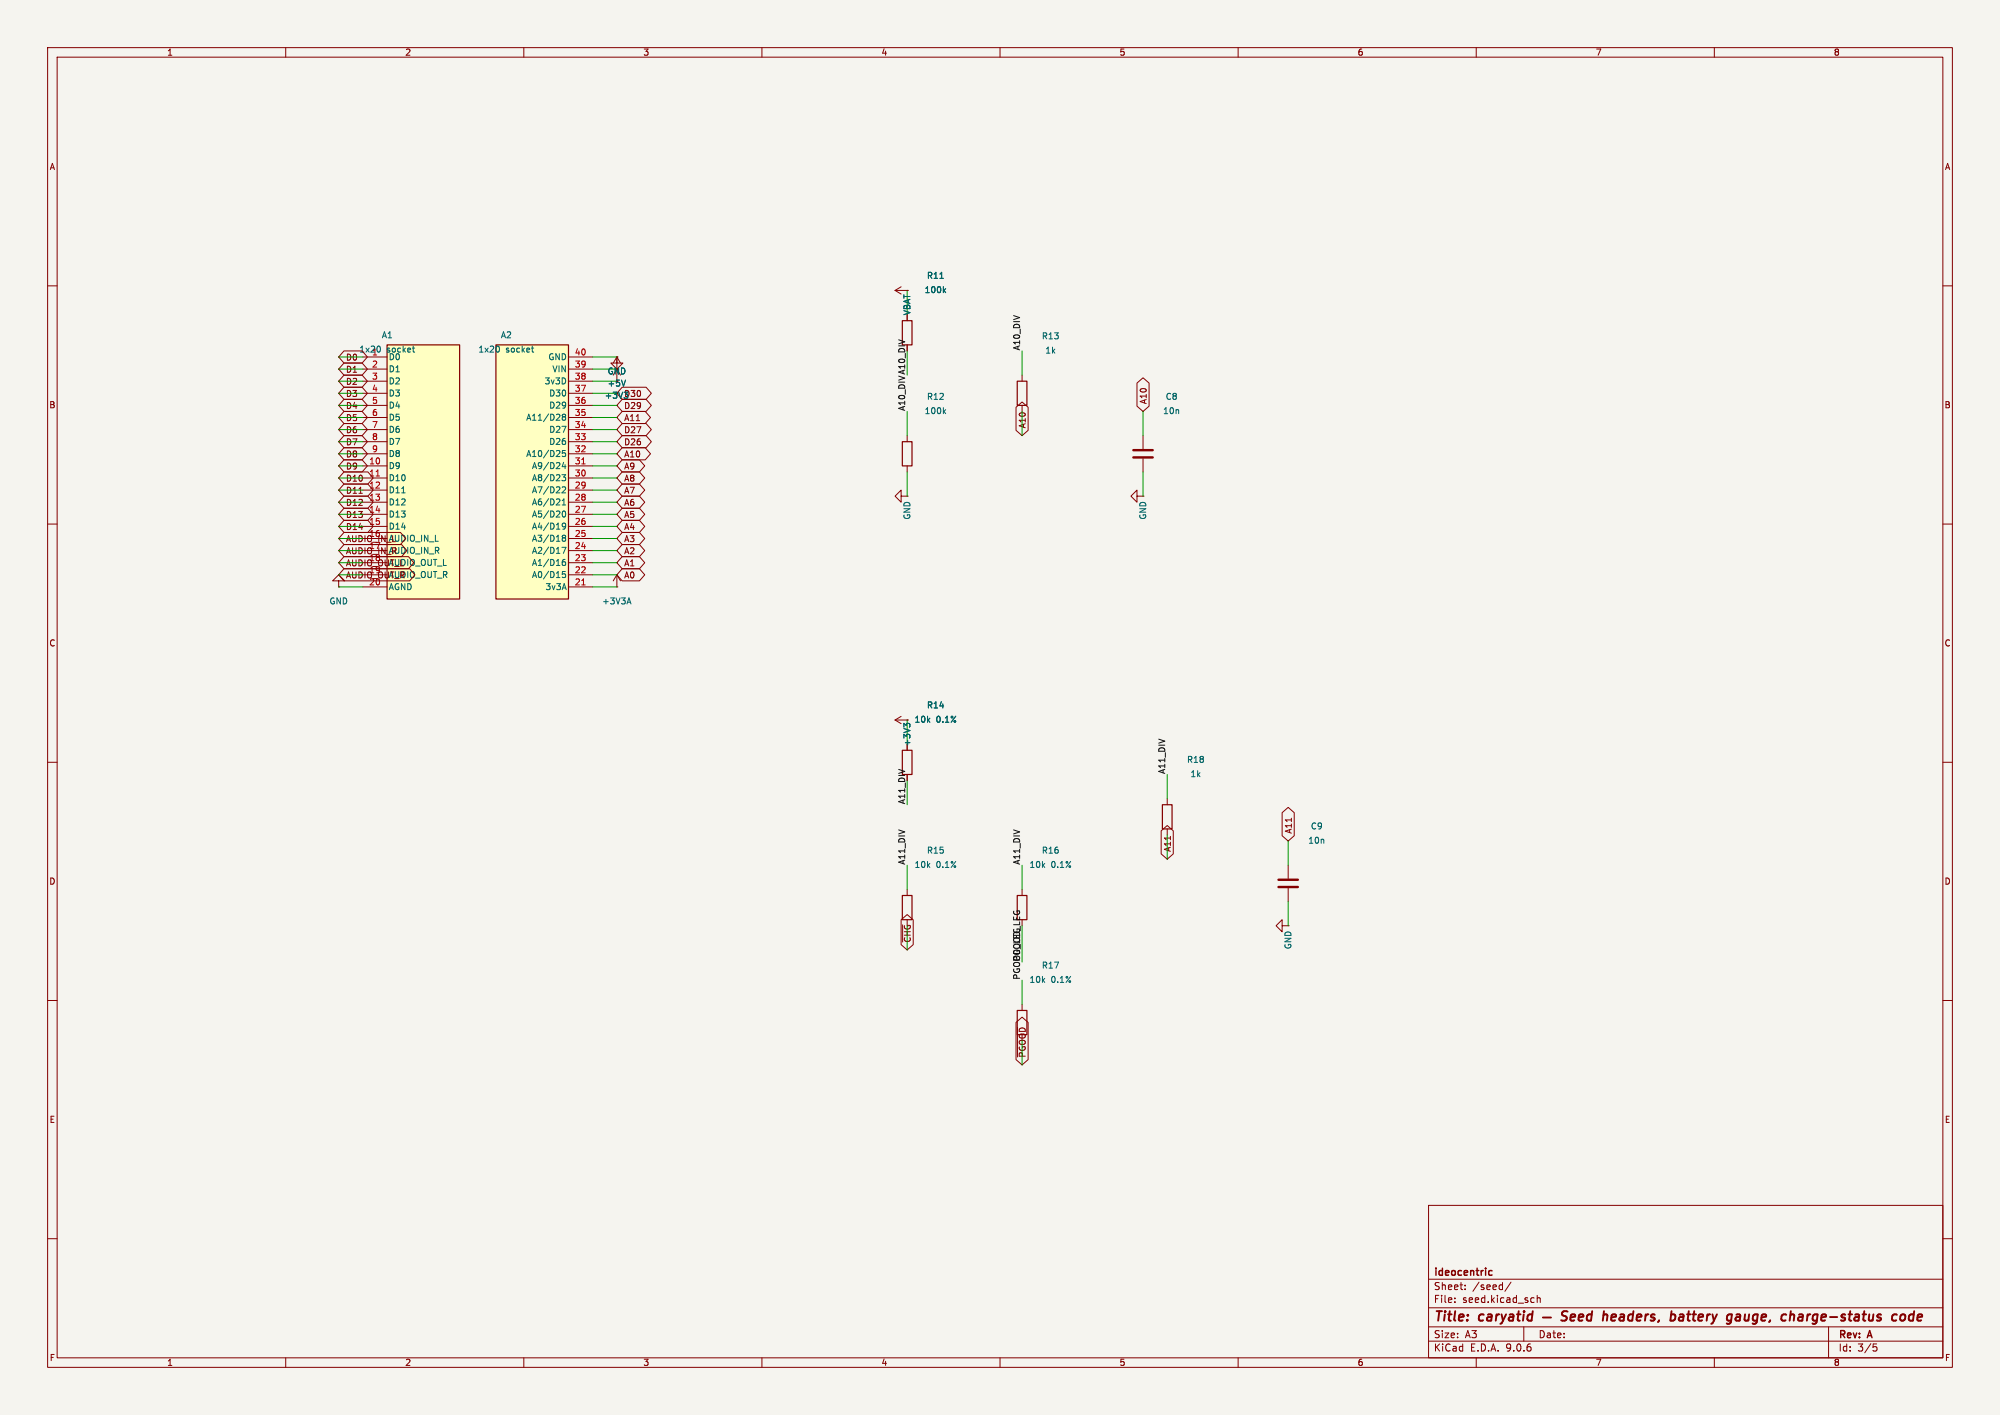
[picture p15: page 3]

ideocentric
File: seed.kicad_sch Sheet: /seed/

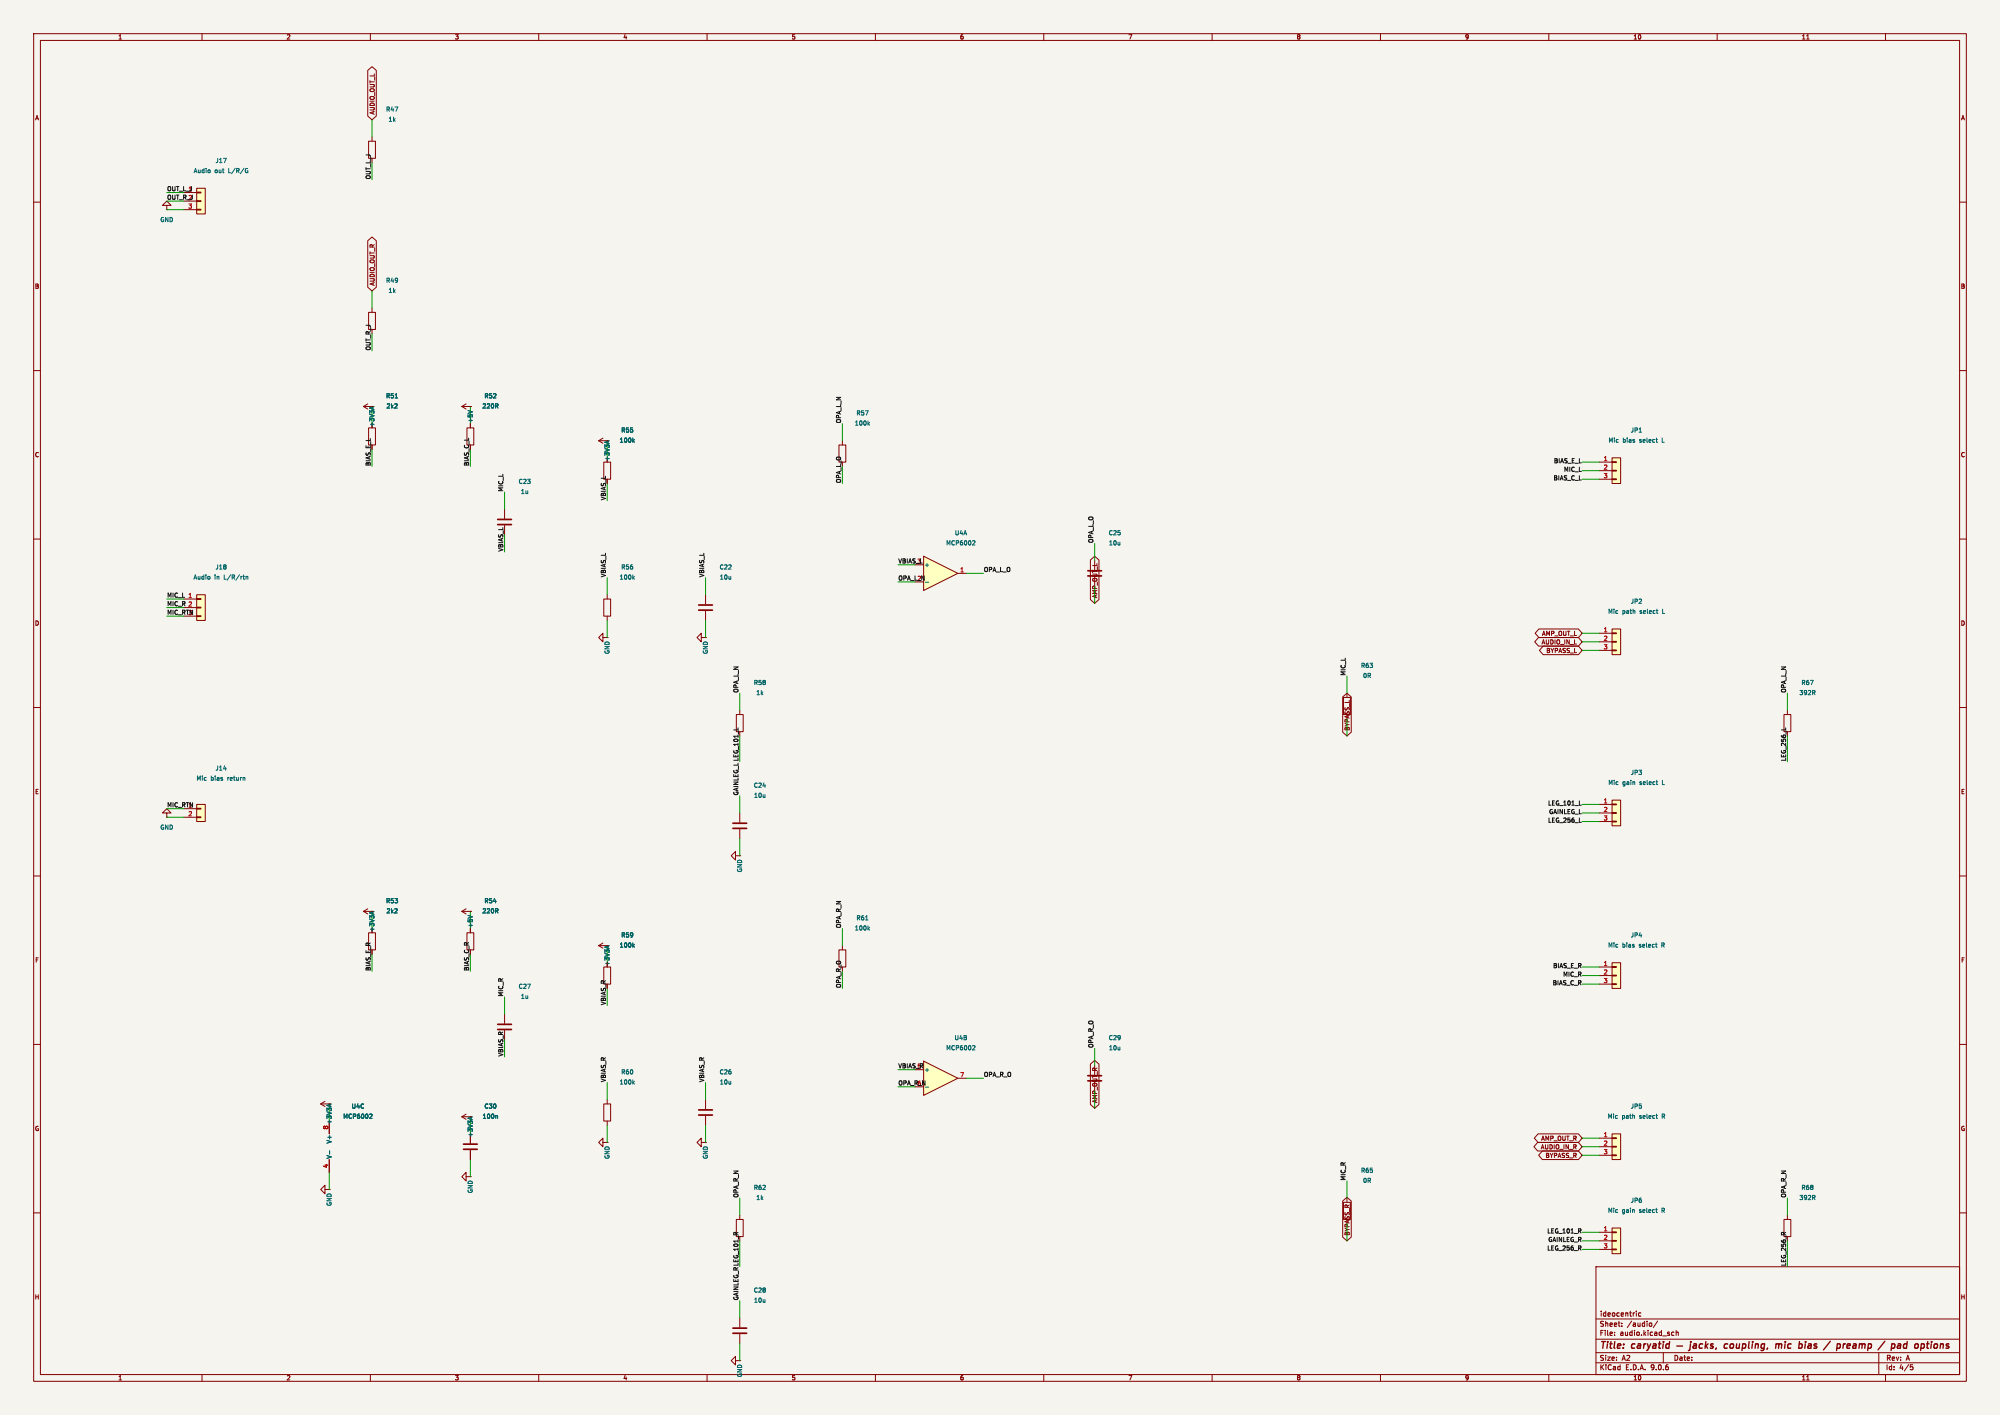
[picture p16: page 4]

JP6 Mic gain select R GND

ideocentric
File: audio.kicad_sch Sheet: /audio/

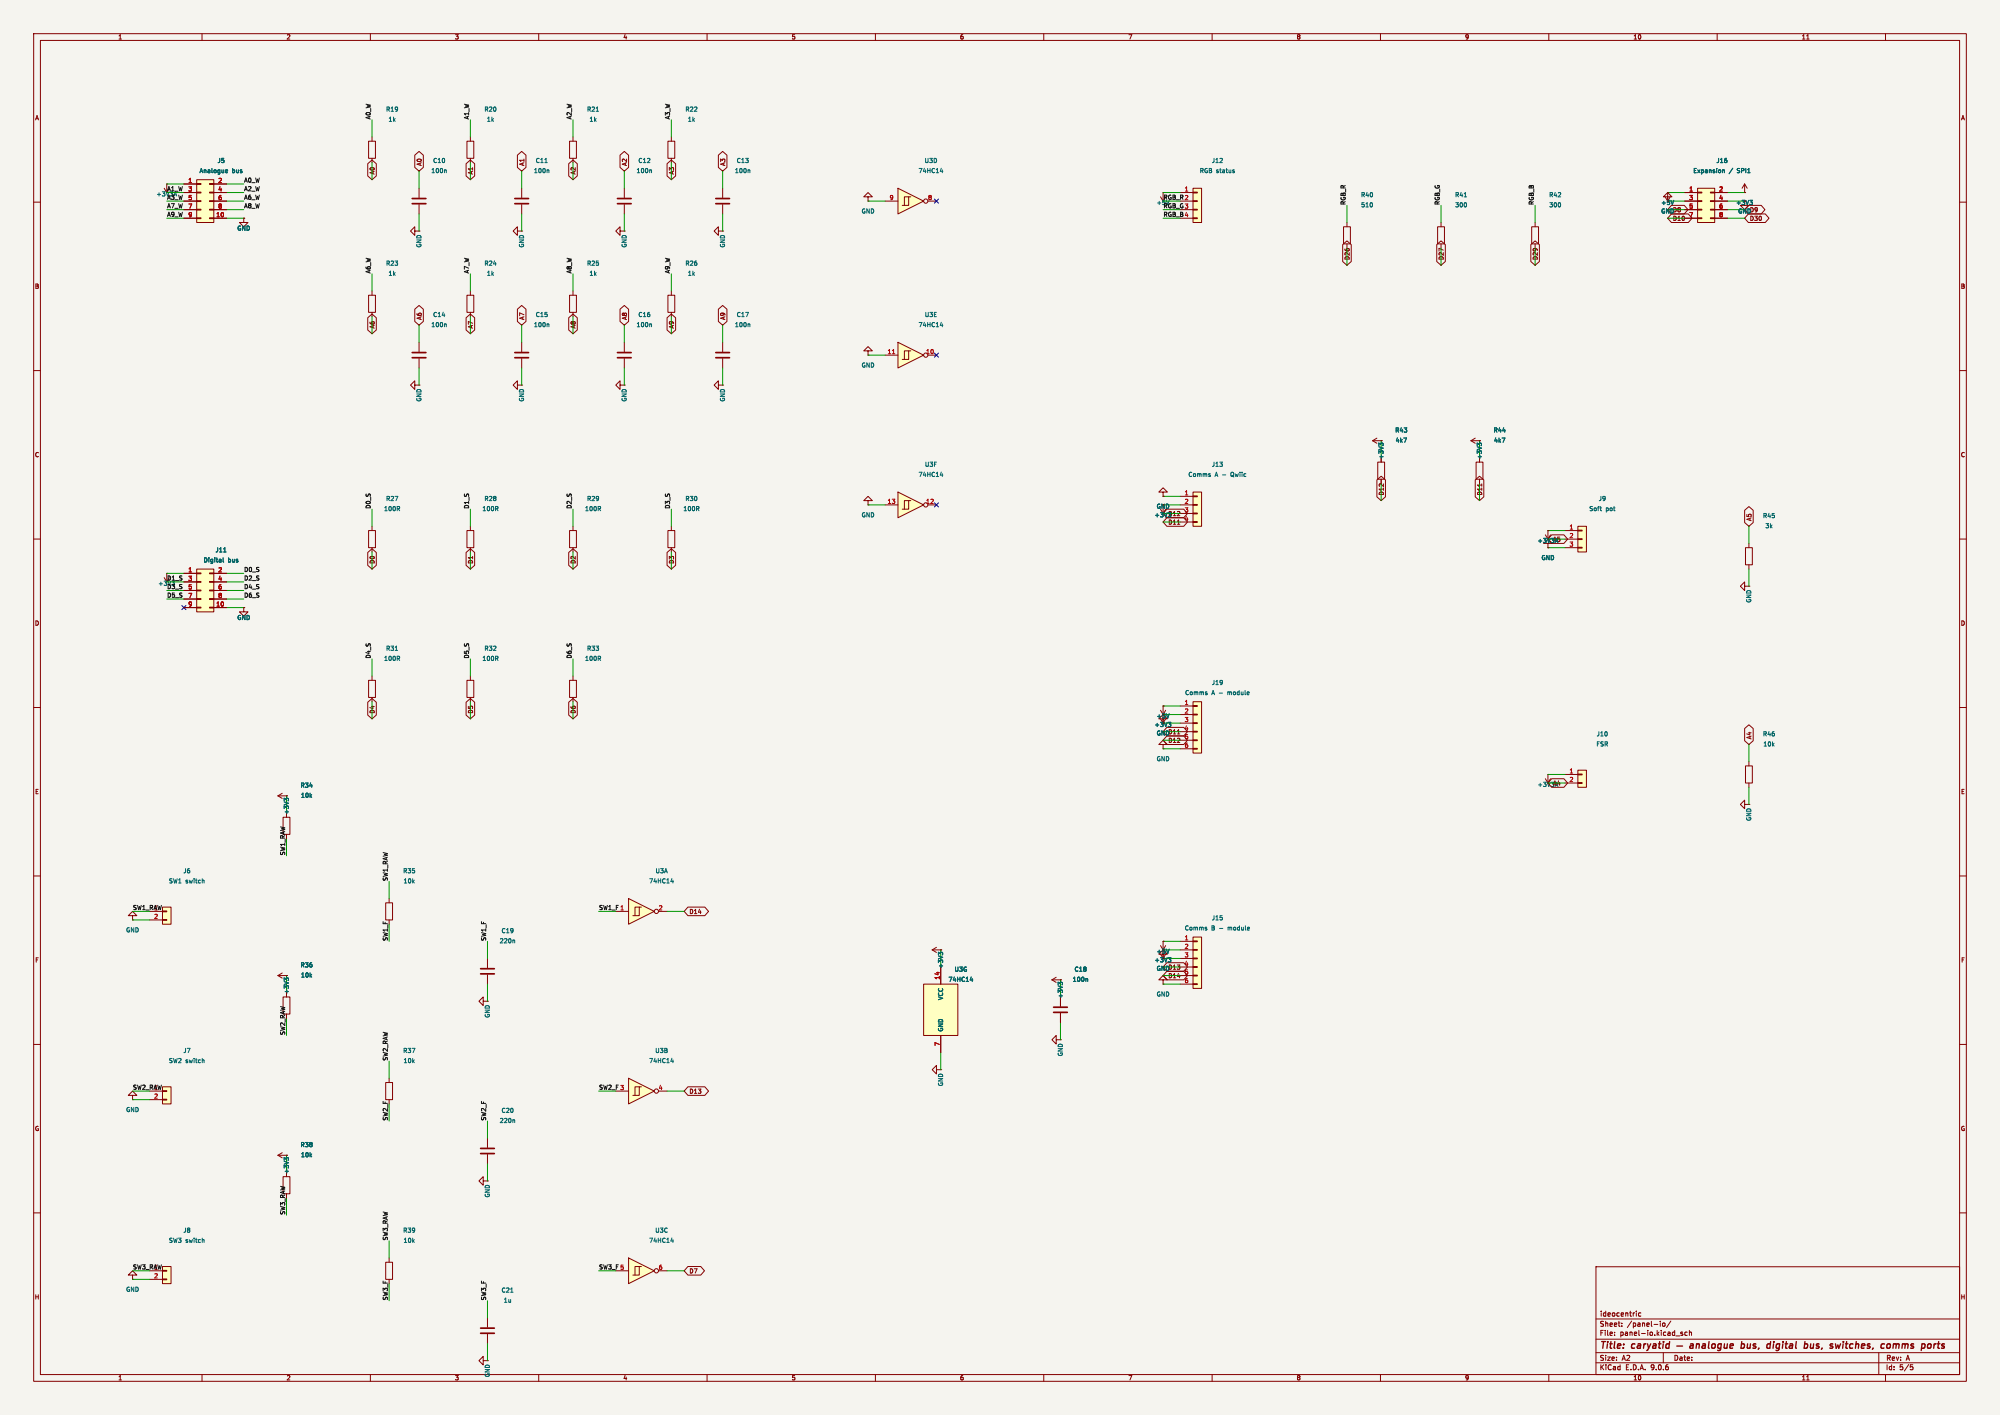
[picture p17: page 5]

ideocentric
File: panel-io.kicad_sch Sheet: /panel-io/

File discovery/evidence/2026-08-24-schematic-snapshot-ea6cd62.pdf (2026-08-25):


panel-io File: panel-io.kicad_sch

File: caryatid.kicad_sch Sheet: /
Id: 1/5 Title: caryatid þÿ common power and I/O board


VBAT VBAT VOUT GND
PWR_FLAG GND

18650 protected VBAT VBAT VBAT VOUT VOUT

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

Id: 2/5 Title: caryatid þÿ charger, boost, latch, hardware charge LEDs


ideocentric
File: seed.kicad_sch Sheet: /seed/


JP6 Mic gain select R GND

ideocentric
File: audio.kicad_sch Sheet: /audio/

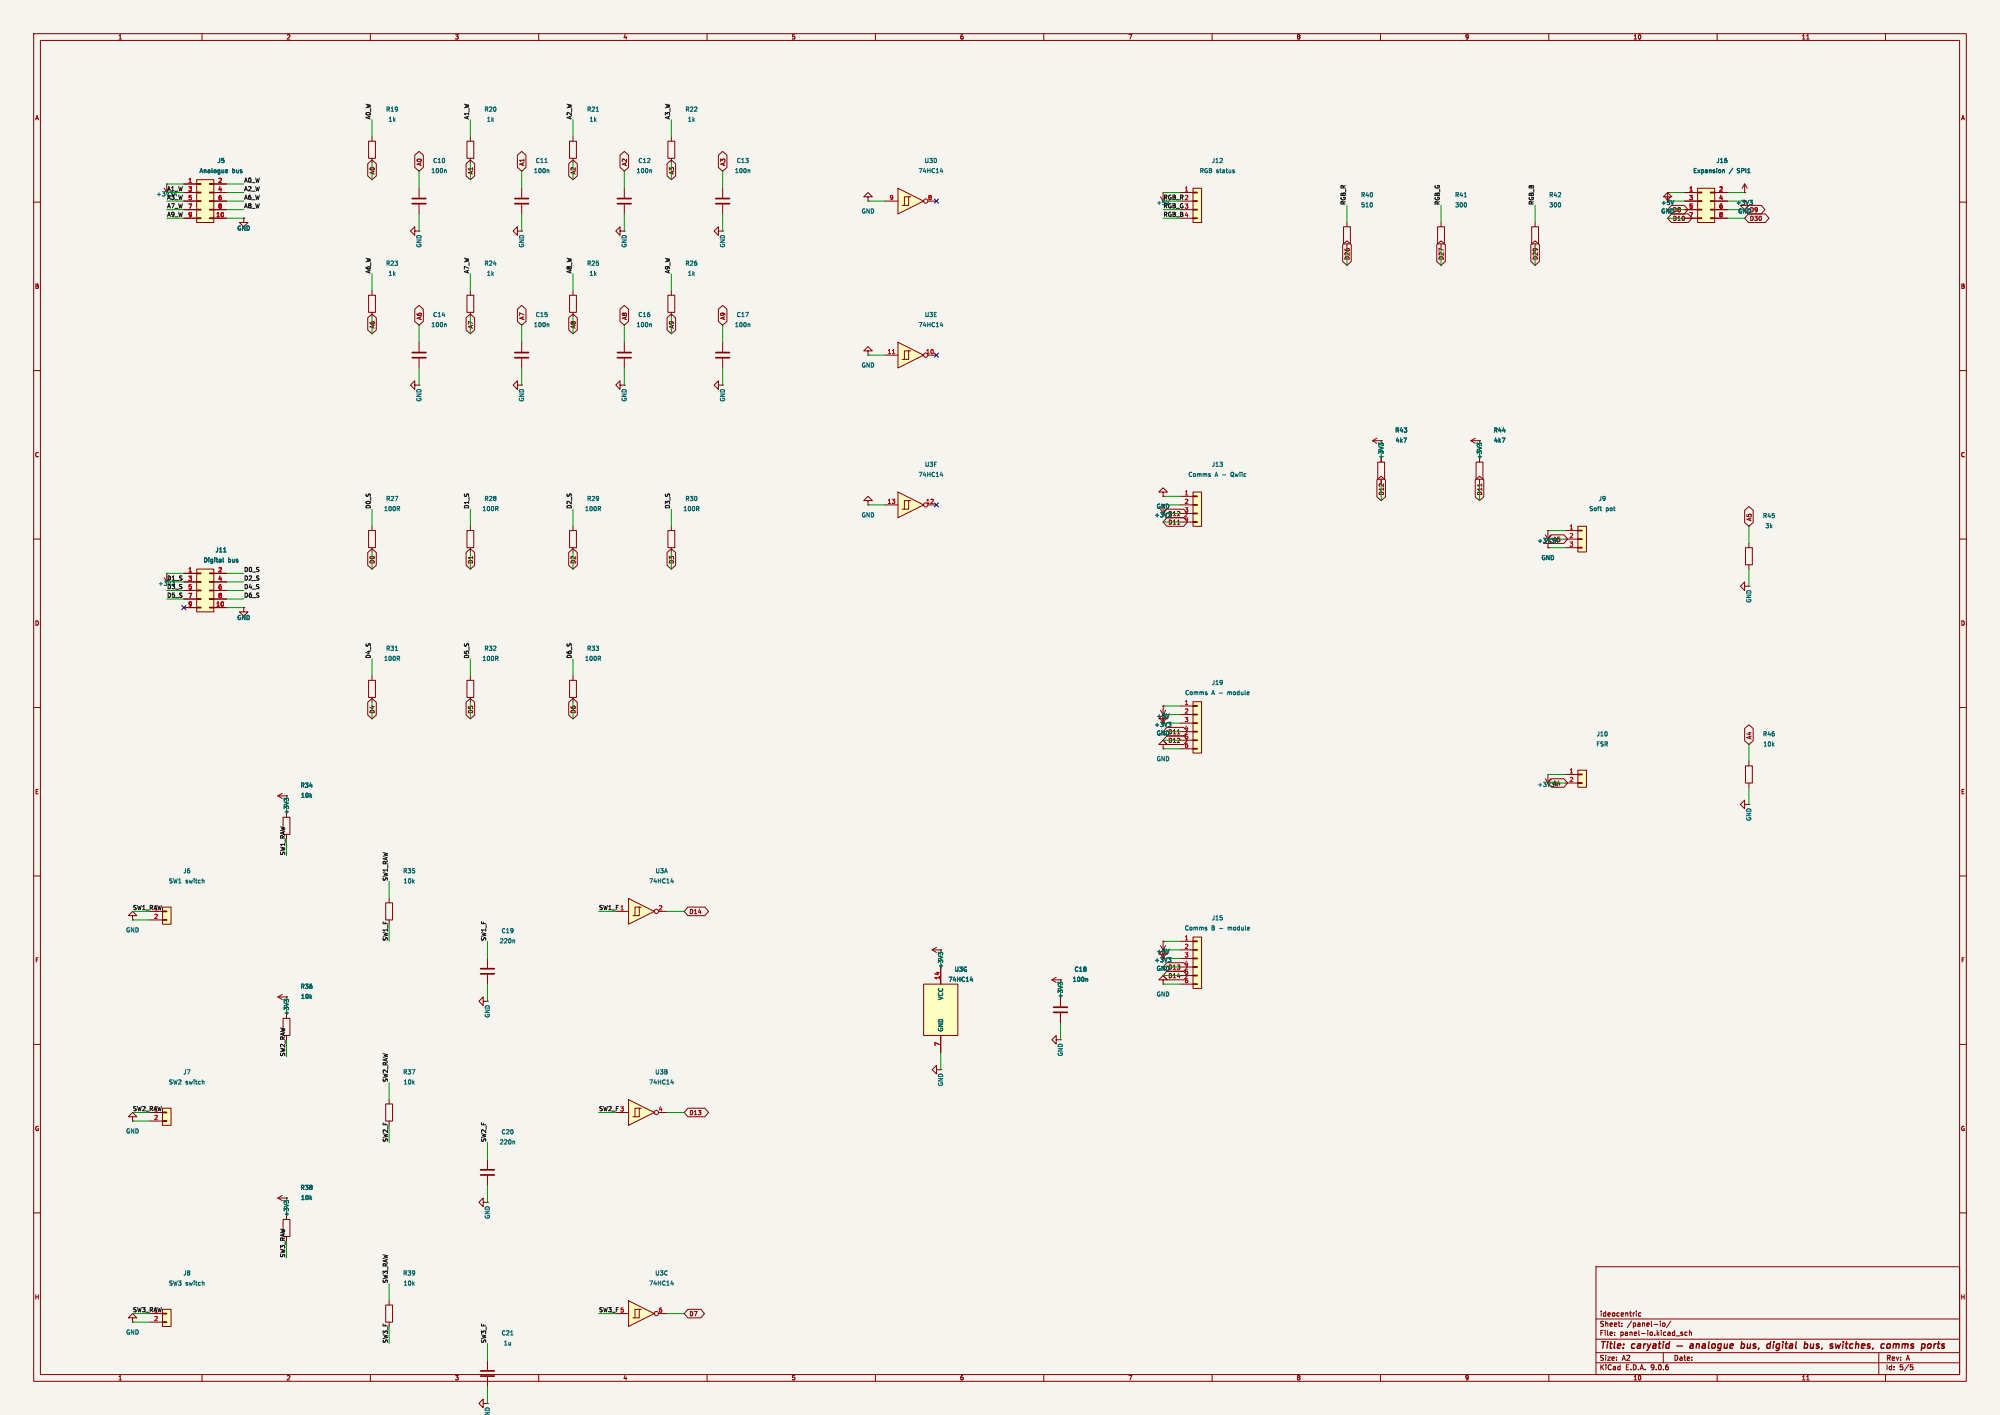
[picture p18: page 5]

ideocentric
File: panel-io.kicad_sch Sheet: /panel-io/

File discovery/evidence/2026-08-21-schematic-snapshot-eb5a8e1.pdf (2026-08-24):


panel-io File: panel-io.kicad_sch

File: caryatid.kicad_sch Sheet: /
Id: 1/5 Title: caryatid þÿ common power and I/O board


VBAT VBAT VOUT GND
PWR_FLAG GND

18650 protected VBAT VBAT VBAT VOUT VOUT

8 EP 17 OUT 10 OUT 11 BAT 2 BAT 3 ~{PGOOD}7 ~{CHG}9 U1 BQ24074RGT GND

Id: 2/5 Title: caryatid þÿ charger, boost, latch, hardware charge LEDs

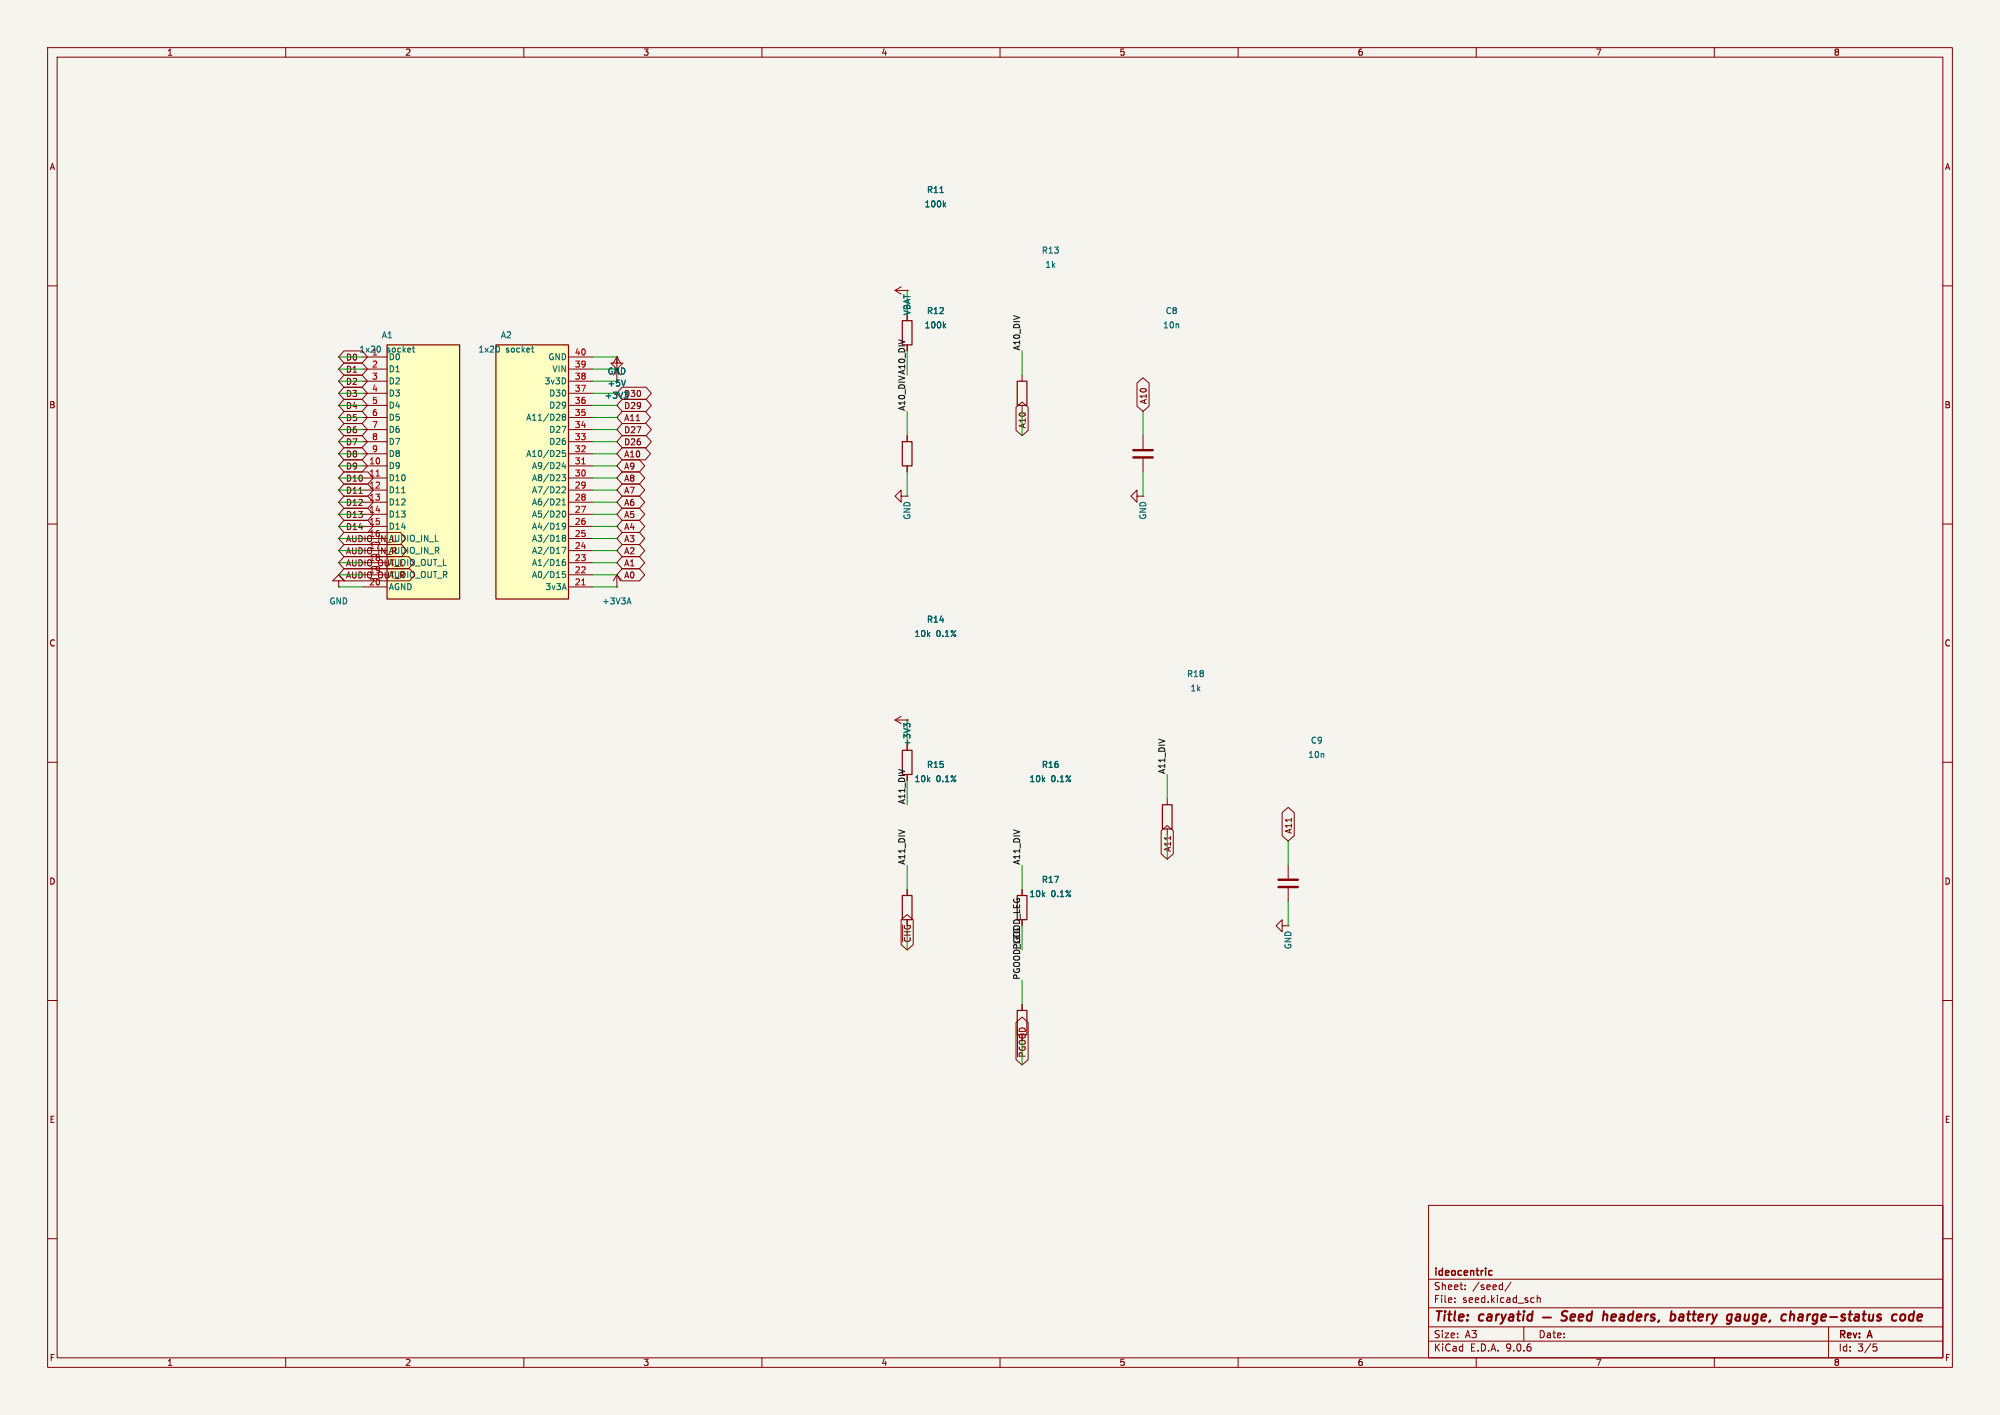
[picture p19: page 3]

File: seed.kicad_sch Sheet: /seed/


JP6 Mic gain select R GND


ideocentric
File: panel-io.kicad_sch Sheet: /panel-io/


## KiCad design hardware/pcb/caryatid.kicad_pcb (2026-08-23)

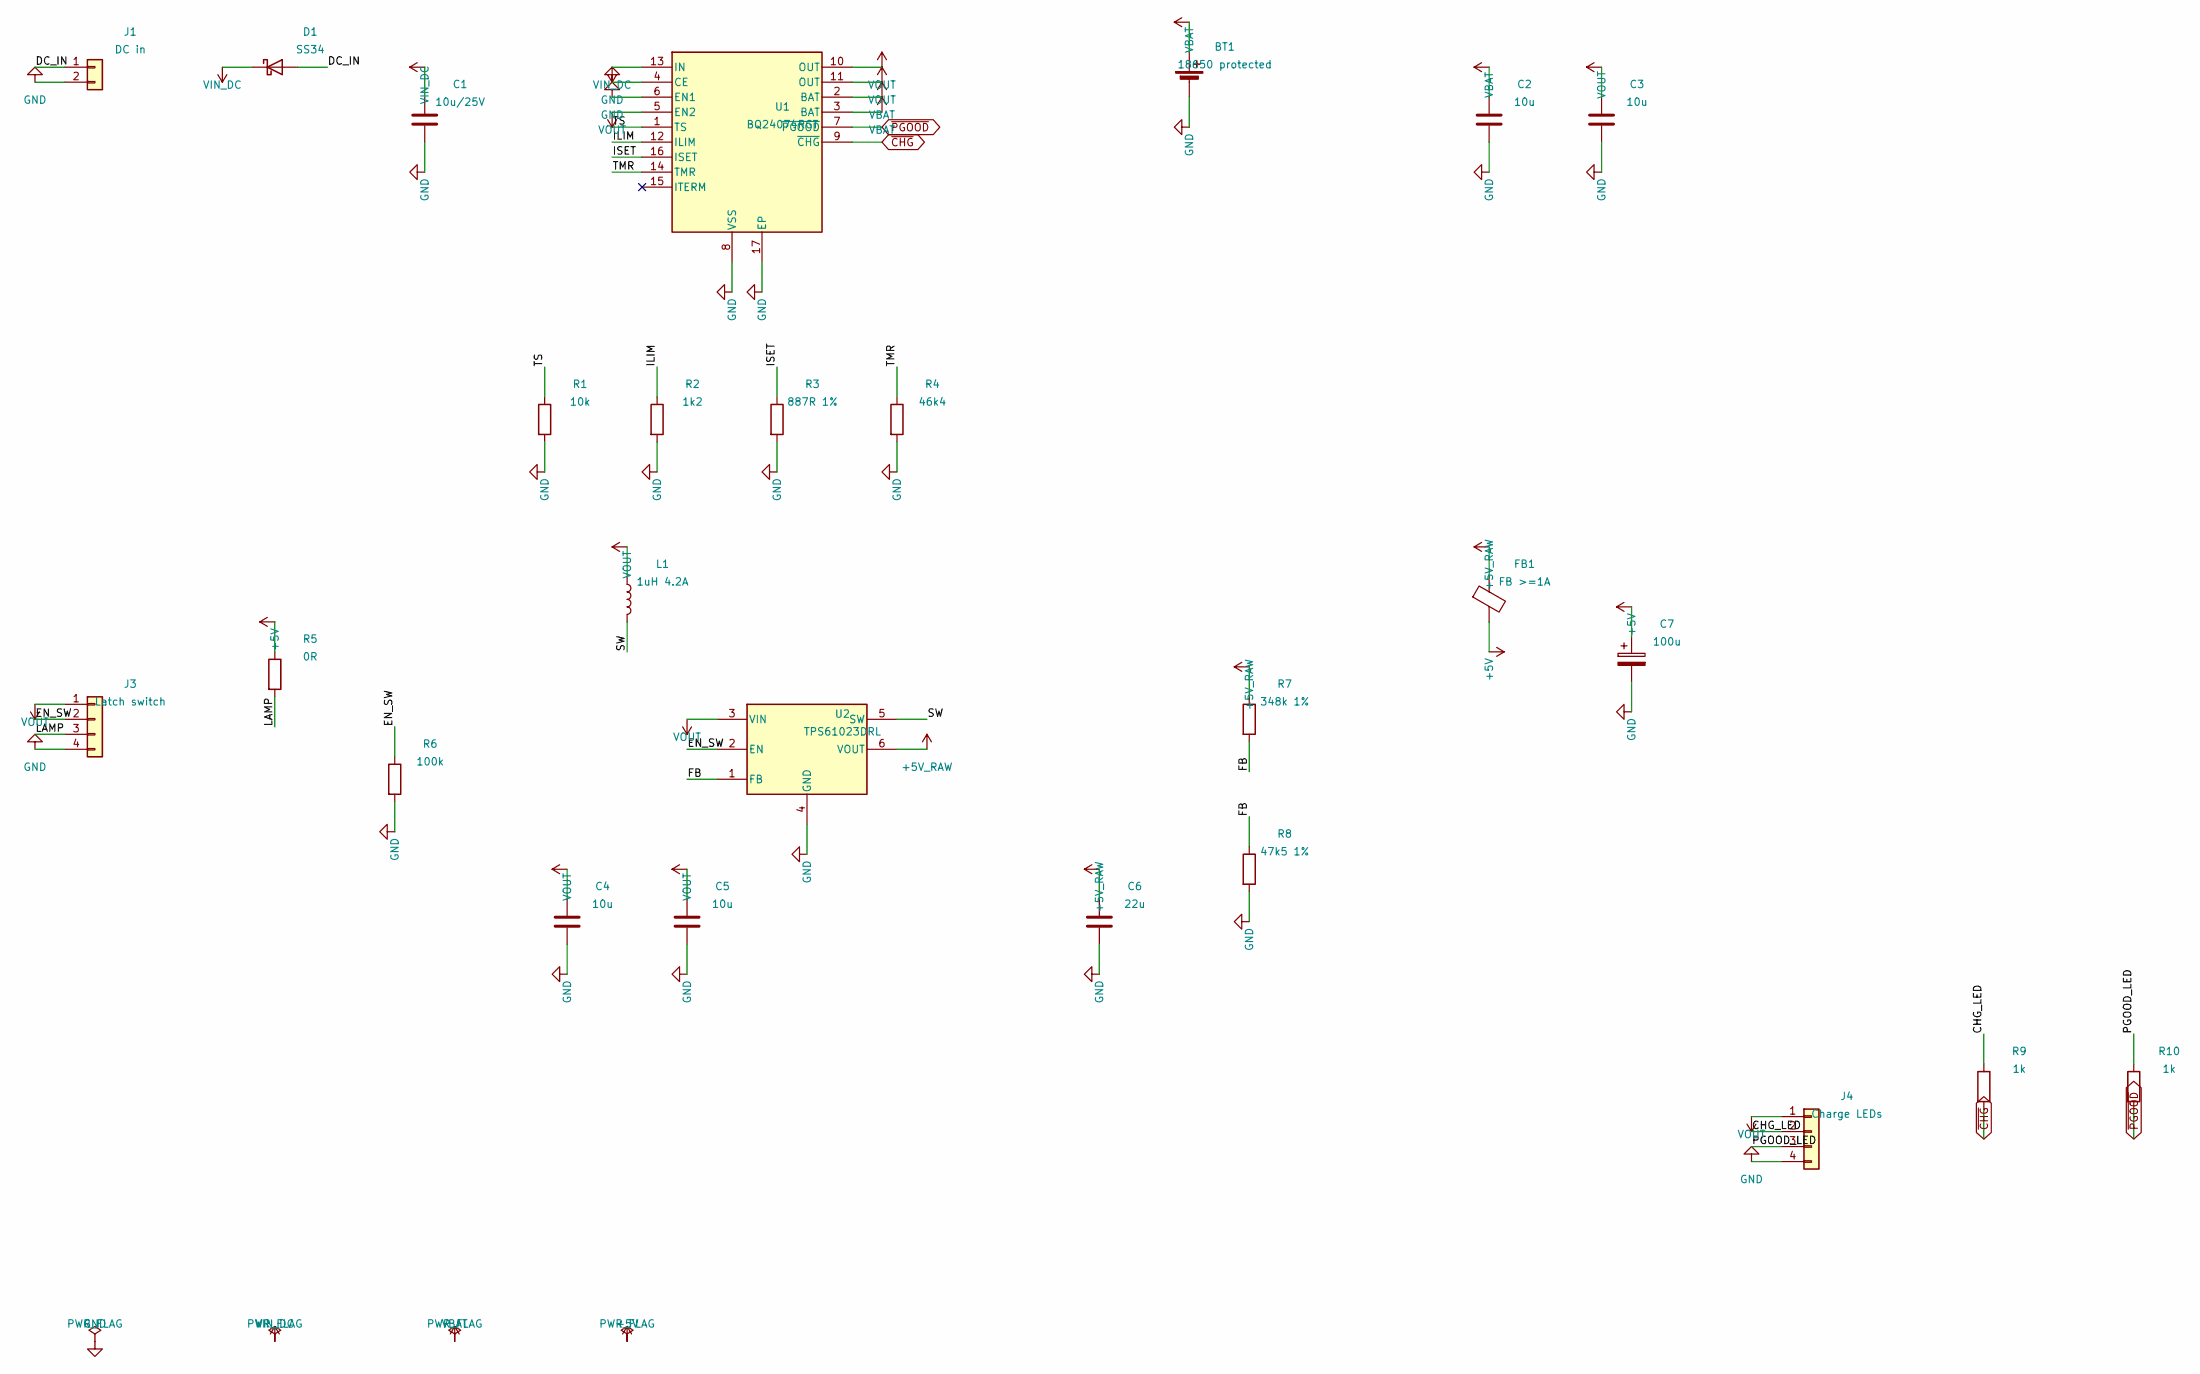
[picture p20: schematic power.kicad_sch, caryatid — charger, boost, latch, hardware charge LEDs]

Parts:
BT1: 18650 protected; BatteryHolder_MPD_BH-18650-PC
C1: 10u/25V; C_0805_2012Metric
C2, C3, C4, C5: 10u; C_0805_2012Metric
C6: 22u; C_0805_2012Metric
C7: 100u; CP_Elec_6.3x5.4
D1: SS34; D_SMA
FB1: FB >=1A; L_0805_2012Metric
J1: DC in; JST_XH_B2B-XH-A_1x02_P2.50mm_Vertical
J3: Latch switch; JST_XH_B4B-XH-A_1x04_P2.50mm_Vertical
J4: Charge LEDs; JST_XH_B4B-XH-A_1x04_P2.50mm_Vertical
L1: 1uH 4.2A; L_Vishay_IFSC-1515AH_4x4x1.8mm
R1: 10k; R_0603_1608Metric
R2: 1k2; R_0603_1608Metric
R3: 887R 1%; R_0603_1608Metric
R4: 46k4; R_0603_1608Metric
R5: 0R; R_0603_1608Metric
R6: 100k; R_0603_1608Metric
R7: 348k 1%; R_0603_1608Metric
R8: 47k5 1%; R_0603_1608Metric
R9, R10: 1k; R_0603_1608Metric
U1: BQ24074RGT; BQ24074RGT_QFN-16-1EP_3x3mm_P0.5mm
U2: TPS61023DRL; SOT-563

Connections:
+5V: C7.1, FB1.2, R5.1; also elsewhere on the board
+5V_RAW: C6.1, FB1.1, R7.1, U2.6 (VOUT)
/power/CHG_LED: J4.2, R9.1
/power/DC_IN: D1.2 (A), J1.1
/power/EN_SW: J3.2, R6.1, U2.2 (EN)
/power/FB: R7.2, R8.1, U2.1 (FB)
/power/ILIM: R2.1, U1.12 (ILIM)
/power/ISET: R3.1, U1.16 (ISET)
/power/LAMP: J3.3, R5.2
/power/PGOOD_LED: J4.3, R10.1
/power/SW: L1.2, U2.5 (SW)
/power/TMR: R4.1, U1.14 (TMR)
/power/TS: R1.1, U1.1 (TS)
GND: BT1.2 (-), C1.2, C2.2, C3.2, C4.2, C5.2, C6.2, C7.2, J1.2, J3.4, J4.4, R1.2, R2.2, R3.2, R4.2, R6.2, R8.2, U1.4 (CE), U1.6 (EN1), U1.8 (VSS), U1.17 (EP), U2.4 (GND); also elsewhere on the board
VBAT: BT1.1 (+), C2.1, U1.2 (BAT), U1.3 (BAT); also elsewhere on the board
VIN_DC: C1.1, D1.1 (K), U1.13 (IN)
VOUT: C3.1, C4.1, C5.1, J3.1, J4.1, L1.1, U1.5 (EN2), U1.10 (OUT), U1.11 (OUT), U2.3 (VIN)
~CHG: R9.2, U1.9 (~CHG); also elsewhere on the board
~PGOOD: R10.2, U1.7 (~PGOOD); also elsewhere on the board

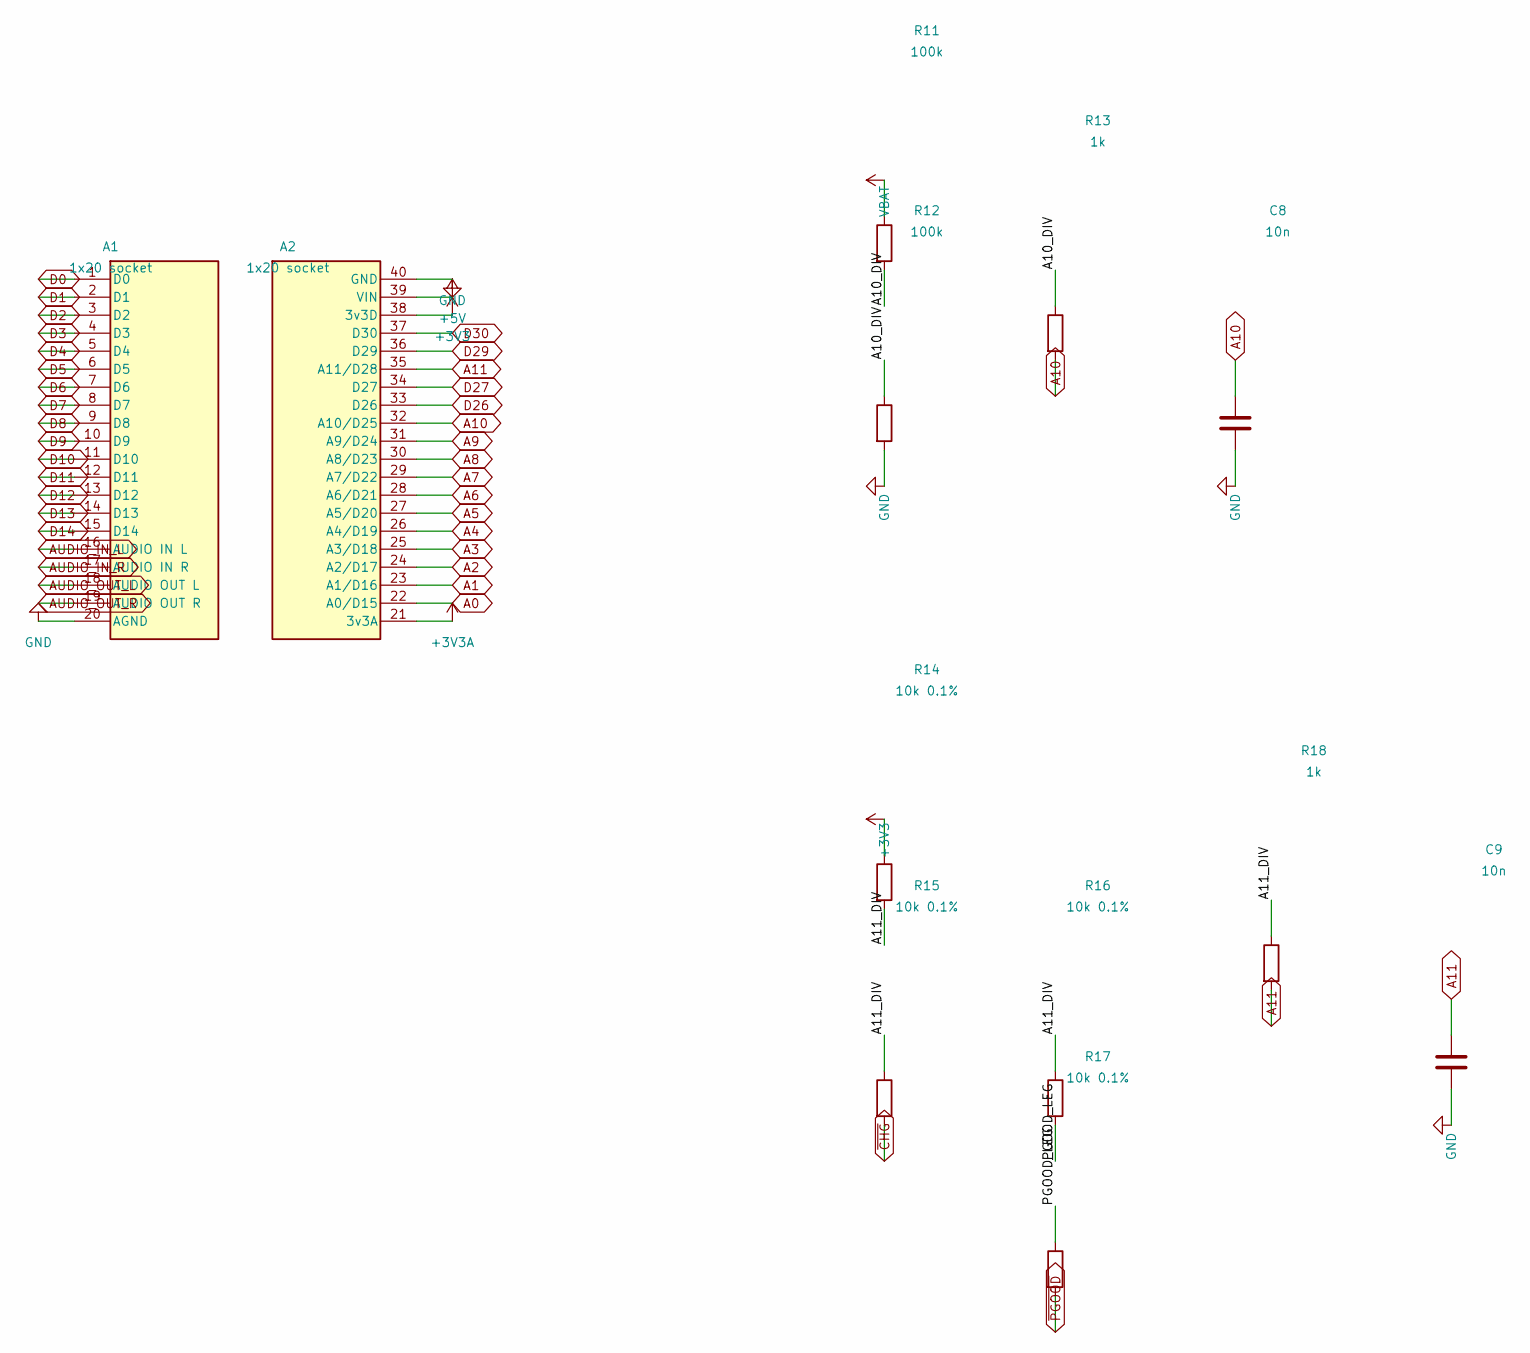
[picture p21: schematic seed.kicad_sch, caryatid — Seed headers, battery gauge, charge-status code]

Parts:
A1: 1x20 socket; DaisySeed_Socket_A_1x20
A2: 1x20 socket; DaisySeed_Socket_B_1x20
C8, C9: 10n; C_0603_1608Metric
R11, R12: 100k; R_0603_1608Metric
R13, R18: 1k; R_0603_1608Metric
R14, R15, R16, R17: 10k 0.1%; R_0603_1608Metric

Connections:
+3V3: A2.38 (3v3D), R14.1; also elsewhere on the board
+3V3A: A2.21 (3v3A); also elsewhere on the board
+5V: A2.39 (VIN); also elsewhere on the board
/seed/A10_DIV: R11.2, R12.1, R13.1
/seed/A11_DIV: R14.2, R15.1, R16.1, R18.1
/seed/PGOOD_LEG: R16.2, R17.1
A0: A2.22 (A0/D15); also elsewhere on the board
A1: A2.23 (A1/D16); also elsewhere on the board
A2: A2.24 (A2/D17); also elsewhere on the board
A3: A2.25 (A3/D18); also elsewhere on the board
A4: A2.26 (A4/D19); also elsewhere on the board
A5: A2.27 (A5/D20); also elsewhere on the board
A6: A2.28 (A6/D21); also elsewhere on the board
A7: A2.29 (A7/D22); also elsewhere on the board
A8: A2.30 (A8/D23); also elsewhere on the board
A9: A2.31 (A9/D24); also elsewhere on the board
A10: A2.32 (A10/D25), C8.1, R13.2
A11: A2.35 (A11/D28), C9.1, R18.2
AUDIO_IN_L: A1.16 (AUDIO_IN_L); also elsewhere on the board
AUDIO_IN_R: A1.17 (AUDIO_IN_R); also elsewhere on the board
AUDIO_OUT_L: A1.18 (AUDIO_OUT_L); also elsewhere on the board
AUDIO_OUT_R: A1.19 (AUDIO_OUT_R); also elsewhere on the board
D0: A1.1 (D0); also elsewhere on the board
D1: A1.2 (D1); also elsewhere on the board
D2: A1.3 (D2); also elsewhere on the board
D3: A1.4 (D3); also elsewhere on the board
D4: A1.5 (D4); also elsewhere on the board
D5: A1.6 (D5); also elsewhere on the board
D6: A1.7 (D6); also elsewhere on the board
D7: A1.8 (D7); also elsewhere on the board
D8: A1.9 (D8); also elsewhere on the board
D9: A1.10 (D9); also elsewhere on the board
D10: A1.11 (D10); also elsewhere on the board
D11: A1.12 (D11); also elsewhere on the board
D12: A1.13 (D12); also elsewhere on the board
D13: A1.14 (D13); also elsewhere on the board
D14: A1.15 (D14); also elsewhere on the board
D26: A2.33 (D26); also elsewhere on the board
D27: A2.34 (D27); also elsewhere on the board
D29: A2.36 (D29); also elsewhere on the board
D30: A2.37 (D30); also elsewhere on the board
GND: A1.20 (AGND), A2.40 (GND), C8.2, C9.2, R12.2; also elsewhere on the board
VBAT: R11.1; also elsewhere on the board
~CHG: R15.2; also elsewhere on the board
~PGOOD: R17.2; also elsewhere on the board

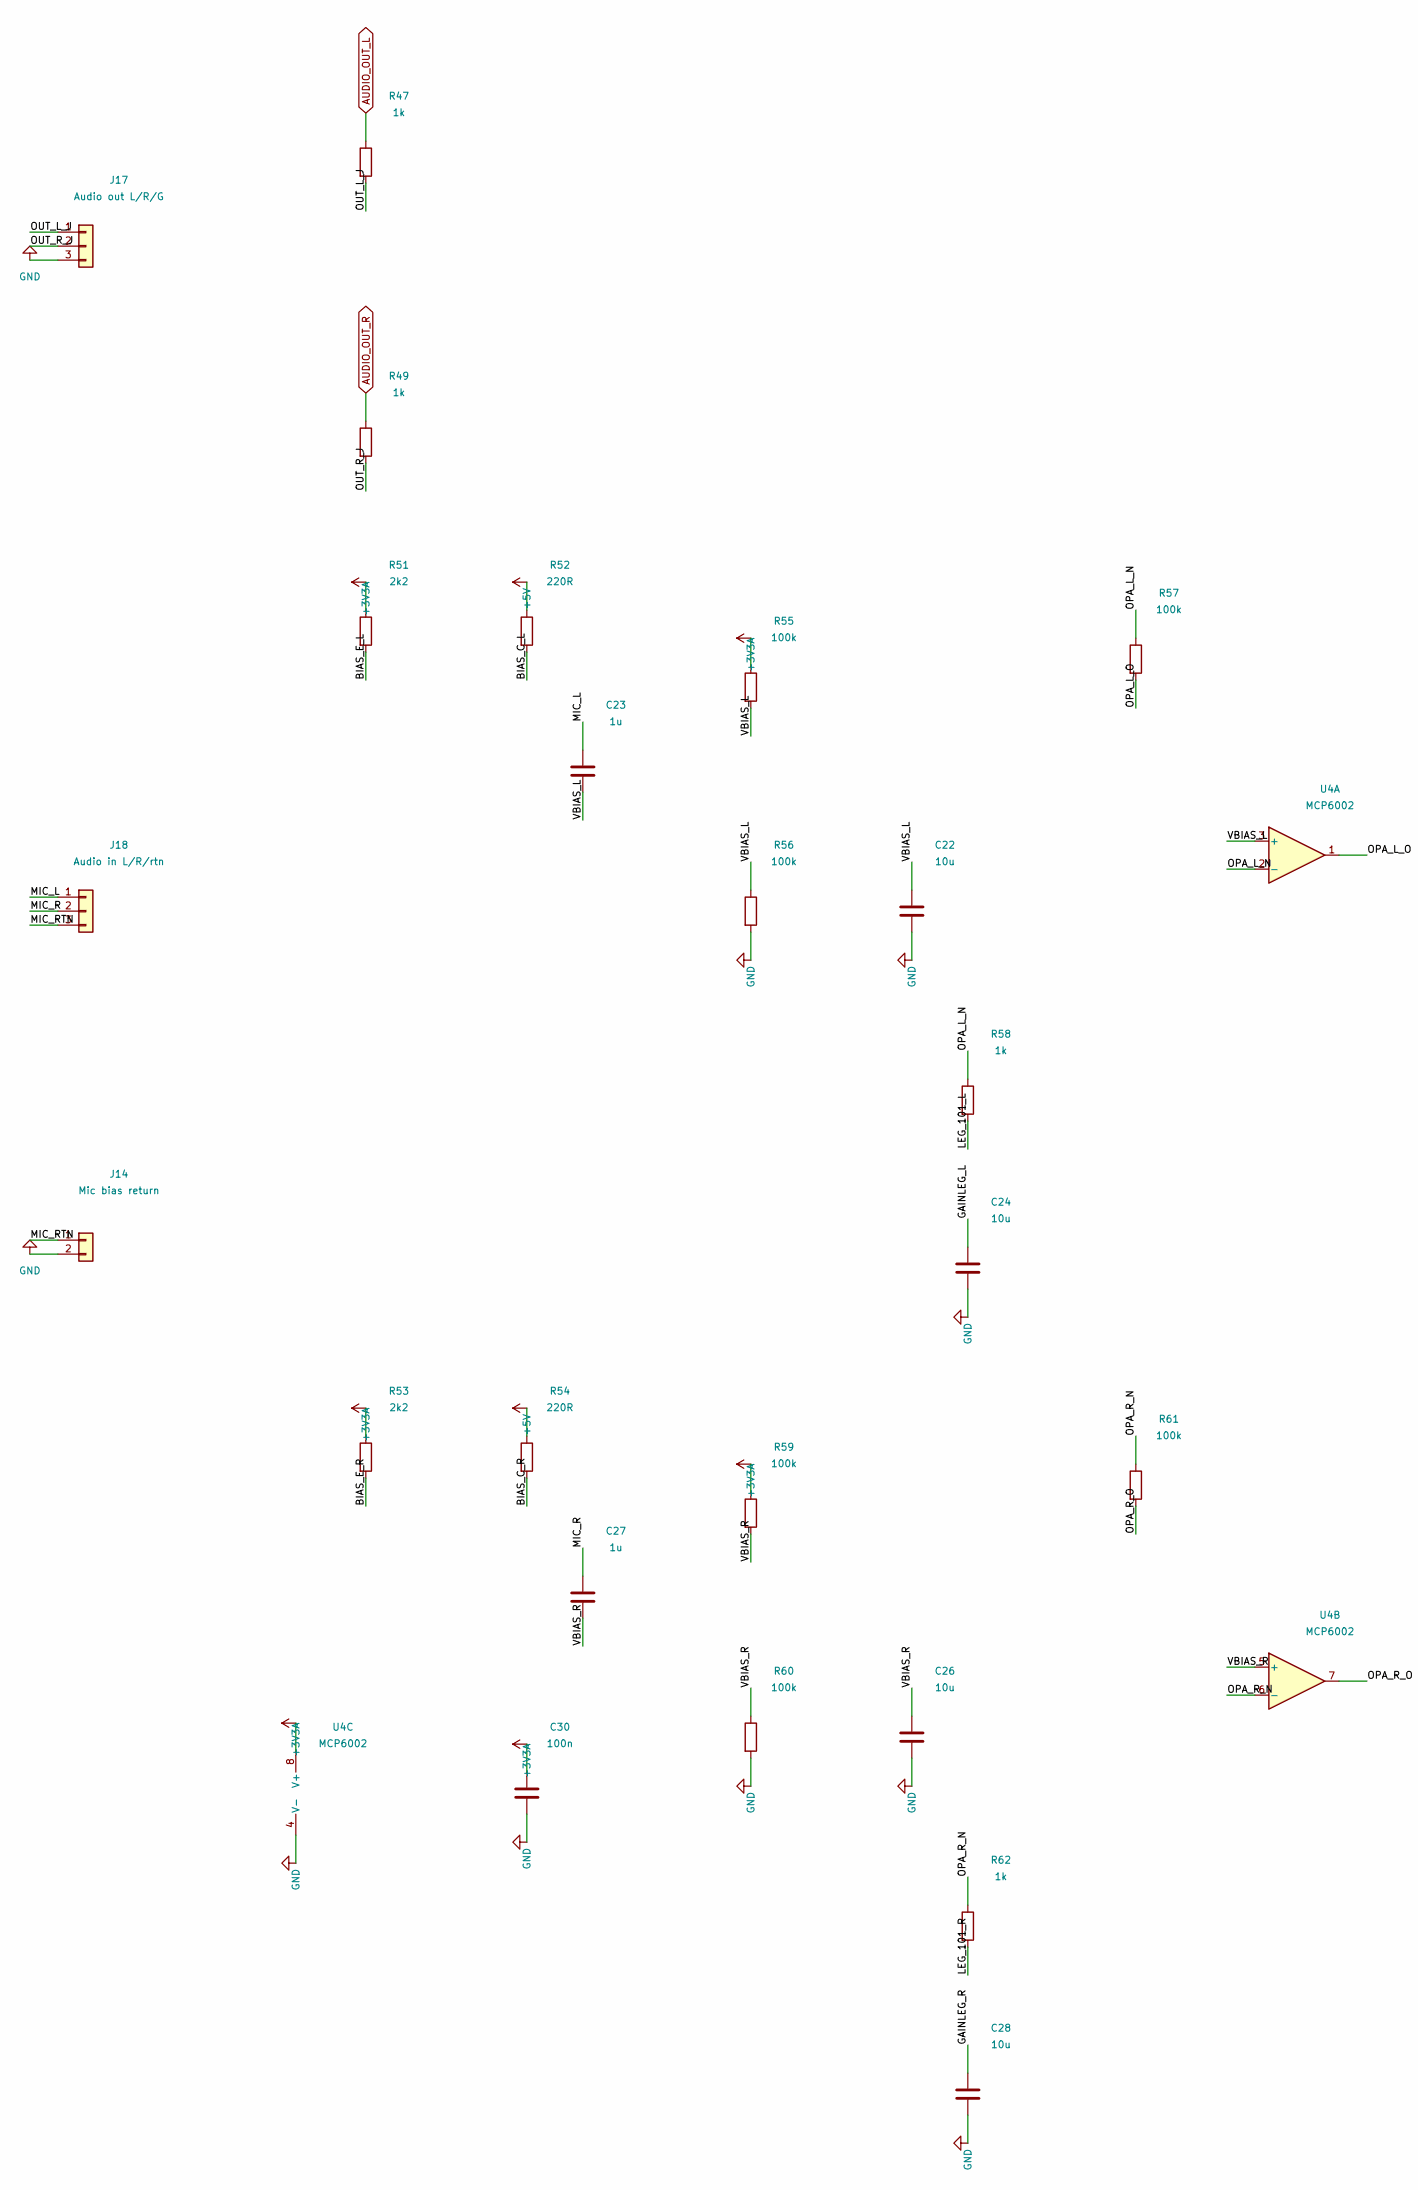
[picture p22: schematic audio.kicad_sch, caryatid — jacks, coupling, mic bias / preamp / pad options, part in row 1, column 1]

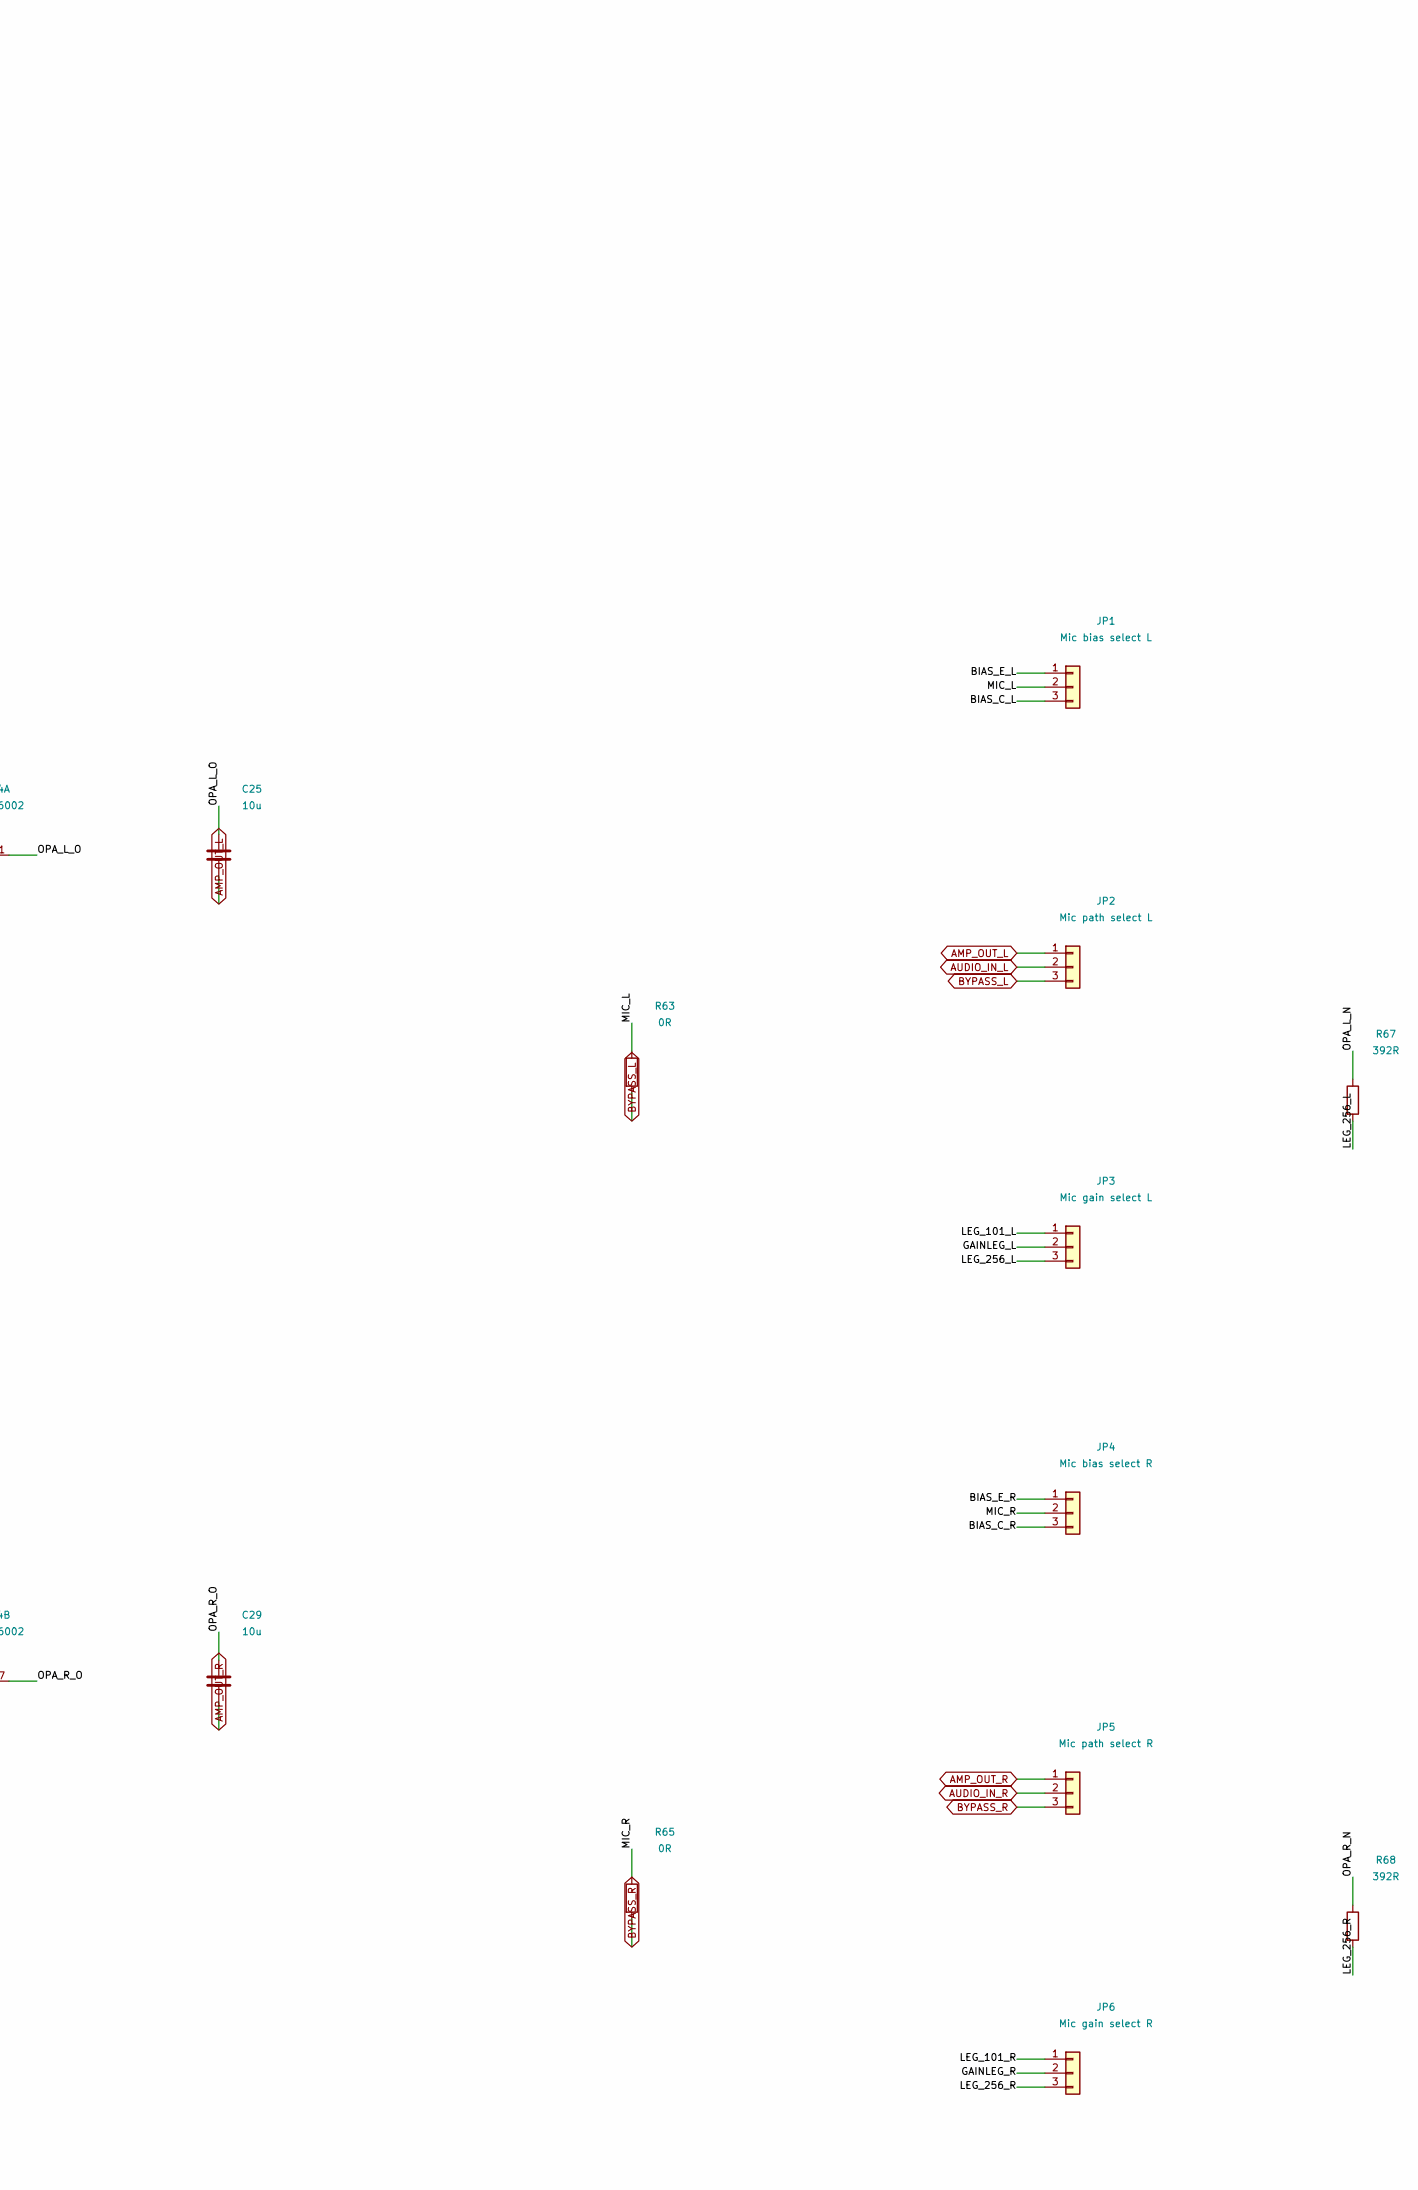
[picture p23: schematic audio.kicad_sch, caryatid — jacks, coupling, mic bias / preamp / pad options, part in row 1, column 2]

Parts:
C22, C24, C25, C26, C28, C29: 10u; C_0805_2012Metric
C23, C27: 1u; C_0603_1608Metric
C30: 100n; C_0603_1608Metric
J14: Mic bias return; JST_XH_B2B-XH-A_1x02_P2.50mm_Vertical
J17: Audio out L/R/G; JST_XH_B3B-XH-A_1x03_P2.50mm_Vertical
J18: Audio in L/R/rtn; JST_XH_B3B-XH-A_1x03_P2.50mm_Vertical
JP1: Mic bias select L; PinHeader_1x03_P2.54mm_Vertical
JP2: Mic path select L; PinHeader_1x03_P2.54mm_Vertical
JP3: Mic gain select L; PinHeader_1x03_P2.54mm_Vertical
JP4: Mic bias select R; PinHeader_1x03_P2.54mm_Vertical
JP5: Mic path select R; PinHeader_1x03_P2.54mm_Vertical
JP6: Mic gain select R; PinHeader_1x03_P2.54mm_Vertical
R47, R49, R58, R62: 1k; R_0603_1608Metric
R51, R53: 2k2; R_0603_1608Metric
R52, R54: 220R; R_0603_1608Metric
R55, R56, R57, R59, R60, R61: 100k; R_0603_1608Metric
R63, R65: 0R; R_0603_1608Metric
R67, R68: 392R; R_0603_1608Metric
U4: MCP6002; SOIC-8_3.9x4.9mm_P1.27mm

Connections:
+3V3A: C30.1, R51.1, R53.1, R55.1, R59.1, U4.8 (V+); also elsewhere on the board
+5V: R52.1, R54.1; also elsewhere on the board
/audio/BIAS_C_L: JP1.3, R52.2
/audio/BIAS_C_R: JP4.3, R54.2
/audio/BIAS_E_L: JP1.1, R51.2
/audio/BIAS_E_R: JP4.1, R53.2
/audio/GAINLEG_L: C24.1, JP3.2
/audio/GAINLEG_R: C28.1, JP6.2
/audio/LEG_101_L: JP3.1, R58.2
/audio/LEG_101_R: JP6.1, R62.2
/audio/LEG_256_L: JP3.3, R67.2
/audio/LEG_256_R: JP6.3, R68.2
/audio/MIC_L: C23.1, J18.1, JP1.2, R63.1
/audio/MIC_R: C27.1, J18.2, JP4.2, R65.1
/audio/MIC_RTN: J14.1, J18.3
/audio/OPA_L_N: R57.1, R58.1, R67.1, U4.2 (-)
/audio/OPA_L_O: C25.1, R57.2, U4.1
/audio/OPA_R_N: R61.1, R62.1, R68.1, U4.6 (-)
/audio/OPA_R_O: C29.1, R61.2, U4.7
/audio/OUT_L_J: J17.1, R47.2
/audio/OUT_R_J: J17.2, R49.2
/audio/VBIAS_L: C22.1, C23.2, R55.2, R56.1, U4.3 (+)
/audio/VBIAS_R: C26.1, C27.2, R59.2, R60.1, U4.5 (+)
AMP_OUT_L: C25.2, JP2.1
AMP_OUT_R: C29.2, JP5.1
AUDIO_IN_L: JP2.2; also elsewhere on the board
AUDIO_IN_R: JP5.2; also elsewhere on the board
AUDIO_OUT_L: R47.1; also elsewhere on the board
AUDIO_OUT_R: R49.1; also elsewhere on the board
BYPASS_L: JP2.3, R63.2
BYPASS_R: JP5.3, R65.2
GND: C22.2, C24.2, C26.2, C28.2, C30.2, J14.2, J17.3, R56.2, R60.2, U4.4 (V-); also elsewhere on the board

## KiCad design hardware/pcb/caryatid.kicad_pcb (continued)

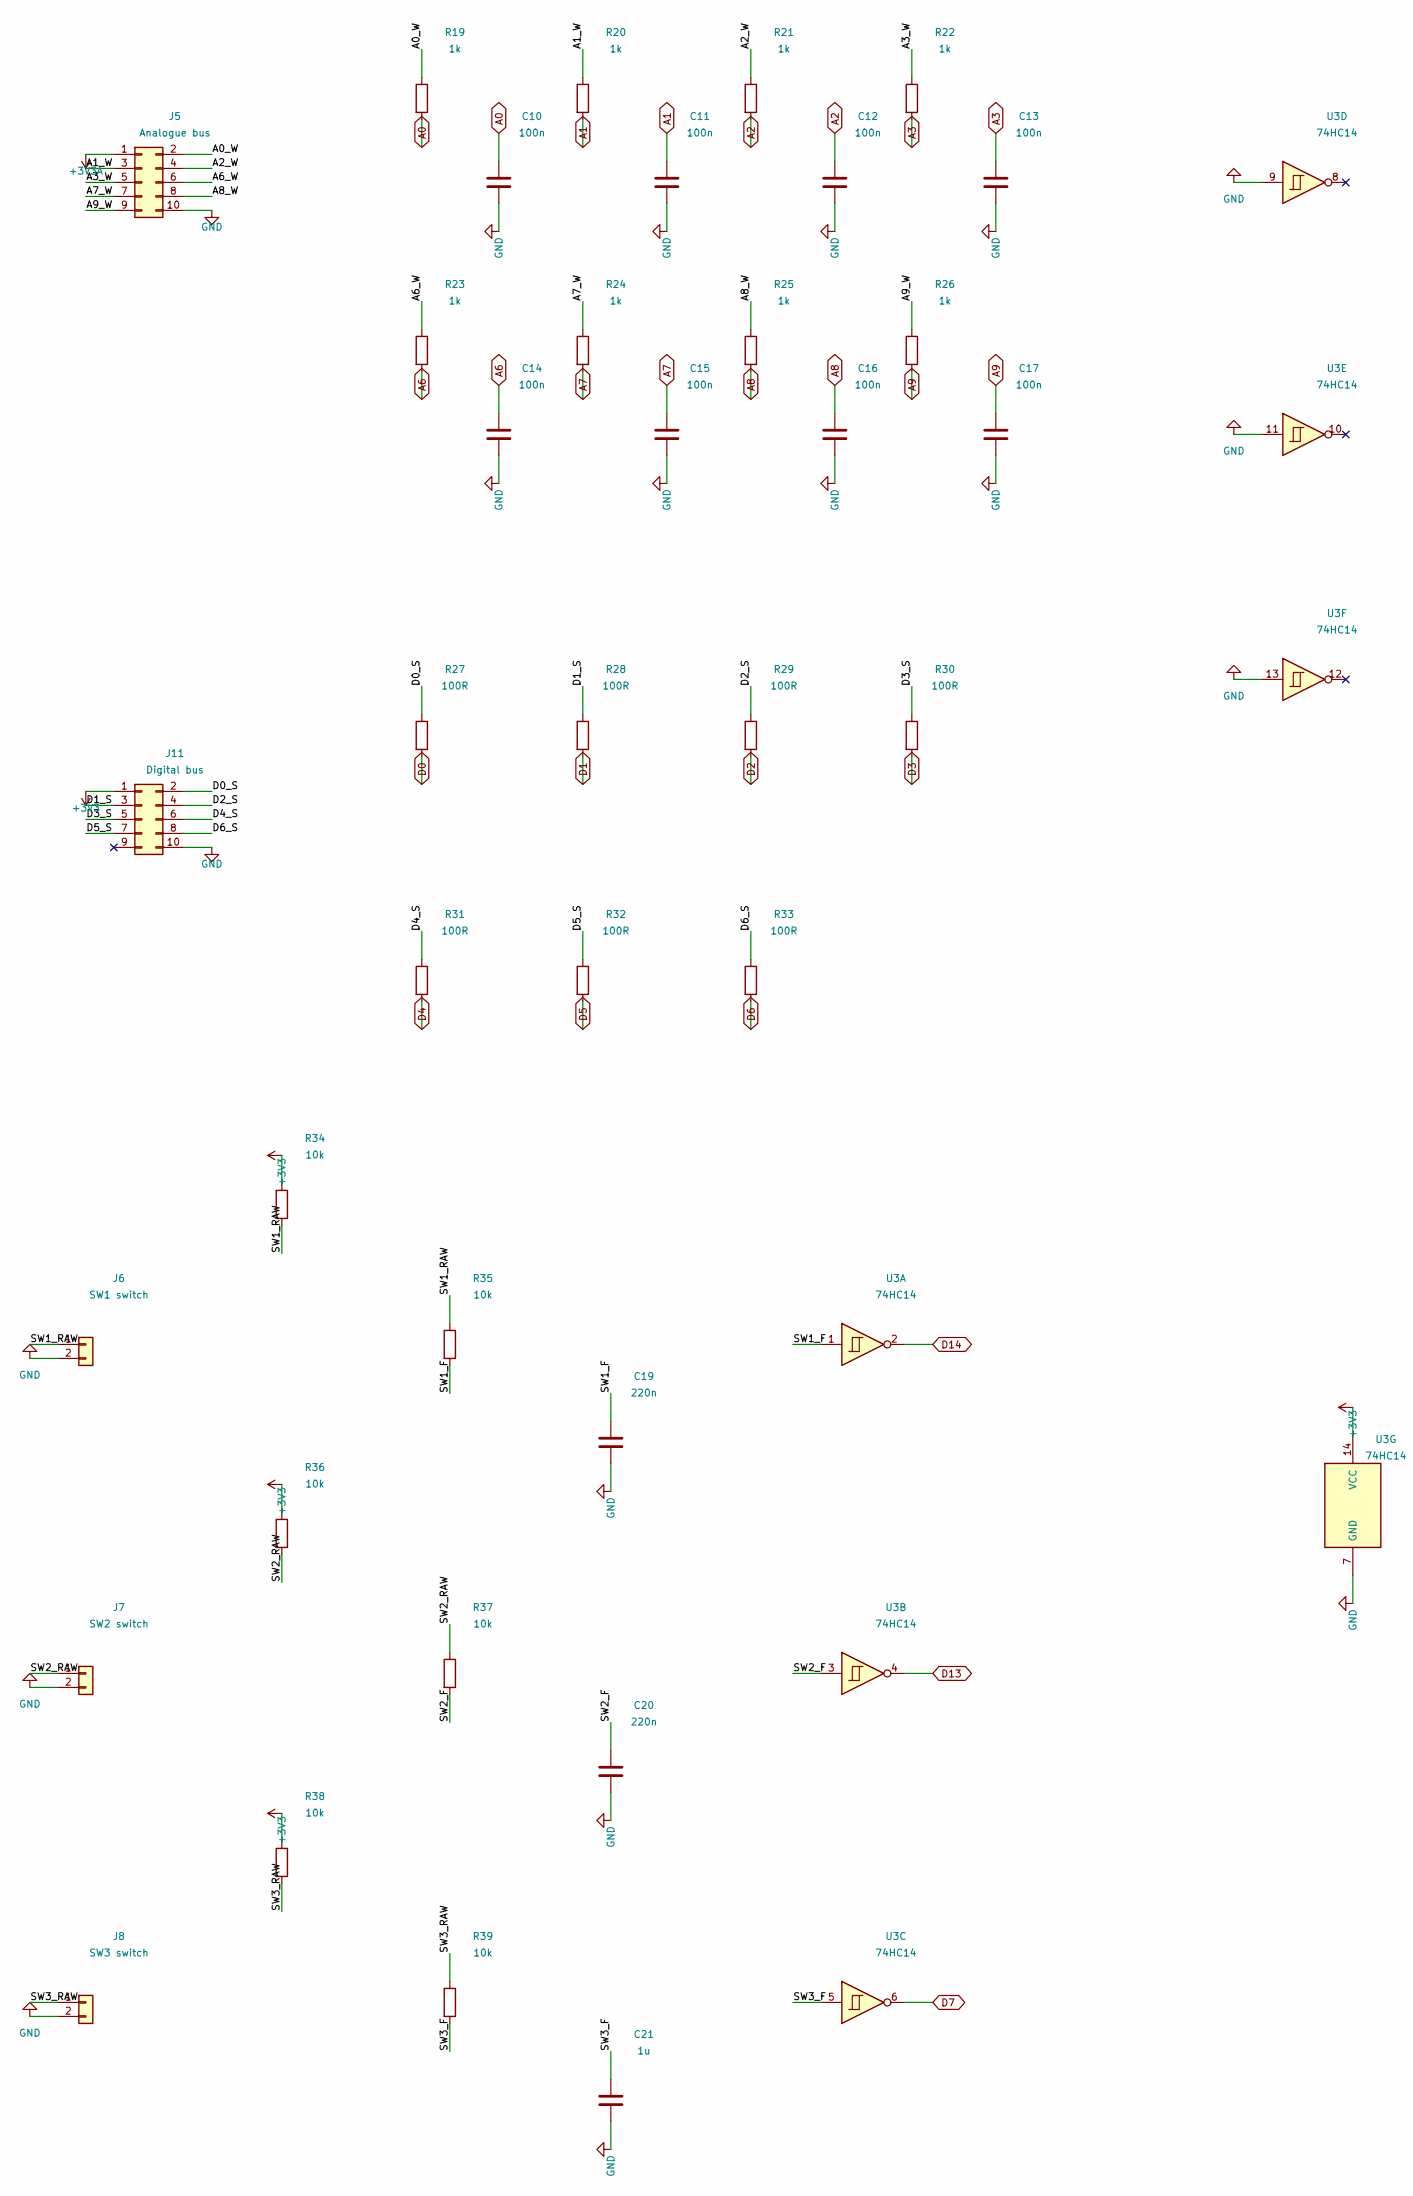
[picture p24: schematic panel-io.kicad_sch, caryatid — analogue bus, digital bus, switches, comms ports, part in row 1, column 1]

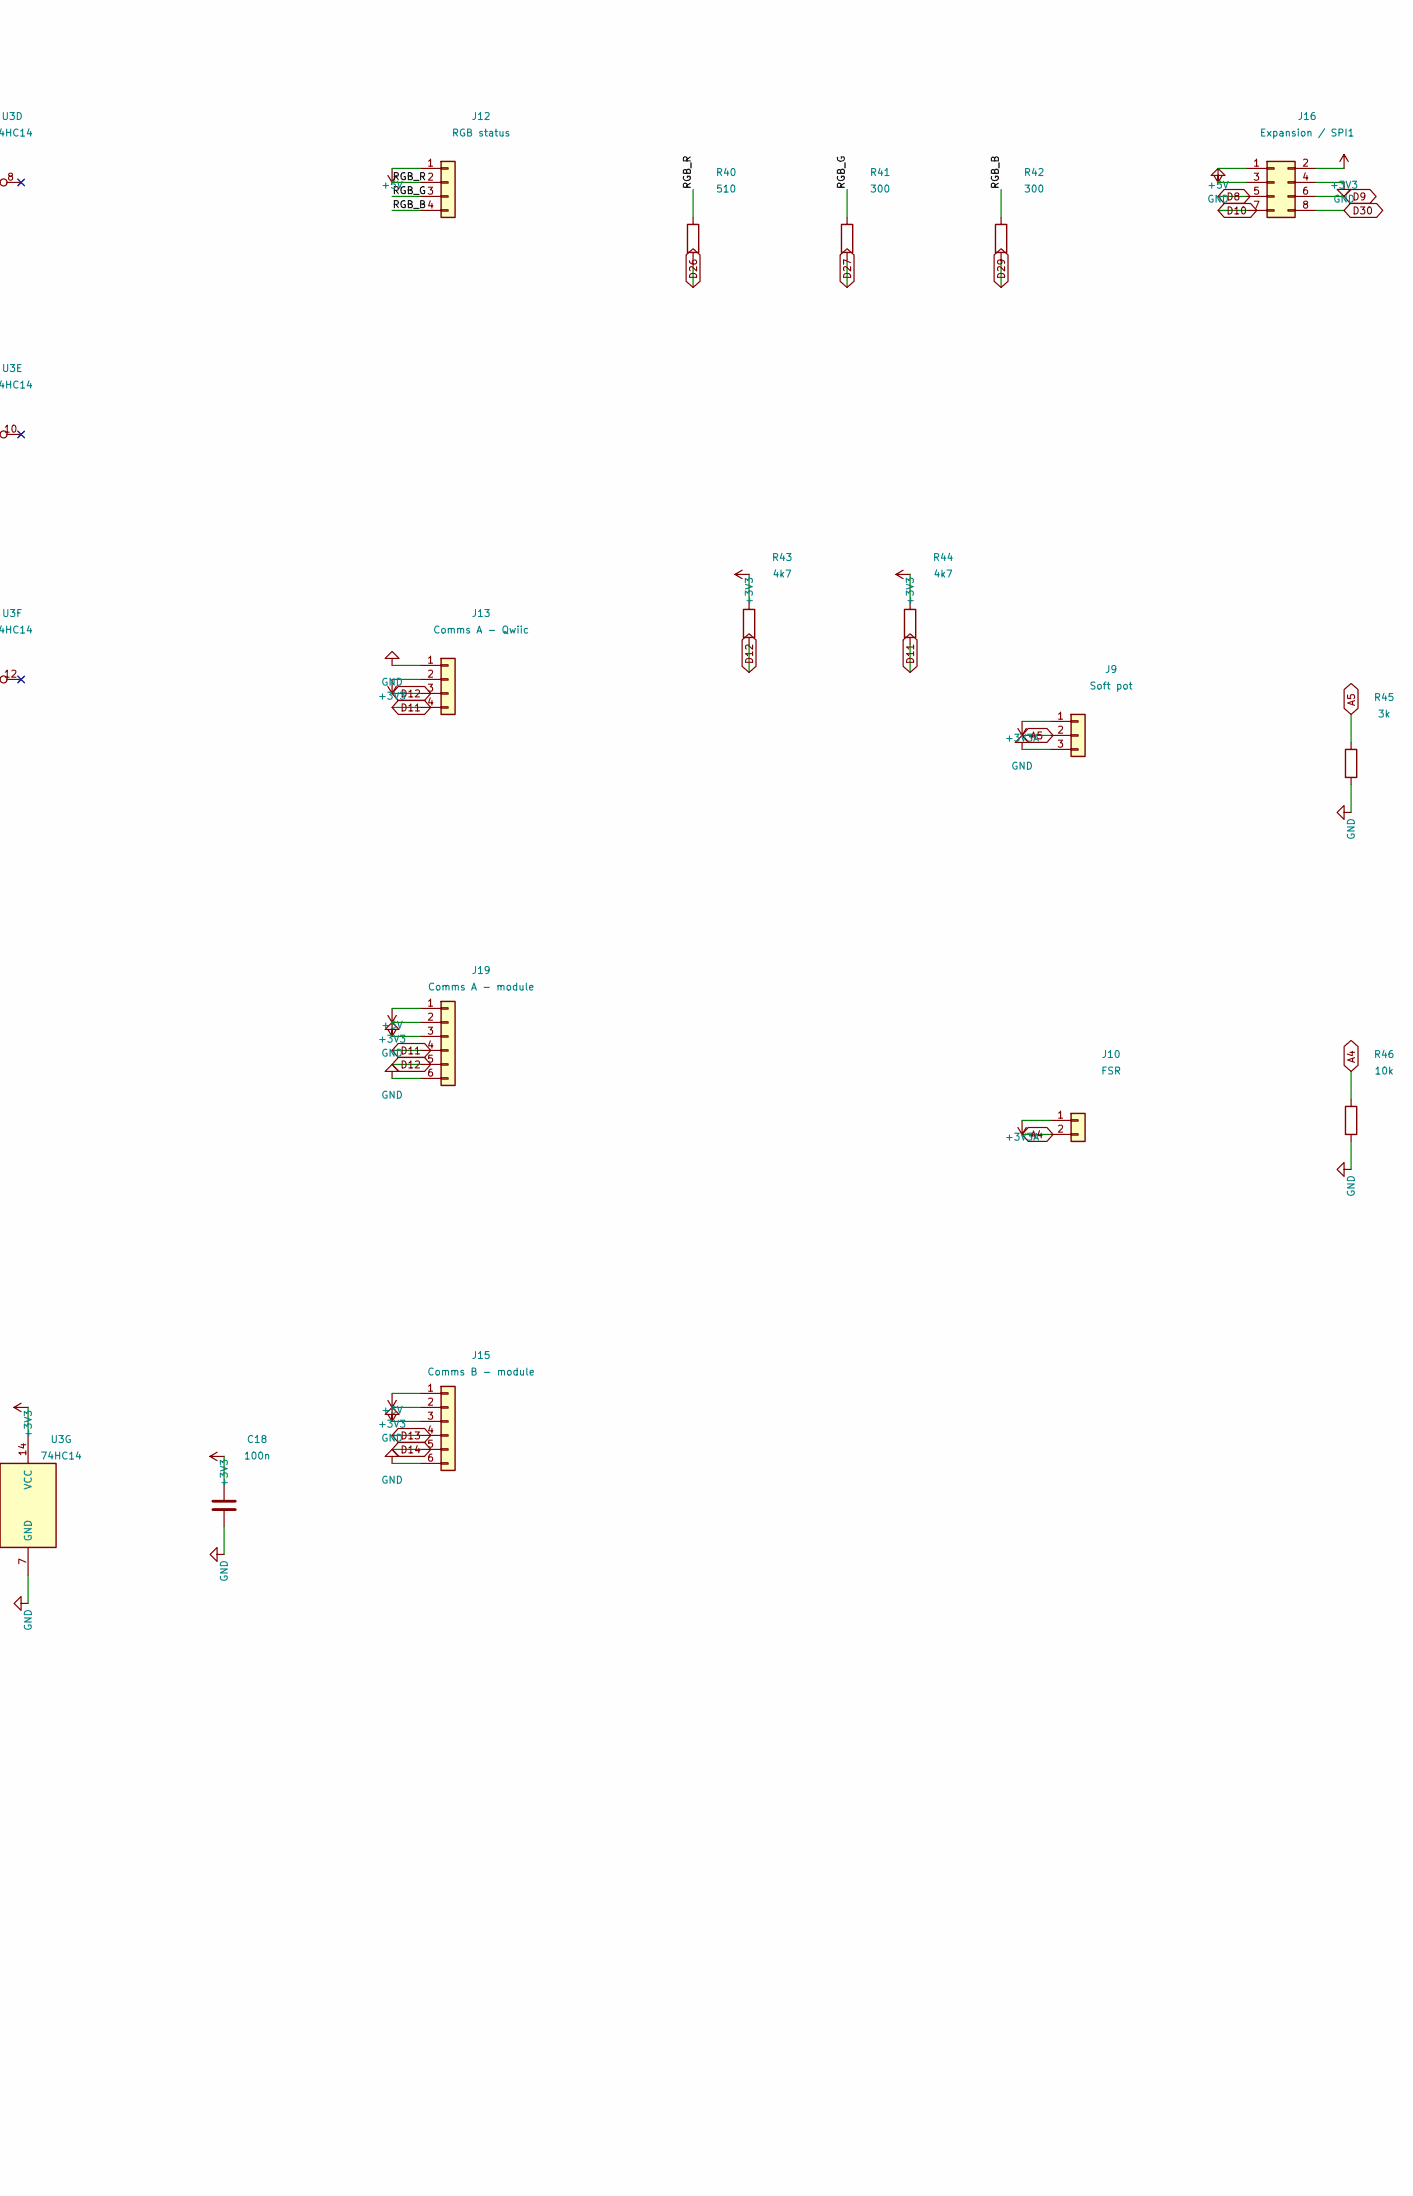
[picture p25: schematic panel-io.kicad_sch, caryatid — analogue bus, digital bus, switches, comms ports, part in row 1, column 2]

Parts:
C10, C11, C12, C13, C14, C15, C16, C17, C18: 100n; C_0603_1608Metric
C19, C20: 220n; C_0603_1608Metric
C21: 1u; C_0603_1608Metric
J5: Analogue bus; IDC-Header_2x05_P2.54mm_Vertical
J6: SW1 switch; JST_XH_B2B-XH-A_1x02_P2.50mm_Vertical
J7: SW2 switch; JST_XH_B2B-XH-A_1x02_P2.50mm_Vertical
J8: SW3 switch; JST_XH_B2B-XH-A_1x02_P2.50mm_Vertical
J9: Soft pot; JST_XH_B3B-XH-A_1x03_P2.50mm_Vertical
J10: FSR; JST_XH_B2B-XH-A_1x02_P2.50mm_Vertical
J11: Digital bus; IDC-Header_2x05_P2.54mm_Vertical
J12: RGB status; JST_XH_B4B-XH-A_1x04_P2.50mm_Vertical
J13: Comms A - Qwiic; JST_SH_SM04B-SRSS-TB_1x04-1MP_P1.00mm_Horizontal
J15: Comms B - module; JST_XH_B6B-XH-A_1x06_P2.50mm_Vertical
J16: Expansion / SPI1; PinHeader_2x04_P2.54mm_Vertical
J19: Comms A - module; JST_XH_B6B-XH-A_1x06_P2.50mm_Vertical
R19, R20, R21, R22, R23, R24, R25, R26: 1k; R_0603_1608Metric
R27, R28, R29, R30, R31, R32, R33: 100R; R_0603_1608Metric
R34, R35, R36, R37, R38, R39, R46: 10k; R_0603_1608Metric
R40: 510; R_0603_1608Metric
R41, R42: 300; R_0603_1608Metric
R43, R44: 4k7; R_0603_1608Metric
R45: 3k; R_0603_1608Metric
U3: 74HC14; SOIC-14_3.9x8.7mm_P1.27mm

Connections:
+3V3: C18.1, J11.1, J13.2, J15.2, J16.2, J19.2, R34.1, R36.1, R38.1, R43.1, R44.1, U3.14 (VCC); also elsewhere on the board
+3V3A: J5.1, J9.1, J10.1; also elsewhere on the board
+5V: J12.1, J15.1, J16.1, J19.1; also elsewhere on the board
/panel-io/A0_W: J5.2, R19.1
/panel-io/A1_W: J5.3, R20.1
/panel-io/A2_W: J5.4, R21.1
/panel-io/A3_W: J5.5, R22.1
/panel-io/A6_W: J5.6, R23.1
/panel-io/A7_W: J5.7, R24.1
/panel-io/A8_W: J5.8, R25.1
/panel-io/A9_W: J5.9, R26.1
/panel-io/D0_S: J11.2, R27.1
/panel-io/D1_S: J11.3, R28.1
/panel-io/D2_S: J11.4, R29.1
/panel-io/D3_S: J11.5, R30.1
/panel-io/D4_S: J11.6, R31.1
/panel-io/D5_S: J11.7, R32.1
/panel-io/D6_S: J11.8, R33.1
/panel-io/RGB_B: J12.4, R42.1
/panel-io/RGB_G: J12.3, R41.1
/panel-io/RGB_R: J12.2, R40.1
/panel-io/SW1_F: C19.1, R35.2, U3.1
/panel-io/SW1_RAW: J6.1, R34.2, R35.1
/panel-io/SW2_F: C20.1, R37.2, U3.3
/panel-io/SW2_RAW: J7.1, R36.2, R37.1
/panel-io/SW3_F: C21.1, R39.2, U3.5
/panel-io/SW3_RAW: J8.1, R38.2, R39.1
A0: C10.1, R19.2; also elsewhere on the board
A1: C11.1, R20.2; also elsewhere on the board
A2: C12.1, R21.2; also elsewhere on the board
A3: C13.1, R22.2; also elsewhere on the board
A4: J10.2, R46.1; also elsewhere on the board
A5: J9.2, R45.1; also elsewhere on the board
A6: C14.1, R23.2; also elsewhere on the board
A7: C15.1, R24.2; also elsewhere on the board
A8: C16.1, R25.2; also elsewhere on the board
A9: C17.1, R26.2; also elsewhere on the board
D0: R27.2; also elsewhere on the board
D1: R28.2; also elsewhere on the board
D2: R29.2; also elsewhere on the board
D3: R30.2; also elsewhere on the board
D4: R31.2; also elsewhere on the board
D5: R32.2; also elsewhere on the board
D6: R33.2; also elsewhere on the board
D7: U3.6; also elsewhere on the board
D8: J16.5; also elsewhere on the board
D9: J16.6; also elsewhere on the board
D10: J16.7; also elsewhere on the board
D11: J13.4, J19.4, R44.2; also elsewhere on the board
D12: J13.3, J19.5, R43.2; also elsewhere on the board
D13: J15.4, U3.4; also elsewhere on the board
D14: J15.5, U3.2; also elsewhere on the board
D26: R40.2; also elsewhere on the board
D27: R41.2; also elsewhere on the board
D29: R42.2; also elsewhere on the board
D30: J16.8; also elsewhere on the board
GND: C10.2, C11.2, C12.2, C13.2, C14.2, C15.2, C16.2, C17.2, C18.2, C19.2, C20.2, C21.2, J5.10, J6.2, J7.2, J8.2, J9.3, J11.10, J13.1, J15.3, J15.6, J16.3, J16.4, J19.3, J19.6, R45.2, R46.2, U3.7 (GND), U3.9, U3.11, U3.13; also elsewhere on the board

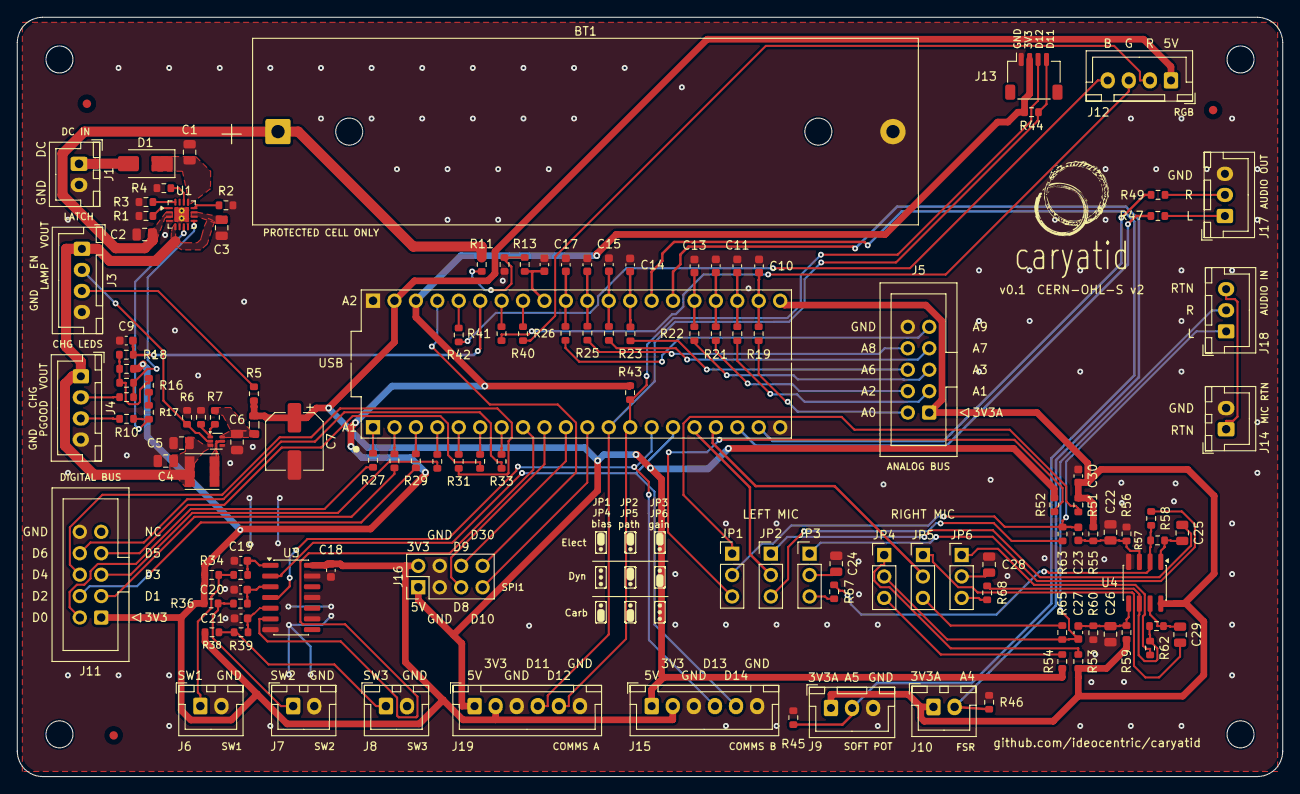
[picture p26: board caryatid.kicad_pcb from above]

Board: 2 copper layers, 150.0 x 90.0 mm, 135 parts (0 on the bottom side), 108 nets.

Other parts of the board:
FID1, FID2, FID3: Fiducial_1mm_Mask2mm
H1, H2, H3, H4: MountingHole_3.2mm_M3

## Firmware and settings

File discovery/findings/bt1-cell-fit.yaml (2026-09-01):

id: BT1-cell-fit
kind: other
source_claim: >-
  That BT1 (MPD BH-18650-PC) and a protected 18650 are compatible. Never stated
  outright anywhere; it was assumed by every document that discusses the battery,
  and the board silkscreens "PROTECTED CELL ONLY" beside BT1, which asserts the
  requirement without ever checking that a protected cell physically fits.
source_ref: >-
  hardware/pcb/lcsc.yaml self_fit.BT1; docs/sourcing.md; the "PROTECTED CELL
  ONLY" gr_text at hardware/pcb/caryatid.kicad_pcb:38541
resource: >-
  MPD BH-18650-PC holder (Digi-Key 3029216) against Orbtronic 3400 mAh protected
  button-top 18650 (Panasonic NCR18650B core), five of each
status: confirmed    # RESOLVED 2026-09-01 by the parts in hand. Read `resolution_2026_09_01`.

measured:
  holder:
    part: MPD BH-18650-PC
    accepts_cell_length_mm: [65, 68]
    wording: "65-68MM in length only"
    named_compatible_examples: [Panasonic NCR 18650B, Samsung 26J]
    top_type: button top only, protected (PCB)
    contacts: 302 stainless spring temper, nickel plated
    cavity_length_mm: null      # NOT PUBLISHED, see notes
    contact_travel_mm: null     # NOT PUBLISHED
  cell:
    part: Orbtronic 3400 mAh protected button top
    core: Panasonic NCR18650B
    length_mm: 68.9
    length_tolerance_mm: 0.03
    diameter_mm: 18.6
    diameter_tolerance_mm: 0.03
    capacity_mah: 3400
    length_measured_mm: 69.48   # Matt, in hand, INCLUDING the shrinkwrap
  board_commitment:
    # Measured from hardware/pcb/caryatid.kicad_pcb 2026-08-23. This is what a
    # holder substitution would have to match, or the board changes.
    pin_spacing_mm: 72.900      # pads at x 80.900 and 153.800
    m3_hole_spacing_mm: 55.610  # NPTH d3.2 at x 89.345 and 144.955
    courtyard_mm: [79.20, 22.40]
  holder_cavity:
    # SUPERSEDED by the STEP model below. The 72.9 mm figure is neither a cavity
    # nor a coincidence: it is the PIN SPACING, and it also happens to be twice
    # the 36.640 mm contact root position.
    internal_length_mm: 72.9
    figure_is_ambiguous: true
  step_model:
    # local/reference/BH-18650-PC.STEP, SolidWorks 2016, AP214, dated 2019-11-12.
    # Three named solids: Housing, Positive Contact, Negative Contact.
    source: local/reference/BH-18650-PC.STEP
    evidence_file: discovery/evidence/2026-08-23-bt1-step-geometry.txt
    housing_overall_mm: [77.700, 25.235, 20.900]
    contact_face_at_rest_mm: 30.752      # each side, so 61.504 mm apart
    contact_root_mm: 36.640              # where it anchors
    contact_length_mm: 5.888             # 36.640 - 30.752, the deflection budget
    housing_inner_wall_mm: 35.450        # innermost housing material in the
                                         # cell's swept envelope, so the cell
                                         # cannot exceed 70.900 mm at all
    free_separation_mm: 61.504
    hard_stop_cell_length_mm: 70.900
    spring_wire_width_mm: 0.38
    # Derived from MPD's OWN two numbers, not from anything measured:
    # a 72.9 mm cavity accepting 65-68 mm cells means the spring occupies
    # between 4.9 mm (at the longest cell) and 7.9 mm (at the shortest).
    spring_window_mm: [4.9, 7.9]
    gap_with_this_cell_mm: 3.42 # 72.9 - 69.48
  delta_mm: 1.48                # 69.48 measured, against a 68 mm stated maximum

resolution_2026_09_01:
  what_happened: >-
    THE HOLDERS ARRIVED AND THE CELL FITS. Matt, 2026-09-01: "The battery fits
    perfectly in the holder." That is the one test this record said could not be
    substituted for: "only a holder in hand says it seats with sane force."

  a_spec_and_a_part_disagreed_and_the_part_wins: >-
    Nothing is withdrawn. MPD really does state 65-68 mm, and the cell really is
    69.48 mm with its wrap, 1.48 mm over. BOTH REMAIN TRUE. What the fit
    establishes is that MPD'S STATED RANGE IS CONSERVATIVE RATHER THAN
    DIMENSIONAL, which is what the STEP analysis of 2026-08-23 predicted and
    could not prove.

  the_geometry_agrees_so_this_is_not_luck: >-
    From the STEP model: free contact separation 61.504 mm, deflection budget
    5.888 mm per contact, housing hard stop 70.900 mm.

      cell        total defl   per contact   % of budget
      65.00 mm      3.496        1.748          29.7    MPD stated minimum
      68.00 mm      6.496        3.248          55.2    MPD stated MAXIMUM
      69.48 mm      7.976        3.988          67.7    THIS CELL
      70.90 mm      9.396        4.698          79.8    housing hard stop

    The cell sits at 68% of available contact travel against 55% for the longest
    cell MPD lists. Inside the mechanism's real limits with margin, outside the
    published range. The prediction and the bench agree.
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

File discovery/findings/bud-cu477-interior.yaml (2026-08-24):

id: BUD-CU-477-interior
kind: enclosure
source_claim: >-
  Working rectangle 95.2 x 165.1 mm (3.75" x 6.5"), a deliberately conservative
  figure allowing for the sloped sides; STEP model read ~110 x 170 mm and was
  marked indicative. Both were DERIVED -- one from catalogue nominal minus 0.5"
  per axis, one from a sparse point cloud. Neither was measured.
source_ref: >-
  docs/sourcing.md "The BUD CU-477, measured from its STEP model";
  docs/decisions/0008-board-outline-and-layer-count.md enclosure table
resource: BUD Industries CU-477 aluminium instrument case, bottom plate
status: confirmed

measured:
  bottom_plate_interior_mm: [178.0, 110.0]
  screw_columns_mm: 5.0
  interior_height_mm: 34.0        # 33.0 case cavity + 1.0 lid inset
  case_cavity_depth_mm: 33.0
  lid_inset_mm: 1.0
  bottom_plate_thickness_mm: 2.16
  top_plate_thickness_mm: null    # assumed similar, NOT measurable in hand
  tolerance_mm: 0.1               # applies to the bottom-plate figures below
  measured_by: Matt
  instrument: not recorded

# The bottom plate is not a flat panel. It carries a perimeter lip that locates
# inside the enclosure body, with a shoulder part way up that the body sits on.
bottom_plate_profile:
  # All heights from the OUTER bottom face.
  plate_thickness_mm: 2.16        # outer face to interior floor
  shoulder_height_mm: 4.0         # the enclosure body seats here
  lip_top_height_mm: 6.0          # lip stands 6 mm from the bottom
  lip_above_shoulder_mm: 2.0      # 6 - 4, this is what holds the top in place
  # Restated from the interior floor, which is what the board sees.
  lip_above_interior_floor_mm: 3.84   # 6.00 - 2.16

# Panel hardware that intrudes into the interior.
intrusions:
  power_switch:
    part: 12 mm LED latching switch
    mounted_in: top panel, upper right
    descends_mm: 23.0
    plus_clearance_for: wires and shrink-wrap sleeves, amount not quantified
    clear_height_beneath_mm: 11.0   # 34.0 - 23.0, BEFORE the wire allowance
    over_board: false               # CONFIRMED 2026-08-18 -- sits in the
                                    # reserved 28 mm strip, no board beneath
    strip_available_mm: 28.0        # board right edge to the right wall

# What this is measured against. The board does not change with this record.
board_outline_mm: [150.0, 90.0]
mounting_holes_mm:
  pattern_about_centre: {x: [-70.0, 70.0], y: [-40.0, 40.0]}
  inset_from_every_board_edge: 5.0

# HOW THE BOARD SITS. It is NOT centred on the long axis.
mounting:
  long_axis: offset
  gap_to_column_wall_mm: 5.0    # board edge flush to the screw-column face
  gap_to_button_wall_mm: 23.0   # 178 - 150 - 5, reserved for the power button
  short_axis: centred
  gap_short_axis_per_side_mm: 10.0
  datum_end: left, defined as the supporting hand when the device is held
  rationale: >-
    TWO reasons, and they point the same way.

    (1) CLEARANCE. The latching power button is long and its body projects
    inward from the right end panel, so the whole 28 mm of long-axis slack is
    pushed to that end rather than split. That puts the board hard against the
    5 mm screw columns on the left. 5 mm is therefore the COLUMN FACE, not an
    arbitrary gap -- the board datums off the columns.

    (2) BALANCE. The device is held in the LEFT hand, and the board is the
    heaviest thing in the box. Sitting it over the supporting hand keeps the
    centre of gravity there instead of cantilevering it out to the right, where
    the same mass on a longer moment arm reads as a heavier instrument. This is
    a felt-weight decision, not a structural one: nothing is at risk of tipping,
    it simply fatigues the hand less.
  convention_scope: >-
    absonus and every other board in a BUD Industries case, not caryatid alone.

derived:
  # Mounting holes to the interior wall, with the board offset as above.
  hole_to_column_wall_mm: 10.0          # 5 gap + 5 inset
  hole_to_button_wall_mm: 28.0          # 23 gap + 5 inset
  hole_to_long_wall_mm: 15.0            # 10 gap + 5 inset, both sides
  # The pattern SPACING is unchanged at 140 x 80. Its POSITION is not centred:
  # the pattern centre sits 9 mm toward the column end of the floor centre.
  pattern_offset_from_floor_centre_mm: 9.0
  # Clearance to the 5 mm columns.
  column_clearance_long_axis_mm: 0.0    # flush by design -- this IS the datum
  column_clearance_short_axis_mm: 5.0
  # Height. Stack is 26.91 mm (ADR 0008).
  headroom_mm: 7.09                     # 34.00 - 26.91
  headroom_previously_stated_mm: 7.23   # against the derived 34.14
  # Under the switch specifically, which is the binding case, not the average.
  headroom_beneath_switch_mm: -15.91    # 11.00 - 26.91 -- NEGATIVE, see notes
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

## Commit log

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2026-08-09 Start the KiCad project
    KiCad 9 skeleton: project file, root schematic and the four hierarchical
    sheets the capture checklist calls for, plus project-local symbol and
    footprint libraries and the library tables that make them resolve without
    touching global config.
    Validated rather than assumed. kicad-cli runs ERC clean and walks all four
    child sheets, and a netlist export resolves the full hierarchy -- which is
    the real test that the sheet instances and UUIDs are wired up correctly,
    since a hand-written hierarchy can look fine and still not traverse.
    No .kicad_pcb. KiCad writes one the first time the board editor opens, and a
    hand-authored empty board carries nothing a fresh one does not w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
    [audio.kicad_sch, caryatid.kicad_sch, panel-io.kicad_sch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]
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2026-08-10 Capture the power sheet
    All 27 components and 19 nets from power-sheet.md. ERC clean at 0 violations,
    and the exported netlist diffed node-by-node against that document -- every net
    matches, with ITERM the one deliberate no-connect.
    Two things the capture turned up that were latent in the design:
    U1 pins 10 and 11 are both OUT and both were typed power_out, so tying them --
    which the datasheet requires -- was an ERC error. Retyped pin 11 as passive, the
    usual idiom for duplicate power pins. The netlist is unchanged.
    Local labels are sheet-qualified: the boost switching node exports as
    '/power/SW', not 'SW', so the HighCurrent netclass pattern 'SW' would never have
    matched it and 1.51 A pe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
    [power.kicad_sch]
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2026-08-10 Capture the seed sheet
    Both socket rows and the two measurement networks -- the A10 battery gauge and
    the A11 charge-status code. 12 components.
    ERC has no errors. The 33 warnings are all global_label_dangling, exactly one
    per Seed pin bound for panel-io or audio, which are not captured yet: 15 D0-D14,
    10 A0-A9, 4 RGB/expansion, 4 audio. The count is a checksum rather than noise --
    it should reach zero when those sheets land, and any other dangling label is a
    real mistake.
    The pin-map cross-check the checklist asks for as a distinct pass was run by
    script against pins.yaml: all 31 physical pins land on a net named after the
    pin. A first attempt only covered 12 of them -- the regex matched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
    [seed.kicad_sch]
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2026-08-10 Capture the panel-io sheet
    46 components over 59 placements: both ribbon buses with their series/filter
    networks, the three 74HC14 debounce channels, RGB, both comms ports, the
    expansion header and the two sensor inputs.
    ERC has no errors and the dangling-global count falls 33 -> 4. The four left are
    AUDIO_IN_L/R and AUDIO_OUT_L/R, waiting on the audio sheet. That number was
    predicted before the sheet was drawn, so it landing exactly is the check rather
    than a coincidence.
    Pin-map enforcement was run by script against pins.yaml. The first attempt
    reported 20 of 29 pins failing, which was the check being naive rather than the
    schematic being wrong -- every bus pin reaches its connector THRO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
    [panel-io.kicad_sch]
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2026-08-10 Place all 125 footprints, net-bound, unrouted
    Does the job kicad-cli has no command for: reads the exported netlist, embeds
    each footprint with its pads bound to the right nets, and drops it into a zone
    from 'Layout, when it comes'. Switcher hard left, analogue and audio hard right,
    Seed centre, BT1 along the 100 mm edge.
    This is a machine first pass, not layout. Nothing overhangs the outline, but ~33
    courtyards overlap and the silkscreen collides in places. It is something to
    drag from.
    Three bugs worth recording, all of which produced plausible-looking output:
    The strip of (version)/(generator)/(layer) lines from the .kicad_mod headers was
    not line-anchored, so it also deleted (layer "F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
    [caryatid.kicad_pcb]
2026-08-10 Flip the SMD to the back
    Front keeps BT1, both Seed sockets and every through-hole connector -- 21 parts.
    The other 104 go to B.Cu. Classified by each footprint's own attr rather than by
    library name, so the SMD Qwiic socket J13A goes back with the rest.
    This is the checklist's 'SMD on one face, holder and through-hole connectors on
    the other', and courtyards_overlap fell from 33 to zero as a direct result: the
    two populations can no longer collide.
    The mirror is stored the way KiCad stores it, established by reading a
    KiCad-written board rather than guessing -- back-side footprints hold Y-negated
    coordinates, F/B layer names swapped, and (justify mirror) on every text.
    Verified after the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
    [caryatid.kicad_pcb]
2026-08-10 Arrange the connector ring on the front
    Placed by function: power and the digital bus left, analogue and audio right
    where they are furthest from L1, switches and module ports along the bottom.
    The two IDC buses sit inboard beside the Seed row each serves. J18 and J14 are
    adjacent because they are one loom -- capsule signal and its bias return.
    Edges are stacked from measured courtyard extents. Hand arithmetic on offsets
    produced touching parts three times running, so the placer now computes the
    tiling.
    Two things this exposed.
    The rotated-courtyard transform was wrong: a 90-degree ring passed the collision
    check while J16 and J13B visibly overlapped in the render. Rather than keep
    guessi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
    [caryatid.kicad_pcb]
2026-08-10 Drop the Seed per-pin labels; keep the orientation cue
    Forty labels beside the socket pins are removed. A label that only restates the
    pin name still leaves you tracing the net, so it earns very little for that much
    silkscreen -- the marking worth the space is the one that stops the module going
    in backwards.
    They also failed the fab. At 2.54 mm pitch they only fitted at 0.7 mm, under
    JLCPCB's 0.8 mm floor, so they would have printed blurred or been dropped.
    Enlarging them to a legible size ran the longer names into J11's pads.
    What stays: module outline split on the centreline, pin-1 dot, square pads at
    the USB end of BOTH rows, and the USB legend -- now 1.0 mm on 0.15 mm strokes,
    JLC's r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
    [caryatid.kicad_pcb]
2026-08-10 QFN thermal vias to 0.3 mm drill; no silkscreen on mounting holes
    Vias were Ø0.2 mm per TI's drawing, below JLCPCB's 0.3 mm minimum hole. Enlarged
    to 0.3 mm drill on 0.55 mm pads, and moved inboard from ±0.6 to ±0.5 -- at ±0.6
    the larger pad would have left only 0.176 mm to the signal pads, where ±0.5
    gives 0.289 mm. drill_out_of_range 4 -> 0.
    Exposed pad 1.70 -> 1.68 mm, TI's nominal. 1.70 came from the stock footprint
    chosen for its ThermalVias sibling and sits exactly on the 0.2 mm clearance
    boundary, so it failed on rounding.
    Mounting holes carry no printed silkscreen: Reference and Value hidden. The two
    circles were already on Cmts.User and F.CrtYd and the fp_text on F.Fab, so no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
    [caryatid.kicad_pcb]
2026-08-10 Hide back references, scope a clearance override to U1 and U2
    Back-side designators hidden: 104 SMD parts at this density made them illegible
    and they collided 87 times. JLC places from the CPL, not from silkscreen. Front
    designators stay -- that face is sparse and is what a human cables up.
    U1 and U2 get a footprint-level 0.15 mm clearance override. A 0.5 mm pitch
    package fixes its own pad gaps and the HighCurrent netclass asks 0.3 mm, which
    no land pattern at that pitch can meet. Scoped to the two packages; traces still
    answer to their netclass.
    Zone overflow now goes to the rescue pass rather than running off the board, and
    the rescue pass keeps 3 mm of edge margin. R6, R9 and R10 were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
    [caryatid.kicad_pcb]
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2026-08-11 Ground pour on F.Cu, and the boost hot loop
    A GND zone on F.Cu, which that face can carry as a near-solid plane because it
    holds only 21 through-hole parts. The zone ships unfilled -- kicad-cli has no
    fill option -- so DRC reports the two GND vias as dangling until zones are
    filled in the editor.
    The hot loop: +5V_RAW from U2 pin 6 to C6 at 0.8 mm, and the return taken into
    the plane by a via at each ground pad rather than by a track, so the return runs
    directly under the outgoing current.
    Two mistakes worth recording. A track wider than the pad pitch shorts to the
    neighbouring pad -- 0.8 mm centred on pin 6 overlapped pin 5 -- so exits from
    0.5 mm-pitch pads now neck to 0.25 mm and widen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
    [caryatid.kicad_pcb]
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2026-08-11 Board to 150 x 90, and a checker for the constraints DRC misses
    The recurring failure this session was always the same shape: a check that
    modelled one thing and silently ignored another. tools/check_board.py now
    enumerates all eight classes in one re-runnable pass -- courtyard overlap per
    face INCLUDING the mounting holes, back parts over front through-hole pads,
    outline margin, component height vs standoff, via annular ring, track width vs
    pad pitch, and silkscreen against the fab floors. Four of those have no
    equivalent in KiCad's DRC as configured, which is why they were all missed.
    Outline 90 x 100 -> 150 x 90. Coverage 50% -> 33%, perimeter 380 -> 480 mm,
    which matters because an earl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
    [caryatid.kicad_pcb]
2026-08-11 Specctra DSN exporter, so the board can reach Freerouting
    kicad-cli has no router and no dsn subcommand, so tools/export_dsn.py writes the
    export headlessly. KiCad's GUI export is more authoritative; this is for when the
    GUI is not in the loop.
    Two departures from a plain export, both deliberate. GND is left out of the
    routed nets: F.Cu is a ground plane that Freerouting cannot see, so it would
    otherwise lay 72 ground traces across a board that wants stitching vias.
    --with-gnd overrides. And existing copper is emitted (type protect), so the boost
    hot loop and the SW node -- placed and measured by hand -- survive the router.
    Also fixed two netclass via defaults that were below the fab floor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
    [check_board.py, export_dsn.py]
2026-08-12 Everything to the front; ground plane to B.Cu; standoff 2 mm
    The enclosure is shallow, so the standoff has to be short, and C7 at 5.4 mm
    cannot hang under it. Rather than move the tall parts individually, every
    component moves to the front. That fixes three things at once: the standoff drops
    7 mm -> 2 mm (stack ~30 -> ~25), SMT returns to single-sided and therefore
    Economic, and B.Cu is freed as a routing layer instead of carrying 104 parts and
    141 signals. The ground pour moves to B.Cu, which is now genuinely empty.
    This reverses the SMD-to-back flip. That was right at 90 x 100, where reclaiming
    the copper under the cell mattered; at 150 x 90 it does not, and a short standoff
    outranks it.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
    [caryatid.kicad_pcb]
2026-08-12 Remove J2, the remote-pack connector
    Nothing on the platform asked for it, and it was the last route by which a
    reversed cell could reach the charger. BAT is rated -0.3 V to 5 V against a
    reversed cell's -4.2 V, and there is deliberately no reverse protection because
    a soldered holder cannot be wired backwards. J2 was the one exception -- a
    hand-crimped loom on a keyed connector that can still be crimped wrong. With it
    gone the exposure is not mitigated, it is absent: no connector on the board
    reaches VBAT.
    Removed surgically from power.kicad_sch by the generator's deterministic UUIDs --
    symbol, both wire stubs, both power symbols -- rather than by re-running the
    one-shot, which would have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
    [caryatid.kicad_pcb, power.kicad_sch, seed.kicad_sch]
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2026-08-12 Check front height against the enclosure ceiling; BUD interior is 34.14 mm
    Height clears in both enclosures, and the BUD is the binding case -- not the
    phone, which is over 40 mm:
    telephone shell > 40 mm interior > 13 mm headroom
    BUD CU-477 34.14 mm 7.23 mm
    The BUD figure is DERIVED from CU-477.STEP, not measured. The file is in
    inches (CONVERSION_BASED_UNIT 'INCH'), 38.10 mm external, and the base and
    cover solids independently give a 1.98 mm wall, which reconciles exactly:
    38.10 - 2 x 1.98 = 34.14. Two solids agreeing is good corroboration, but it
    is still inference from a model -- confirm with calipers. A plane sits
    1.60 mm proud of the base floor; standoffs s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
    [check_board.py]
2026-08-12 Emit all four net classes to the DSN, and inset the boundary
    The exporter wrote a single kicad_default class, so Freerouting was being
    told to route all 95 nets at 0.25 mm and 0.20 mm clearance. 23 of them
    should not be:
    HighCurrent 4 nets 1.20 mm VBAT, VOUT, VIN_DC, /power/SW
    Power 3 nets 0.80 mm +3V3, +3V3A, +5V
    Analog 16 nets 0.30 mm A0-A11, AUDIO_*
    0.25 mm on 1 oz carries about 0.86 A at a 10 C rise; the boost peak is
    1.51 A and charge is 1 A. This is not a fab-rule violation -- 0.25 mm is
    legal copper and DRC would have passed it -- it is an electrical one, which
    is exactly the class of fault the netclasses exist to prevent.
    Also emits a via padstack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
    [export_dsn.py]
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2026-08-12 Fan out U1's six power pads so the router can reach them
    Freerouting routes a net at one width -- its class width -- and has no
    neck-down. A HighCurrent net at 1.20 mm therefore cannot leave U1's 0.25 mm
    QFN pads on 0.5 mm pitch, and the router simply failed those connections:
    eleven of the thirteen unrouted in the last run were at U1 or U2.
    tools/fanout.py escapes each such pad at a width that fits between its
    neighbours, runs out until the package stops constraining anything, widens to
    the class width, and leaves the result for export_dsn.py to mark protected.
    Six escapes, all at U1:
    U1-2, U1-3 VBAT 0.30 mm neck, 1.10 mm, then 1.20
    U1-5,10,11 VOUT 0.30 mm neck, 1.10-1.1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
    [caryatid.kicad_pcb]
2026-08-12 Correct the .ses resolution header; the import was landing 10x off the board
    Freerouting's session writer emits coordinates at 10x the resolution its own
    header declares. Its DSN writer does not: a board round-tripped through it
    comes back with all 124 placements byte-identical at (resolution um 10), and
    the .rules it writes uses the same scale. Only the .ses is out.
    KiCad believes the header, which is the reasonable thing to do, so the import
    succeeds and puts the whole route 10x away from the PCB. Measured with
    KiCad's own ImportSpecctraSES via the pcbnew bindings, on a copy:
    import ret True, 23 -> 1297 tracks
    track extent x 533.9..1970.4 y 319.5..1166.3 mm
    board outline x 50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
    [fix_ses.py]
2026-08-12 Tie U1's paired power pads and escape each group once
    Replaces the per-pad fanout in 0722688, which made routing WORSE: 15 unrouted
    and 141 violations against 13 and 127 before it, and 2826 seconds against 163.
    The reason was not the idea but the greed. Each escape took the widest neck
    that fit when considered ALONE, and 0.30 mm per pad ate the gap the signal
    pins beside them needed. Measured after the fact, U1-1, U1-9, U1-12 and U1-14
    were left 0.025 mm of working room, against 0.100 mm for pads no escape sat
    beside. Legal by DRC, unusable by a router -- and /power/TS, /power/ILIM and
    /power/TMR duly stopped routing, having been fine before.
    Three changes:
    * VBAT is on U1-2 AND U1-3, V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
    [caryatid.kicad_pcb]
2026-08-12 Pour ground on F.Cu and stitch the pockets; GND goes 53 unconnected to 3
    The board had 152 vias and not one on GND. export_dsn.py excludes GND with the
    note that "B.Cu is a ground plane, so GND wants stitching vias" -- the first
    half right, the second half never built. Every component is on the front, the
    plane is on the back, and nothing joined them.
    A private via per pad was the obvious fix and the wrong one: 26 of 53 on a
    board this densely routed, because half the pads have no room beside them.
    The standard answer for a 2-layer board with everything on one side is a
    ground pour on BOTH sides, which is one object instead of 53:
    front-side GND pads unconnected 53 -> 10 (F.Cu pour)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
    [caryatid.kicad_pcb]
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2026-08-12 Add tools/cycle.py: placement to routed board in one command
    The route is not a result to preserve, it is a rendering of the placement at
    real copper widths so the next placement decision can be made by looking at
    it. Move parts, save, run this, reopen. Nothing routed survives a cycle and
    nothing routed needs to.
    1 strip every segment and via -- footprints, zones, outline stay
    2 fanout.py --apply escapes recomputed for wherever the parts now are
    3 export_dsn.py
    4 freerouting single-threaded; the multi-threaded optimiser is
    documented broken and generates clearance errors
    5 fix_ses.py the session is written at 10x its declared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
    [check_board.py, cycle.py, export_dsn.py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]
2026-08-12 Route B.Cu only under the Seed sockets; add reset_placement.py
    The two 1x20 sockets were 29 of 83 unrouted on a single layer. Measured from
    the footprint: 2.54 mm pitch, 1.7 mm pads, 0.840 mm edge to edge, so after
    0.2 mm clearance each side exactly ONE 0.25 mm track fits between neighbours.
    Forty pins each needing that one channel is the whole bottleneck.
    export_dsn.py --bcu-under A1,A2 declares B.Cu a signal layer and then fences it
    with keepouts everywhere except a window round each named part. Verified before
    trusting: all 40 pads inside a window, and 20000 random points each land in
    exactly one of window-or-keepout, so the fence has no gaps and no keepout sits
    on a window. B.Cu opens o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
    [caryatid.kicad_pcb]
2026-08-13 Pour the boost cluster from hand-drawn outlines; 19 real unconnected, no shorts
    Placement plus hand-drawn pours takes the board from 83 unrouted to 19, with
    no shorts, no clearance violations and no mask bridges.
    route on F.Cu only, B.Cu a plane 83
    + B.Cu windows under the Seed sockets 58
    + placement 27
    + hand-drawn pours round U2 19
    POURS COME FROM A DRAWING, NOT A GENERATOR
    tools/power_pour.py tried to derive the shapes from pad positions. Every form
    of it failed the same way: round a SOT-563 the pads of six nets interleave at
    0.5 mm pitch, and any convex shape fitted to scattered points covers its
    neighbours. Bounding boxe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
    [caryatid.kicad_pcb]
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2026-08-15 Route U2's power pins per the TPS61023 layout guidance
    Nine hand-drawn polygons converted to pours, and SW and +5V_RAW given the
    short necked runs the package actually permits. No DRC item touches a U2 pad.
    U2-5 SW 0% fill -> 0.35 mm track into the SW pour
    U2-6 +5V_RAW 36% / 0.128 -> 49% + a 0.35 mm track to C6-1
    U2-3 VOUT 60% -> 59% + fill, boxed in, left alone
    SLVSF14B section 10 asks for two things that read as opposites and are not:
    "minimize the length and area of all traces connected to the SW pin", and "make
    copper polygon connected with each pin bigger" / "larger and thicker PCB copper
    for the power pads (GND, SW, and VOUT)". Short and fat, not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
    [caryatid.kicad_pcb]
2026-08-15 Re-route against the current placement; 11 real unconnected, no shorts
    Best the board has been. Real connections outstanding: 83 at the start of this
    work, then 27, then 19, now 11. Pours and hand-routed copper both survived.
    shorting_items 2 -> 0
    clearance 3 -> 0
    solder_mask_bridge 6 -> 0
    holes_co_located 1 -> 0
    LOCKED COPPER NOW SURVIVES A CYCLE. strip_copper() skips anything carrying
    (locked yes), and export_dsn already hands it to Freerouting as (type protect),
    so the router builds around it. This matters because the router regenerates
    what it laid but cannot regenerate hand work: fanout only escapes radially, and
    the SW route out of U2-5 goes LEFT into the c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
    [caryatid.kicad_pcb]
2026-08-16 Clear BT1's hole clearance by narrowing VBAT, not by moving it
    The VBAT run out of BT1-1 passed under BT1's own 3.2 mm mounting hole with
    0.202 mm to spare against a 0.25 mm rule:
    2.402 centre-to-centre - 1.6 hole radius - 0.6 track half-width = 0.202
    Moving the run down is the obvious fix and it does not work. Pushing it away
    from the hole pushes it into /audio/OUT_L_J, a 45 degree diagonal arriving from
    the other side, and the two constraints close on each other: the hole wants
    y >= 46.450 and the audio track wants y <= 46.457. A 7 micron window is not a
    fix, it is a coincidence.
    Narrowing the four segments of that run to 1.00 mm clears both properly:
    BT1 hole 0.202 -> 0.302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
    [caryatid.kicad_pcb]
2026-08-16 Board is fully routed; add tools/cleanup.py
    Zero real unconnected connections. Every net on the board is complete. The
    count went 83 at the start of this routing work, then 27, 19, 11, and now 0 --
    the last of them routed by hand.
    zones_intersect 2 -> 1
    duplicate tracks 2 -> 0
    The duplicates were locking colliding with the protected-copper round trip:
    strip_copper keeps the locked original, export_dsn hands it to Freerouting as
    (type protect), Freerouting echoes it into the session, and the import lays it
    down again. Same net, superimposed, so harmless -- but it doubles every cycle.
    DANGLING-VIA REMOVAL IS OFF BY DEFAULT, and the reason is written into th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
    [caryatid.kicad_pcb]
2026-08-16 track_width down to zero; delete the FB pour
    Every track on the board now meets the 0.20 mm rule, with no rule relaxed. 14
    violations to 0, and most of them were not thin copper needing widening -- they
    were leftovers.
    Freerouting drops a short escape stub at each pad before routing the real path.
    When the real path then lands on the pad directly, the stub is orphaned. On
    /power/FB one ran 0.225 mm from U2-1 to a point 0.045 mm outside the pad it
    started from, connected to nothing. On /power/ISET a 0.337 mm segment lay
    entirely inside a wider 0.25 mm run on the same layer, same y -- invisible,
    because a narrower track under a wider one renders as one line. Deleting was
    the fix more often th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
    [caryatid.kicad_pcb]
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2026-08-17 Separate the Seed socket outlines; silk_overlap 6 -> 2
    A1 and A2 each draw their half of the Daisy Seed body, and the two outlines
    CROSSED by 0.24 mm where they met at the centreline -- at x 144.6 and x 92.4,
    A1 spanning down to y 82.38 while A2 came up to 82.62. Four of the six overlaps
    came from that, plus the USB label sitting in the same crossing.
    Trimming A2's two transverse segments and moving the label 1 mm clear fixes
    both. Changes are in the LIBRARY footprints as well as the board instances, so
    they stay in step and do not come back on the next placement.
    The USB label mattered beyond tidiness: it is the marking that stops the Seed
    being plugged in backwards, and it was printing o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
    [caryatid.kicad_pcb]
2026-08-17 Show references for U1, U3, U4, C7 and D1
    108 of 128 reference designators were hidden. That was the residue of a
    decision that no longer applies: "hide the back references" was right when
    every SMD part was on the back face, and then everything moved to the front and
    the hiding stayed. The visible twenty were exactly the parts that never moved --
    A1, A2, BT1 and the connectors.
    Hiding passive designators on a board this dense is normal; assembly works from
    the pick-and-place file, not the silkscreen. Hiding the ICs is not. On a bare
    board you could not identify the charger, the Schmitt or the op-amp, and D1 and
    C7 are both POLARISED, which is where a fitting error is expensive.
    Tested all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
    [caryatid.kicad_pcb]
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
